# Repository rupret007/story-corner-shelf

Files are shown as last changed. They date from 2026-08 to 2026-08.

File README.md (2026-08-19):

# Story Corner

**Triadic Palatine Order — a parametric PETG-finished hybrid closet shelf**

Story Corner is a same-height L shelf for nominal 3 ft and 5 ft closet walls. The r5 **Triadic Palatine Order** gives the visible black PETG skin a palace-like 3–6–9 composition: three arcade bays on the short arm, six on the long arm, nine keystones, fluted shared piers, stepped entablatures, dentils, a fitted corner pilaster, and a groin-vault corner soffit. Continuous plywood and steel—not the printed architecture—carry stored weight.

> **Prototype status:** the meshes and model-only 3MF packages are generated design-development artifacts. The wall lengths, separate installed offset on each wall, corner angle, wall bow, framing map, hardware envelope, 8 in depth, attachment stack, printer, nozzle, build plate, PETG product, and completed assembly remain unverified. No tested load rating is claimed. No embedded G-code is included.

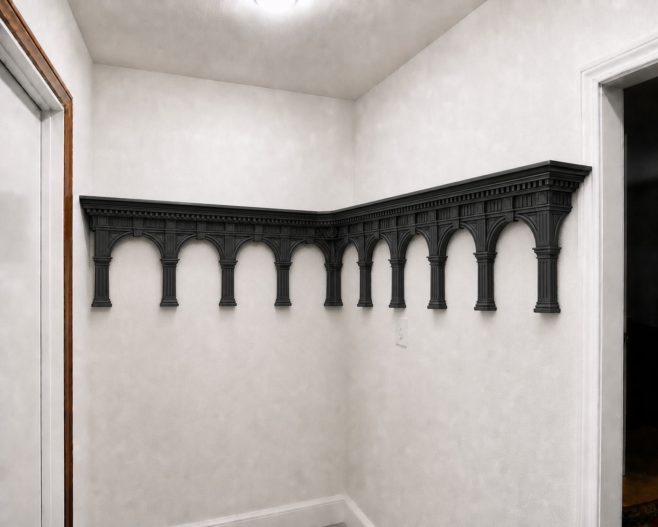
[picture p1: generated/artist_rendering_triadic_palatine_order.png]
Artist rendering of the Story Corner Triadic Palatine Order


The rendering shows visual intent only. It is not a measurement drawing, hardware layout, proof of fit, or load test. Construction is governed by the field measurements, [corner plan](generated/corner_layout.svg), [support plan](generated/support_layout.svg), and [safety boundary](SAFETY.md).

## Design snapshot

Viewed from the closet opening, the nominal plan places the 5 ft through arm on the right wall and the 3 ft return on the back wall; this handedness still requires field confirmation. The through deck owns the 8 x 8 in corner square. The return starts beyond the through deck's front plane, so the boards do not overlap and both arms retain independent bracket support.

| Arm | Nominal plywood stations from inside corner | Nominal deck | Desired support centers from inside corner | Palatine arcade |
|---|---:|---:|---|---:|
| 5 ft through | 0.688–59.875 in | 59.188 x 8 in | 6.281, 22.281, 38.281, 54.281 in | 6 bays / 12 halves |
| 3 ft return | 8.750–35.875 in | 27.125 x 8 in | 10.750, 22.313, 33.875 in | 3 bays / 6 halves |

The shortened return still completes the full short-wall surface because the through deck supplies the corner. Nominal geometry uses 0.6875 in as the provisional installed shelf-back offset on **each** wall, an 8 in deck, a 1.6 mm concealed plywood fit gap, and 1/8 in clearance at each exposed outer end. These are not field cut dimensions.

Dimensioned fitted corner plan

The desired support layout limits longitudinal spacing to 16 in and end overhang to the configured 6 in maximum; the nominal plan works out to 5.594 in on the through arm and 2 in on the return. It is not a drilling map. Every standard must land on verified wood framing or purpose-installed structural blocking. Dry-fit the two nearest perpendicular brackets, locks, fasteners, and both steel angles together before drilling.

## Permanent load path

Every generated printable component is PETG-only and intentionally nonstructural:

`contents -> each continuous plywood deck / its continuous steel front angle -> independent steel brackets -> steel standards -> structural fasteners -> verified framing or blocking`

The printed arches, piers, keystones, entablatures, top tiles, curbs, corner pieces, and fascia can conceal the chassis, but they do not become that chassis. Roman arch geometry does not solve the tension and long-term creep demands of a wall-mounted cantilever. An all-PETG structural shelf or printed wall bracket is outside this project and cannot inherit its selection targets, support plan, or safety language.

Shelf section and permanent load path

## Two-wall corner model

The coordinate datum is the intersection of the two finished wall planes. Measure the installed wall-to-plywood-back offset independently on both walls:

- `b5`: offset on the long/through wall;
- `b3`: offset on the short/return wall;
- `D`: shelf depth;
- `j`: plywood fit gap.

The through deck starts at `b3` along the long-wall axis. The return deck starts at `b5 + D + j` along the short-wall axis. The through-owned corner zone spans `b3` to `b3 + D` on the long-wall axis and `b5` to `b5 + D` on the short-wall axis. Equal catalog standard projections do not prove that the installed offsets are equal after wall bow, drywall mud, shims, and fastener seating.

The current nominal values happen to give the same stations shown in the table because both unverified offsets fall back to 0.6875 in.

## Near-square angle and residual-gap rule

The square deck footprints use a deliberately narrow field-angle gate:

- nominal plywood gap: 1.6 mm;
- required residual nominal clearance: at least 0.6 mm;
- configured maximum verified deviation from 90°: ±0.25°;
- gap-only physical overlap limit across 203.2 mm depth: approximately ±0.451°;
- residual-clearance-derived limit: approximately ±0.282°.

Angular edge shift is `203.2 mm × tan(|angle − 90°|)`. At ±0.25°, the nominal shift is about 0.887 mm and the remaining nominal joint clearance is about 0.713 mm. Generation must stop if the configured gate exceeds the residual-derived limit, a verified angle exceeds ±0.25°, or the remaining clearance is below 0.6 mm. A full-size template is still mandatory because this trigonometric check does not include wall bow, caulk, or drywall buildup.

## Triadic Palatine Order

The ornament follows a controlled 3–6–9 grammar rather than adding unrelated decoration:

- 3 segmental-arch bays on the short arm and 6 on the long arm;
- 18 handed arcade/fascia halves separated by 0.6 mm seams and finished by 9 floating keystones;
- 113.994 mm short-arm halves and 107.630 mm long-arm halves;
- 92 mm arch drop, 48 mm rise, 6 mm overlap into the functional fascia, and 168.056 mm total saved height;
- a 5 mm outer archivolt order, 2.4 mm true shadow reveal, and 4 mm inner order;
- a 22 mm shared pier with three 1 mm flutes per half — six across the assembled pier — plus 9 mm-high / 4 mm-projecting bases and 8 mm-high / 5 mm-projecting capitals;
- one 3:4:5 spandrel void per half;
- removable 24 mm-high entablature overlays, each with 9 dentils, 3 triglyph groups, 3 cornice orders, and an 11 mm central patera;
- an 18 x 24 x 2.4 mm keystone at every bay center, retained to one half while floating over the other;
- an 18 mm-leg full-height re-entrant corner pilaster fixed on one upper leg and floating on the perpendicular leg;
- a 42 mm groin-vault soffit with diagonal ribs and a 9-petal boss, mounted only beneath the through-owned corner square.

The groin-vault footprint currently has 18.519 mm nominal clearance to the nearest through support plane, above the 10 mm development minimum. Field support locations must regenerate and re-pass that check. None of these forms receives structural credit, even when it visually resembles an arch, pier, bracket, or vault.

Dimensioned Triadic Palatine elevation

The elevation drawing records exact nominal stations, counts, and module dimensions; its displayed arch curves are schematic. It is not a structural elevation or a substitute for checking the 180 mm printer envelope.

## Finish fit and attachment

- All top tiles use a 0.25 mm plan radius and 0.6 mm seams. Four 101.3 mm quadrants finish the through-owned corner square. The return's inner tile floats 1.0 mm over the concealed 1.6 mm plywood gap without receiving load-path credit.
- The fascia channel opening is nominally 46.256 mm: 18.256 mm plywood + 25.4 mm steel-angle vertical leg + 2.0 mm top tile + 0.6 mm fitting clearance. The upper flange overlays the tile.
- Every finish piece attaches only with qualified removable products — silicone dots, captured channels, or short nonstructural screws through generated slots. The complete attachment sequence, dot counts, and installed z-stack live in [ASSEMBLY.md](ASSEMBLY.md); the attachment policy is in [ENGINEERING_DESIGN.md](ENGINEERING_DESIGN.md) section 8. Never drill or notch the continuous steel angle for cosmetic retention.

Attachment prevents loose trim, rattle, and falling only. It does not carry stored weight or turn the printed anti-fall features into rated cargo restraints.

## Split rear-curb system

The rear curb sits on the PETG tile/plywood stack — never on bare plywood and never across the structural joint. The long-wall straight curb starts at station 1.892 in after the 30 mm fitted replacement; a separate 172.6 mm corner-side curb stays on the through-owned corner square; the return curb starts on its own plywood at 8.750 in, beyond the 1.6 mm wood gap. Rear-curb ends are arm-specific: 126.481 mm through, 115.581 mm return. The installed z-stack and the slot/drill/screw procedure are in [ENGINEERING_DESIGN.md](ENGINEERING_DESIGN.md) section 6 and [ASSEMBLY.md](ASSEMBLY.md) Stage 4.

## Safe customization

- Universal top and rear-curb centers use a 152.4 mm pitch and are 151.8 mm wide with 0.6 mm seams.
- Measured arm lengths regenerate symmetric top/curb ends and the complete 3/6-bay Palatine fascia layout.
- The nominal top ends are shared at 116.081 mm. Rear-curb ends and all Palatine half widths are arm-specific.
- A same-height L level must be unloaded and moved as one coupled assembly. Moving one arm alone breaks the fitted corner.
- Moving a standard horizontally requires a new framing, wiring, bracket-interference, spacing, overhang, and groin-vault-clearance review.

The structural plywood and steel angle do not use printed snap joints. Modularity is limited to replaceable finish pieces and controlled vertical movement on the steel standards.

## Start here

1. Read [PRINT_ME_FIRST.md](PRINT_ME_FIRST.md) before opening a production file.
2. Read [SAFETY.md](SAFETY.md) before cutting, drilling, attaching trim, or loading.
3. Review [ENGINEERING_DESIGN.md](ENGINEERING_DESIGN.md) for formulas, failure modes, and verification limits.
4. Fill in [MEASUREMENT_WORKSHEET.md](MEASUREMENT_WORKSHEET.md), transcribe its section H into [config.json](config.json), then rebuild every generated artifact and verify the `*_source` fields per worksheet section I.
5. Follow [ASSEMBLY.md](ASSEMBLY.md) for the build sequence, from structural install through load acceptance and service.
6. Open [the full model-only print set](generated/model_only_3mf/MODEL_ONLY_STORY_CORNER_TRIADIC_PALATINE_FULL_PRINT_SET.3mf) only after confirming the printer, nozzle, plate, PETG product, and attachment coupons.

The full 3MF contains **101 exact-quantity catalog objects**: 98 installed finish pieces plus three print-first test objects. It is not arranged into real printer plates and contains no machine instructions. The nominal geometry estimate is **2.45 kg packaged PETG** and **2.42 kg installed PETG**, excluding purge, supports, failures, spares, fasteners, plywood, and steel.

## Field information still required

Before this can become an installation-ready revision, record:

1. The limiting clear length of both walls at the rear, middle, and front shelf planes for every candidate common elevation.
2. The included inside-corner angle, wall bow, drywall/caulk buildup, and a full-size cardboard or hardboard corner template.
3. The installed wall-to-plywood-back offset **separately for each wall**, plus bracket wall-to-tip envelope, bracket width, locks, and final wall-to-fascia projection using the exact hardware.
4. Both edges and center of every stud on both walls—especially the first 14 in from the corner—plus framing material, drywall thickness, wiring, pipes, and protective plates.
5. Confirmation that the 8 in depth and 168.056 mm Palatine fascia envelope clear the doorway, trim, people, bins, outlets, and every intended elevation.
6. Storage-bin outside width, depth, height, lid overhang, quantity, loaded weight, and the heaviest individual object.
7. Exact printer, nozzle diameter and material, build plate, Bambu Studio version, black PETG brand/product, and filament condition.
8. Intended evenly distributed contents, point loads, measured shelf-arm dead load, common shelf-top elevation, and number of levels sharing the standards.
9. The exact removable silicone products, captured-channel fit, rear-curb screw stack, groin-vault screws, and removal method, qualified on printed PETG, sealed plywood, and the actual coated steel where each product is used.

[MEASUREMENT_WORKSHEET.md](MEASUREMENT_WORKSHEET.md) maps each of these measurements to its exact `config.json` key, with units and a worked example. Fill each run's `field_verified_min_clear_wall_width_in`, `field_verified_installed_shelf_back_offset_in`, `field_verified_support_centers_in`, and `field_verified_shelf_arm_dead_load_lb` (a measured dead load raises the serviceability check's governing line load); also fill the corner's `field_verified_angle_deg` and structural `field_verified_bracket_reach_in`. Empty values keep the output explicitly nominal. Support centers are absolute distances from the intersection of the finished wall planes, not from a board end.

## Generated deliverables

- `generated/model_only_3mf/`: individual, parts-catalog, and full-print-set model-only 3MF packages;
- `generated/*.stl`: matching individual meshes;
- `generated/artifact_manifest.json`: SHA-256 hashes and sizes for every printable artifact;
- `generated/validation.json`: geometry, counts, mesh checks, fit envelope, Palatine data, and packaged/installed mass estimates;
- `generated/model_3mf_report.json`: deterministic 3MF archive and mesh validation;
- `generated/cut_plan.csv`: nominal structural cut list and printable counts;
- `generated/support_plan.csv`: nominal or field-supplied support coordinates;
- `generated/corner_layout.svg` and `generated/support_layout.svg`: dimensioned design-development drawings;
- `generated/palatine_elevation.svg`: exact nominal stations/counts with a schematic curved profile for the r5 decorative order;
- `generated/structural_sanity_check.json`: deliberately limited plywood serviceability calculation;
- `generated/artist_rendering_triadic_palatine_order.png`: final r5 visual design intent.

## Rebuild and verify

Python 3.12 and the pinned packages in `requirements.txt` reproduce the model artifacts:

```sh
python3.12 -m venv .venv
.venv/bin/python -m pip install -r requirements.txt
PYTHON_BIN=.venv/bin/python SKIP_BAMBU=1 scripts/build_all.sh
```

On macOS with Bambu Studio in the normal Applications location, run the stricter integration check:

```sh
PYTHON_BIN=.venv/bin/python REQUIRE_BAMBU=1 scripts/build_all.sh
```

The build regenerates generator-owned STL/3MF outputs, exercises parametric relationships, and checks mesh closure, body count, the 180 mm saved-orientation envelope, exact 101-object packaging, 3MF integrity, hashes, documentation links, and absence of embedded G-code. Strict local mode also imports each 3MF into Bambu Studio and exports it back to STL.

## Hardware and rating boundary

The reference support family is the black Knape & Vogt 82 Series standard with 182 Series 7 in bracket, bracket lock, and manufacturer-prescribed shelf attachment. The [official KV 82/182 specification](https://www.knapeandvogt.com/sites/default/files/OL2243-82Standards-182Brackets-Specs-WEB.pdf) documents nominal dimensions and warns that actual conditions reduce laboratory results and require representative testing.

The current 55 lb return-arm and 120 lb through-arm evenly distributed values are **system-selection targets, not ratings**. The corner-square load belongs to the through deck. No bracket result may be multiplied by bracket count or added across shelf levels to claim an installed capacity.

## Repository status

The canonical repository is [rupret007/story-corner-shelf](https://github.com/rupret007/story-corner-shelf). The active revision is `triadic_palatine_fitted_l_corner_r5`. See [CHANGELOG.md](CHANGELOG.md) and [CONTRIBUTING.md](CONTRIBUTING.md).

The earlier R6–R11 development trees under `development/` are retained as frozen historical records with their own print-authorization rules; the r5 Triadic Palatine Order supersedes them as the current design focus. In particular, the R11 tree keeps an explicit print hold, a single-use permit protocol, and a **0 kg / 0 lb** rating — nothing checked in there authorizes printing, drilling, installation, or load. See [development/r11/README.md](development/r11/README.md), the [R11 print hold](development/r11/PRINT_FIRST.md), and the [append-only physical record](development/r11_physical/PHYSICAL_RECORD.md).

No open-source license has been selected. Add the intended license before inviting public reuse or contributions.

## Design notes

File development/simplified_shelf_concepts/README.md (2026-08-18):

# Simplified all-PETG shelf concepts

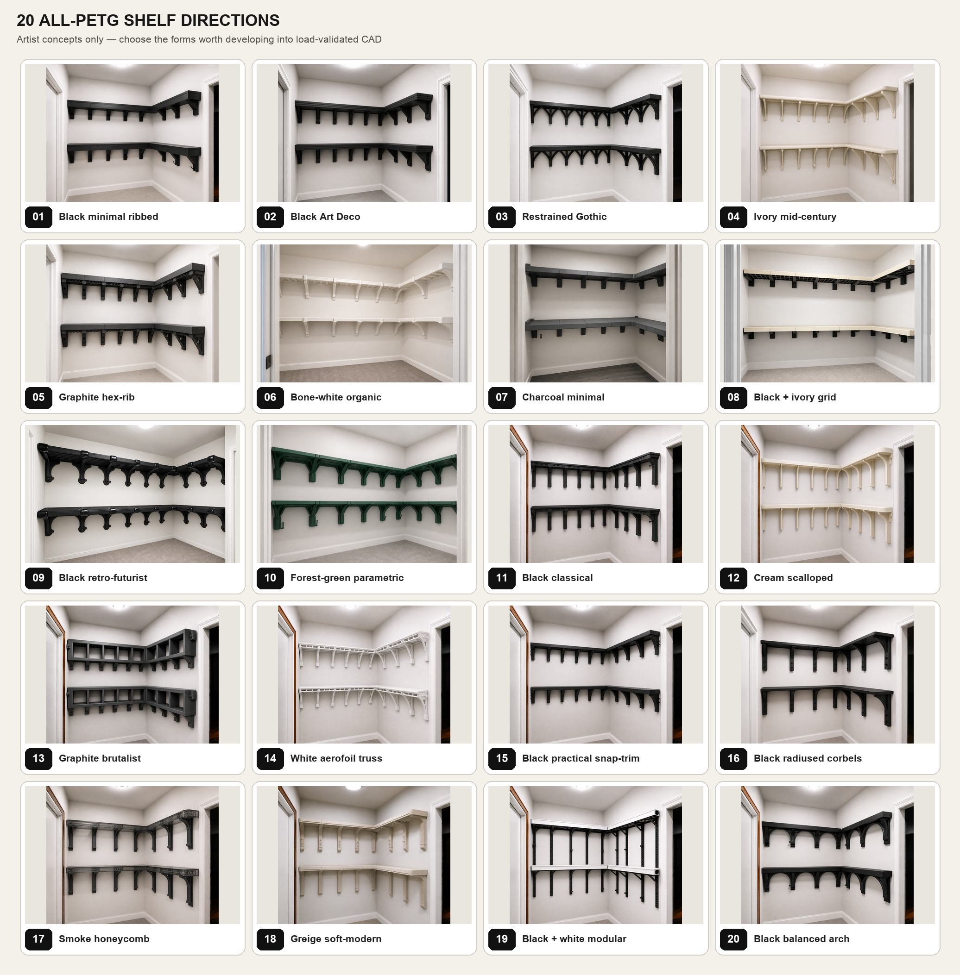
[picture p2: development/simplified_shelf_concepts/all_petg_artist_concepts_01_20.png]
Comparison of all 20 PETG concepts


These are artist renderings for choosing a design direction. Every shelf deck, cassette, rib, corbel, fascia, support, trim piece, and cable peg is depicted as 3D-printed PETG. No concept uses a wood or metal shelf structure. PLA could be evaluated later as an alternate printed material, but it is not mixed into these renderings.

They are not CAD, a bill of materials, or load evidence. Exact bay counts, part segmentation, wall attachment, creep, and safe working load must be resolved after a direction is selected. The wall itself will still require an independently qualified attachment method; the images intentionally do not invent visible metal hardware or unsupported floating shelves.

## Concepts

1. [Black minimal ribbed](artist_renderings/01_black_minimal_ribbed_petg.png) — thick modular cassettes, plain haunched supports, discreet pegs.
2. [Black Art Deco](artist_renderings/02_black_art_deco_petg.png) — stepped fascia and restrained geometric support details.
3. [Restrained Gothic](artist_renderings/03_black_restrained_gothic_petg.png) — clean pointed-arch trusses without the earlier ornament overload.
4. [Ivory mid-century](artist_renderings/04_ivory_midcentury_petg.png) — soft radii, warm light PETG, simple integrated pegs.
5. [Graphite hex-rib](artist_renderings/05_graphite_hex_rib_petg.png) — exposed honeycomb fascia and perforated structural corbels.
6. [Bone-white organic](artist_renderings/06_bone_white_organic_petg.png) — quiet rounded ribs in a near-wall color.
7. [Charcoal minimal](artist_renderings/07_charcoal_japanese_minimal_petg.png) — broad solid cassettes and the least visual clutter.
8. [Black + ivory grid](artist_renderings/08_black_ivory_modular_grid_petg.png) — light shelves over a black printed grid frame.
9. [Black retro-futurist](artist_renderings/09_black_retro_futurist_petg.png) — glossy rounded modules and compact curved supports.
10. [Forest-green parametric](artist_renderings/10_forest_green_parametric_petg.png) — branching printed ribs with a strong color statement.
11. [Black classical](artist_renderings/11_black_classical_arcade_petg.png) — restrained classical rhythm and squared piers.
12. [Cream scalloped](artist_renderings/12_cream_contemporary_scalloped_petg.png) — pale PETG and soft repeated curves.
13. [Graphite brutalist](artist_renderings/13_graphite_brutalist_petg.png) — deep box-rib modules with a heavier architectural presence.
14. [White aerofoil truss](artist_renderings/14_white_aerofoil_truss_petg.png) — visibly lightweight curved ribs and open fascia cells.
15. [Black practical snap-trim](artist_renderings/15_black_practical_snap_trim_petg.png) — plain structural cassettes with limited decorative covers.
16. [Black radiused corbels](artist_renderings/16_black_radiused_corbels_petg.png) — broad, calm corbels and clearly visible cable pegs.
17. [Smoke honeycomb](artist_renderings/17_smoke_honeycomb_petg.png) — translucent PETG fascia revealing the internal cellular structure.
18. [Greige soft-modern](artist_renderings/18_greige_soft_modern_petg.png) — rounded domestic styling and fluted pier supports.
19. [Black + white modular](artist_renderings/19_black_white_modular_petg.png) — white cassette shells on black printed X-bracing.
20. [Black balanced arch](artist_renderings/20_black_balanced_arch_petg.png) — a simpler version of the architectural-arch idea.

Exact generation prompts are preserved in:

- [prompts 01–05](artist_renderings/prompts_01_05.md)
- [prompts 06–10](artist_renderings/prompts_06_10.md)
- [prompts 11–15](artist_renderings/prompts_11_15.md)
- [prompts 16–20](artist_renderings/prompts_16_20.md)

The comparison sheet is reproducible with [build_contact_sheet.py](build_contact_sheet.py).

## Selected refinement

The selected source is concept 16. Its active refinement is [16B: compact structural corbels with modular cable rails](SELECTED_DIRECTION_16B.md). It retains the simple individual-bracket appearance while adding replaceable single-cable, cable-comb, coil-hook, and blank-cap modules to safe interior downward supports. The earlier 20B study is superseded.

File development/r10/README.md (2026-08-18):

# R10 Palatine Lincoln-log arcade shelf

> **Engineering prototype only. Rated load: 0 kg / 0 lb.** Do not use these
> files as permission to drill the wall, install a shelf, or store any load.
> R10 defines a predominantly printed candidate architecture and the physical
> evidence it must earn. Until every release gate closes, it is not an
> installable product.

## Scope frozen for this revision

R10 addresses only the first, lower shelf on the measured 61.25 in
(1555.75 mm) through/outlet wall. Its intended top elevation is 68 in and its
projection is 6 in (152.4 mm). The return wall, the 84 in upper level, and the
inside corner remain later work.

The outlet faceplate reaches approximately 53.5 in above the floor. The
finished layout must preserve access to both receptacles, plugs, cords, and the
faceplate screws. Wall bow, trim, blocking, substrate, and the exact field
termination still require physical records before any wall release.

## Correct the old 16 kg statement

The frozen R6 values `16.000337 kg per level / 32.000674 kg for two levels`
are repeat-weighted **CAD solid mass**, not carrying capacity. They never
established a shelf rating. R9 and R10 remain rated at exactly **0 kg / 0 lb**.

R10 consequently seeks a shorter, redundant printed load path rather than
adding undifferentiated plastic mass.

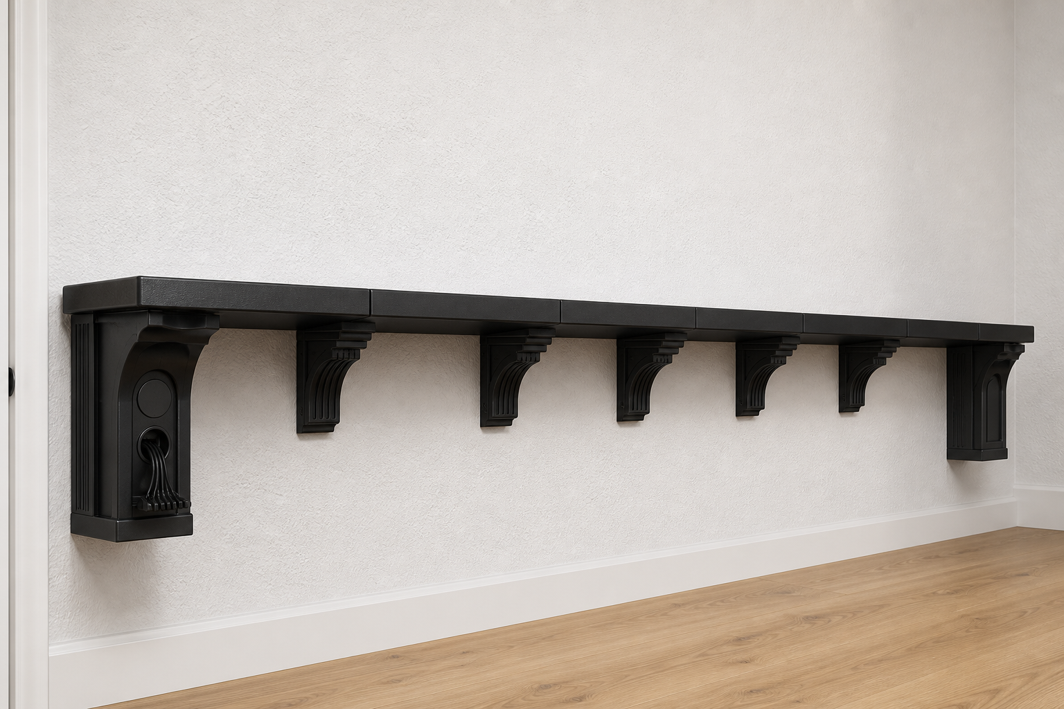
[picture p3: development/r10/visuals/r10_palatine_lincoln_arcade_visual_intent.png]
R10 Palatine Lincoln-log visual intent


This render is visual intent only: it communicates the compact Roman/Art-Deco
rhythm, shorter intermediate corbels, segmented fascia, and emphasized outer
bookend. It is not CAD, a part-count record, an assembly drawing, a drilling
template, or proof of strength. Source geometry and validated saved meshes
control whenever the image differs.

R10 one-bay assembly and first-wall topology

The vector diagram is the frozen **qualification topology**, not a drilling
template or load proof. It shows the actual one-bay article families, the
retainer order, and how six independent bays tile across the first wall. The
exact assembly motions and stop conditions are controlled by
[`ASSEMBLY.md`](ASSEMBLY.md); the safest print order is controlled by
[`PRINT_FIRST.md`](PRINT_FIRST.md).

## Selected all-PETG shelf architecture

The active shelf chassis contains no aluminum tube, metal beam, or metal
bearing strap. Its structural shelf parts are SUNLU PETG; metal is limited to
the candidate wall screws and one washer beneath each screw head.

Across the 61.25 in run, seven 31.75 mm-wide Palatine supports sit on exact
10 in (254 mm) centers. They create six independent bays:

```text
wall end                                                     wall end
   S0 ---- bay 1 ---- S1 ---- bay 2 ---- ... ---- bay 6 ---- S6
       half | half          half | half
            ^                    ^
       3 splice logs        3 splice logs
       + 3 log keys         + 3 log keys
      bay-local support keys retain each cassette end without carrying gravity
```

Each bay contains:

- two full-depth PETG cassette halves;
- rear, center, and front PETG splice logs crossing the midpoint seam;
- captured dovetail channels and positive body shoulders, with 0.4 mm
  clearance per face;
- three independent removable retainers, one preventing walkout of each log;
  and
- direct cassette-end bearing on the broad half-lands of the adjacent support
  capitals.

Each one-log retainer has an integrated cap: its 6.0 mm run closes the
left-half top access flush when the key seats. There are no separate loose
debris covers. The final saved key envelope is 12.4 x 28.0 x 10.8 mm.

Each bay also receives two front-inserted support retainers after its cassette
ends are seated. The 12 bay-local keys have separate left/right functions at
interior supports, so one loose key cannot affect an adjacent bay. They resist
accidental lift only; the uninterrupted land above each key carries gravity.
Each has a 3.8 mm run-width shaft, 8 mm-deep rear dog, and 12 mm-deep front
handle. After straight insertion, a 2.4 mm shift toward its bay puts the dog
behind a positive shoulder while the paddle remains 4.0 mm proud of the shelf
front for a reversible hand grip; no friction or snap is credited.

The two outer cassette halves are longer terminal parts; the ten interior
halves are regular parts. A failed or damaged bay can be removed without
unzipping the complete 61 in run. Adhesive, snap preload, friction, the
retainers, shallow locators, and anti-lift retention receive no sustained
vertical-load credit.

The dovetail and top-open key notch reduce the splice log's real midpoint
section. Final-mesh geometry—not a gross 20 x 24 mm rectangle—controls the
proxy: net area is 334.800 mm² (72.16% of gross), centroidal second moment is
8263.957 mm⁴ (36.85% of gross), and governing elastic section modulus is
949.016 mm³ (51.35% of gross). Those are geometric comparisons only; they
contain no PETG allowable and create no load rating.

Printed halves preserve 0.35 mm at every midpoint seam, 0.35 mm centered over
each interior support line, and 0.35 mm at each wall endpoint. The stepped
fascia looks continuous but remains physically segmented for thermal movement
and one-bay removal.

The intended primary load path is:

```text
stored object
  -> PETG top skin and rear/center/front cassette webs
  -> three captured PETG splice logs at each bay seam
  -> direct bearing on seven PETG support capitals
  -> seven PETG wall straps / straight compression webs
  -> 21 GRK 90306 screw-and-washer candidates
  -> verified continuous blocking or an independently engineered equivalent
```

Generic drywall or hollow-wall anchors are not part of that path. A wall screw
catalog value is not a shelf rating.

## Palatine Moderne is structural honesty, not camouflage

The visible language is a black Roman aqueduct interpreted through Art-Deco
stepping: short repeated arches, stepped keystones, a continuous fascia, and
stronger outer bookends. The efficient mechanics remain straight wall straps,
compression webs, top chords, broad bearing lands, skins, and splice logs.

Ordinary intermediate corbels expose only a compact 76.2 mm visual drop while
the full 158.75 mm structural wall strap remains hidden. The far-left outer
bookend may extend its visible emphasis to 120.65 mm. The through-side terminal
is a replaceable corner placeholder, not a final measured corner or an outer
bookend.

Every arch recess and decorative step is additive-only or placed outside the
minimum structural envelope. Ornament may not thin a wall strap, screw or
washer land, compression web, support capital, cassette skin/web, dovetail,
log shoulder, or keyway. The Roman curve and keystone receive zero independent
structural credit.

## Cable pegs are a frozen interface

Cable organization may appear **only on the two outer bookends of the eventual
L-shaped shelf level**:

- the far-left endpoint of this first wall; and
- the far-right endpoint of the later return wall.

Each outer bookend has exactly one fused receiver containing exactly two
inward-facing sockets. Each socket uses the proven keyed gravity interface,
0.4 mm clearance per face, and 8 mm service lift/drop. The printable module set
must include a flush blank and a multi-cable comb/hook. Blank every unused
socket so the shelf can read as ordinary furniture.

There is no cable rail, peg, receiver, or module on an intermediate support,
the through-side terminal/corner placeholder, or the inside corner. Cable parts
receive zero structural credit. The first-wall prototype activates only its far-left
bookend; the second outer bookend is deferred until the return-wall geometry
exists.

## Qualification objective—not a rating

The ambitious physical objective is 45 kg (approximately 100 lb) of uniformly
distributed contents per level plus a separate 9 kg (approximately 20 lb)
front-edge point-load case. The total proof demand is `1.5 x (dead mass + 45 kg
contents)`. Because the physical shelf already supplies its own dead mass, the
external ballast is:

```text
1.5 x (measured finished-shelf dead mass + 45 kg contents)
- measured finished-shelf dead mass
```

These numbers define test inputs only. They do not become an allowable load by
appearing in CAD, software, or documentation. The complete staged protocol is
in [`LOAD_QUALIFICATION.md`](LOAD_QUALIFICATION.md).

The separate point-proof case also factors the existing shelf dead mass. Under
the current 1.5x study rule, the shelf supplies `D`; the fixture adds a
representatively distributed `0.5D` plus the 13.5 kg factored point mass. A
reviewer may replace those load factors only through a recorded test revision.

Before the sustained test, measure the maximum temperature the shelf will see
in representative service. The creep article then dwells for 1000 hours at
that measured maximum plus 5 degrees C; the extra temperature is a controlled
qualification margin, not permission to use the shelf in a hotter environment.

## Fastest responsible path to a printable shelf

The print strategy deliberately fails fast and spends filament in this order:

1. **Actual midpoint interface:** print one authored left cassette half, one
   authored right half, one splice log, and its flush-capped retainer. Cycle the
   real interface ten times; reject cracking, shaving, uncontrolled looseness,
   a proud cap, or forced assembly.
2. **Complete one actual structural bay:** reuse those four passing articles,
   then print the remaining two logs, two log retainers, two bay-local support
   keys, and two supports, one part per plate in the authored orientation. Off
   the supports, seat all three logs in the left half; while the right half is
   absent, lower one key through each left-half top access into its exposed log
   notch. Then slide the right half over the logs and captured key ends. Lower
   that joined cassette onto the two broad support contacts; insert each long
   support key from the front and shift it 2.4 mm toward its bay to engage the
   positive rear stop. Inspect direct bearing, flush key closures, seam
   closure, independent removal, and layer quality.
3. **One cable bookend set:** print the far-left fused two-socket receiver, its
   two flush blanks, and one comb/hook. Verify inward orientation, 8 mm service
   motion, cord clearance, and ordinary-shelf appearance.
4. **Complete tabletop set:** only after the midpoint-interface and one-bay
   gates pass, print the
   remaining parts. Assemble all six bays without screws or a wall and verify
   the measured length, support centers, flatness, replaceability, outlet
   clearance model, and that no single key can release adjacent bays.
5. **Framed-wall mockup:** only after blocking and substrate are known, build a
   sacrificial fixture and follow the qualification gates. The real closet wall
   is not the first fixture.

Before every printer start, the operator must confirm the plate is empty and
clean, the physical 0.4 mm nozzle and exact PETG are loaded, the correct profile
is selected, and the intended single-part plate is in Preview. Do not send a
print merely because slicing succeeded.

## Baseline print contract

- Bambu Lab A1 mini, physical 0.4 mm nozzle, Textured PEI plate.
- SUNLU standard black PETG, 1.75 mm, ASIN `B0D1KC72YP`; record the received
  label, spool lot, and drying cycle.
- `SUNLU PETG @BBL A1M 0.4 nozzle` filament profile and
  `0.20mm Strength @BBL A1M` process profile.
- Six walls, 25% grid infill, five top layers, three bottom layers, Support
  Off, 5 mm outer brim, and 0.1 mm brim-object gap.
- Authored orientation, 100% scale, one structural part per plate, manifold
  geometry, and Bambu Preview inspection. Never auto-orient, auto-scale,
  casually mirror, or accept slicer repair for a structural part.

Every part must fit the A1 mini's 180 x 180 x 180 mm volume after including
the brim, the 0.1 mm gap, and 2 mm additional reserve at every bed edge.

## Current release blockers

R10 does not yet provide a released production STL/3MF set, G-code, drilling
template, verified wall map, passed one-bay fixture, passed full-wall mockup,
proof result, sustained-creep result, recovery result, destructive result, or
independent structural review. Therefore it supplies no installation
authorization and no load rating.

Use [`GUIDELINES.md`](GUIDELINES.md) as the compact pre-change checklist and
[`DESIGN_REQUIREMENTS.md`](DESIGN_REQUIREMENTS.md) as the detailed controlling
contract. Use [`MATERIALS_AND_HARDWARE.md`](MATERIALS_AND_HARDWARE.md) for the
complete candidate bill of materials and [`LOAD_QUALIFICATION.md`](LOAD_QUALIFICATION.md)
for the physical evidence required before any rating or wall release.

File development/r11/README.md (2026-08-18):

# R11 integrated Lincoln-log shelf study

> **Engineering study only. Rated load: 0 kg / 0 lb.** R11 hard-forces print,
> drilling-coordinate release, wall installation, test loading, and stored
> load to false. No R11 v1 geometry is a printable release. A later reviewed
> version would still require the generator, saved-mesh, bundle, slicing,
> physical-fit, wall-fixture, creep, destructive, and independent-review gates
> in this directory.

R11 is the reduced-part successor study to the
[immutable R10 qualification baseline](../r10/README.md). R10 remains intact as
historical design evidence and provenance; R11 does not rewrite R10, convert an
R10 pass into an R11 pass, or make an R10 article part of an R11 shelf.

The [qualification-only exploded bay and first-wall topology diagram](visuals/r11_first_outer_bay_exploded_and_wall_topology.svg)
is a visual index to the candidate parts, motions, zero-credit boundaries, and
exact first-wall count arithmetic. It is not a fabrication or drilling drawing.

The objective is a shelf that behaves more like Lincoln logs: large printed
members overlap on broad, inspectable bearing faces and are held against
half-to-half X separation by a small positive keystone. This replaces R10's
separate splice logs, log retainers, and support retainers with geometry
integrated into the two shelf half-decks and the supports.

## Current status

R11 is a **design and generator-integration contract**, not a production model
set. The dimensions and counts below are candidate targets. They become
controlling only when generated files, manifests, saved-mesh measurements,
tests, Bambu Preview records, and physical articles all agree.

- First scope: lower shelf on the measured 61.25 in / 1555.75 mm first wall.
- Shelf top: 68 in above the floor.
- Shelf projection: 6 in / 152.4 mm.
- Outlet faceplate top: approximately 53.5 in; access must remain unobstructed.
- Architecture target: six independent bays on seven supports.
- Supplied-kit target: **28 printed articles**. Because the three supplied
  cable modules share two sockets, no more than **27 articles are installed at
  once**.
- Safe unbatched plan: **28 starts**, one article per plate.
- Batched production target after qualification: **21 starts**, unverified
  until both optional batch plates pass nesting and Preview.
- Wall-hardware candidate count: seven supports x three bores = **21 screws and
  21 FW14 washers**, unchanged from R10.
- Current rating: **0 kg / 0 lb**.

The return wall, 84 in upper shelf, final inside corner, drilling map, load
rating, and public production release remain outside this first R11 milestone.

## Candidate architecture

Each 254 mm planning bay is intended to contain:

1. one authored left half-deck with three integrated load ribs;
2. one authored right half-deck with matching reciprocal cross-laps;
3. a 55 mm initial overlap candidate at the rear, center, and front ribs;
4. direct, broad bearing on the adjacent support capitals;
5. an integral reversible positive support capture using a generated
   lower/slide/gravity-settle motion; and
6. one removable, positive Palatine/Art-Deco wedge or keystone that prevents
   half-to-half X separation but receives no support-capture or sustained
   vertical-load credit.

The expected dry assembly path is:

```text
interlock two three-rib half-decks off the supports
  -> lower with 2 mm clearance over the fixed lug heads
  -> slide 32 mm wallward
  -> gravity-settle 2 mm into terminal pockets behind solid 8.4 mm roof/shoulder
  -> seat one removable bay keystone against half-to-half X separation
```

The generated reverse sequence is lift 2 mm, slide 32 mm outward, then lift
clear. The exact generated assembly map and saved geometry control if any
documentation shorthand differs.

Gravity must travel through the half-deck skins and ribs, broad reciprocal
cross-lap faces, broad support lands, support compression webs and full-height
wall straps, then through the reviewed screw/washer/blocking connection. The
wedge, friction, snap preload, adhesive, ornament, and cable modules receive
zero sustained vertical-load credit. The keystone receives zero
support-capture credit; it does not prevent support-lug reversal.

Every bay remains an independently removable cell. A single loose wedge or a
damaged bay may not unzip the complete wall run. The final generator must prove
the integral support capture and reversible disassembly; if it cannot, the
architecture and the 28-kit/27-installed/21-batched targets must be revised
rather than hidden with extra hardware or forced fits.

## First-wall kit, installed-state, and start arithmetic

The candidate supplied kit is:

| Printed family | Kit articles | Safe unbatched starts | Target batched starts |
|---|---:|---:|---:|
| Supports, including the fused far-left cable receiver | 7 | 7 | 7 |
| Authored half-decks, one per plate in flat high-load orientation | 12 | 12 | 12 |
| Bay wedges / keystones, one per bay | 6 | 6 | 1 optional batched plate |
| Two flush blanks plus one multi-cable comb/hook | 3 | 3 | 1 optional batched plate |
| **Total target** | **28** | **28** | **21** |

Only two cable modules can occupy S0's two sockets at once: either two blanks,
or one blank plus the comb/hook. The third supplied module remains off the
shelf, so the maximum simultaneously installed count is 27. Batch nesting
changes starts only; it never changes kit quantity, installed-state limits,
article identities, BOM, or qualification scope.

The 21-start count is a production-planning target, not a slicing fact. Until
all six wedges fit together on one inspected A1 mini plate and all three cable
modules fit together on another without changing their authored orientations
or process, the safe plan is 28 one-article starts. Qualification prints,
failed prints, spares, and destructive-test duplicates are additional starts.

For the measured first wall:

```text
wall length L       = 1555.75 mm
support width w     = 31.75 mm
maximum pitch p_max = 254.00 mm

bay count n = ceil((L - w) / p_max)
            = ceil(1524 / 254)
            = 6

supports = n + 1 = 7
actual pitch p = (L - w) / n = 254.00 mm
screws = 3 x supports = 21
```

Support centers are therefore 15.875, 269.875, 523.875, 777.875, 1031.875,
1285.875, and 1539.875 mm from the left endpoint. The arithmetic is exact for
the recorded 1555.75 mm wall; it does not establish that any center has
blocking or is free of wiring, plumbing, trim, or outlet conflicts.

The initial CAD sizing worksheet uses a 55.0 mm overlap, 0.35 mm
endpoint/support-line/midpoint clearance, and 15.70 mm minimum physical bearing
target. It closes the first wall exactly:

```text
regular physical span  = 254.0 - 0.35 = 253.65 mm
terminal physical span = 253.65 + 31.75/2 - 0.35/2 = 269.35 mm

wall closure = 2*269.35 + 4*253.65 + 5*0.35 + 2*0.35
             = 1555.75 mm

regular half length = (253.65 + 55.0) / 2 = 154.325 mm
terminal candidate  = (269.35 + 55.0) / 2 = 162.175 mm
```

Bay 0 uses terminal left and terminal right halves, and bay 5 uses terminal
left and terminal right halves: **four terminal halves at 162.175 mm**. Bays
1-4 use **eight regular halves at 154.325 mm**. R11 v1 refuses a one-bay wall;
its two-terminal-end ownership has not been authored or qualified.

With a 5 mm brim, 0.1 mm brim gap, and 2 mm reserve at every bed edge, the
largest candidate half-deck footprint budget is approximately
176.375 x 166.600 mm. That is a planning calculation only. The generator must
measure the true transformed saved mesh and the slicer must confirm the actual
brim footprint inside the A1 mini's 180 x 180 mm bed without scaling.

See [CUSTOMIZATION.md](CUSTOMIZATION.md) for the general wall solver and its
fail-closed rules.

## Appearance and cable interface

R11 retains the black PETG Palatine Moderne language: a Roman aqueduct reduced
to compact structural arches, stepped Art-Deco fascia, and a legible keystone.
Ornament is additive-only and receives no structural credit. It may never thin
a half-deck skin or rib, cross-lap, support capital, compression web, wall
strap, bore land, or washer land.

Cable organization remains an invariant, not an optional memory:

- only the two eventual outer bookends per L-shaped level receive cable
  hardware;
- the first-wall study activates only its far-left S0 bookend;
- S0 has one fused, inward-facing receiver with exactly two keyed sockets;
- the set contains two flush blanks and one multi-cable comb/hook;
- the interface retains 0.4 mm clearance per face and 8 mm service lift/drop;
- intermediate supports and the future inside corner receive no receiver; and
- every cable article receives zero shelf-load credit.

## Exact material and process baseline

- Bambu Lab A1 mini, physical 0.4 mm standard-flow nozzle, Textured PEI plate.
- SUNLU standard black PETG, 1.75 mm, ASIN `B0D1KC72YP`; record label, lot,
  spool changes, and drying cycle.
- Filament profile: `SUNLU PETG @BBL A1M 0.4 nozzle`.
- Process profile: `0.20mm Strength @BBL A1M`.
- 0.20 mm layer height, six walls, 25% grid infill, five top layers, three
  bottom layers, Support Off, 5 mm outer brim, 0.1 mm brim-object gap.
- Authored orientation, 100% XYZ scale, millimetres, no casual mirroring,
  auto-orienting, repairing, reaming, sanding, or heating of structural fits.

No aluminum or steel chassis, hidden beam, printed wall anchor, generic
drywall anchor, glue, snap-fit capacity, or friction-only load path belongs in
the base architecture. Metal is limited to the exact candidate wall screws and
one exact washer per screw.

## Documents and decision order

1. [DESIGN_REQUIREMENTS.md](DESIGN_REQUIREMENTS.md) — controlling product and
   safety requirements.
2. [PLAN.md](PLAN.md) — work packages, exact first-wall closure, and rejected
   shortcuts for the current reduced-piece development plan.
3. [GUIDELINES.md](GUIDELINES.md) — short memory checklist before every change.
4. [CUSTOMIZATION.md](CUSTOMIZATION.md) — inputs, equations, outputs, and
   refusal conditions for other wall lengths.
5. [MATERIALS_AND_HARDWARE.md](MATERIALS_AND_HARDWARE.md) — exact candidate BOM
   and controlled-lot hardware plan.
6. [PRINT_FIRST.md](PRINT_FIRST.md) — generator/bundle gates, fail-fast order,
   slicer contract, and fresh print permission.
7. [ASSEMBLY.md](ASSEMBLY.md) — provisional dry tabletop sequence and stop
   conditions.
8. [LOAD_QUALIFICATION.md](LOAD_QUALIFICATION.md) — physical evidence required
   before any installation or nonzero rating.

The current R11 v1 release record remains hard-forced to
`print_authorized: false`, `drilling_coordinates_released: false`,
`wall_installation_authorized: false`, `test_load_authorized: false`, and
`rated_load_kg: 0.0`, regardless of input completeness. The immediate next
step is generator integration and neutral-bundle validation—not sending a
print. A clean slice, attractive render, good hand fit, or successful R10
article cannot bypass this version boundary.

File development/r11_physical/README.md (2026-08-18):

# R11 one-bay physical handoff

> **Tabletop fit study only. Current rating: 0 kg / 0 lb.** Nothing in this
> folder authorizes another print, wall work, hardware installation, or load.

This is the short, plain-language guide for the two large pieces that make the
first bay of the shelf. The left piece has been printed and photographed. The
right piece was last reported as still printing; its result has not been
recorded yet. The exact evidence boundary is in
[PHYSICAL_RECORD.md](PHYSICAL_RECORD.md).

The frozen neutral bundle contains two known copied-document links that are
source-relative and therefore do not resolve from inside the bundle. Read the
[frozen-artifact errata](FROZEN_ARTIFACT_ERRATA.md) before following a link
from a copied handoff document. The artifact bytes remain unchanged.

The controlled v2 overlay also has an intentional public device-binding
privacy tradeoff. Read [PRIVACY_NOTE.md](PRIVACY_NOTE.md); it publishes no raw
serial or credential, and this documentation does not alter that frozen gate.

## What exists right now

- **Left half:** printed, cooled, removed, and visually observed flat with no
  rocking and no visible finger flex. It was not sanded. This is an observation,
  not a complete fit or strength pass.
- **Right half:** print in progress at the last update. Do not treat it as a
  finished part until it has completed, cooled, been removed, and passed the
  same simple visual checks.
- **One-bay dry fit:** not started.
- **Supports and keystone:** not part of this next step.

Use these picture guides with the cards below:

- [six-card one-bay dry-fit guide](visuals/one_bay_dry_fit_steps.svg)
- [close views of the three laps and later support capture](visuals/joint_closeups.svg)

Cleaned reference view of the printed left half:

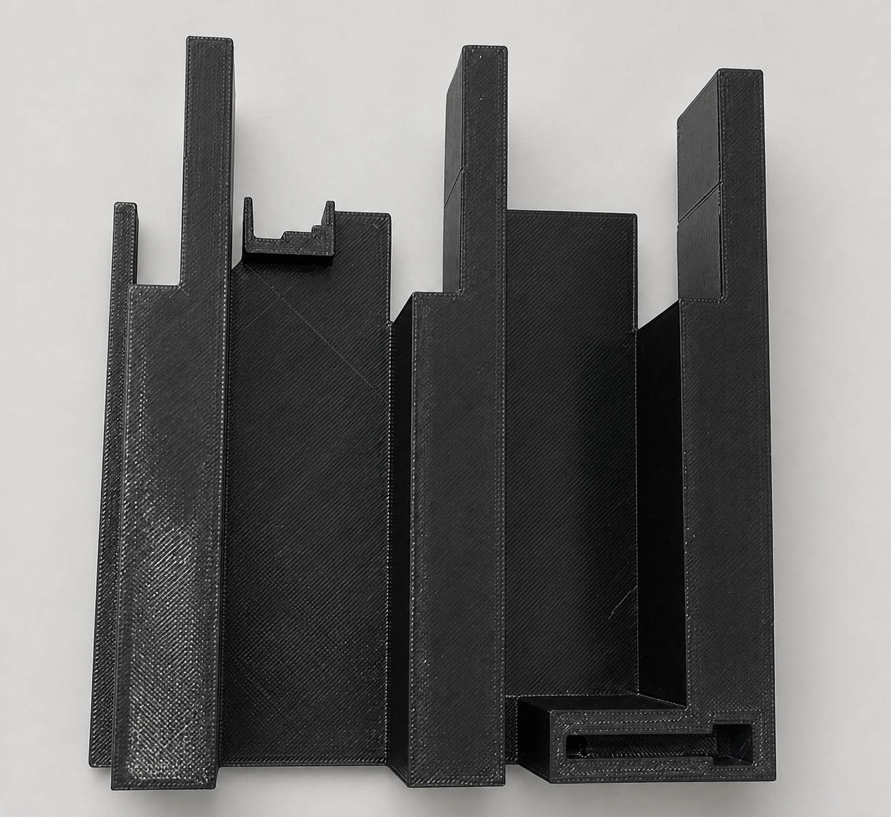
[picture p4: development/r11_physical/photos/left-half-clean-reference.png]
Cleaned presentation reference of the printed R11 left terminal half-deck


This edited image is only an orientation aid. The source-photo identities,
exact edit prompt, retained C2PA provenance, output hash, and evidence limits
are recorded in [the photo provenance](photos/README.md). Do not use the
cleaned image for dimensions, contact, flatness, or capacity.

For a future Codex task, use the
[copy-paste continuation and full-validation prompt](NEXT_ENGINEER_PROMPT.md).
It preserves this physical boundary and requires the full regression and
publication checks before another engineering release.

## Before the first dry fit

Proceed only when the right half has finished, fully cooled, and been removed
from the plate. Set both halves on a clean, flat table.

Use clean hands only. **No sanding, file, lubricant, heat, glue, tools, force,
wall, screws, or weights.** Do not trim or reshape either structural part. Do
not install the keystone and do not place either half on supports yet.

## The next dry fit — one card at a time

### Card 1 — Check the right half

Look at every finger, slot, broad flat face, and outside edge.

**PASS:** it is fully cooled, lies flat without rocking, and has no crack,
white stress mark, lifted layer, loose strand, or visibly bent finger.

**STOP:** any item above is not true. Photograph it and leave the parts apart.

### Card 2 — Confirm the pair

The labels for this pair are:

- left: `r11_bay0_left_terminal_integrated_half_deck`
- right: `r11_bay0_right_terminal_integrated_half_deck`

Put the two top faces upward. Point both wall-side edges the same way. Keep the
front edges on the same side. Follow the labels and arrows in the
[six-card guide](visuals/one_bay_dry_fit_steps.svg); do not mirror or guess a
different motion.

**PASS:** the two parts match the labeled left/right picture.

**STOP:** the orientation is uncertain or either identity is uncertain.

### Card 3 — Line up all three laps

Keep both pieces off the supports. Bring the two halves together just far
enough to line up the rear, center, and front reciprocal laps. All three rows
must start together. Keep the broad faces parallel.

**PASS:** all three rows line up at the same time while the parts remain
relaxed in your hands.

**STOP:** one row collides, one row starts much earlier, or the pieces must be
twisted to line up.

### Card 4 — Make the first gentle fit

Move the halves together by hand in the single straight direction shown in the
guide. Stop as soon as the broad faces and body shoulders seat. Keep the
designed center seam; do not try to squeeze the seam to zero.

**PASS:** all three laps seat with gentle hand motion and the joined top stays
flat, without rocking or twisting.

**STOP:** the motion binds, scrapes, shaves material, makes PETG dust, needs a
push, leaves a lap partly seated, makes a crack or white mark, or bends a
finger. Separate the pieces by reversing the same straight motion.

### Card 5 — Inspect the joined pair

Look from the top, front, rear, and both ends. Photograph the full pair and a
close view of each of the three lap rows.

**PASS:** three full lap contacts are visible, the shoulders are seated, the
top is even, the part does not rock, the seam is consistent, and there is no
new damage.

**STOP:** there is a proud row, trapped strand, growing gap, rock, twist,
damage, or unclear contact. Do not use a keystone to pull a gap closed.

### Card 6 — Reverse once, then use the 1 / 5 / 10 checkpoints

Reverse the same straight hand motion and inspect both halves again. This is
**cycle 1**.

- If cycle 1 passes, repeat gently until **cycle 5**, then inspect and
  photograph again.
- If cycle 5 passes, repeat gently until **cycle 10**, then inspect and
  photograph again.
- If any cycle stops being easy and reversible, stop immediately. Do not
  continue to reach a number.

**PASS at a checkpoint:** the motion remains gentle and reversible, all three
laps still seat, and there is no shaving, dust, whitening, crack, looseness,
rock, twist, or permanent bend.

**STOP:** any condition changes or any doubt appears. Leave the parts apart and
record the cycle number.

## What happens after a 10-cycle dry-fit pass

Stop and record the result. A pass here means only that these two halves can be
joined and separated unloaded on a table. It does **not** authorize more
printing, the keystone, supports, installation, or load.

The later engineering sequence is documented in:

- [R11 provisional dry tabletop assembly](../r11/ASSEMBLY.md)
- [R11 exact model manifest](../r11/generated/first_outer_actual_bay_qualification_v1/manifest.json)
- [R11 physical qualification protocol](../r11/LOAD_QUALIFICATION.md)
- [frozen Gate A-left control overlay](../r11_print_v2/README.md)

Those documents remain the detailed engineering record. This page is only the
beginner-friendly handoff for the immediate two-half tabletop check.

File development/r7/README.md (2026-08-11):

# Story Corner R7 removable column cable hooks

R7 adds a detachable black-PETG cable hook to the removable decorative column
faces without changing the published R6 shelf, structural corbels, pier
overlays, joinery, package counts, or Bambu qualification bundle.

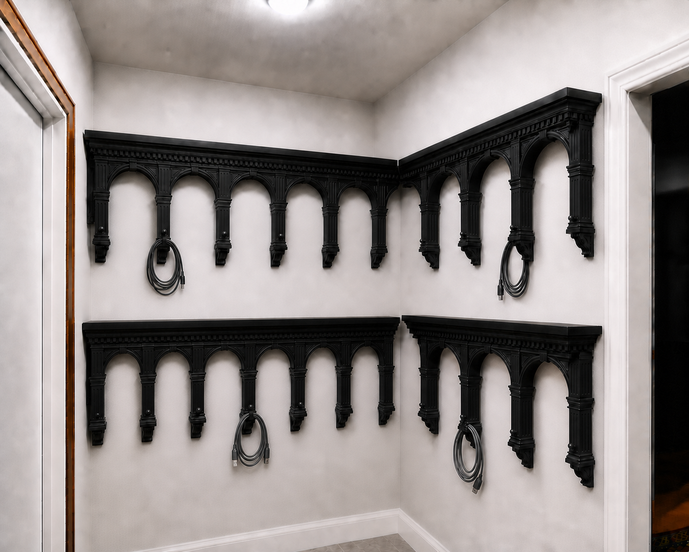
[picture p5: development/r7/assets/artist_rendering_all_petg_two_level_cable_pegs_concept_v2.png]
R7 cable-hook proof of concept


> **AI visual-intent image only:** the v2 rendering above is not a build
> diagram, counted inventory, or printable model. It may simplify, omit,
> repeat, or misplace hooks. The exact hook count and permitted locations are
> governed by the generated CAD, configuration, and schematic—not by the AI
> rendering.

## Exact placement and count authority

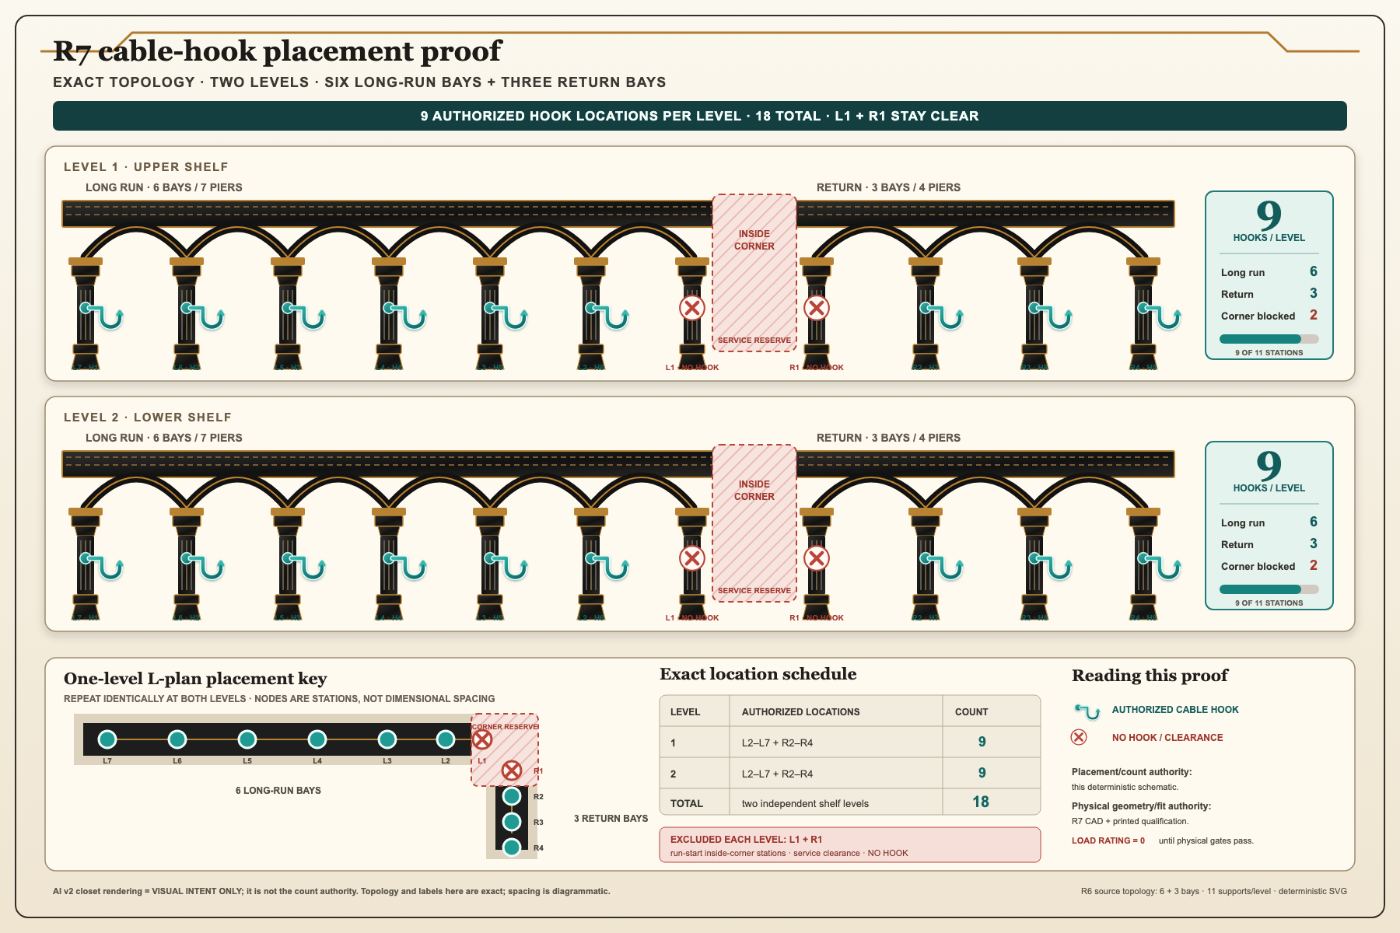
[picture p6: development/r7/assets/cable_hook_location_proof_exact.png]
Exact R7 cable-hook placement and count schematic


The deterministic schematic above is the placement-and-count authority:
`L2–L7` and `R2–R4` are the nine authorized hook stations on each shelf level;
`L1` and `R1` are the two excluded inside-corner run-start stations. The
two-level project therefore has exactly 18 authorized hook locations and four
excluded stations. Station spacing in this schematic is diagrammatic, not an
installation dimension. The R7 CAD and printed qualification remain the
authority for physical geometry and fit, and the rated load remains zero.

The [vector schematic](assets/cable_hook_location_proof_exact.svg),
[artifact manifest](assets/cable_hook_location_proof_exact.manifest.json), and
[proof notes](assets/cable_hook_location_proof_exact.NOTES.md) record the
source topology, exact station list, counts, digests, and limitations.

## Exact v4 collar geometry proof

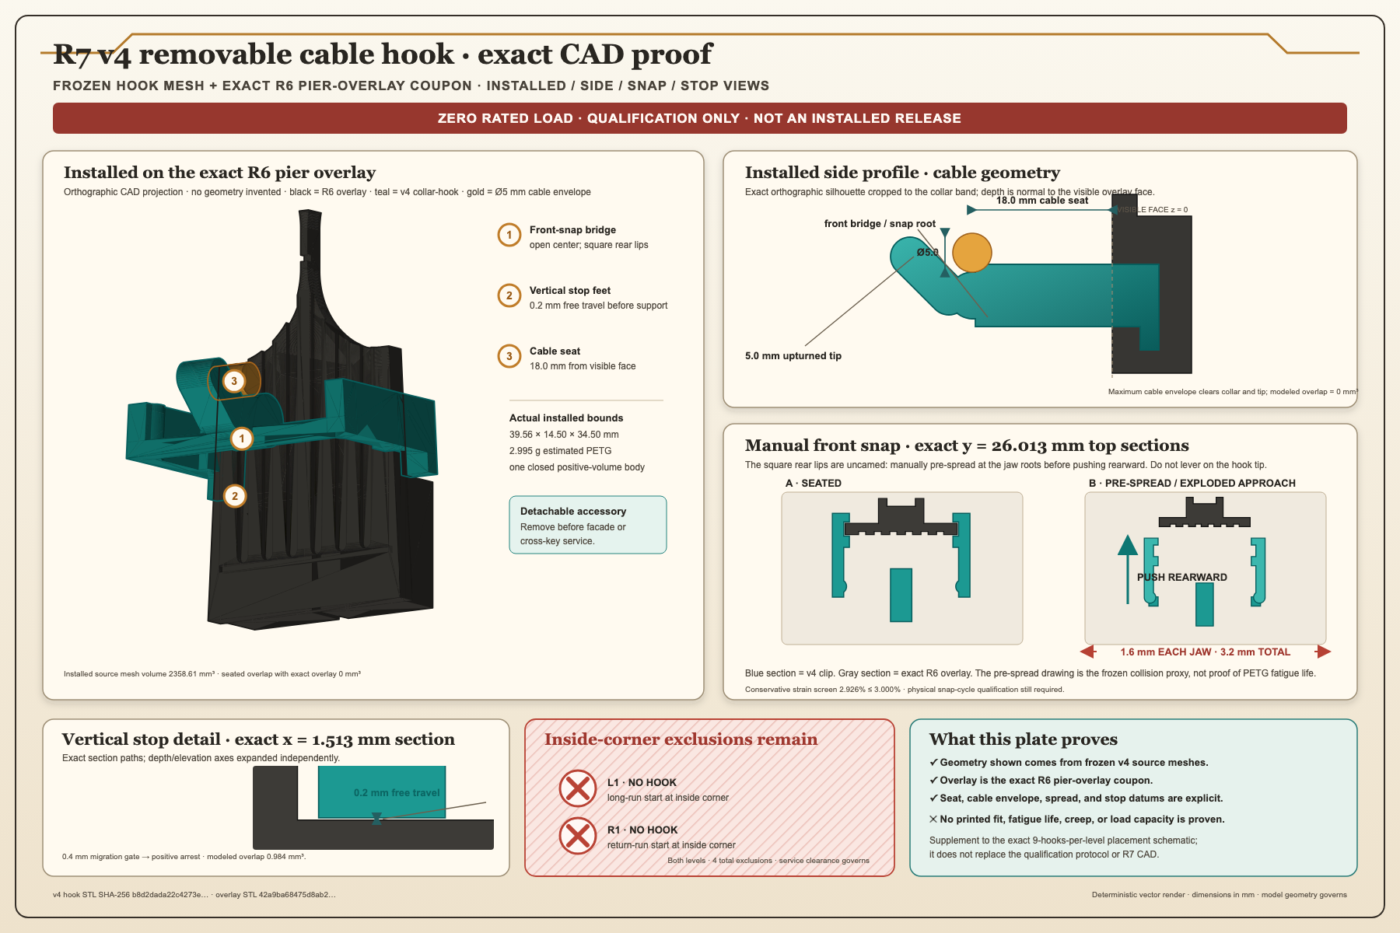
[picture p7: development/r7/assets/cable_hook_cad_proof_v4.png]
Exact R7 v4 removable cable-hook CAD proof


This deterministic plate is rendered from the frozen v4 hook STL and exact R6
pier-overlay coupon. It explains the installed collar, open-center bridge,
`18 mm` cable seat, maximum `5 mm` cable envelope, manual `1.6 mm` per-jaw
pre-spread, positive vertical stop, and the two inside-corner exclusions. It
is a geometry explanation—not evidence of printed fit, fatigue, creep, load
capacity, or production readiness. The [vector source](assets/cable_hook_cad_proof_v4.svg),
[asset manifest](assets/cable_hook_cad_proof_v4.manifest.json), and
[deterministic renderer](assets/render_cable_hook_cad_proof_v4.py) preserve its
provenance.

The generated qualification models and physical test record govern the
printable accessory. This remains a **qualification-only, zero-rated-load**
development article; generating, opening, slicing, or printing it does not
approve installation or use.

## What changed

- One front-snap C-collar/hook fits the unchanged R6 pier overlay.
- The collar seats at overlay-local elevation `22–30 mm` and clears the exact
  rear locator housing.
- The rounded hook provides `18 mm` of usable projection with a `5 mm`
  upward-retaining tip.
- Nine normal-facing hooks are possible per shelf level: the seven interior
  and two run-end columns.
- The two run-start columns flanking the inside corner stay clear. Their
  service-swept plan reserve is only `4.2325 mm`, so an `18 mm` normal hook is
  prohibited there.
- The accessory is removed before any ornament, cross-key, bridge, cassette,
  arcade, or corbel service.

R6 remains the released baseline at `258` objects per level and `516` for two
levels. If every physical R7 gate passes and nine hooks are promoted per
level, the counts become `267` and `534`. The hook receives no shelf-load or
structural credit.

## Generate and open the v4 qualification models

The instructions below are for **Bambu Studio 2.7.1.62** on a **Bambu Lab A1
mini with a 0.4 mm nozzle and Textured PEI Plate**. Generate a fresh v4
model-only qualification set from the repository root:

If the checked v4 directory already exists, do not run this command; open the
file below. The generator intentionally refuses to overwrite an existing
output directory.

```sh
.venv/bin/python development/r7/generate_cable_peg_qualification.py \
  --output development/r7/generated/cable_peg_qualification_v4
```

The combined qualification file is:

`development/r7/generated/cable_peg_qualification_v4/model_only_3mf/MODEL_ONLY_R7_CABLE_PEG_COLUMN_QUALIFICATION.3mf`

`cable_peg_qualification_v1`, `cable_peg_qualification_v2`, and
`cable_peg_qualification_v3` are superseded development history and must not
be used for printing, even if an old copy has not been renamed with a
`_SUPERSEDED` suffix.
The preserved `cable_peg_qualification_v4_pre_serialization_fix_SUPERSEDED`
tree is also forbidden: its hook STL and 3MF used different numeric vertex
precision. Only the active `cable_peg_qualification_v4` tree has the enforced
STL/individual-3MF/canonical-package geometry bijection.

The v4 combined file contains exactly three unsliced objects:

1. the exact R6 pier-overlay parent coupon;
2. the removable collar-hook, saved on a run-side face; and
3. the `0.20 / 0.30 / 0.40 / 0.50 mm` per-face clearance ladder.

### Neutral 3MF warning

The v4 file is a **neutral model-only 3MF**. It contains no G-code or
toolpath, and it does **not** embed or select the printer, nozzle, plate,
filament, temperatures, process, brim, or supports. Opening the file in Bambu
Studio does not apply the settings below. Studio may retain whatever was used
last, including PLA.

**Never reuse, copy, or edit a PLA profile for this PETG print. Never press
Slice plate or Print plate until every field below has been selected and
verified.**

## First-time PETG preparation

1. Confirm the spool is SUNLU standard black PETG 1.75 mm, retail ASIN
   [`B0D1KC72YP`](https://www.amazon.com/dp/B0D1KC72YP). Record its color,
   lot/batch, spool identity, and date.
2. Dry the exact spool at **60–65 °C for 6–8 hours** in a filament dryer rated
   for that temperature. Record the dryer, indicated temperature, start and
   end times, and exact cycle. A sealed new bag is not proof that PETG is dry.
3. With the Textured PEI Plate removed and cool, wash the print surface with
   dishwashing detergent and water, rinse it, and dry it completely. Do not
   use acetone and do not touch the cleaned print area.
4. Reinstall the clean plate in the correct orientation. Load the dried PETG
   and confirm that both the printer and Bambu Studio identify the intended
   PETG—not PLA.

## Exact Bambu Studio setup

In Bambu Studio's **Prepare** view, select these exact installed system
presets and values. If the SUNLU system preset is not available, stop and
enable/update the Bambu system presets; do not substitute a PLA preset.

| Bambu Studio field | Required qualification value |
| --- | --- |
| Printer | `Bambu Lab A1 mini 0.4 nozzle` |
| Plate type | `Textured PEI Plate` |
| Filament system preset | `SUNLU PETG @BBL A1M 0.4 nozzle` |
| Process system preset | `0.20mm Strength @BBL A1M` |
| Layer height | `0.20 mm` |
| Nozzle temperature | `250 °C` first layer; `245 °C` other layers |
| Textured-plate temperature | `60 °C` first and other layers |
| Flow ratio | `0.94` |
| Maximum volumetric speed | `9 mm³/s` |
| Wall loops | `6` |
| Top / bottom shell layers | `5 / 3` |
| Sparse infill | `25%`, `grid` |
| Part cooling | Leave the SUNLU system values unchanged: `10%` minimum, `30%` maximum, `90%` for overhangs |

Then make these explicit overrides; the selected system process does not set
them all correctly for this qualification plate:

- Under bed adhesion, set `Brim type` to `Outer brim only`, `Brim width` to
  `5 mm`, and retain the inherited `Brim-object gap` of `0.1 mm`.
- For the clearance-ladder print, leave `Enable support` off so support does
  not contaminate its four measurement openings.
- For the parent-coupon and collar-hook print, turn `Enable support` on, set
  `Type` to `normal(auto)`, and check `On build plate only`.

Select each object and verify scale is exactly `100%` on X, Y, and Z. Keep the
v4 saved positions and orientations. Do not use Auto arrange, Auto orient,
Lay on face, scale-to-fit, unit conversion, Cut, or any repair operation that
changes geometry. If Studio asks to repair or resize a model, cancel and
recheck that the exact v4 file was opened.

The collar is intentionally saved with its left tapered run-side jaw face flat
on the plate. Do not stand the hook projection upright and do not put the
column-visible face on the plate.

## Print job 1 — clearance ladder first

Open the v4 individual ladder file so there is no chance of accidentally
printing the other two objects. Unlike the superseded individual files, v4
includes the plate-edge translation required by the `5 mm` outer brim and
`0.1 mm` brim-object gap:

`development/r7/generated/cable_peg_qualification_v4/individual_model_only_3mf/MODEL_ONLY_R7_DEV_CABLE_PEG_COLLAR_CLEARANCE_LADDER_0P2_0P3_0P4_0P5.3mf`

Apply the exact printer, PETG, process, temperature, flow, infill, shell, and
brim settings above, with `Enable support` off. Its four openings run
left-to-right from `0.20` to `0.50 mm` clearance per face.

Click `Slice plate`, not `Print plate`, and complete the preview checks below.
Only after the preview passes should this one ladder be printed and inspected.

## Print job 2 — parent coupon plus collar-hook

Reopen the combined v4 qualification file. In the Objects list, select
`R7_DEV_CABLE_PEG_COLLAR_CLEARANCE_LADDER_0P2_0P3_0P4_0P5`, right-click it,
and choose `Set Selection Unprintable`. Confirm that only these two objects
remain printable:

- `R7_DEV_CABLE_PEG_EXACT_R6_PIER_OVERLAY_COUPON`;
- `R7_DEV_CABLE_PEG_FRONT_SNAP_C_COLLAR_HOOK`.

Reapply and verify every exact setting above. For this job, set `Enable
support` on, `Type` to `normal(auto)`, and `On build plate only` on. Do not
rotate or rearrange either object.

## Preview and first-layer stop checks

After each `Slice plate`, move the layer slider through **every layer** before
printing. Do not dismiss a warning. Confirm all of the following:

- the expected object or objects—and no others—have complete first-layer
  paths;
- every outer brim is continuous, remains inside the A1 mini printable
  boundary, and does not touch another brim;
- no object, brim, or support crosses a plate boundary or keep-out area;
- the ladder has no generated support in its measurement openings;
- on job 2, normal-auto support starts only from the build plate and does not
  fill the collar cavity or a coupon fit surface;
- the collar jaws, rear lips, hook root, projection, and upturned tip remain
  continuous in every layer;
- there are no floating regions, missing paths, collisions, empty initial
  layers, scale/repair notices, or out-of-bounds warnings.

If any check fails, stop. Do not improvise a new orientation or support layout
and do not print; record the Studio version, warning, settings, and screenshot
for engineering review.

Stay with the printer through the first layers. Stop the print immediately for
any lifting or curling, a detached brim or support, nozzle contact or scraping,
missing or intermittent extrusion, clicking or popping from wet PETG, severe
stringing, layer separation, or a toolpath that differs from Preview.

When a print finishes, wait until the Textured PEI Plate is **35 °C or below**
before removing it. Remove the cooled flexible plate and flex it gently; do not
pry hot PETG from the installed plate. Label and retain each specimen with the
date, Studio version, printer, nozzle, plate, spool/lot, drying cycle, and saved
profile.

## Fit sequence

1. Inspect and record the clearance ladder before selecting a fit.
2. Start with the frozen `0.40 mm` collar; do not scale or edit the mesh based
   only on the ladder.
3. The square rear lips have no automatic insertion cam. At the jaw roots,
   manually pre-spread **each jaw by at least `1.6 mm`** before pushing the
   collar rearward onto the parent coupon at the `22–30 mm` band. It is a
   front-snap part, not a top- or bottom-slide part. Never force insertion by
   pushing, pulling, or levering on the hook tip.
4. Reject the fit if it rattles, whitens, cracks, scratches the overlay, cannot
   be removed by hand, migrates more than `0.4 mm`, or obstructs an existing
   access opening.
5. Remove every cable and collar before servicing the shelf facade or joinery.

## Load status and qualification

The present rated load is **zero**. A printed part is still a test specimen,
not an approved cable hanger. The three-object coupon plate qualifies only
clearance, fit, and snap behavior; it cannot qualify the hook load path.

Every proof, cycle, creep, and migration load gate must use the exact printed
overlay installed on its real relevant R6 X-corbel/full assembly. A loose
overlay coupon or substitute fixture does not count. Apply each test load at
the cable seat exactly `18.0 mm` from the overlay visible face. Tip-applied
load is prohibited.

The `0.25 kg` working value below becomes available only after all tests pass
on the exact SUNLU-PETG print/profile and assembly:

- 100 complete snap-on/removal cycles;
- 1,000 cycles from zero to `0.25 kg` working load;
- 20 thermal cycles from `10–45 °C`, dwelling at least four hours at each end
  while carrying the working load;
- `1.00 kg` downward proof load for one hour;
- `0.50 kg` sustained creep load for 90 days;
- 72 hours unloaded recovery; and
- a separate destructive sample.

Fail on crack, whitening, jaw escape, overlay damage, loss of tool-free
release, migration over `0.4 mm`, accelerating deflection, or permanent hook
tip set over `0.5 mm` after recovery.

After qualification, use the hooks only for loose lightweight cable loops.
The maximum qualified cable or bundle outside diameter is `5 mm`; a larger
cable or bundle requires a new fit and load qualification. Do not hang
garments, bags, tools, leashes, tensioned extension cords, or any item a
person might pull. Hook loads never contribute to the shelf rating.

The drying and plate-care baseline is grounded in the
[SUNLU filament drying guide](https://www.sunlu.com/wiki/filament-usage-guide)
and [Bambu Textured PEI Plate guidance](https://us.store.bambulab.com/products/bambu-textured-pei-plate).

## Files

- [Exact R7 geometry contract](config.json)
- [Cable-hook geometry source](cable_peg_geometry.py)
- [Qualification generator](generate_cable_peg_qualification.py)
- [Geometry and artifact tests](tests/test_cable_peg_geometry.py)
- [Focused Bambu/PETG documentation tests](tests/test_cable_peg_readme.py)
- [Exact hook placement/count PNG](assets/cable_hook_location_proof_exact.png)
- [Exact hook placement/count SVG](assets/cable_hook_location_proof_exact.svg)
- [Exact visual manifest](assets/cable_hook_location_proof_exact.manifest.json)
- [Exact visual notes](assets/cable_hook_location_proof_exact.NOTES.md)
- [Exact v4 collar CAD proof PNG](assets/cable_hook_cad_proof_v4.png)
- [Exact v4 collar CAD proof SVG](assets/cable_hook_cad_proof_v4.svg)
- [Exact v4 collar CAD proof manifest](assets/cable_hook_cad_proof_v4.manifest.json)
- [Exact v4 collar CAD proof renderer](assets/render_cable_hook_cad_proof_v4.py)
- [Current concept rendering](assets/artist_rendering_all_petg_two_level_cable_pegs_concept_v2.png)
- [Rendering prompt and digest](assets/artist_rendering_all_petg_two_level_cable_pegs_concept_v2.prompt.md)

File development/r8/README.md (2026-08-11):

# Story Corner R8 — 16B structural D-frame scaffold

R8 translates the selected black 16B visual direction into a deliberately simple,
**100% PETG printed-parts** shelf system: two cassette shelf levels, compact
curved D-frame corbels, and removable cable accessories on safe interior
supports. The required wall fasteners are metal structural screws, not printed
parts. Black is the color direction, not a guaranteed matte finish; ordinary
SUNLU PETG can show gloss that varies with temperature, speed, surface angle,
and layer direction. This directory is a qualification scaffold, not a
production release.

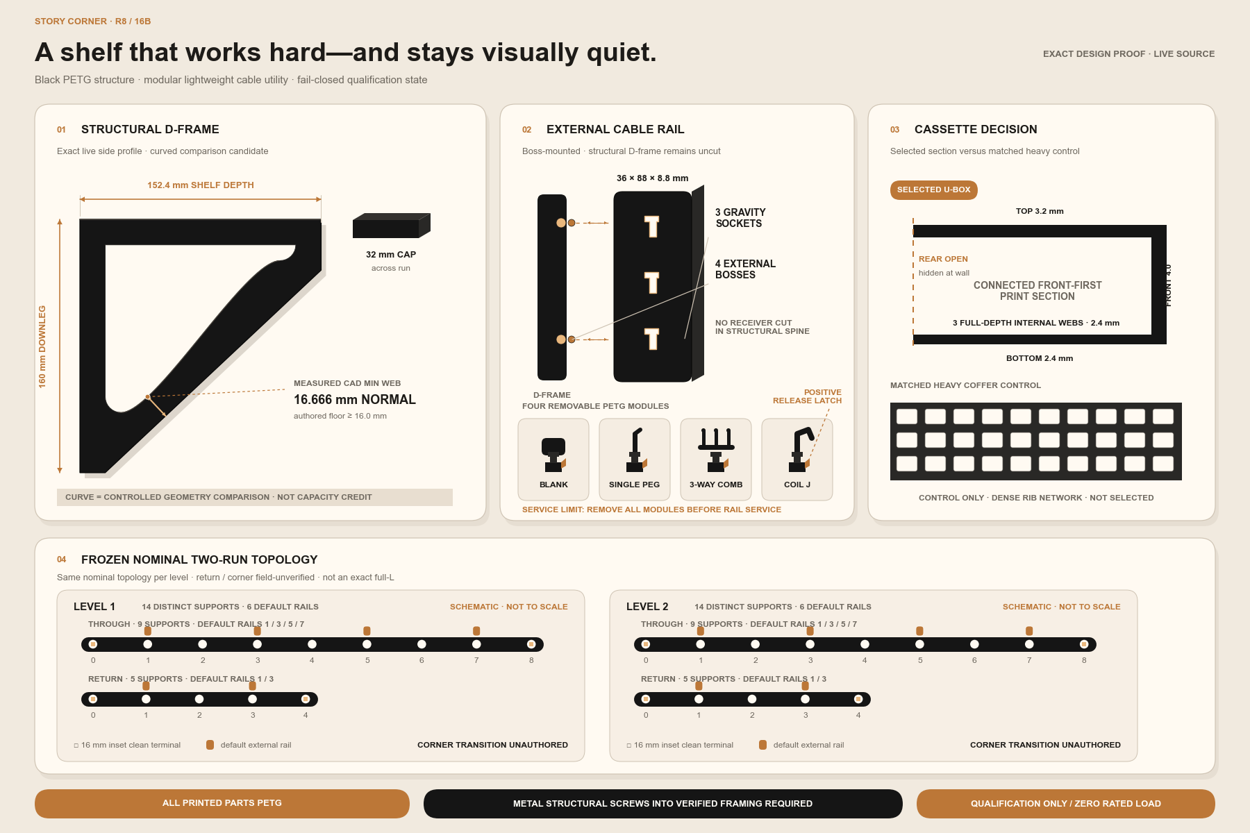
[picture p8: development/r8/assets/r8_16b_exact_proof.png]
Exact R8 16B design proof


The image above is a deterministic drawing generated from the live R8 source,
not a generative artist rendering. The matching SVG, source-linked manifest,
and renderer are in `assets/` and `render_proof.py`.

## Current source and artifact status

- The structural D-frame, an equal-volume straight control, the selected
  lightweight cassette, its heavier coffer control, the additive cable rail,
  four retained cable modules, and a four-clearance fit ladder are exact CAD.
- `generated/qualification_v1/` is **superseded and quarantined: do not print
  its D-frame, controls, cassette, rail, retained modules, or combined catalog**.
  It predates the final inward boss lanes and retained-module print-orientation
  contract. Keep it only as historical evidence; its own README is obsolete.
- `generated/qualification_v2/` is the current 15-part unsliced component and
  fit-coupon set. `generated/one_bay_qualification_v2/` is the current exact
  five-part cassette/support/rail/blank fit assembly. Their manifests bind the
  current source, PETG profile, geometry digests, runtime, and neutral 3MFs.
- Both v2 folders remain **qualification-only and zero-rated**. They authorize
  controlled fit printing, not wall installation, a complete shelf print, or
  any stored load.
- No existing artifact authorizes wall installation or load.

## Frozen nominal architecture

- Shelf depth: **152.4 mm (6 in)**; cassette height: **30.0 mm**.
- D-frame prototype: **152.4 × 160.0 × 32.0 mm** with 16.0 mm top and wall
  chords, a required 16.0 mm curved working web and an actual CAD minimum of
  **16.6663 mm**, a 32.0 mm front nose, and R10 inner roots. The longer downleg
  creates a clean rail zone.
- Through run: **1514.475 mm**, 8 cassette modules, 9 corbels.
- Return prototype run: **751.275 mm**, 4 cassette modules, 5 corbels. It
  starts 1.2 mm beyond the through deck's nominal front plane and ends at the
  existing 911.225 mm outer datum; both values remain field-unverified.
- Terminal corbel centers are inset 16.0 mm. Each corbel has a 32.0 mm bearing
  cap, so the terminal caps finish flush with the nominal run ends.
- Each 0.35 mm cassette seam is centered on an interior 32.0 mm cap. The seam
  leaves 15.825 mm of cap bearing beneath each adjacent cassette edge.
- The first and last corbel of each run are kept clean for corner and doorway
  clearance. Accessory eligibility is derived from support topology: 7 through
  plus 3 return corbels per level, not a hard-coded total.

The return length remains a prototype reference until the closet is measured.
R6's ornament-driven return start and asymmetric inset are intentionally not
carried into this simpler design.

Ten interior supports per level are geometrically rail-eligible, but the clean
default equips only alternating stations: through 1/3/5/7 and return 1/3
(zero-based within each run). That is **6 rails / 18 sockets per level**, or
12 rails / 36 sockets for both levels. The other supports remain visually
smooth; every run endpoint and inside-corner support is hard-excluded.

The seam-on-support layout uses **14 corbels and at least 42 metal structural
screws per level** (28 / 84 for both levels). It therefore assumes continuous
blocking or an independently verified equivalent framing plan. That framing is
not yet confirmed, and printed or hollow-wall anchors cannot substitute.

## Bambu Studio PETG starting profile

Use these only for qualification parts and coupons:

- Printer: Bambu Lab A1 mini; 180 × 180 × 180 mm build volume.
- Selected filament: SUNLU PETG, ASIN
  [B0D1KC72YP](https://www.amazon.com/dp/B0D1KC72YP?ref=ppx_yo2ov_dt_b_fed_asin_title&th=1),
  listing variant **4 kg / 2 Black + 2 Black** (four black 1 kg spools),
  1.75 mm ±0.02 mm. Confirm the received labels still say PETG and Black;
  Amazon listing variants can change. Record the exact spool lot before every
  qualification print. This project identifies the spool as standard PETG,
  not SUNLU High-Speed Matte PETG; do not infer a matte finish from the black
  concept image. PLA is not permitted for any R8 printed part.
- Material preset: **SUNLU PETG @BBL A1M 0.4 nozzle**.
- Candidate profile: 250 C first layer, 245 C remaining layers, 60 C Textured
  PEI plate, 0.94 flow ratio, and 9 mm3/s maximum volumetric speed.
- 0.4 mm nozzle, 0.20 mm layer height, 6 wall loops, **5 top shell layers**,
  **3 bottom shell layers**, and 25% grid infill.
- 5.0 mm brim with 0.1 mm object gap. Keep at least 2.0 mm between brims.
- SUNLU's [standard-PETG product page](https://store.sunlu.com/products/over-6kg-bundle-sale-petg-3d-printer-filament-1-75mm-1kg-roll)
  lists **50 C** for a blast drying oven and storage below 20% RH. Use 50 C as
  the project baseline for the 6-8 hour qualification cycle only when both the
  received spool label and dryer instructions permit it. Those received
  instructions control: never exceed the lower temperature limit stated by
  either one. Before qualification, record the spool lot, dryer, temperature
  setpoint, actual duration, date, and post-dry storage condition. Stop and
  resolve any label/dryer conflict instead of guessing. Clean the plate and use
  the plate maker's PETG interface/release guidance.
- Print each support on its broad run-side face. The bare structural core and
  boss-only wrapper remain inside **152.4 × 160.0 × 32.0 mm raw geometry**;
  with the 5.0 mm brim, 0.1 mm object gap, and 2.0 mm plate-edge reserve, that
  reference geometry requires 166.6 × 174.2 × 32.0 mm. It is not a complete
  printable support SKU because the installed supports also carry locator keys
  and keeper geometry.
- A terminal one-key support is **152.4 × 161.0 × 32.0 mm raw** and requires
  **166.6 × 175.2 × 32.0 mm** with the same process margins. Ordinary and
  dual-keeper smooth/bossed support variants are
  **157.600006 × 163.399994 × 32.0 mm raw** and require
  **171.800006 × 177.599994 × 32.0 mm**. The worst case is therefore about
  177.6 mm on the bed and still fits the nominal A1 mini volume. The inward
  boss lanes do not increase the 32.0 mm build height. Bambu Studio exclusion
  zones still require review.

The cassettes do not fit flat. The selected lighter U-box candidate prints each
one on its smooth visible front edge at 45 degrees on the bed, making the
152.4 mm shelf depth build Z. Its top, underside, and front remain smooth; the
open rear is hidden at the wall, and three full-depth webs repeat on every
layer instead of appearing as internal bridges.
The widest physical through cassette then occupies **177.6367 mm square** on
the bed, including the 5.0 mm brim, 0.1 mm brim-object gap, and 2.0 mm plate
edge reserve per side. That nominal envelope fits, but the
full-height orientation, first layer, ribs, supports, warping, and actual plate
exclusion zones remain physically unqualified. Do not print the shelf set yet.

For retained cable modules in the current v2 qualification bundle:

- The blank uses local XY on the bed with **local −Z as build direction**. Its
  broad common body is the first layer and the saved orientation is
  support-free.
- The single peg, three-position comb, and shortened coil J-hook require
  supports because their cable features create later islands. Use painted
  supports only after slicer review, and keep support material off the retained
  key, latch, rail sockets, and other fit-critical faces.
- Do not infer blanket “Support Off” from the quarantined v1 instructions.

For the longest module, the selected U-box uses **57.9%** of the matched heavy
coffer control's CAD volume (about **42.1% less**). Across both nominal shelf
levels, its cassette-only solid-CAD estimate is about **7.67 kg of PETG**
instead of 12.96 kg for the control. These are geometry-volume comparisons,
not Bambu Studio sliced mass or a strength result. Record actual sliced grams
and print time before choosing the production topology.

## Cable-use system

Eligible interior corbels carry an added, nonstructural face rail with three
standardized sockets. Planned modules are a blank, single cable peg,
three-position cable comb, and cable-coil hook. Receiver cavities may not cut
into the D-frame spine. Accessories have zero rated load and receive no shelf or
structural capacity credit until their own physical qualification is complete.

Install retained comb modules **bottom-up** and remove them **top-down**. The
exact service sweep shows that a moving comb collides with an occupied station
immediately above it, so an arbitrary comb cannot be inserted or removed while
that upper station remains occupied. This is a required module-service order,
not merely a cable-routing suggestion.

The rail attaches only through four additive bosses; it does not hollow or cut
the structural D-frame. Its lower edge is 48.0 mm above the corbel bottom
(112.0 mm below the shelf underside). Each module gravity-seats through 8.0 mm and uses a
positive release latch. Wrong-handed keys, unintended lift, rail removal, and
the declared service sequence are fail-closed in the exact Boolean tests. R8
does not claim unrestricted service with adjacent stations occupied. The clean
default uses six rails per level rather than covering every support.

## Safety and release status

The tested shelf capacity is **0 kg / 0 lb**. Production, installed release,
load-rating, and wall-bore generation are disabled. Structural wall screws and
compatible heads/washers into verified studs or blocking will still be required;
printed anchors and hollow-wall anchors in the primary load path are prohibited.
Every structural screw-length study must include the complete stack:

```text
minimum screw length = verified framing embedment
                     + 16.0 mm printed PETG wall chord
                     + washer thickness
                     + measured wall-substrate thickness
```

The selected screw diameter/length/head diameter/head height, washer OD/ID/
thickness, pilot diameter, substrate thickness, embedment, approved schedule,
and driver-access envelope are all required inputs. For the preliminary driver
study, each cross-section dimension must be at least the larger of screw-head
diameter and washer OD; axial access must be at least the screw-head height plus
that same larger span. Numeric completeness still does not authorize bores:
edge distance, PETG ligament, wall alignment, and installed driver clearance
require a separate geometry-specific CAD validation before any wall bore can be
authored.

The actual wall construction, framing, hardware schedule, canonical
`through_clear_length_mm` and `return_clear_length_mm` field measurements,
corner geometry, target contents load, driver access, and test protocols are
all intentionally null. Do not install or load an R8 part from this scaffold.

`FROZEN_BASELINES.json` records deterministic R6 and R7 tree hashes. The R8
tests verify those predecessor trees remain byte-for-byte unchanged while the
new design develops independently.

Start only with Gate 0: open the v2 clearance receiver and individual keys in
Bambu Studio from:

```text
development/r8/generated/qualification_v2/individual_model_only_3mf/
```

Print the keys loosest-to-tightest (0.5, 0.4, 0.3, 0.2 mm per face). Continue
only if the authored 0.4 mm key qualifies. Then follow the README inside
`generated/one_bay_qualification_v2/` for the five-part fit assembly. Do not
open either combined catalog as a ready-to-slice plate, and do not print v1.

Run the complete R8 source and artifact tests from the project root:

```bash
PYTHONDONTWRITEBYTECODE=1 .venv/bin/python -m unittest discover \
  -s development/r8/tests -p 'test_*.py' -v
```

The generators refuse the quarantined v1 tree and all existing destinations;
new revisions must use a new versioned folder rather than overwrite evidence.

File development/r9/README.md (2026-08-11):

# Story Corner R9 — Palatine Moderne compact shelf

R9 captures the simpler shelf direction selected after R8: a restrained
Roman/Art-Deco, two-level black PETG L shelf with only two shortened feature
columns per level. The design language is named **Palatine Moderne**.
The far-left and far-right columns carry candidate cable sockets; intermediate
supports are compact and smooth; the inside corner has no visible column pair.

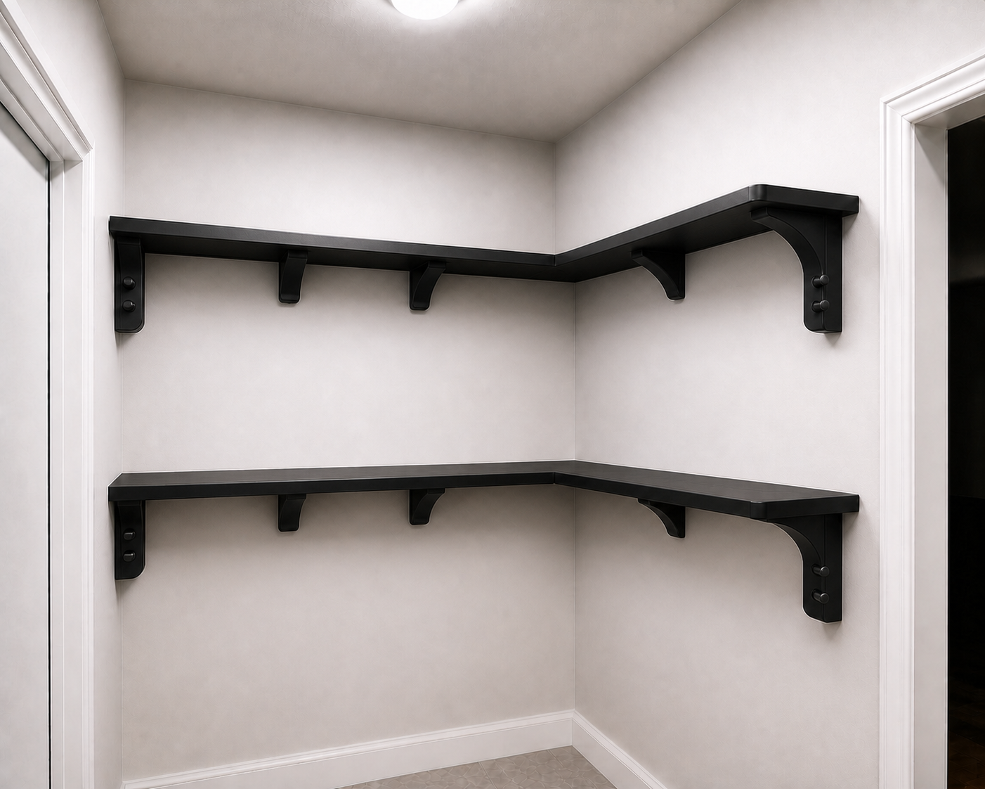
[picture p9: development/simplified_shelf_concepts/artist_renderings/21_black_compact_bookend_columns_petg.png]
R9 compact bookend visual intent


The image is an artist rendering, not proof of geometry, fit, framing, or load.
Its source prompt and hash are stored beside the image. `config.json` and
`design_math.py` are the exact authority for the current topology.

## Selected visual and practical layout

Per shelf level:

- **Far-left outer endpoint:** one shortened feature column with a candidate
  two-position cable rail.
- **Through-run interior:** three compact, ordinary-looking supports.
- **Inside corner:** two independently anchored but concealed support halves,
  one on each wall, joined beneath the shelf and hidden by one trim piece.
- **Return-run interior:** one compact support.
- **Far-right outer endpoint:** one shortened, handed feature column with a
  candidate two-position cable rail facing inward.

That retains every second R8 station: 8 structural stations per level with 6
visible supports—2 shortened bookends plus 4 compact supports. The two corner
halves remain structural candidates even though they are visually hidden. R9
does not delete the corner load path merely because the rendering looks clean.

Across both levels, the scaffold therefore calls for 4 outer bookend columns,
8 compact supports, and 4 concealed corner halves. Cable hardware is limited
to the 4 bookends: 2 sockets each, 8 sockets total. No peg or rail is allowed
on a compact support or at the inside corner.

The compact stations are approximately 14.59 inches apart on the long run and
14.16 inches apart on the return. The newly accepted wall measurements do not
silently respan this qualification scaffold or change its visible support
concept. Because a printed cassette seam now falls
between each pair of supports, this reduced count is inseparable from a
continuous segmented rear ledger and a staggered front-beam/fascia splice. The
ledger and splice are required qualification candidates, not optional trim and
not yet credited structure. At three metal screws per support candidate, the
visible/hidden supports alone imply 24 screws per level and 48 total; the
separate ledger fastener schedule remains unresolved.

All station centers in this scaffold are **run-local qualification
coordinates**, never drilling coordinates. The 5-foot/through run measures
from the far-left outer end toward the inside corner. The 3-foot/return run
measures from the inside corner toward the far-right outer end. R8's prior
global origins are deliberately not inherited; the field worksheet must
establish the real corner, trim, and framing datums before installed CAD is
authored.

## Shorter support proportions

- Shelf cassette thickness: **30.0 mm / 1.18 in**.
- Wall-hugging screw strap: **160.0 mm / 6.30 in** total drop beneath the
  shelf underside. This thin strip preserves a candidate three-screw lever arm
  but stays close to the wall.
- Outer bookend visible body: **120.65 mm / 4.75 in** below the underside.
- Compact visible corbel: **76.2 mm / 3.0 in** below the underside.

At proposed shelf-top elevations of 68 and 84 inches, the open shelf-to-shelf
height is about 14.82 inches. Directly beneath an outer bookend, about 10.07
inches remains above the lower shelf; beneath a compact corbel, about 11.82
inches remains. The thin wall strap extends lower but does not project through
the usable depth like the old full arch.

These dimensions are visual/qualification candidates, not credited structural
capacity. A 3-inch compact corbel has not been proven equivalent to the R8
160-mm D-frame.

## Corner and endpoint engineering boundary

The clean corner is not an unsupported printed L. The intended study uses two
A1-mini-printable hidden halves, each fastened independently into verified
framing on its own wall, plus an under-shelf shear key and cosmetic cover.
Corner angle, wall bow, framing, driver access, and the cassette intersection
are still unmeasured and unauthored.

R8 prohibited cable rails at terminal supports. R9 deliberately studies
handed endpoint rails, so both remain candidate-only until the doorway, trim,
snag, cable-loop, and removal-service envelopes are measured and tested.

The qualification geometry now includes distinct through-run and return-run
outer bookends. Each preserves the smooth support core and adds a fused,
two-socket receiver as positive PETG material; neither receiver is a removable
rail. A separate two-socket rail coupon, flush blank, and three-cable
comb/hook qualify the shared 0.4-mm-per-face, 8-mm gravity-seat interface
before either integrated bookend is printed. Both endpoint candidates remain
zero-rated and may not be wall-mounted until field clearance and physical
tests pass.

## Current field measurements and fit boundary

- Ceiling: approximately **96 in**.
- Top of outlet faceplate: approximately **53.5 in**.
- Proposed shelf tops: **68 in** and **84 in**.
- Through/long clear wall length: **61.25 in at both 68 in and 84 in**.
- Return/short clear wall length: **36.75 in at both 68 in and 84 in**. This is
  the conservative working value read from the supplied photos.

The existing R8-derived qualification scaffold remains 1514.475 mm
(59.625 in) on the through run and 751.275 mm (29.578 in) on the return run.
Against the accepted clear wall lengths, that leaves **41.275 mm / 1.625 in**
and **182.175 mm / 7.172 in**, respectively, as total unallocated clear-length
reserve. Those values only prove that the unchanged qualification scaffold is
shorter than the measured wall envelope. They are not endpoint offsets, trim
allowances, shelf cut lengths, corner compensation, or drilling coordinates.
Allocation still depends on the exact corner, wall bow, trim, and service
envelopes.

### Measured end-product spacing candidate

The immutable 5+3 qualification scaffold above is not the final measured
station map. `field_layout.py` applies the accepted wall lengths to the same
maximum-pitch ceilings and derives the minimum evenly spaced end-product
candidate:

- **61.25 in through/outlet wall:** 6 supports at **304.75 mm / 11.998 in**
  pitch, centered 0.630, 12.628, 24.626, 36.624, 48.622, and 60.620 inches
  from the far-left wall end.
- **36.75 in return wall:** 4 supports at **300.483 mm / 11.830 in** pitch,
  centered 0.630, 12.460, 24.290, and 36.120 inches from the inside corner.

That gives both walls one approximately 12-inch structural rhythm. Only the
far-left and far-right pieces are feature bookends; every visible middle piece
is the short compact form, and the two corner halves stay concealed. Per level
this is 10 structural support pieces, 8 visible and 2 hidden. Each support
candidate carries three authored fastener bores.

The first execution phase is deliberately narrower: **only the lower shelf at
68 inches on the 61.25-inch outlet wall**. Its six centers are exact design
candidates, not released drilling coordinates. The 84-inch shelf and the
36.75-inch return remain deferred until the lower through-wall shelf passes.

Still required before installed CAD stationing:

1. Horizontal distance from the through-run far-left datum to the outlet
   centerline.
2. Exact inside-corner angle and wall bow.
3. Stud or blocking locations and wall-substrate thickness.
4. Door-trim/service clearance and intended stored contents/load.

## What is ready to print first

The current versioned, neutral qualification bundle is
[`generated/qualification_v5`](generated/qualification_v5). It contains the
two self-contained corrected Stage-0 controls plus 17
individual model-only 3MF files, matching deterministic STLs, one off-plate
catalog 3MF, a generated README, validation evidence, and a hash manifest. The
catalog is **not** an A1-mini plate. Open individual files at 100% scale.

`generated/qualification_v1`, `generated/qualification_v2`, and
`generated/qualification_v3` are superseded history. V4 binds the accepted
wall measurements, exact user-supplied PETG identity, conservative first-print
process controls, and operator kickoff. Use only the v5 directory linked above.

Use the handoff guides in this order:

1. [`docs/MEASUREMENT_WORKSHEET.md`](docs/MEASUREMENT_WORKSHEET.md) — record
   exact field, electrical, framing, hardware, material, and load inputs.
2. [`docs/PRINTER_KICKOFF.md`](docs/PRINTER_KICKOFF.md) — exact material,
   Bambu Studio setup, Preview gates, and the human/operator handoff.
3. [`docs/PRINT_FIRST.md`](docs/PRINT_FIRST.md) — R8 clearance Gate 0, R9
   joint coupons, compact support, nominal-corner fixture, cable interface,
   then the two handed integrated bookends.
4. [`docs/TEST_PROTOCOL.md`](docs/TEST_PROTOCOL.md) — inspect and record every
   fit, flatness, service, and failure gate.
5. [`docs/ASSEMBLY.md`](docs/ASSEMBLY.md) — tabletop coupon and service
   procedures only; it does not authorize wall assembly.
6. [`docs/MATERIALS_AND_HARDWARE.md`](docs/MATERIALS_AND_HARDWARE.md) — exact
   first-shelf quantities, selected GRK/washer candidate, compatibility math,
   and the continuous-blocking stop.
7. [`docs/DESIGN_LANGUAGE.md`](docs/DESIGN_LANGUAGE.md) — the exact Palatine
   Moderne hierarchy and the no-weakened-structure ornament rules.

All 17 saved R9 articles are classified Support Off in software and fit the
A1 mini with the configured 5-mm brim, 0.1-mm brim-object gap, and 2-mm extra
edge reserve. Bambu Studio Preview review is still mandatory before every
print.

The qualification-v5 package still emits no G-code, wall bore, approved
fastener schedule, installed release, or load rating. Separate development of
the actual shelf architecture now publishes the versioned
[`generated/one_bay_prototype_v3`](generated/one_bay_prototype_v3) package. It
contains the two handed supports, rear ledger, front beam, and full-depth
three-web cassette that assemble into one exact 160 mm tabletop bay. Each
support includes three printed 7.0 mm round-envelope diamond bores at 16, 80,
and 144 mm below the shelf underside, plus flat-face room for a washer up to
20 mm OD. Adjacent holes are 64 mm apart. The support arch carries an additive
stepped Roman keystone and the front beam carries an additive stepped Art-Deco
center relief; neither decoration removes structural-core material. The holes
print with the part; do not drill or ream PETG afterward.

Those bores are hardware candidates, not wall-install authorization. The
selected fixture candidate is GRK RSS Climatek 1/4 in x 3-1/2 in, T25, part
90306, with one 1/4 in USS Type A steel washer per screw. The first lower wall
uses 18 installed screws/washers and the buy quantity is 24 of each. The exact
wall thickness, framing/blocking map,
electrical-clearance check, and proof-load protocol remain unresolved. The
preferred primary load path is metal structural screws into verified framing
or continuous blocking. A hollow-wall anchor may be considered only after one
exact product and the actual substrate are bound and tested; generic drywall
anchors are not silently credited.

`FROZEN_BASELINES.json` pins the complete R6, R7, and R8 development trees so
this new direction cannot silently rewrite previously audited evidence.

The current qualification sequence stops after standalone joint, support,
nominal-corner, cable-interface, and integrated-bookend tabletop articles. The
one-bay source now authors and software-validates the missing
member/support/cassette interfaces and mounting-bore pattern. The next physical
gate is that exact unloaded one-bay, followed by a framed-wall hardware
fixture. Only then may the lower 61.25-inch shelf set be emitted for proof,
creep, recovery, and destructive tests against a declared target load.

Run the current scaffold checks from the repository root:

```bash
PYTHONDONTWRITEBYTECODE=1 .venv/bin/python -m unittest discover \
  -s development/r9/tests -p 'test_*.py' -v
```

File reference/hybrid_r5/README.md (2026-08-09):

# Story Corner hybrid r5 fallback

This directory preserves the source configuration and generator for the verified `triadic_palatine_fitted_l_corner_r5` fallback. That revision used a black PETG Triadic Palatine finish over a plywood-and-steel shelf chassis. It is **not** the active 100%-printed shelf requested for r6.

The r5 fallback completed its deterministic 22-test regression suite, model-only 3MF archive validation, watertight/single-body mesh checks, 180 mm saved-orientation envelope checks, and repository consistency audit. It made no tested load-rating claim and contained no embedded G-code.

- `config.hybrid.json` is the frozen r5 configuration.
- `scripts/generate_hybrid_r5.py` is the frozen r5 generator source.
- The tracked source can regenerate its own isolated
  `reference/hybrid_r5/generated/` tree. That tree is ignored so hybrid output
  cannot be mistaken for the active r6 artifacts.

Do not mix r5 hybrid cut dimensions, fascia channels, or load-path instructions into the all-PETG r6 build.

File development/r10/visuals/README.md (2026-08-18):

# R10 visual assets

## Deterministic one-bay and first-wall topology

`r10_one_bay_exploded_and_first_wall_topology.svg` is a source-controlled
engineering communication diagram.

- Canvas: 1600 x 1250 SVG units.
- SHA-256: `3bd772110896c264f1cd927933841180dd154d2077b6038d298510256cbf05fb`.
- It records the 254 mm one-bay topology, exact article roles, preassembly
  order, flush-capped log keys, 2.4 mm bayonet motion, 4.0 mm service grip,
  broad bearing lands, and the seven-support / six-bay first-wall topology.
- It deliberately omits wall-hole locations and marks S6 as a replaceable,
  unreleased terminal placeholder.

The SVG is authoritative only for the labeled planning topology. Mesh source,
validated geometry evidence, `ASSEMBLY.md`, and the manifest control exact
part surfaces, saved orientations, and serialization. It is never a drilling
template, print plate, capacity calculation, or installation authorization.

## Industrial-design intent

`r10_palatine_lincoln_arcade_visual_intent.png` is a generated industrial-design
concept, not engineering evidence.

- Pixel dimensions: 1536 x 1024.
- SHA-256: `915838a6b8b293a3f7b5944a8012c8a741456e495241851568712966571f8a42`.
- Intended reading: one lower black-PETG shelf; seven supports / six bays;
  longer far-left cable bookend; five shorter intermediate corbels; discreet
  far-right terminal/corner placeholder; narrow physical bay seams; restrained
  Roman aqueduct plus Art-Deco furniture language.
- Non-authoritative details: receiver/socket shape, screw visibility, exact
  curves, relief, wall conditions, and all dimensions.

Never trace this raster image into CAD or infer a load path, part count, bore
position, clearance, print orientation, or rating from it. The R10 config,
geometry source, validation reports, and physical qualification records control.

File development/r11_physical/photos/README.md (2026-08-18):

# R11 physical-photo provenance

> Photos document appearance and reported handling only. They do not prove
> dimensions, hidden contact, material properties, load capacity, or a passed
> qualification gate.

## Source observations

The left article observation in [../PHYSICAL_RECORD.md](../PHYSICAL_RECORD.md)
references these user-supplied attachment sets without publishing local or
temporary filesystem paths:

| Evidence ID | Images | What is visible | Limits |
|---|---:|---|---|
| `925CA0D3-6200-496B-A109-CA4D2610463B` | 1–8 | Multiple views of the completed left half-deck, including top, bottom, edges, fingers, and end views | No scale, no right mate, no measured fit, no load |
| `83787EA1-DE26-4497-BB8C-7FC25D665434` | 1 | Left half-deck standing on the table after the user reported no rocking | A still image cannot independently prove flatness or absence of motion |

Cryptographic source references, in image order:

- `925CA...` image 1: `646c31b35bb67188e77abfd92c3c09e2c420d675fdaab9f34cffaf3cc2e8583c`
- `925CA...` image 2: `631b42988708b731505988ef9e332e2ae5fa77266d86bb25008347c0b089ddac`
- `925CA...` image 3: `e8334c57ccf887436a1bdffefe264ca654a92a457f584e462b8a34316656d03d`
- `925CA...` image 4: `917b03245b5172897cb30f4c11e0f384d5a3abc514988e67968b74a1104fb8ae`
- `925CA...` image 5: `96b0d66046600eb1dbbf3e7494eed748a388058abdfeb445df750eaa8fd37016`
- `925CA...` image 6: `cb4d2d05cf6f2a443a67ef170cbc41339ac437c3c163f4d98e6c07a6b36faef9`
- `925CA...` image 7: `c5673ec24bef7b7bd1cad602716335ee2f3bdfb6fc85e955b5dc6f59d4367483`
- `925CA...` image 8: `87546c71d436c587fe3f742a41212e9cd5d60cb642de905d059456c0ed6b68a9`
- `83787...` image 1: `6636e852ba4d0e40dd4f7dcdac8304c59b4267f397bee0f5a03f3d9f9ca37fe2`

These hashes identify the private source attachments without publishing their
temporary local paths. The attachments themselves, not the transformed image
below, remain the controlling visual observations.

The original attachments remain the observation sources. If copies are added
to a future release, record the repository filename, byte count, SHA-256, and
any metadata removal without changing the evidence ID.

## Cleaned presentation reference

Expected repository asset:

- `left-half-clean-reference.png`

This is a background-cleaned documentation aid derived from a user photo. It
is for orientation and presentation only. It is **not** a measurement image,
not a substitute for an original, and not evidence of a feature that the
source photo did not clearly show.

Image-edit provenance:

- Source evidence ID: `925CA0D3-6200-496B-A109-CA4D2610463B`, image 8.
- Mode: image edit; preserve the printed article, remove only background
  distraction, and use a neutral documentation background.
- Exact generation prompt:

  > Use case: precise-object-edit
  > Asset type: engineering assembly guide reference photograph
  > Primary request: Create a clean, documentation-ready version of this
  > exact photograph of the black PETG R11 left terminal integrated half-deck.
  > Rotate the image so the part is upright and easy to understand, crop
  > tightly but keep the complete printed part visible, replace only the
  > distracting desk/keyboard/background with a plain neutral matte
  > background, and improve exposure so black surfaces and openings remain
  > legible.
  > Input image: edit target and sole source of part geometry.
  > Constraints: Preserve the printed part's geometry, proportions, openings,
  > fingers, capture slot, surface texture, layer lines, seams, and any visible
  > imperfections exactly. Do not add, remove, straighten, repair, smooth,
  > reshape, mirror, or invent any feature. Do not add arrows, labels,
  > dimensions, text, watermark, hands, tools, supports, or other parts. This
  > is a presentation reference only, not fabricated evidence.

- Final asset SHA-256:
  `a8d6ae08c5cc06fe8967a1790233a1adceac7dd102651eadc38584cd67bccbd4`
- Authenticity metadata: the PNG intentionally retains its C2PA/JUMBF
  generative-edit provenance. This is kept for transparency; it is not relied
  on as dimensional or qualification evidence and must not be stripped without
  producing a new asset hash and provenance record.
- Review: visually compared with source image 8. The overall article outline,
  three reciprocal rows, center body, edge walls, visible capture feature, and
  visible surface seams remain recognizable. Because generative editing is
  not pixel-preserving, the original attachment remains controlling evidence.

Do not use the cleaned image to infer gaps, dimensions, flatness, contact, or
capacity.

## Photos still needed for the one-bay dry fit

Take these only after the right half has finished, cooled, been removed, and
passed its visual check:

1. Both complete halves side by side, top faces up, with left/right labels in
   frame.
2. Both wall-side edges aligned and both front edges visible before contact.
3. Close view of the rear lap row aligned but not engaged.
4. Close view of the center lap row aligned but not engaged.
5. Close view of the front lap row aligned but not engaged.
6. Full top view after the first gentle join.
7. Low front-edge view showing top alignment and the center seam.
8. Low wall-side view showing all three lap rows.
9. One close view per lap row after cycle 1.
10. Full top and low edge views after cycle 5.
11. Full top and low edge views after cycle 10.
12. Both separated halves after cycle 10, showing every lap face and finger.

Use the same lighting and camera direction for the cycle 1, 5, and 10 views so
changes are easy to compare. Include a handwritten card with article IDs and
cycle number; do not rely on filename order alone.

## Short video still needed

Record one continuous, stationary-camera clip after the first still-photo fit
passes:

1. Show both labels and both separated halves.
2. Point to rear, center, and front lap rows.
3. Align all three rows.
4. Join once with the gentle straight hand motion.
5. Pause on the seated top and seam.
6. Reverse the same motion and show both separated lap faces.
7. End on a card reading `cycle 1` and the date.

Keep the complete motion and both hands in frame. Do not speed up, cut around a
bind, or add a reenacted take to the evidence clip. A later edited copy may be
made for teaching, but preserve and hash the original continuous file first.

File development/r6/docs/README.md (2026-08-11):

# Story Corner

Story Corner is a fitted, two-level, inside-corner shelf whose entire shelf
body is printed in black PETG. The deck cassettes, tied-arcade halves,
X-corbels with integral bearing caps, joinery, keeper strips, pins, cross-keys,
facade, and ornament
are printed.
The only nonprinted installation boundary is suitable metal structural screws
with integral heads or compatible metal washers, driven into verified wood
studs or purpose-installed blocking.

> **EXPERIMENTAL / UNRATED / NOT READY FOR OVERHEAD USE.** No tested load
> rating exists. Production wall holes are deliberately blocked, the real wall
> and storage measurements are incomplete. The intended local printer, nozzle,
> build plate, and black-PETG product are now identified, but their exact
> spool/lot, saved slicer profile, print behavior, and target load are not
> qualified. Do not install or load this design until the measurement, coupon,
> wall-mockup, full-bay,
> whole-article thermal-cycle, sustained-creep, recovery, teardown, and
> separate destructive-specimen gates are completed.

There is no embedded G-code. Release artifacts remain model-only so that an
unqualified machine or material profile cannot be mistaken for a safe print
recipe.

## The nominal fitted L

The current reference geometry fits nominal 60 in and 36 in finished walls at
one elevation. It is 6 in (152.4 mm) deep. The long-wall run passes through the
corner; its 6 x 6 in corner cassette visually completes the short wall, whose
independent return begins beyond that front plane.

| Item | Nominal value |
| --- | ---: |
| Long-wall through run | 1514.475 mm (59.625 in) |
| Short-wall structural return start from the corner datum | 177.55 mm (6.990 in) |
| Short-wall printed return length | 733.675 mm (28.885 in) |
| Shelf depth | 152.4 mm (6 in) |
| Chassis-to-return structural clearance | 18.8 mm |
| Locked all-solid / relieved visible-base corner gap | 1.2 / 2.0 mm |
| Long / return visible bays | 6 / 3 |
| Total visible bays | 9 |
| Long / return wall-fastened supports per level | 7 / 4 |
| Half-bay cassettes per level | 18 |

This is the design's 3 / 6 / 9 rhythm: three return bays plus six through bays
make nine. The support equation is `(3 + 1) + (6 + 1) = 11` independently
wall-fastened X-corbel/pier stations per level. Dimensions are nominal
regression fixtures, not permission to print or drill; field measurements must
regenerate them.

Field qualification requires four distinct elevation/run support records:
lower-through, lower-return, upper-through, and upper-return. Each record must
contain the exact clear width, every verified support center, wood
stud/blocking material, and framing verification method. Matching nominal
centers do not permit one elevation's record to stand in for the other. The
fastener record must also include maximum driver outside diameter and required
straight approach, and the material record must name the filament drying
method.

The corner datums are deliberately distinct: chassis front 158.75 mm,
integral-boss front 165.95 mm, full locked removable-facade front 171.95 mm,
floating return-finish solid/visible leading planes 173.15/173.95 mm, maximum
through-facade service face 176.35 mm, and return structural start 177.55 mm.
The floating return finish cantilevers 4.4 mm back from its cassette and must
be removed first before servicing the fixed through rosette.

Each complete level contains 258 installed printed objects: 225 chassis,
joinery, and retention objects plus 33 removable ornament objects. The two
selected, structurally independent levels contain 516 installed printed
objects. Calibration coupons and destructive test pieces are additional and
are not included in those totals.

At a contextual PETG density of 1.27 g/cm³, the current repeat-weighted CAD
solids total about **16.000 kg per level** and **32.001 kg for two levels**
(current exact software report: 16.000337 / 32.000674 kg).
Those are model-solid context values—not slicer estimates, finished tare, or a
load rating—but they expose the project's substantial possible material and
dead-load demand. The generated package report must derive these totals from
the actual meshes and repeat counts. Confirmed Bambu Studio sliced mass and a
weighed finished-level tare are mandatory before any wall-fastener, full-bay,
or wall-mockup qualification; contents load is additional.

No authoritative print-time estimate is available. The printer, nozzle,
and plate intended for local qualification are now known, but the exact PETG
spool/lot, drying record, saved profile, calibration, supports, brim, and plate
layout remain unqualified. `slice_report.json` correctly records that release
slicing was not performed. Print time must come from a retained local slice
report for the exact qualified machine/material/profile; CAD volume is not a
time estimate.

## Confirmed local qualification setup

The intended qualification setup is a **Bambu Lab A1 mini**, **0.4 mm nozzle**,
**Bambu Textured PEI Plate**, and **SUNLU standard black PETG 1.75 mm**, retail
ASIN [`B0D1KC72YP`](https://www.amazon.com/dp/B0D1KC72YP). This confirms what
to test; it does not qualify a production profile or any structural part. The
listing identifies the product as GRS-certified with at least 50% recycled
content. That is not a disqualification, but results must remain specific to
this product, color, lot, spool, drying record, and saved profile. Do not carry
results to a different PETG product or lot.

> **Do not reuse the current Bambu Studio PLA profile.** Select the installed
> Bambu Studio **system** filament profile named exactly
> `SUNLU PETG @BBL A1M 0.4 nozzle`, and verify that the project says PETG—not
> PLA—before every slice and print.

The following is a **candidate qualification starting point**, not a SUNLU- or
Bambu-certified A1 mini preset and not a production recipe:

| Bambu Studio field | Candidate value |
| --- | --- |
| Printer | Bambu Lab A1 mini, 0.4 mm nozzle |
| Plate | Textured PEI Plate |
| Filament | Installed Bambu Studio system profile `SUNLU PETG @BBL A1M 0.4 nozzle`; SUNLU standard black PETG 1.75 mm, ASIN `B0D1KC72YP` |
| Nozzle temperature | 250 °C first layer; 245 °C other layers |
| Textured-bed temperature | 60 °C first and other layers |
| Flow ratio | 0.94 |
| Maximum volumetric speed | 9 mm³/s |
| Process | `0.20 mm Strength`; 0.20 mm layer height |
| Wall loops | 6 |
| Top / bottom shell layers | 5 / 3 |
| Sparse infill | 25%, grid |
| Brim | 5 mm baseline; a qualification-project plate may require an explicit override |
| Supports | Off by system default; review each plate and retain any project-specific override |
| Part cooling | 10% minimum, 30% maximum, 90% for overhangs |

For the first baseline, leave those embedded system/process values in place;
do not improvise cooling, shell, infill, support, or brim changes. The local
qualification builder may deliberately override support or brim per plate, in
which case its plate value governs and must be recorded.

Before a qualification print, dry this spool at **60–65 °C for 6 hours** and
record the dryer, indicated/verified temperature, time, spool/lot, and date.
Wash the Textured PEI Plate with detergent and water, rinse and dry it fully,
and avoid touching the print area. SUNLU's current pages differ in some
details, so the saved values above remain a conservative, lot-specific test
baseline that must be calibrated and inspected.

Beginner sequence:

1. Clean and fully dry the plate; dry and record the exact PETG spool, then
   load PETG into the A1 mini.
2. Open the local qualification project—not a canonical model-only package as
   a direct print job—and select A1 mini / 0.4 mm / Textured PEI Plate.
3. Select the installed system profile `SUNLU PETG @BBL A1M 0.4 nozzle`.
   Confirm **PETG, not PLA**, and confirm every object's scale remains exactly
   100% on all axes.
4. Slice locally. Inspect the first layer, supports, brim, every layer/toolpath,
   plate boundaries, and warnings in Preview before sending anything.
5. Run supported A1-series Flow Dynamics calibration when the firmware allows
   it. On A1 mini, run Bambu Studio's **manual coarse and fine Flow Rate**
   calibration and save the result as a new filament preset.
6. Print only one qualification plate at a time, watch the first layer, and
   stop on lifting, scraping, skipped paths, severe stringing, or extrusion
   trouble. Let the plate cool to **35 °C or below** before removal.

The local qualification helper is development tooling, not a release builder.
Use the command that matches the tree you actually have, with the same exact
fresh sibling output path.

From the source-workspace repository root:

```text
.venv/bin/python development/r6/build_bambu_qualification_projects.py --output ../story-corner-r6-bambu-a1mini-sunlu-petg-qualification-v1
```

From the flattened published-project root:

```text
.venv/bin/python build_bambu_qualification_projects.py --output ../story-corner-r6-bambu-a1mini-sunlu-petg-qualification-v1
```

The helper atomically creates that fresh workspace sibling and must refuse to
replace an existing destination or write anywhere else. Keep
`../story-corner-r6-bambu-a1mini-sunlu-petg-qualification-v1/` local and separate
from `development/r6/generated/`; it is unsliced, contains no G-code, and is
not covered by the release manifest.

For now, print only non-wall qualification coupons. Do **not** print the solid
wall-screw placeholder/coupon, an X-corbel, the one-level package, or the
two-level installation set until actual fastener, wall, driver-clearance, and
physical gates are resolved. The A1 mini advertises a 180 x 180 x 180 mm build
volume, while a saved X-corbel plus the required 6 mm brim consumes exactly
180 mm on one bed axis. That is zero nominal margin before plate keep-outs,
placement tolerance, or slicer constraints; scaling, cropping, omitting the
brim, or changing orientation is not an acceptable workaround. The X-corbel
is not part of the initial campaign; its 6 mm brim is a deliberate
project-specific override to the general 5 mm candidate baseline.

Official setup references: [Bambu Lab A1 mini specifications](https://us.store.bambulab.com/products/a1-mini),
[Bambu Textured PEI Plate care and PETG guidance](https://us.store.bambulab.com/products/bambu-textured-pei-plate),
[Bambu Flow Dynamics calibration](https://wiki.bambulab.com/en/software/bambu-studio/calibration_pa),
[Bambu Flow Rate calibration](https://wiki.bambulab.com/en/software/bambu-studio/calibration_flow_rate),
[SUNLU standard PETG product guidance](https://www.sunlu.com/products/petg-3d-printing-filament),
[SUNLU filament drying guide](https://www.sunlu.com/wiki/filament-usage-guide),
and [SUNLU printer-preset selector](https://www.sunlu.com/materials-lab/printer-presets).

## Two independent levels

The provisional layout places shelf tops at +12 in and +33 in above the top of
the outlet, giving 21 in top-to-top spacing. Those positions use the reported
43.5 in outlet-top-to-ceiling zone and must be remeasured from a common level
datum. Install and service-check the upper level first, then the lower level.
No column, arch, key, or corner trim transfers load between levels.

## How the system works

The coffered deck, integral front/rear cassette chords, front tied-spandrel
arcade, and wall-fastened 3:4:5 X-corbels form a candidate load-sharing
chassis. The
curved Roman rib is not treated as a pure-compression arch: it may see mixed
compression, bending, tension, and shear. Only matched full-bay testing with
and without the curved frame may establish whether it earns structural credit.

Assembly uses a final-position vertical lift. Each arcade half rises at its
final run coordinate so two top tenons and one spring tenon enter three
open-bottom receivers together. Two top positive quarter-turn cross-keys plus
one spring cross-key are then inserted and visibly indexed from the front. A separate crown bridge rises from below
to a hard stop and receives one accessible anti-drop pin on the fixed right
half. No whole-half longitudinal slide is allowed; the rejected sliding motion
would deadlock at the crown.

Nine crown seams are locally fixed within their bays. After three diaphragm
keys are installed at each fixed crown, one left-owned keeper lifts from below
and slides rearward so its single rear-bayonet tongue is captured. A separate underside keeper-reach
indexed quarter-turn pin blocks the full forward unlock slide.
The front crown tie inserts from the visible edge and has its own
separate visible-front indexed quarter-turn pin.
Seven supported pier seams float axially to accommodate movement and their
three keys remain trapped by the X-corbel's integral bearing cap. Cross-keys, alignment keys,
keeper strips, and retention pins receive no independent vertical load rating.

The earlier stitch-rail study is deliberately excluded from the installed
baseline. At the geometry-current return length it would add 119 unqualified
pieces per level and an unproven second
thermal/load path. Any future rail must earn its way back through a named,
rail-on/rail-off full-bay experiment; the active design assigns it no capacity
credit.

Roman arcade and entablature are the primary visual language, disciplined by
Greek proportion and fluting. Egyptian influence is limited to a shallow
cavetto, and Art Deco appears only as restrained sunbursts, chevrons, and a
stepped keystone. Fine ornament is isolated, removable, and assigned zero
structural credit.

## Visual-intent assets

The [exact 6 + 3 two-level rendering](assets/artist_rendering_all_petg_two_level_exact_6_plus_3.png)
is the current visual-intent hero. The [earlier two-level rendering](assets/artist_rendering_all_petg_two_level.png)
is preserved as visual-development history, and the
[rendering prompt](assets/artist_rendering_all_petg_two_level.prompt.md) records
the intended scene. Both images are illustrative only: generated drawings,
schedules, and the manifest govern dimensions, bay counts, object counts, and
geometry.

## Start here

1. Read [PRINT_ME_FIRST.md](PRINT_ME_FIRST.md) and [SAFETY.md](SAFETY.md).
2. Complete [MEASUREMENT_WORKSHEET.md](MEASUREMENT_WORKSHEET.md), including
   photos, framing verification, storage, printer, material, and fastener data.
3. Review the governing [plan drawing](generated/drawings/plan_layout.svg),
   [two-level layout](generated/drawings/two_level_vertical_layout.svg), and
   [joinery sequence](generated/drawings/exploded_joinery.svg). Drawings govern;
   renderings are visual intent only.
4. Follow [TEST_PROTOCOL.md](TEST_PROTOCOL.md) before any overhead installation.
5. Use [ASSEMBLY.md](ASSEMBLY.md) only after every hard gate has passed.

The design rationale and exact load-path boundaries are in
[ENGINEERING_DESIGN.md](ENGINEERING_DESIGN.md). Research and the supplied-file
audit are recorded in [REFERENCE_RESEARCH.md](REFERENCE_RESEARCH.md) and
[REFERENCE_3MF_AUDIT.md](REFERENCE_3MF_AUDIT.md).
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

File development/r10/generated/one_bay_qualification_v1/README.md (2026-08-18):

# R10 one-bay qualification bundle — not a production set

This is the first **actual printed Lincoln-log shelf bay** and the separate
far-left S0 cable-bookend candidate set.  It is neutral, unsliced geometry for
tabletop qualification.  The current rating is **0 kg / 0 lb**.

## Hard boundary

- Do not drill or install this candidate on a wall.
- Do not place stored load on it.
- Do not print the combined catalog; it is deliberately off-plate.
- No slicer profile, G-code, toolpath, or printer command is present.
- `requirements.txt` is copied and its exact runtime match is recorded.
- A human must inspect every individual model in slicer Preview and give fresh
  permission before every physical print.
- Never auto-scale.  All model units are millimetres.

Read `PRINT_FIRST.md`, then select only its explicitly named files from
`individual_model_only_3mf/`.  Follow `ASSEMBLY.md` exactly and use the SVG
only as an off-plate visual reference.  The cable receiver and modules have
zero structural credit.

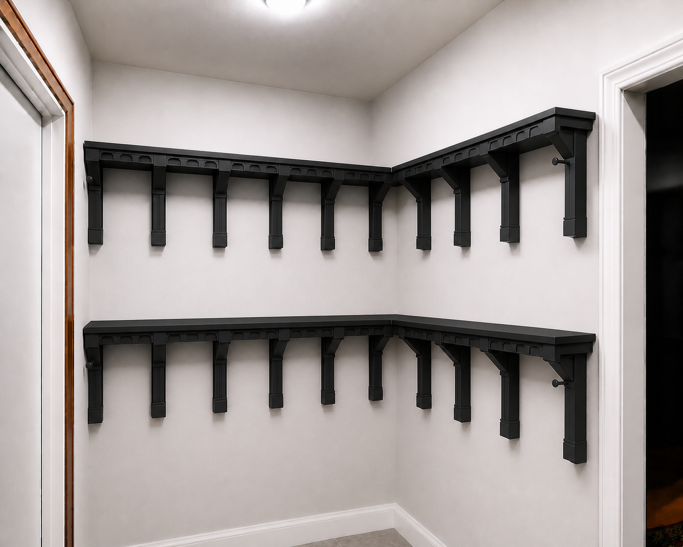
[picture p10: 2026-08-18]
development/simplified_shelf_concepts/artist_renderings/11_black_classical_arcade_petg.png

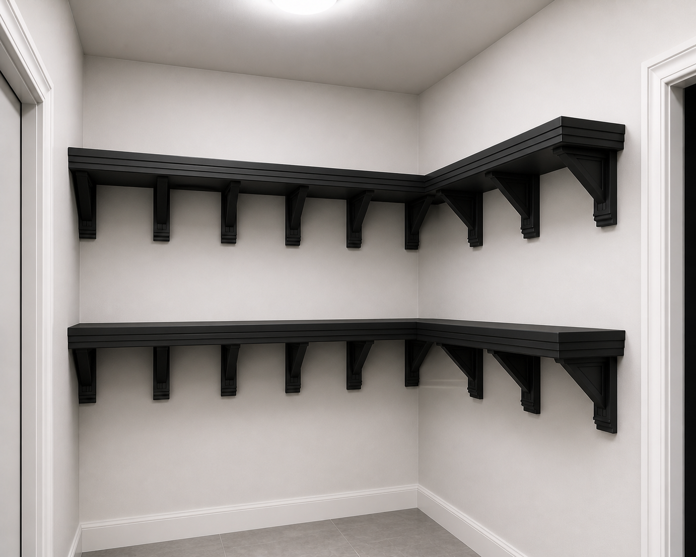
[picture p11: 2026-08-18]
development/simplified_shelf_concepts/artist_renderings/02_black_art_deco_petg.png

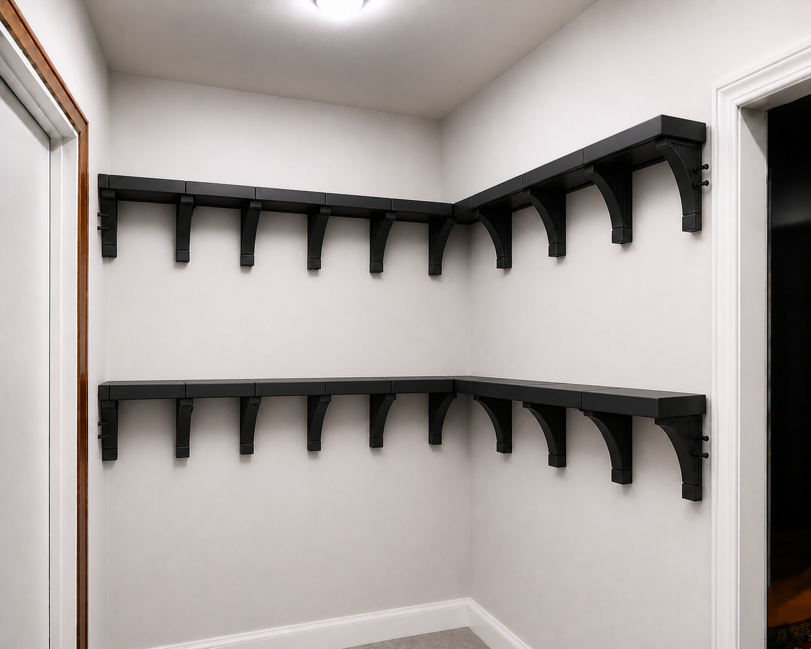
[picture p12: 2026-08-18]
development/simplified_shelf_concepts/artist_renderings/15_black_practical_snap_trim_petg.png

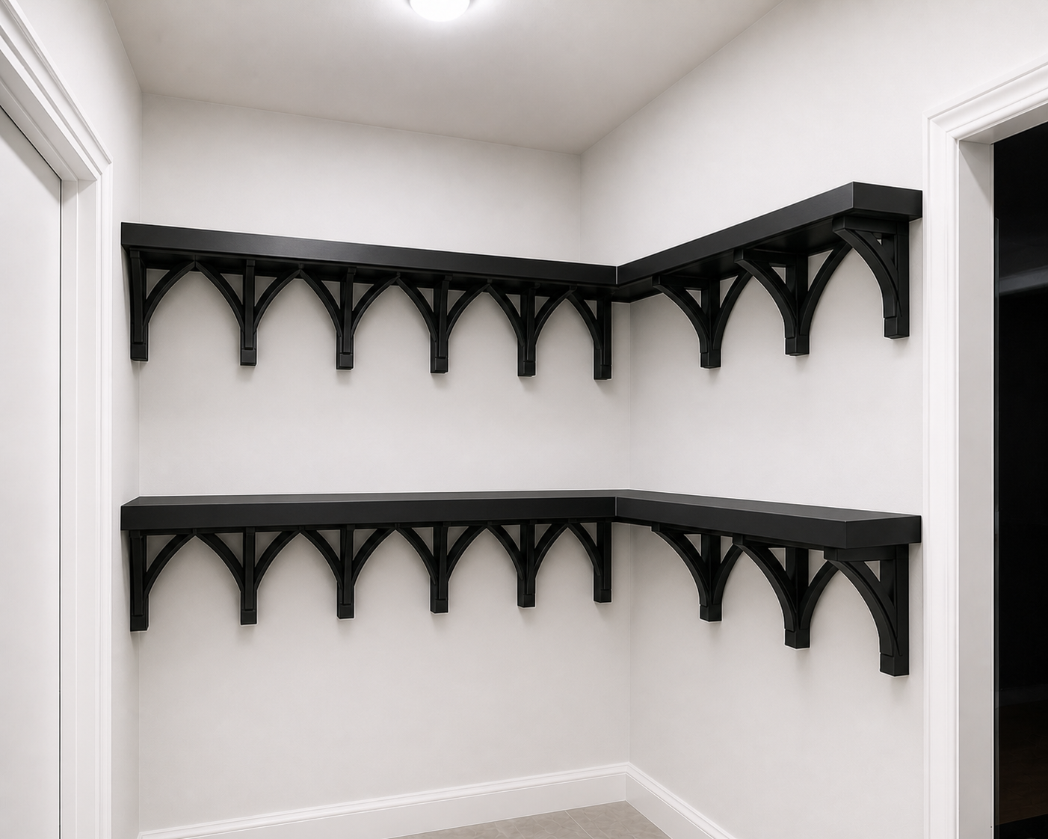
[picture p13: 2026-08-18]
development/simplified_shelf_concepts/artist_renderings/03_black_restrained_gothic_petg.png

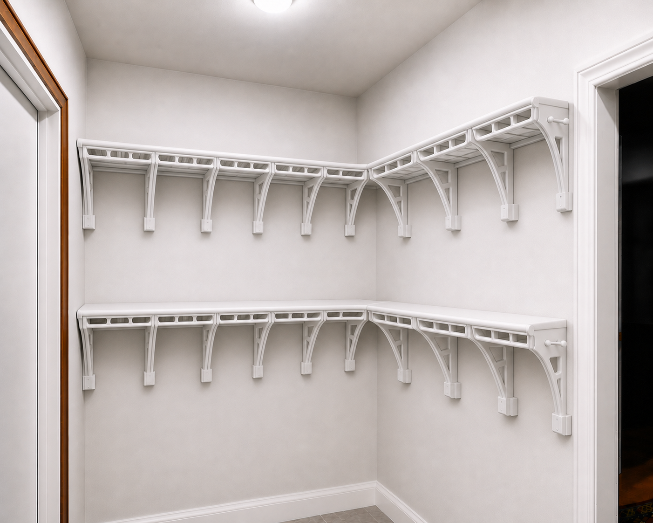
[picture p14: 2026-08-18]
development/simplified_shelf_concepts/artist_renderings/14_white_aerofoil_truss_petg.png

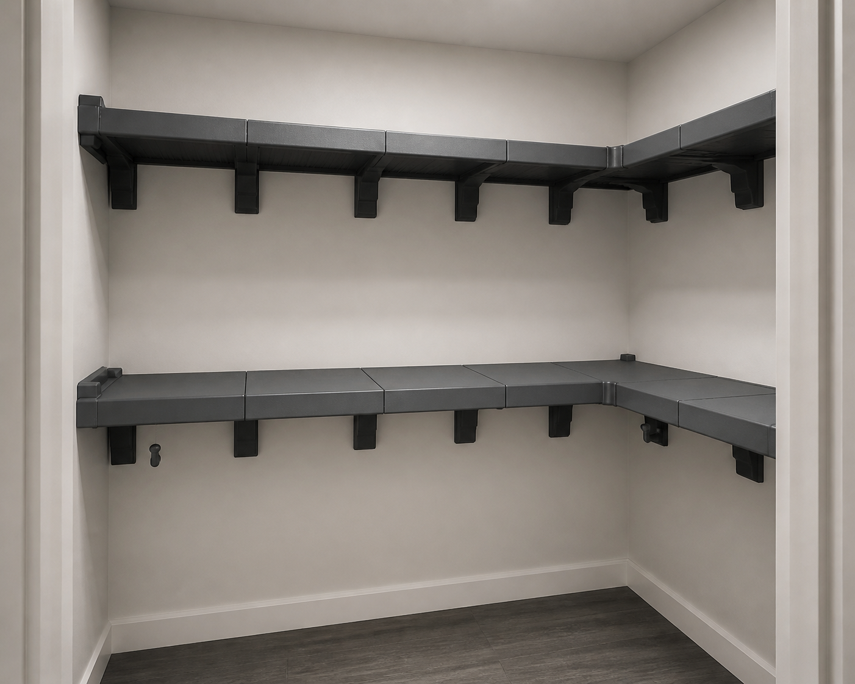
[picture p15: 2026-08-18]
development/simplified_shelf_concepts/artist_renderings/07_charcoal_japanese_minimal_petg.png

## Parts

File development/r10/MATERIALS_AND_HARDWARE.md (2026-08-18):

# R10 materials, printed parts, and wall-hardware candidates

> **Procurement and installation hold. Rated load: 0 kg / 0 lb.** The exact
> printed architecture is documented so prototypes can be planned, but no wall
> hardware candidate purchase is released until the blocking/substrate stack
> and fixture plan are reviewed. No closet installation is released until all
> fixture tests and independent review are complete.

## Material contract

| Item | Exact candidate | Rule |
|---|---|---|
| Structural filament | SUNLU standard black PETG, 1.75 mm, ASIN `B0D1KC72YP` | Record label, lot, drying cycle, and spool changes |
| Printer | Bambu Lab A1 mini, physical 0.4 mm nozzle | Textured PEI plate; authored orientation only |
| Filament profile | `SUNLU PETG @BBL A1M 0.4 nozzle` | No silent generic-PETG substitution |
| Process profile | `0.20mm Strength @BBL A1M` | 6 walls, 25% grid, 5 top / 3 bottom layers, Support Off |
| Adhesive | None in the base architecture | Joints remain dry, inspectable, and replaceable |

PLA, PETG from an unrecorded spool, printed wall anchors, drywall screws, deck
screws, hidden metal beams, aluminum tubes, and metal bearing straps are not
approved substitutions. Metal in the active shelf design is limited to the
candidate wall screws and one washer per screw.

## Exact printed architecture count

| Printed article | First 61.25 in wall | Function and credit |
|---|---:|---|
| Palatine PETG support, 31.75 mm across the run | 7 | Primary support; three printed candidate wall bores each |
| Regular cassette half, 126.65 mm printed / 127 mm nominal | 10 | Five paired interior positions across six bays |
| Terminal cassette half, 142.35 mm printed / 142.875 mm nominal | 2 | Includes endpoint and half-seam clearance |
| PETG splice log, 159.1 x 20 x 24 mm | 18 | Three per bay; 79.375 mm engagement per half |
| Independent log retainer, 12 x 28 x 6 mm body; 12.4 x 28 x 10.8 mm saved envelope with integrated cap | 18 | Three per bay, one per log; flush closure and retention only, zero sustained-load credit |
| Bay-local support retainer, 8 x 136 x 6 mm | 12 | 3.8 mm shaft, 8 mm rear dog, 12 mm front handle, 2.4 mm bayonet shift, 4.0 mm proud hand grip; gravity land above stays continuous |
| Additive Roman/Art-Deco ornament | Integrated | Appearance only; zero independent structural credit |

The first wall therefore contains 37 primary bearing pieces plus 30
retention-only keys: 67 printed structural-assembly articles. The active outer bookend
also requires two flush blanks and one comb/hook, for 70 first-wall printed
articles before sacrificial coupons, spares, or destructive-test duplicates.
All 30 keys are retention-only; none receives gravity or bending credit.

Each cassette half has a 152.4 mm depth, 32.0 mm total height, 4.0 mm top
skin, 3.2 mm bottom skin, and at least 4.0 mm rear/center/front load webs. Each
splice log engages 79.375 mm into each half through a captured dovetail channel
with 0.4 mm clearance per face and a positive body shoulder.

Every midpoint and interior support line retains a centered 0.35 mm physical
seam. Each wall endpoint retains 0.35 mm clearance. The fascia is visually
continuous but physically bay-segmented; zero-gap assembly is forbidden.

The top-open midpoint notch is included in the final-mesh geometry proxy. Per
log, net area is 334.800 mm², net centroidal second moment is 8263.957 mm⁴,
and net governing elastic section modulus is 949.016 mm³—72.16%, 36.85%, and
51.35% of their respective gross values. These values describe shape only;
they do not supply a PETG allowable or capacity.

Shallow support locators, the 12 support retainers, decorative covers, and the
18 one-log retainers prevent nuisance movement only. Do not include them when
claiming a vertical load path.

Intermediate supports use a compact 76.2 mm visible corbel drop over the full
hidden 158.75 mm structural wall strap. The first-wall far-left outer bookend
may use a 120.65 mm visible emphasis. The through-side terminal is a replaceable
corner placeholder, not a final measured corner or an outer cable bookend.

## Cable bookend parts—required, not structural

The eventual L-shaped shelf level has exactly two outer cable bookends: the
far-left endpoint of this wall and the far-right endpoint of the later return
wall. The first-wall release activates only the far-left bookend.

| Printed cable article | First-wall prototype | Eventual full L per level |
|---|---:|---:|
| Outer bookend with one fused two-socket receiver | 1 | 2 |
| Inward-facing keyed socket | 2 integrated | 4 integrated |
| Flush blank | 2 | 4 |
| Multi-cable comb/hook module | 1 | 2 |

The keyed gravity fit is 0.4 mm clearance per face with 8 mm service lift/drop.
Unused sockets receive flush blanks. No cable rail, peg, receiver, or module is
allowed on an intermediate support, the through-side terminal/corner
placeholder, or at the inside corner. All cable hardware receives zero
shelf-load credit.

## Candidate wall fasteners and washers

| Item | Exact dimensional candidate | First-wall quantity |
|---|---|---:|
| Wall fastener | GRK RSS Rugged Structural Screw, Climatek, 1/4 in x 3-1/2 in, T25, part `90306` | 21 in any one full-wall assembly; controlled-lot plan below |
| Washer | L.H. Dottie `FW14`, 1/4 in USS flat washer, unhardened carbon steel, zinc plated, ASME B18.21.1; 7.7978-8.3058 mm ID, 18.4658-19.0246 mm OD, 1.2954-2.032 mm thick | Exactly one per screw; standard pack 100; controlled-lot plan below |
| Wall structure | Verified continuous solid-wood blocking or independently engineered equivalent across every screw axis | Field verified; not inferred |

One complete first-wall fixture uses 21 installed candidates of each hardware
type: three screws and three washers at each of seven supports.

There are three authored 7.0 mm candidate bores per support at 19.05 / 79.375 /
139.7 mm below the shelf underside. Each bore is surrounded by a full-solid
27.025 mm outer-diameter surface-bearing washer land. Counterbores are
forbidden. The bores are printed into the model; do not freehand drill or ream
PETG. These are prototype-fixture coordinates, not a drilling schedule or
authorization to drill the closet wall.

Use exactly one listed washer beneath each screw head. Do not stack washers,
countersink PETG, substitute a smaller washer, or crush the printed wall strap
to make a screw appear seated. Final screw suitability depends on actual wood
species/specific gravity, sound blocking thickness, embedment after every
intervening layer, edge/end distances, screw-group spacing, substrate
thickness, installation torque, and the complete shelf load case.

Generic hollow-wall or drywall anchors receive no primary structural credit.
If continuous blocking or an independently engineered equivalent does not
exist at every required screw axis, wall installation stays blocked.

The cited GRK/ICC evaluation does not cover this connection: the screw head
would bear on a loose washer over PETG rather than directly on the evaluated
wood or steel side member. The loose washer, PETG bearing land, effective
penetration, and complete screw group require their own reviewed fixture
program. This complete loose-washer/PETG stack is outside ESR-2442. GRK's
current customer drawing and current ESR also disagree about
the thread length for this nominal screw. Measure and record every controlling
dimension from the received `90306` lot and resolve the discrepancy with GRK
or the independent reviewer before a fixture calculation.

## Controlled-lot hardware allocation

The previous quantity of 30 screws and washers was insufficient. After the
field wall stack is known and a reviewer accepts the fixture plan, procure
**100 exact GRK 90306 screws and one standard 100-pack of Dottie FW14 washers**
as controlled candidate lots. Quarantine them and release only this allocation:

| Reserved use | Fresh screws | Fresh FW14 washers |
|---|---:|---:|
| Gate 5: four sacrificial three-fastener support groups | 12 | 12 |
| Gates 6 and 7: one complete mock wall and its recovered proof cases | 21 | 21 |
| Gate 8: separate fresh creep wall | 21 | 21 |
| Gate 9: separate fresh destructive wall | 21 | 21 |
| Eventual closet installation, only after full release | 21 | 21 |
| Initial unallocated spares | 4 | 4 |
| **Total controlled-lot purchase** | **100** | **100** |

Any damaged item, retry, or reviewer requirement for a fresh Gate 7 consumes
the four spares and requires replenishing the exact candidate before the
21-piece final-install reserve is touched. Passing tests never authorizes
reusing fixture screws or washers in the closet.

## Prototype quantities by gate

To fail fast, do not print the complete wall set first.

1. **Midpoint-interface gate:** one actual left cassette half, one actual right
   cassette half, one actual splice log, and its actual flush-capped retainer.
2. **One-bay gate:** reuse the passing midpoint articles, then add the remaining
   two splice logs, two log retainers, two bay-local support retainers, and two
   supports. These are actual-geometry structural articles; retain them only if
   every dimensional and cycling gate passes.
3. **Cable gate:** one far-left two-socket bookend, two blanks, and one
   comb/hook module.
4. **Tabletop wall gate:** reuse the two conforming compact supports from Gate
   2 and the conforming far-left bookend from Gate 3; then print the remaining
   **four supports** (three compact plus the terminal/corner placeholder), two
   terminal halves, eight regular halves, fifteen splice logs, fifteen one-log
   retainers, and the remaining ten bay-local support retainers. Replace any
   earlier article that was intentionally damaged in testing; a replacement
   does not increase the installed seven-support count.
5. **Wall-fixture and destructive gates:** print fresh conforming sets from the
   same recorded process; never treat a fatigued fit article as a qualification
   article.

The minimum full-size printed demand through a possible released installation
is therefore 284 articles before reviewer-defined material coupons, failed
prints, retests, destructive duplicates, or spares: the initial 70-article
tabletop set, four Gate-5 support fixtures, and three fresh 70-article walls for
Gates 6, 8, and 9. Do not print this inventory in advance; each gate exists to
avoid spending the next tranche after a failure.

Final filament mass, print time, and spool count must come from the released
100%-scale sliced set. Estimates are planning inputs only.

## Tools and records

- digital calipers, steel rule, verified square, straightedge, and feeler
  gauges;
- PETG drying equipment and a temperature/humidity logger;
- T25 driver plus a controlled seating method that cannot crush PETG;
- stud/blocking mapper followed by borescope or open-wall confirmation;
- substrate material and thickness measurement;
- freestanding framed-wall test fixture with the exact blocking and substrate;
- calibrated masses or sealed weighed containers, restraint/barricade, and
  remote observation;
- indicators or fixed rulers at **19 measurement stations**: rear and front at
  all six bay midpoints plus all seven supports; and
- serialized photos, part IDs, slice records, dimensions, load history, and
  failure observations.

## Procurement hard stops

Do not buy qualification hardware until the field wall stack and reviewed
fixture plan exist. Do not release the separate 21-piece closet-install
reserve until all of the following are documented:

1. continuous blocking or an independently engineered equivalent exists at
   every candidate screw axis;
2. the actual substrate material and thickness are known;
3. candidate screw embedment, blocking properties, edge/end distances, group
   spacing, and installation method are accepted for the complete connection;
4. exact PETG lot/process coupons, one bay, and a full tabletop set pass;
5. a fresh framed-wall mockup passes proof, sustained-creep, recovery, and
   destructive gates; and
6. an independent structural reviewer accepts the installed system and defines
   any allowable load.

## Primary product references and their limits

- [GRK RSS product page](https://www.grkfasteners.com/grk-products/structural-framing-screws/rss-rugged-structural-screw)
  identifies the 1/4 in x 3-1/2 in T25 single screw as part `90306` and describes
  its integrated washer head.
- [ICC-ES ESR-2442](https://icc-es.org/wp-content/uploads/report-directory/ESR-2442.pdf)
  evaluates the fastener in identified wood-member connections. It does **not**
  qualify a PETG side member, PETG washer-bearing land, an added loose washer,
  this screw group, or this shelf.
- [L.H. Dottie FW14 product page](https://lhdottie.com/flat-washers/fw14) and
  [manufacturer specification](https://lhdottie.com/pdf/product-specification-sheet/FW14)
  define the selected dimensional washer candidate and its standard 100-pack.
  They do not rate the loose washer over PETG as part of a GRK connection.
- [SUNLU standard PETG product data](https://store.sunlu.com/products/over-6kg-bundle-sale-petg-3d-printer-filament-1-75mm-1kg-roll)
  supplies manufacturer-typical material and process information. Typical
  molded or printed values are not long-term design allowables for this lot,
  orientation, geometry, temperature, or wall connection.

The received screw, washer, filament label, and wood/blocking record control
the fixture. If any physical item differs from this contract, stop and issue a
versioned revision rather than silently substituting it.

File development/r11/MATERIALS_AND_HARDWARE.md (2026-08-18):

# R11 materials, printed articles, and hardware candidates

> **Procurement and installation hold. Rated load: 0 kg / 0 lb.** This is a
> candidate bill of materials for design and qualification planning. Do not buy
> wall hardware, drill the closet wall, install a support, or place load based
> on this list. The field wall stack and independent fixture plan must be
> reviewed first. R11 v1 still hard-forces print, drilling-coordinate release,
> installation, and test-load authorization to false after that review.

## Exact printer and material baseline

| Item | Exact candidate | Required record / rule |
|---|---|---|
| Structural filament | SUNLU standard black PETG, 1.75 mm, ASIN `B0D1KC72YP` | Photograph received label; record lot, drying cycle, ambient conditions, spool changes, and remaining mass |
| Printer | Bambu Lab A1 mini | Record machine, firmware, plate, and physical nozzle |
| Nozzle | Physical 0.4 mm standard-flow nozzle | Do not substitute 0.2, 0.6, 0.8, or hardened/high-flow behavior without a new process qualification |
| Plate | Textured PEI | Clean, empty, cool, correctly seated, and selected in the slicer before every job |
| Filament profile | `SUNLU PETG @BBL A1M 0.4 nozzle` | Map project filament to the physically loaded external PETG; do not silently use Generic PETG |
| Process profile | `0.20mm Strength @BBL A1M` | 0.20 mm layers, 6 walls, 25% grid, 5 top / 3 bottom, Support Off |
| Bed adhesion | 5 mm outer brim, 0.1 mm brim-object gap | Inspect complete brim in Preview; remove only after cooling |
| Adhesive / lubricant | None | Base joinery remains dry, inspectable, reversible, and replaceable |

PLA, an unrecorded PETG spool, resin, wood-filled filament, printed wall
anchors, drywall screws, deck screws, hidden metal beams, aluminum tubes, steel
bearing straps, glue, solvent welding, and friction-only retainers are not
approved substitutions.

Final filament mass, print time, and spool quantity are **unknown until the R11
generator is integrated and every 100%-scale saved model is sliced with the
contract above**. Do not use an R10 slicer estimate or the earlier 5.6 kg
planning estimate as an R11 purchase quantity.

## First-wall kit and installed-state targets

The 28-article count is the reduced-part **supplied-kit design target**, not a
generated inventory claim. The future manifest must enumerate every handed
identity and prove the count. S0 has only two sockets, so only two of the three
supplied cable modules can be installed at once.

| Printed family | Candidate first-wall quantity | Function / credit |
|---|---:|---|
| S0 far-left support/bookend with fused inward two-socket receiver | 1 | Structural support; receiver is additive and nonstructural |
| Ordinary or terminal supports S1-S6 | 6 | Structural supports; S6 remains a first-wall terminal/corner placeholder, not a final inside corner |
| Authored three-rib half-decks | 12 | Bay 0 and bay 5 each use terminal left/right halves: four terminal halves at 162.175 mm; bays 1-4 use eight regular halves at 154.325 mm; never create identities by casual mirroring |
| Positive Palatine/Art-Deco bay keystones | 6 | One per bay; blocks half-to-half X separation only; zero support-capture and sustained vertical-load credit |
| Flush cable blanks | 2 | One normal installed state blanks both S0 sockets; zero shelf-load credit |
| Multi-cable comb/hook | 1 | Alternate module for one S0 socket; representative cables only |
| **Supplied-kit target** | **28** | Qualification duplicates, failures, spares, and test articles excluded |
| **Maximum simultaneously installed** | **27** | 25 structural/retention articles plus exactly 2 of the 3 cable modules |

The two permitted normal module states are two blanks, or one blank plus one
comb/hook. The unused third module is stored off the shelf. It is never placed
in a nonexistent third socket or counted as simultaneously installed.

R11 integrates the three shelf ribs and cross-laps into the 12 half-decks. It
therefore has no separate R10 splice logs, no one-log retainers, and no
support-retainer bars. If physical testing shows an additional printed
structural or retention article is necessary, revise the architecture, count,
start plan, documentation, and qualification program together.

## Safe and target production-start plans

| Plate family | Safe unbatched starts | Target batched starts | Plate population rule |
|---|---:|---:|---|
| Supports | 7 | 7 | One support per plate in authored orientation |
| Half-decks | 12 | 12 | One half-deck per plate in authored flat high-load orientation |
| Keystones | 6 | 1 | Batch all six only after collision-free packing and first-layer separation are proven |
| Cable modules | 3 | 1 | Batch two blanks plus one comb/hook only after packing is proven |
| **Total** | **28** | **21** | Qualification and retries add starts |

Do not batch structural supports or half-decks merely to reduce starts. The
six-keystone and three-module plates remain targets until the generated saved
orientations, brims, and Bambu Preview prove them. Until then, use 28 as the
safe one-article-per-start plan. Batch nesting changes starts only; it does not
alter kit quantity, the 27-installed limit, manifest identities, BOM, or any
qualification article or gate.

## Exact first-wall fastener candidates

| Item | Exact candidate | Installed first-wall quantity if eventually released |
|---|---|---:|
| Wall screw | GRK RSS Rugged Structural Screw, Climatek, 1/4 in x 3-1/2 in, T25, part `90306` | 21 |
| Washer | L.H. Dottie `FW14`, 1/4 in USS flat washer, unhardened zinc-plated carbon steel, ASME B18.21.1; 7.7978-8.3058 mm ID, 18.4658-19.0246 mm OD, 1.2954-2.032 mm thick | Exactly 21; one per screw |
| Wall structure | Verified continuous solid-wood blocking or independently engineered equivalent at every screw axis | Field verified, never inferred |

Each of seven supports has three authored 7.0 mm candidate bores at 19.05,
79.375, and 139.7 mm below the shelf underside. Every bore is surrounded by a
full-solid 27.025 mm outer-diameter surface-bearing land. These are fixture
candidates, not a drilling schedule.

Use one listed washer immediately beneath each screw head. Do not stack
washers, countersink or counterbore PETG, substitute a smaller washer, ream a
printed bore, or crush a strap to make the head appear seated.

Generic drywall/hollow-wall anchors receive no primary structural credit. If
continuous blocking or an independently engineered equivalent is not verified
at all 21 first-wall axes, installation remains blocked. The loose FW14 washer
over PETG connection is outside ESR-2442; catalog screw capacity is not shelf
capacity. Current GRK documents also conflict on thread length, so the received
90306 lot must be measured before any connection calculation.

## Controlled-lot qualification plan

Only after the field wall stack and fixture protocol are independently
reviewed, procure 100 exact GRK 90306 screws and one 100-pack of exact FW14
washers as controlled candidate lots:

| Reserved use | Fresh screws | Fresh FW14 washers |
|---|---:|---:|
| Four sacrificial three-fastener support fixtures | 12 | 12 |
| Complete mock-wall service/proof program | 21 | 21 |
| Separate fresh 1000-hour creep wall | 21 | 21 |
| Separate fresh destructive wall | 21 | 21 |
| Quarantined possible final installation, only after release | 21 | 21 |
| Unallocated spares | 4 | 4 |
| **Total** | **100** | **100** |

Fixture hardware is never reused in the closet. A failed or damaged item uses
the four spares and, if necessary, requires replenishing the exact lot before
the 21-piece final-install reserve is touched.

## Novice tools and records checklist

For neutral generation, printing, and unloaded tabletop fit work only:

- computer with the pinned R11 source revision and Bambu Studio;
- Bambu Lab A1 mini with the physical 0.4 mm nozzle and Textured PEI plate;
- exact, dried, recorded SUNLU PETG above;
- filament scale or recorded spool weights;
- digital calipers, steel rule, verified square, straightedge, and feeler
  gauges;
- soft brush and deburring tool used **only on the sacrificial brim**, never on
  a structural fit;
- clean padded flat table, labels, permanent record sheet, and camera; and
- part IDs, source hash, generated manifest, saved-mesh hash, slice time/mass,
  Preview screenshots, spool/process record, dimensions, and defect photos.

For later reviewed fixtures—not the real wall:

- purpose-built freestanding framed-wall mockup reproducing verified blocking,
  substrate, trim stand-off, and accepted screw installation;
- T25 driver plus a controlled seating method that prevents PETG crushing;
- borescope/open-wall evidence and blocking/substrate measurement tools;
- calibrated masses or sealed weighed containers, restraints, barricades, and
  remote observation;
- temperature/humidity logger and controlled elevated-temperature enclosure;
- displacement indicators or fixed rulers at the 19 specified stations; and
- reviewer-approved measurement, stop, recovery, and destructive-test plans.

## Procurement hard stops

Do not procure qualification hardware until wall structure and the complete
fixture plan are reviewed. Do not release the possible final-install reserve
until every gate in [LOAD_QUALIFICATION.md](LOAD_QUALIFICATION.md) passes and an
independent structural reviewer issues written installation conditions and an
allowable load. Until then: **0 kg / 0 lb, no drilling, no installation**.
R11 v1 additionally holds `print_authorized`,
`drilling_coordinates_released`, `wall_installation_authorized`, and
`test_load_authorized` false in every output; procurement or review does not
change that version boundary.

## Candidate source references and limits

- [GRK RSS product page](https://www.grkfasteners.com/grk-products/structural-framing-screws/rss-rugged-structural-screw)
  identifies the nominal candidate. It does not rate this shelf or PETG stack.
- [ICC-ES ESR-2442](https://icc-es.org/wp-content/uploads/report-directory/ESR-2442.pdf)
  covers identified fastener/wood connections, not the loose-washer/PETG side
  member used here.
- [L.H. Dottie FW14 product page](https://lhdottie.com/flat-washers/fw14) and
  [manufacturer specification](https://lhdottie.com/pdf/product-specification-sheet/FW14)
  define the washer candidate, not its capacity over PETG.
- [SUNLU PETG product data](https://store.sunlu.com/products/over-6kg-bundle-sale-petg-3d-printer-filament-1-75mm-1kg-roll)
  provides typical material information, not a long-term allowable for this
  lot, process, orientation, temperature, or geometry.

Physical received items and reviewer-approved records control. Any difference
requires a versioned revision, not a silent substitution.

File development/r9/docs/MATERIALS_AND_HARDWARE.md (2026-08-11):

# R9 first-shelf materials and hardware schedule

## Read this status first

This schedule is for the **first lower shelf only**: the 61.25 in long wall at
the 68 in shelf-top elevation. The design candidate uses six evenly spaced
supports at approximately 12 in pitch and three wall fasteners per support.

The exact screw and washer below are the selected **engineering candidates**.
Their dimensions fit the corrected R9 prototype-v3 holes. They are not yet an
installation release because the framing/blocking map, drywall thickness,
PETG-to-washer clamp test, and proof/load tests are not complete.

Do not substitute a deck screw, drywall screw, printed anchor, or unnamed wall
anchor. Do not drill the wall from a support-center drawing. The present load
rating remains **0 kg / 0 lb**.

## Simple shopping status

### Already selected and safe to have now

| Item | Exact specification | Quantity |
|---|---|---:|
| Filament | SUNLU standard black PETG, ASIN `B0D1KC72YP`, 1.75 mm, four 1 kg spools | 1 purchased 4 kg bundle |
| Printer | Bambu Lab A1 mini with installed 0.4 mm nozzle | 1 |
| Build plate | Bambu Textured PEI Plate for A1 mini | 1 |
| Cleaning supplies | Unscented dish soap, clean water, lint-free towel | 1 set |
| Measuring tools | 6 in / 150 mm digital caliper, 24 in level, tape measure, pencil, painter's tape | 1 each |
| Framing scan tool | Stud finder with live-wire/AC warning capability | 1 |

The 4 kg filament bundle is enough to continue qualification and prototype
work. A production-filament quantity will be published only after the complete
first-shelf meshes exist and their serialized mass has been calculated. Do not
assume every remaining spool is available for retries.

### Selected fastener fixture set—buy only for verification and fixture tests

| Item | Exact specification | Installed | Buy |
|---|---|---:|---:|
| Structural screw | GRK RSS Rugged Structural Screw, Climatek, **1/4 in x 3-1/2 in**, T25, part **90306** | 18 | 24 |
| Flat washer | 1/4 in USS Type A low-carbon steel flat washer, ASME B18.21.1; 0.312 in basic ID, 0.734 in basic OD, 0.051–0.080 in thick | 18 | 24 |
| Driver bit | Impact-rated T25 star-drive bit | 1 | 2 |
| Wood pilot bit | **7/64 in / 2.778 mm** sharp brad-point or twist bit | 1 | 2 |

The six spare screws and washers provide one complete spare support set plus
three additional replacements. A stripped, dropped, bent, corroded, or
overdriven fastener is discarded; it is never counted as installed hardware.

Do not stack extra washers. Do not countersink PETG. Do not use an impact
driver to establish final clamp force. The last seating step must be slow and
controlled, and the washer must remain flat without visibly crushing,
crazing, whitening, or bowing the PETG strap.

## Why the count is 18 screws

The measured first wall has this candidate structure:

- 1 far-left Palatine Moderne bookend support;
- 4 compact Palatine Moderne intermediate supports;
- 1 concealed corner-end support;
- 6 total supports x 3 screws each = **18 installed screws**; and
- 6 total supports x 3 washers each = **18 installed washers**.

The support centers are equally pitched so the geometry is regular and the
shelf spans are similar. Equal spacing does **not** prove equal load sharing;
the final proof plan must still test distributed load, point load, creep, and
recovery.

## Geometry compatibility already checked

The corrected v3 support uses three printed 7.0 mm round-envelope diamond
holes at 16, 80, and 144 mm below the shelf underside. Adjacent centers are
64.0 mm apart.

For the selected GRK 1/4 in RSS screw:

- published outside thread diameter `D` = 0.236 in / 5.994 mm;
- conservative predrilled parallel-grain spacing = `10D` = 59.944 mm;
- modeled spacing = 64.0 mm, leaving 4.056 mm geometric margin;
- published shoulder diameter = 0.244 in / 6.198 mm;
- modeled round clearance envelope = 7.0 mm;
- published head diameter = 0.533 in / 13.538 mm; and
- maximum washer OD including the cited +0.015 in tolerance is 0.749 in /
  19.025 mm, inside the modeled 20.0 mm flat washer land.

The 7/64 in pilot is a candidate for verified SPF/Douglas-fir-like sawn wood.
It falls inside the overlapping predrill ranges derived from the GRK report.
The pilot applies to wood only; the PETG hole is printed and must not be
drilled, reamed, filed, or enlarged.

With a 16.0 mm PETG strap, the maximum 2.032 mm washer thickness, and 5/8 in
drywall, the 3-1/2 in screw leaves approximately **54.99 mm / 2.17 in** of
length beyond the visible stack. That is only stack arithmetic. Actual thread
embedment must be measured from the real assembly and reviewed before use.

## Framing/blocking requirement—the current installation blocker

Six supports at approximately 12 in centers will not ordinarily align with a
typical 16 in stud layout. Therefore the primary design requires **continuous
solid wood blocking or a separately engineered equivalent behind every one of
the 18 screw axes**.

Before wall installation can be released, record all of the following:

- wall substrate material and exact thickness;
- every stud/blocking edge and center at the 68 in shelf level;
- continuous blocking species, grade, thickness, height, moisture condition,
  installation method, and reviewer;
- electrical cable, plumbing, and other concealed-service checks;
- actual screw embedment and edge/end distances;
- driver access and washer seating on a printed support; and
- framed-wall fixture, proof, creep, recovery, and destructive-test results.

If continuous blocking is absent, stop. The alternatives are to open the wall
and add blocking or to commission a separately engineered mounting-rail or
anchor schedule. A generic hollow-wall anchor is not an automatic substitute,
and buying a high advertised load rating does not qualify a grouped,
cantilevered shelf connection.

## Printed-part purchasing/printing boundary

The current `one_bay_prototype_v3` package contains five full-scale tabletop
articles: two handed supports, rear ledger, front beam, and one 160 mm shelf
cassette. Print them only in the documented staged order and only after the
software reports time/material and the operator explicitly approves that job.

The complete 61.25 in shelf set is not emitted yet. Its final part count,
segmentation, PETG mass, print hours, and spare-part count remain pending the
one-bay fit result and the framing decision. Do not multiply the one-bay files
and call the result an installed shelf.

## Authoritative fastener references

- [GRK RSS product page and part 90306](https://www.grkfasteners.com/grk-products/structural-framing-screws/rss-rugged-structural-screw)
- [GRK RSS technical drawing](https://www.grkfasteners.com/getattachment/e22b7f36-824a-482b-9181-06a3b5e0bbbc/GRK-RSS-Customer-Drawing.pdf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)
- [ICC-ES ESR-2442](https://www.grkfasteners.com/getmedia/5f4f72a8-8d1f-479b-8ae0-5fc043e2943d/ESR-2442.pdf?ext=.pdf)
- [Fastenal 1/4 in USS Type A washer dimensions](https://www.fastenal.com/content/product_specifications/FW.LC.USS.A.HDG.00.pdf)

Manufacturer literature does not evaluate this complete PETG-through-drywall
connection. The project must retain the physical hardware fixture and final
review gates even when every individual component matches its published data.

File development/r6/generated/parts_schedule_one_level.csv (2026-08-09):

logical_id | family | variant | level | run | quantity | classification | print_orientation_note | zero_structural_credit | zero_credit_scope | provisional_status | position_local_mm | interface_ref | level_independent
lower::long_wall_5ft::arcade_half::01 | arcade_half | through_left_half | lower | long_wall_5ft | 1 | structural | broad arcade elevation face on the build plate | False |  | PROVISIONAL_EXPERIMENTAL_UNRATED | 31.4325 | lower::long_wall_5ft::deck_cassette::01 | True
lower::long_wall_5ft::arcade_half::02 | arcade_half | through_right_half | lower | long_wall_5ft | 1 | structural | broad arcade elevation face on the build plate | False |  | PROVISIONAL_EXPERIMENTAL_UNRATED | 273.3675 | lower::long_wall_5ft::deck_cassette::02 | True
lower::long_wall_5ft::arcade_half::03 | arcade_half | through_left_half | lower | long_wall_5ft | 1 | structural | broad arcade elevation face on the build plate | False |  | PROVISIONAL_EXPERIMENTAL_UNRATED | 273.3675 | lower::long_wall_5ft::deck_cassette::03 | True
lower::long_wall_5ft::arcade_half::04 | arcade_half | through_right_half | lower | long_wall_5ft | 1 | structural | broad arcade elevation face on the build plate | False |  | PROVISIONAL_EXPERIMENTAL_UNRATED | 515.3025 | lower::long_wall_5ft::deck_cassette::04 | True
lower::long_wall_5ft::arcade_half::05 | arcade_half | through_left_half | lower | long_wall_5ft | 1 | structural | broad arcade elevation face on the build plate | False |  | PROVISIONAL_EXPERIMENTAL_UNRATED | 515.3025 | lower::long_wall_5ft::deck_cassette::05 | True
lower::long_wall_5ft::arcade_half::06 | arcade_half | through_right_half | lower | long_wall_5ft | 1 | structural | broad arcade elevation face on the build plate | False |  | PROVISIONAL_EXPERIMENTAL_UNRATED | 757.2375 | lower::long_wall_5ft::deck_cassette::06 | True
lower::long_wall_5ft::arcade_half::07 | arcade_half | through_left_half | lower | long_wall_5ft | 1 | structural | broad arcade elevation face on the build plate | False |  | PROVISIONAL_EXPERIMENTAL_UNRATED | 757.2375 | lower::long_wall_5ft::deck_cassette::07 | True
lower::long_wall_5ft::arcade_half::08 | arcade_half | through_right_half | lower | long_wall_5ft | 1 | structural | broad arcade elevation face on the build plate | False |  | PROVISIONAL_EXPERIMENTAL_UNRATED | 999.1725 | lower::long_wall_5ft::deck_cassette::08 | True
lower::long_wall_5ft::arcade_half::09 | arcade_half | through_left_half | lower | long_wall_5ft | 1 | structural | broad arcade elevation face on the build plate | False |  | PROVISIONAL_EXPERIMENTAL_UNRATED | 999.1725 | lower::long_wall_5ft::deck_cassette::09 | True
lower::long_wall_5ft::arcade_half::10 | arcade_half | through_right_half | lower | long_wall_5ft | 1 | structural | broad arcade elevation face on the build plate | False |  | PROVISIONAL_EXPERIMENTAL_UNRATED | 1241.1075 | lower::long_wall_5ft::deck_cassette::10 | True
lower::long_wall_5ft::arcade_half::11 | arcade_half | through_left_half | lower | long_wall_5ft | 1 | structural | broad arcade elevation face on the build plate | False |  | PROVISIONAL_EXPERIMENTAL_UNRATED | 1241.1075 | lower::long_wall_5ft::deck_cassette::11 | True
lower::long_wall_5ft::arcade_half::12 | arcade_half | through_right_half | lower | long_wall_5ft | 1 | structural | broad arcade elevation face on the build plate | False |  | PROVISIONAL_EXPERIMENTAL_UNRATED | 1483.0425 | lower::long_wall_5ft::deck_cassette::12 | True
lower::long_wall_5ft::cassette_lock::support_01_left_slot | cassette_lock | through_start_left_slot | lower | long_wall_5ft | 1 | retention | largest flat lock face on the build plate | True | cassette-to-integral-cap retention only; no independent load rating | PROVISIONAL_EXPERIMENTAL_UNRATED | 31.4325 | lower::long_wall_5ft::structural_pier_x_corbel::01 | True
lower::long_wall_5ft::cassette_lock::support_01_right_slot | cassette_lock | through_start_right_slot | lower | long_wall_5ft | 1 | retention | largest flat lock face on the build plate | True | cassette-to-integral-cap retention only; no independent load rating | PROVISIONAL_EXPERIMENTAL_UNRATED | 31.4325 | lower::long_wall_5ft::structural_pier_x_corbel::01 | True
lower::long_wall_5ft::cassette_lock::support_02_left_slot | cassette_lock | through_interior_left_slot | lower | long_wall_5ft | 1 | retention | largest flat lock face on the build plate | True | cassette-to-integral-cap retention only; no independent load rating | PROVISIONAL_EXPERIMENTAL_UNRATED | 273.3675 | lower::long_wall_5ft::structural_pier_x_corbel::02 | True
lower::long_wall_5ft::cassette_lock::support_02_right_slot | cassette_lock | through_interior_right_slot | lower | long_wall_5ft | 1 | retention | largest flat lock face on the build plate | True | cassette-to-integral-cap retention only; no independent load rating | PROVISIONAL_EXPERIMENTAL_UNRATED | 273.3675 | lower::long_wall_5ft::structural_pier_x_corbel::02 | True
lower::long_wall_5ft::cassette_lock::support_03_left_slot | cassette_lock | through_interior_left_slot | lower | long_wall_5ft | 1 | retention | largest flat lock face on the build plate | True | cassette-to-integral-cap retention only; no independent load rating | PROVISIONAL_EXPERIMENTAL_UNRATED | 515.3025 | lower::long_wall_5ft::structural_pier_x_corbel::03 | True
lower::long_wall_5ft::cassette_lock::support_03_right_slot | cassette_lock | through_interior_right_slot | lower | long_wall_5ft | 1 | retention | largest flat lock face on the build plate | True | cassette-to-integral-cap retention only; no independent load rating | PROVISIONAL_EXPERIMENTAL_UNRATED | 515.3025 | lower::long_wall_5ft::structural_pier_x_corbel::03 | True
lower::long_wall_5ft::cassette_lock::support_04_left_slot | cassette_lock | through_interior_left_slot | lower | long_wall_5ft | 1 | retention | largest flat lock face on the build plate | True | cassette-to-integral-cap retention only; no independent load rating | PROVISIONAL_EXPERIMENTAL_UNRATED | 757.2375 | lower::long_wall_5ft::structural_pier_x_corbel::04 | True
lower::long_wall_5ft::cassette_lock::support_04_right_slot | cassette_lock | through_interior_right_slot | lower | long_wall_5ft | 1 | retention | largest flat lock face on the build plate | True | cassette-to-integral-cap retention only; no independent load rating | PROVISIONAL_EXPERIMENTAL_UNRATED | 757.2375 | lower::long_wall_5ft::structural_pier_x_corbel::04 | True
lower::long_wall_5ft::cassette_lock::support_05_left_slot | cassette_lock | through_interior_left_slot | lower | long_wall_5ft | 1 | retention | largest flat lock face on the build plate | True | cassette-to-integral-cap retention only; no independent load rating | PROVISIONAL_EXPERIMENTAL_UNRATED | 999.1725 | lower::long_wall_5ft::structural_pier_x_corbel::05 | True
lower::long_wall_5ft::cassette_lock::support_05_right_slot | cassette_lock | through_interior_right_slot | lower | long_wall_5ft | 1 | retention | largest flat lock face on the build plate | True | cassette-to-integral-cap retention only; no independent load rating | PROVISIONAL_EXPERIMENTAL_UNRATED | 999.1725 | lower::long_wall_5ft::structural_pier_x_corbel::05 | True
lower::long_wall_5ft::cassette_lock::support_06_left_slot | cassette_lock | through_interior_left_slot | lower | long_wall_5ft | 1 | retention | largest flat lock face on the build plate | True | cassette-to-integral-cap retention only; no independent load rating | PROVISIONAL_EXPERIMENTAL_UNRATED | 1241.1075 | lower::long_wall_5ft::structural_pier_x_corbel::06 | True
lower::long_wall_5ft::cassette_lock::support_06_right_slot | cassette_lock | through_interior_right_slot | lower | long_wall_5ft | 1 | retention | largest flat lock face on the build plate | True | cassette-to-integral-cap retention only; no independent load rating | PROVISIONAL_EXPERIMENTAL_UNRATED | 1241.1075 | lower::long_wall_5ft::structural_pier_x_corbel::06 | True
lower::long_wall_5ft::cassette_lock::support_07_left_slot | cassette_lock | through_end_left_slot | lower | long_wall_5ft | 1 | retention | largest flat lock face on the build plate | True | cassette-to-integral-cap retention only; no independent load rating | PROVISIONAL_EXPERIMENTAL_UNRATED | 1483.0425 | lower::long_wall_5ft::structural_pier_x_corbel::07 | True
lower::long_wall_5ft::cassette_lock::support_07_right_slot | cassette_lock | through_end_right_slot | lower | long_wall_5ft | 1 | retention | largest flat lock face on the build plate | True | cassette-to-integral-cap retention only; no independent load rating | PROVISIONAL_EXPERIMENTAL_UNRATED | 1483.0425 | lower::long_wall_5ft::structural_pier_x_corbel::07 | True
lower::long_wall_5ft::cassette_top_retention_wedge::half_01_wedge_1 | cassette_top_retention_wedge | through_left_half | lower | long_wall_5ft | 1 | retention | locked crossbar and handle broad faces on the build plate; historical orientation key retained for schema compatibility | True | withdrawal retention/preload only; zero vertical shelf-load credit | PROVISIONAL_EXPERIMENTAL_UNRATED | 31.4325 | lower::long_wall_5ft::arcade_half::01 | True
lower::long_wall_5ft::cassette_top_retention_wedge::half_01_wedge_2 | cassette_top_retention_wedge | through_left_half | lower | long_wall_5ft | 1 | retention | locked crossbar and handle broad faces on the build plate; historical orientation key retained for schema compatibility | True | withdrawal retention/preload only; zero vertical shelf-load credit | PROVISIONAL_EXPERIMENTAL_UNRATED | 31.4325 | lower::long_wall_5ft::arcade_half::01 | True
lower::long_wall_5ft::cassette_top_retention_wedge::half_02_wedge_1 | cassette_top_retention_wedge | through_right_half | lower | long_wall_5ft | 1 | retention | locked crossbar and handle broad faces on the build plate; historical orientation key retained for schema compatibility | True | withdrawal retention/preload only; zero vertical shelf-load credit | PROVISIONAL_EXPERIMENTAL_UNRATED | 273.3675 | lower::long_wall_5ft::arcade_half::02 | True
lower::long_wall_5ft::cassette_top_retention_wedge::half_02_wedge_2 | cassette_top_retention_wedge | through_right_half | lower | long_wall_5ft | 1 | retention | locked crossbar and handle broad faces on the build plate; historical orientation key retained for schema compatibility | True | withdrawal retention/preload only; zero vertical shelf-load credit | PROVISIONAL_EXPERIMENTAL_UNRATED | 273.3675 | lower::long_wall_5ft::arcade_half::02 | True
lower::long_wall_5ft::cassette_top_retention_wedge::half_03_wedge_1 | cassette_top_retention_wedge | through_left_half | lower | long_wall_5ft | 1 | retention | locked crossbar and handle broad faces on the build plate; historical orientation key retained for schema compatibility | True | withdrawal retention/preload only; zero vertical shelf-load credit | PROVISIONAL_EXPERIMENTAL_UNRATED | 273.3675 | lower::long_wall_5ft::arcade_half::03 | True
lower::long_wall_5ft::cassette_top_retention_wedge::half_03_wedge_2 | cassette_top_retention_wedge | through_left_half | lower | long_wall_5ft | 1 | retention | locked crossbar and handle broad faces on the build plate; historical orientation key retained for schema compatibility | True | withdrawal retention/preload only; zero vertical shelf-load credit | PROVISIONAL_EXPERIMENTAL_UNRATED | 273.3675 | lower::long_wall_5ft::arcade_half::03 | True
lower::long_wall_5ft::cassette_top_retention_wedge::half_04_wedge_1 | cassette_top_retention_wedge | through_right_half | lower | long_wall_5ft | 1 | retention | locked crossbar and handle broad faces on the build plate; historical orientation key retained for schema compatibility | True | withdrawal retention/preload only; zero vertical shelf-load credit | PROVISIONAL_EXPERIMENTAL_UNRATED | 515.3025 | lower::long_wall_5ft::arcade_half::04 | True
lower::long_wall_5ft::cassette_top_retention_wedge::half_04_wedge_2 | cassette_top_retention_wedge | through_right_half | lower | long_wall_5ft | 1 | retention | locked crossbar and handle broad faces on the build plate; historical orientation key retained for schema compatibility | True | withdrawal retention/preload only; zero vertical shelf-load credit | PROVISIONAL_EXPERIMENTAL_UNRATED | 515.3025 | lower::long_wall_5ft::arcade_half::04 | True
lower::long_wall_5ft::cassette_top_retention_wedge::half_05_wedge_1 | cassette_top_retention_wedge | through_left_half | lower | long_wall_5ft | 1 | retention | locked crossbar and handle broad faces on the build plate; historical orientation key retained for schema compatibility | True | withdrawal retention/preload only; zero vertical shelf-load credit | PROVISIONAL_EXPERIMENTAL_UNRATED | 515.3025 | lower::long_wall_5ft::arcade_half::05 | True
lower::long_wall_5ft::cassette_top_retention_wedge::half_05_wedge_2 | cassette_top_retention_wedge | through_left_half | lower | long_wall_5ft | 1 | retention | locked crossbar and handle broad faces on the build plate; historical orientation key retained for schema compatibility | True | withdrawal retention/preload only; zero vertical shelf-load credit | PROVISIONAL_EXPERIMENTAL_UNRATED | 515.3025 | lower::long_wall_5ft::arcade_half::05 | True
lower::long_wall_5ft::cassette_top_retention_wedge::half_06_wedge_1 | cassette_top_retention_wedge | through_right_half | lower | long_wall_5ft | 1 | retention | locked crossbar and handle broad faces on the build plate; historical orientation key retained for schema compatibility | True | withdrawal retention/preload only; zero vertical shelf-load credit | PROVISIONAL_EXPERIMENTAL_UNRATED | 757.2375 | lower::long_wall_5ft::arcade_half::06 | True
lower::long_wall_5ft::cassette_top_retention_wedge::half_06_wedge_2 | cassette_top_retention_wedge | through_right_half | lower | long_wall_5ft | 1 | retention | locked crossbar and handle broad faces on the build plate; historical orientation key retained for schema compatibility | True | withdrawal retention/preload only; zero vertical shelf-load credit | PROVISIONAL_EXPERIMENTAL_UNRATED | 757.2375 | lower::long_wall_5ft::arcade_half::06 | True
lower::long_wall_5ft::cassette_top_retention_wedge::half_07_wedge_1 | cassette_top_retention_wedge | through_left_half | lower | long_wall_5ft | 1 | retention | locked crossbar and handle broad faces on the build plate; historical orientation key retained for schema compatibility | True | withdrawal retention/preload only; zero vertical shelf-load credit | PROVISIONAL_EXPERIMENTAL_UNRATED | 757.2375 | lower::long_wall_5ft::arcade_half::07 | True
lower::long_wall_5ft::cassette_top_retention_wedge::half_07_wedge_2 | cassette_top_retention_wedge | through_left_half | lower | long_wall_5ft | 1 | retention | locked crossbar and handle broad faces on the build plate; historical orientation key retained for schema compatibility | True | withdrawal retention/preload only; zero vertical shelf-load credit | PROVISIONAL_EXPERIMENTAL_UNRATED | 757.2375 | lower::long_wall_5ft::arcade_half::07 | True
lower::long_wall_5ft::cassette_top_retention_wedge::half_08_wedge_1 | cassette_top_retention_wedge | through_right_half | lower | long_wall_5ft | 1 | retention | locked crossbar and handle broad faces on the build plate; historical orientation key retained for schema compatibility | True | withdrawal retention/preload only; zero vertical shelf-load credit | PROVISIONAL_EXPERIMENTAL_UNRATED | 999.1725 | lower::long_wall_5ft::arcade_half::08 | True
lower::long_wall_5ft::cassette_top_retention_wedge::half_08_wedge_2 | cassette_top_retention_wedge | through_right_half | lower | long_wall_5ft | 1 | retention | locked crossbar and handle broad faces on the build plate; historical orientation key retained for schema compatibility | True | withdrawal retention/preload only; zero vertical shelf-load credit | PROVISIONAL_EXPERIMENTAL_UNRATED | 999.1725 | lower::long_wall_5ft::arcade_half::08 | True
lower::long_wall_5ft::cassette_top_retention_wedge::half_09_wedge_1 | cassette_top_retention_wedge | through_left_half | lower | long_wall_5ft | 1 | retention | locked crossbar and handle broad faces on the build plate; historical orientation key retained for schema compatibility | True | withdrawal retention/preload only; zero vertical shelf-load credit | PROVISIONAL_EXPERIMENTAL_UNRATED | 999.1725 | lower::long_wall_5ft::arcade_half::09 | True
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

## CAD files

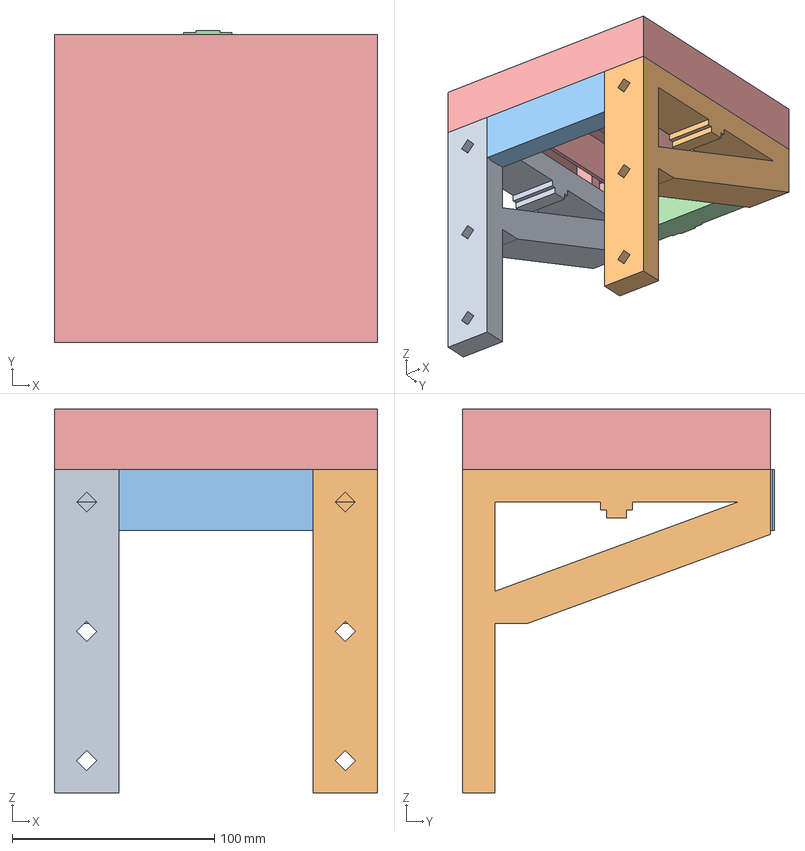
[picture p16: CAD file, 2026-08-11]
development/r9/generated/one_bay_prototype_v3/assembly_reference/R9_ONE_BAY_ASSEMBLED_REFERENCE_NOT_A_PRINT_PLATE.3mf
160.0 x 154.4 x 190.0 mm
r9_one_bay_left_compact_support
r9_one_bay_right_compact_support
r9_one_bay_rear_ledger
r9_one_bay_front_beam
r9_one_bay_shelf_cassette

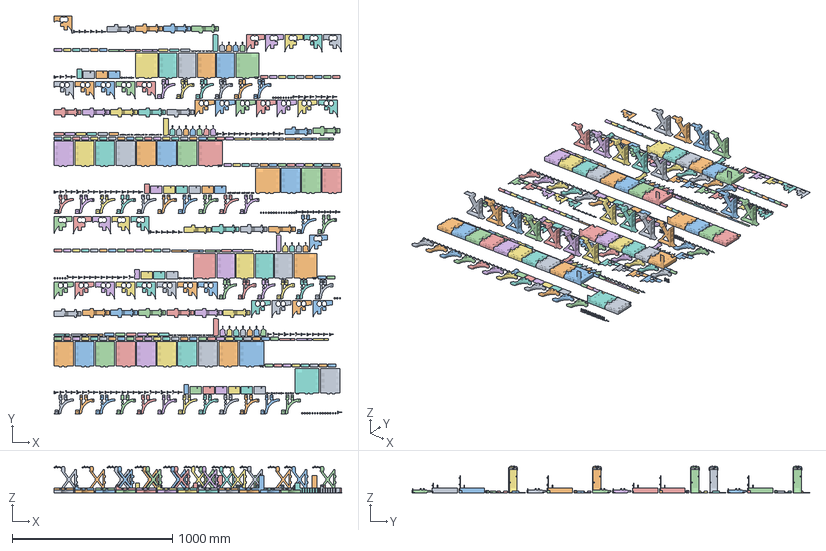
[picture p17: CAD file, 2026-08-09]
development/r6/generated/model_only_3mf/MODEL_ONLY_R6_TWO_LEVEL_FULL_PROJECT.3mf
1796.7 x 2487.2 x 165.9 mm
lower::long_wall_5ft::arcade_half::01
lower::long_wall_5ft::arcade_half::02
lower::long_wall_5ft::arcade_half::03
lower::long_wall_5ft::arcade_half::04
lower::long_wall_5ft::arcade_half::05
lower::long_wall_5ft::arcade_half::06
lower::long_wall_5ft::arcade_half::07
lower::long_wall_5ft::arcade_half::08
lower::long_wall_5ft::arcade_half::09
lower::long_wall_5ft::arcade_half::10
lower::long_wall_5ft::arcade_half::11
lower::long_wall_5ft::arcade_half::12
lower::long_wall_5ft::cassette_lock::support_01_left_slot
lower::long_wall_5ft::cassette_lock::support_01_right_slot
lower::long_wall_5ft::cassette_lock::support_02_left_slot
lower::long_wall_5ft::cassette_lock::support_02_right_slot
lower::long_wall_5ft::cassette_lock::support_03_left_slot
lower::long_wall_5ft::cassette_lock::support_03_right_slot
lower::long_wall_5ft::cassette_lock::support_04_left_slot
lower::long_wall_5ft::cassette_lock::support_04_right_slot
lower::long_wall_5ft::cassette_lock::support_05_left_slot
lower::long_wall_5ft::cassette_lock::support_05_right_slot
lower::long_wall_5ft::cassette_lock::support_06_left_slot
lower::long_wall_5ft::cassette_lock::support_06_right_slot
lower::long_wall_5ft::cassette_lock::support_07_left_slot
lower::long_wall_5ft::cassette_lock::support_07_right_slot
lower::long_wall_5ft::cassette_top_retention_wedge::half_01_wedge_1
lower::long_wall_5ft::cassette_top_retention_wedge::half_01_wedge_2
lower::long_wall_5ft::cassette_top_retention_wedge::half_02_wedge_1
lower::long_wall_5ft::cassette_top_retention_wedge::half_02_wedge_2
lower::long_wall_5ft::cassette_top_retention_wedge::half_03_wedge_1
lower::long_wall_5ft::cassette_top_retention_wedge::half_03_wedge_2
lower::long_wall_5ft::cassette_top_retention_wedge::half_04_wedge_1
lower::long_wall_5ft::cassette_top_retention_wedge::half_04_wedge_2
lower::long_wall_5ft::cassette_top_retention_wedge::half_05_wedge_1
lower::long_wall_5ft::cassette_top_retention_wedge::half_05_wedge_2
lower::long_wall_5ft::cassette_top_retention_wedge::half_06_wedge_1
lower::long_wall_5ft::cassette_top_retention_wedge::half_06_wedge_2
lower::long_wall_5ft::cassette_top_retention_wedge::half_07_wedge_1
lower::long_wall_5ft::cassette_top_retention_wedge::half_07_wedge_2
lower::long_wall_5ft::cassette_top_retention_wedge::half_08_wedge_1
lower::long_wall_5ft::cassette_top_retention_wedge::half_08_wedge_2
lower::long_wall_5ft::cassette_top_retention_wedge::half_09_wedge_1
lower::long_wall_5ft::cassette_top_retention_wedge::half_09_wedge_2
lower::long_wall_5ft::cassette_top_retention_wedge::half_10_wedge_1
lower::long_wall_5ft::cassette_top_retention_wedge::half_10_wedge_2
lower::long_wall_5ft::cassette_top_retention_wedge::half_11_wedge_1
lower::long_wall_5ft::cassette_top_retention_wedge::half_11_wedge_2
lower::long_wall_5ft::cassette_top_retention_wedge::half_12_wedge_1
lower::long_wall_5ft::cassette_top_retention_wedge::half_12_wedge_2
lower::long_wall_5ft::corner_fixed_rosette::fixed_rosette
lower::long_wall_5ft::crown_bridge::01
lower::long_wall_5ft::crown_bridge::02
lower::long_wall_5ft::crown_bridge::03
lower::long_wall_5ft::crown_bridge::04
lower::long_wall_5ft::crown_bridge::05
lower::long_wall_5ft::crown_bridge::06
lower::long_wall_5ft::crown_bridge_retention_pin::01
lower::long_wall_5ft::crown_bridge_retention_pin::02
lower::long_wall_5ft::crown_bridge_retention_pin::03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

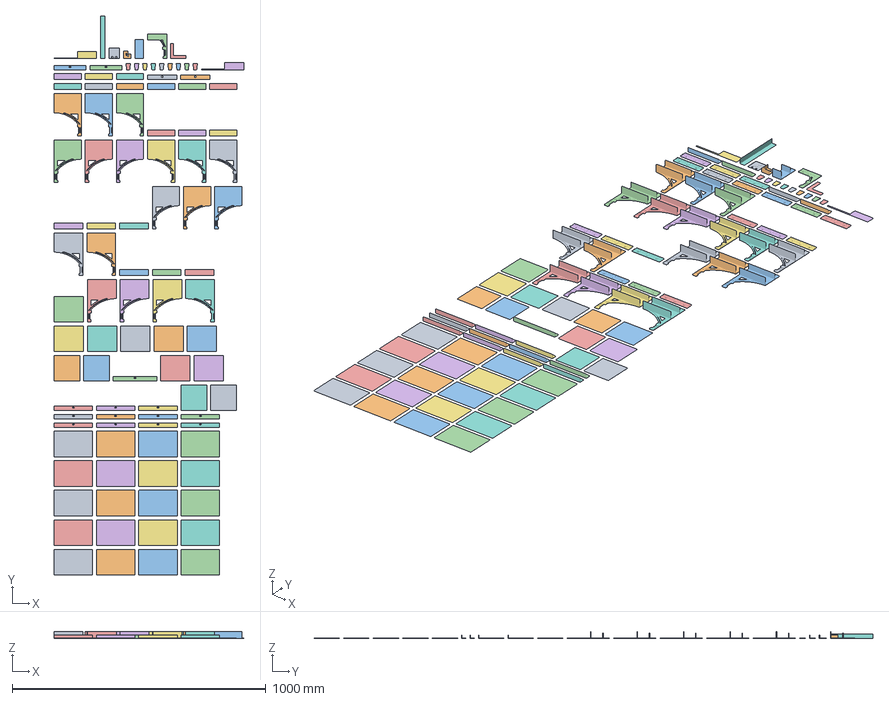
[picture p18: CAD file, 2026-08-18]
generated/model_only_3mf/MODEL_ONLY_STORY_CORNER_TRIADIC_PALATINE_FULL_PRINT_SET.3mf
748.0 x 2201.7 x 29.0 mm
PETG_TopTile_Center_6inPitch_01
PETG_TopTile_Center_6inPitch_02
PETG_TopTile_Center_6inPitch_03
PETG_TopTile_Center_6inPitch_04
PETG_TopTile_Center_6inPitch_05
PETG_TopTile_Center_6inPitch_06
PETG_TopTile_Center_6inPitch_07
PETG_TopTile_Center_6inPitch_08
PETG_TopTile_Center_6inPitch_09
PETG_TopTile_Center_6inPitch_10
PETG_TopTile_Center_6inPitch_11
PETG_TopTile_Center_6inPitch_12
PETG_TopTile_Center_6inPitch_13
PETG_TopTile_Center_6inPitch_14
PETG_TopTile_Center_6inPitch_15
PETG_TopTile_Center_6inPitch_16
PETG_TopTile_Center_6inPitch_17
PETG_TopTile_Center_6inPitch_18
PETG_TopTile_Center_6inPitch_19
PETG_TopTile_Center_6inPitch_20
PETG_RearCurb_Center_6inPitch_01
PETG_RearCurb_Center_6inPitch_02
PETG_RearCurb_Center_6inPitch_03
PETG_RearCurb_Center_6inPitch_04
PETG_RearCurb_Center_6inPitch_05
PETG_RearCurb_Center_6inPitch_06
PETG_RearCurb_Center_6inPitch_07
PETG_RearCurb_Center_6inPitch_08
PETG_RearCurb_Center_6inPitch_09
PETG_RearCurb_Center_6inPitch_10
PETG_RearCurb_Center_6inPitch_11
PETG_TopTile_CornerQuadrant_SquareMating_01
PETG_TopTile_CornerQuadrant_SquareMating_02
PETG_TopTile_CornerQuadrant_SquareMating_03
PETG_TopTile_CornerQuadrant_SquareMating_04
PETG_RearCurb_CornerSide_ThroughZone_01
PETG_TopTile_ParametricEnd_01
PETG_TopTile_ParametricEnd_02
PETG_TopTile_ParametricEnd_03
PETG_TopTile_ParametricEnd_04
PETG_TopTile_ParametricEnd_05
PETG_TopTile_ParametricEnd_06
PETG_TopTile_ParametricEnd_07
PETG_TopTile_ParametricEnd_08
PETG_Palatine_ArcadeFascia_Half_left_short_wall_3ft_01
PETG_Palatine_ArcadeFascia_Half_left_short_wall_3ft_02
PETG_Palatine_ArcadeFascia_Half_left_short_wall_3ft_03
PETG_Palatine_ArcadeFascia_Half_right_short_wall_3ft_01
PETG_Palatine_ArcadeFascia_Half_right_short_wall_3ft_02
PETG_Palatine_ArcadeFascia_Half_right_short_wall_3ft_03
PETG_Palatine_EntablatureOverlay_short_wall_3ft_01
PETG_Palatine_EntablatureOverlay_short_wall_3ft_02
PETG_Palatine_EntablatureOverlay_short_wall_3ft_03
PETG_Palatine_EntablatureOverlay_short_wall_3ft_04
PETG_Palatine_EntablatureOverlay_short_wall_3ft_05
PETG_Palatine_EntablatureOverlay_short_wall_3ft_06
PETG_Palatine_ArcadeFascia_Half_left_long_wall_5ft_01
PETG_Palatine_ArcadeFascia_Half_left_long_wall_5ft_02
PETG_Palatine_ArcadeFascia_Half_left_long_wall_5ft_03
PETG_Palatine_ArcadeFascia_Half_left_long_wall_5ft_04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

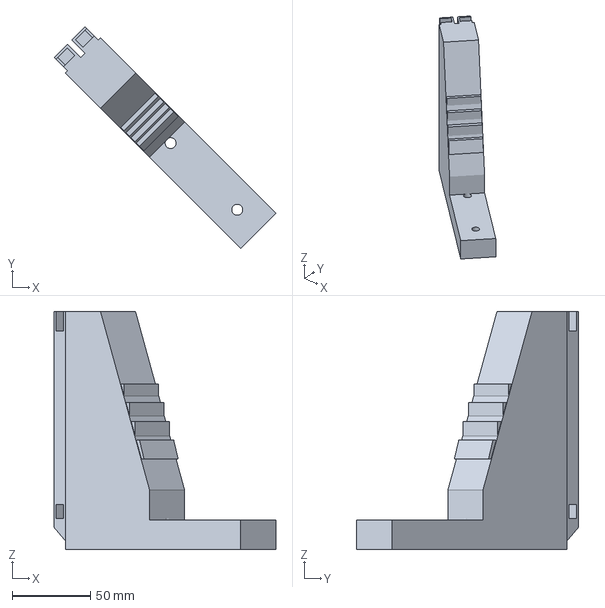
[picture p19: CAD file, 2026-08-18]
development/r10/generated/one_bay_qualification_v1/individual_model_only_3mf/MODEL_ONLY_r10_one_bay_right_support.3mf
141.9 x 141.9 x 152.4 mm

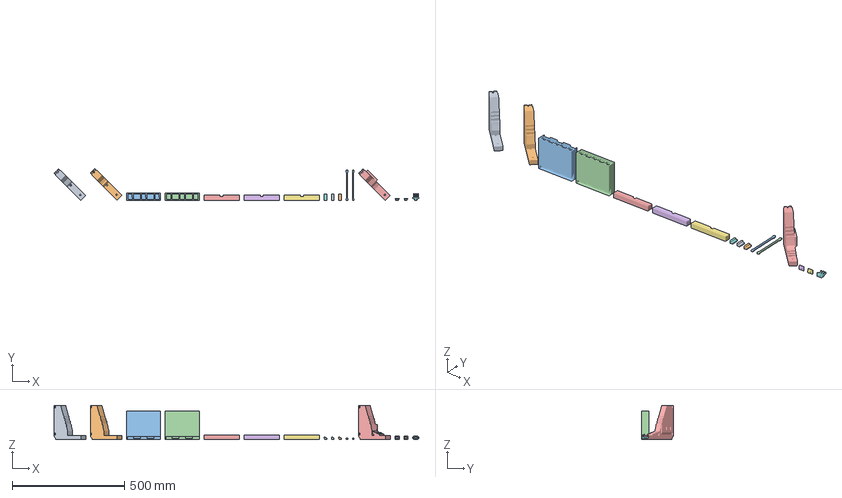
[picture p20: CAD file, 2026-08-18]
development/r10/generated/one_bay_qualification_v1/model_only_3mf/MODEL_ONLY_R10_ONE_BAY_QUALIFICATION_CATALOG_NOT_A_PRINT_PLATE.3mf
1628.9 x 141.9 x 152.4 mm
r10_one_bay_left_support
r10_one_bay_right_support
r10_one_bay_left_cassette_half
r10_one_bay_right_cassette_half
r10_one_bay_rear_splice_log
r10_one_bay_center_splice_log
r10_one_bay_front_splice_log
r10_one_bay_rear_log_retainer
r10_one_bay_center_log_retainer
r10_one_bay_front_log_retainer
r10_one_bay_left_support_retainer
r10_one_bay_right_support_retainer
r10_first_wall_s0_inward_two_socket_additive_bookend_candidate
r10_first_wall_socket_0_flush_blank
r10_first_wall_socket_1_flush_blank
r10_first_wall_multi_cable_comb_hook

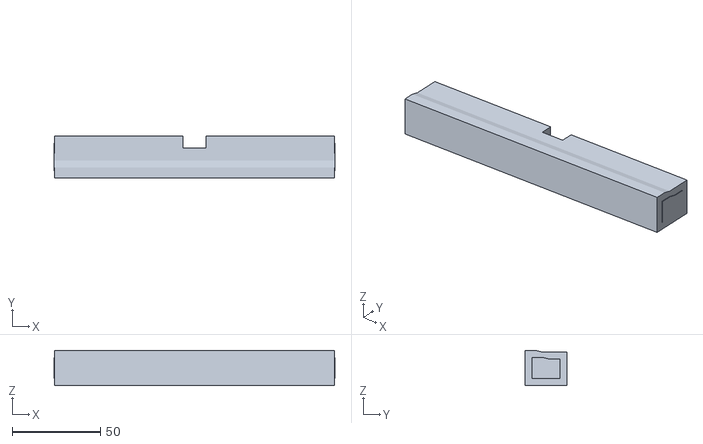
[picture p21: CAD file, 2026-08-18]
development/r10/generated/one_bay_qualification_v1/stl/r10_one_bay_rear_splice_log.stl
159.1 x 24.0 x 20.0

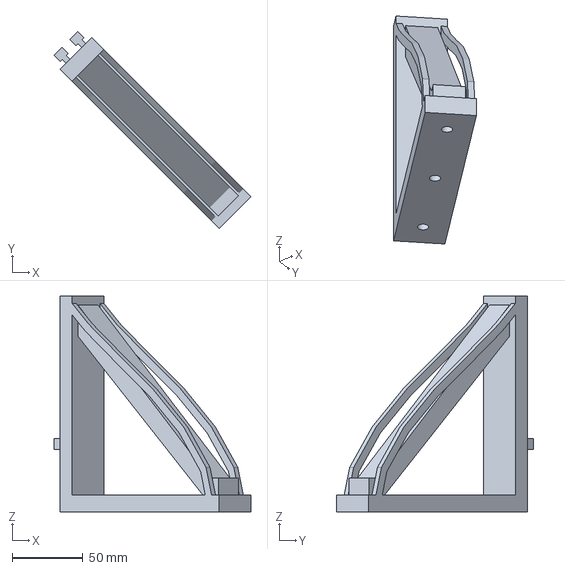
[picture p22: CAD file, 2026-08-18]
development/r11/generated/first_outer_actual_bay_qualification_v1/individual_model_only_3mf/MODEL_ONLY_r11_first_wall_s1_ordinary_support.3mf
138.9 x 138.9 x 152.4 mm

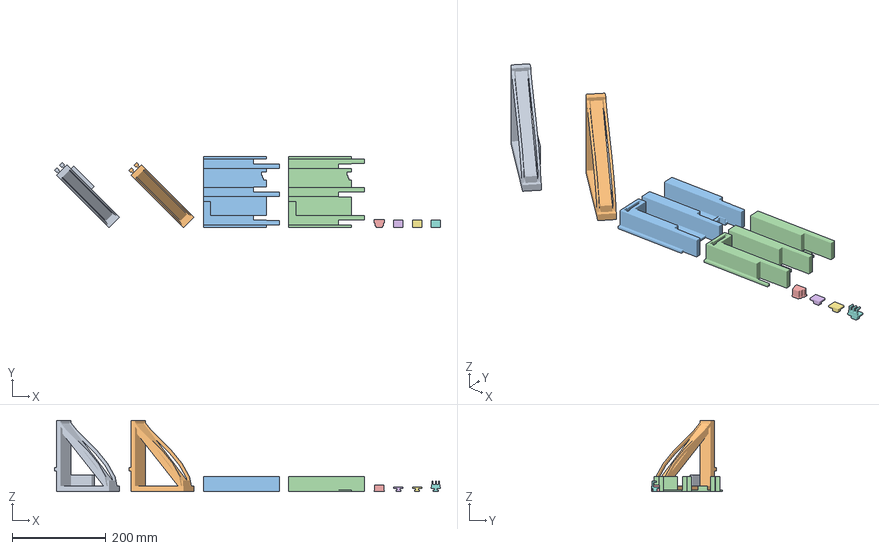
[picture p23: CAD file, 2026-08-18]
development/r11/generated/first_outer_actual_bay_qualification_v1/model_only_3mf/MODEL_ONLY_R11_FIRST_OUTER_ACTUAL_BAY_CATALOG_NOT_A_PRINT_PLATE.3mf
824.2 x 152.4 x 152.4 mm
r11_first_wall_s0_fused_two_socket_support
r11_first_wall_s1_ordinary_support
r11_bay0_left_terminal_integrated_half_deck
r11_bay0_right_terminal_integrated_half_deck
r11_bay0_positive_keystone
r11_first_wall_socket_0_flush_blank
r11_first_wall_socket_1_flush_blank
r11_first_wall_multi_cable_comb_hook

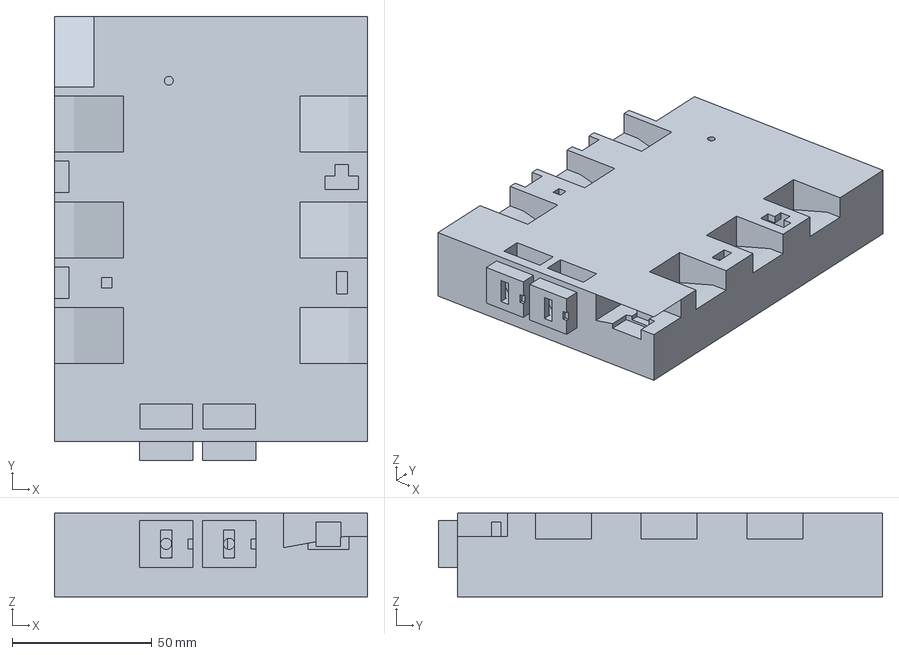
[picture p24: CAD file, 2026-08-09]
development/r6/generated/individual_model_only_3mf/MODEL_ONLY_R6_DEV_CASSETTE_RETURN_03_OF_06.3mf
112.2 x 159.2 x 30.0 mm

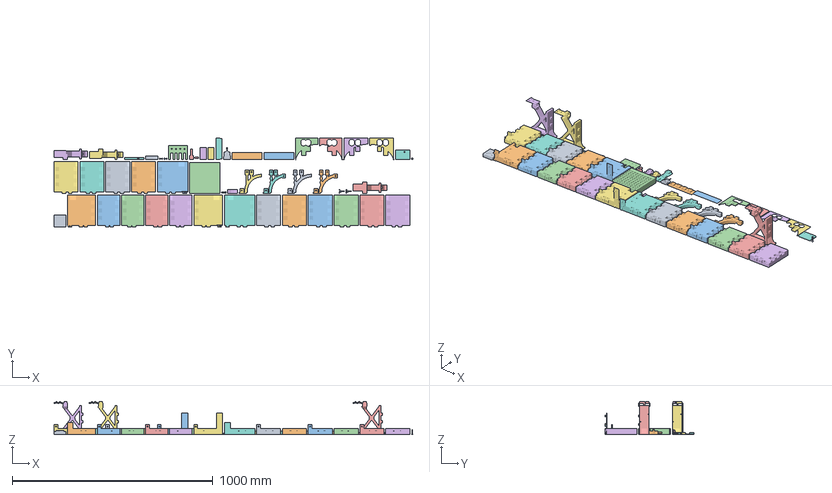
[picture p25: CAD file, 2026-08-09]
development/r6/generated/model_only_3mf/MODEL_ONLY_R6_UNIQUE_PARTS_CATALOG.3mf
1787.2 x 443.2 x 165.9 mm
catalog::001::source::R6_DEV_BLOCKED_WALL_SCREW_BEARING_COUPON_SOLID_NO_HOLE
catalog::002::source::R6_DEV_CASSETTE_RETURN_01_OF_06
catalog::003::source::R6_DEV_CASSETTE_RETURN_02_OF_06
catalog::004::source::R6_DEV_CASSETTE_RETURN_03_OF_06
catalog::005::source::R6_DEV_CASSETTE_RETURN_04_OF_06
catalog::006::source::R6_DEV_CASSETTE_RETURN_05_OF_06
catalog::007::source::R6_DEV_CASSETTE_RETURN_06_OF_06
catalog::008::source::R6_DEV_CASSETTE_THROUGH_01_OF_12
catalog::009::source::R6_DEV_CASSETTE_THROUGH_02_OF_12
catalog::010::source::R6_DEV_CASSETTE_THROUGH_03_OF_12
catalog::011::source::R6_DEV_CASSETTE_THROUGH_04_OF_12
catalog::012::source::R6_DEV_CASSETTE_THROUGH_05_OF_12
catalog::013::source::R6_DEV_CASSETTE_THROUGH_06_OF_12
catalog::014::source::R6_DEV_CASSETTE_THROUGH_07_OF_12
catalog::015::source::R6_DEV_CASSETTE_THROUGH_08_OF_12
catalog::016::source::R6_DEV_CASSETTE_THROUGH_09_OF_12
catalog::017::source::R6_DEV_CASSETTE_THROUGH_10_OF_12
catalog::018::source::R6_DEV_CASSETTE_THROUGH_11_OF_12
catalog::019::source::R6_DEV_CASSETTE_THROUGH_12_OF_12
catalog::020::source::R6_DEV_COFFERED_CASSETTE_HALF_MAX_WIDTH_COUPON
catalog::021::source::R6_DEV_CROWN_BRIDGE_ANTI_DROP_PIN_RETENTION_ONLY
catalog::022::source::R6_DEV_DIAPHRAGM_BOWTIE_KEY
catalog::023::source::R6_DEV_FINAL_X_GRAND_ARCH_HALF_RETURN_SHORT_LEFT
catalog::024::source::R6_DEV_FINAL_X_GRAND_ARCH_HALF_RETURN_SHORT_RIGHT
catalog::025::source::R6_DEV_FINAL_X_GRAND_ARCH_HALF_THROUGH_LONG_LEFT
catalog::026::source::R6_DEV_FINAL_X_GRAND_ARCH_HALF_THROUGH_LONG_RIGHT
catalog::027::source::R6_DEV_FINAL_X_SPRING_RETENTION_WEDGE_UNIVERSAL
catalog::028::source::R6_DEV_FINAL_X_TOP_CAPTURE_WEDGE_UNIVERSAL
catalog::029::source::R6_DEV_FINAL_X_X_CORBEL_PIER_INTERIOR_DUAL_SOCKET_INTEGRATED_CAP
catalog::030::source::R6_DEV_FINAL_X_X_CORBEL_PIER_RUN_END_TERMINAL_INTEGRATED_CAP
catalog::031::source::R6_DEV_FINAL_X_X_CORBEL_PIER_RUN_START_TERMINAL_INTEGRATED_CAP
catalog::032::source::R6_DEV_FIXED_CROWN_DIAPHRAGM_KEEPER_STRIP_REAR_BAYONET
catalog::033::source::R6_DEV_FIXED_CROWN_FRONT_INSERTED_ENTABLATURE_TIE_WITH_Q_AXIS_PIN_EYE
catalog::034::source::R6_DEV_INDEXED_VERTICAL_QUARTER_TURN_PIN_FRONT_TIE_REACH
catalog::035::source::R6_DEV_INDEXED_VERTICAL_QUARTER_TURN_PIN_KEEPER_REACH
catalog::036::source::R6_DEV_JOINERY_CLEARANCE_LADDER_RECEIVER
catalog::037::source::R6_DEV_JOINERY_CLEARANCE_LADDER_TONGUE
catalog::038::source::R6_DEV_ORNAMENT_CORNER_FIXED_ROSETTE
catalog::039::source::R6_DEV_ORNAMENT_CORNER_FLOATING_RETURN
catalog::040::source::R6_DEV_ORNAMENT_ORDINARY_ENDCAP
catalog::041::source::R6_DEV_ORNAMENT_PIER_OVERLAY
catalog::042::source::R6_DEV_ORNAMENT_PRINT_FIRST_KEYHOLE_FEMALE_LADDER
catalog::043::source::R6_DEV_ORNAMENT_PRINT_FIRST_KEYHOLE_MALE_LADDER
catalog::044::source::R6_DEV_ORNAMENT_RETURN_CARRIER_LEFT
catalog::045::source::R6_DEV_ORNAMENT_RETURN_CARRIER_RIGHT
catalog::046::source::R6_DEV_ORNAMENT_THROUGH_CARRIER_LEFT
catalog::047::source::R6_DEV_ORNAMENT_THROUGH_CARRIER_RIGHT
catalog::048::source::R6_DEV_REAR_CROWN_BRIDGE_UPWARD_INSERTION_LADDER
catalog::049::source::R6_FINAL_X_INTEGRATED_CAP_CASSETTE_LOCK_SPLIT_TAIL

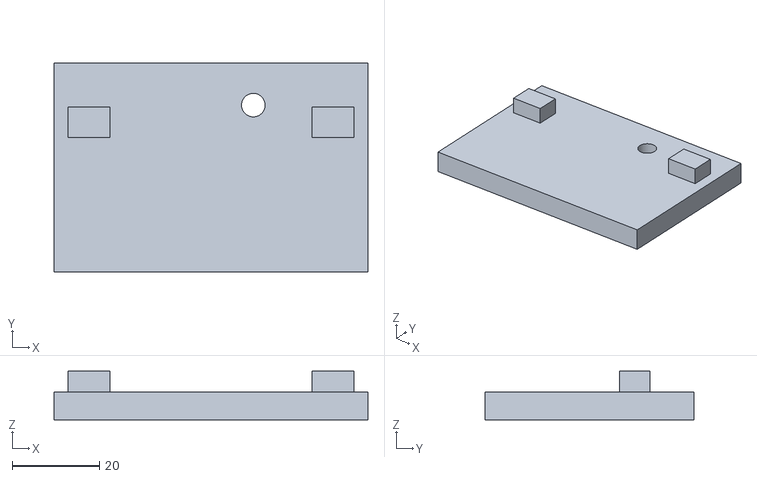
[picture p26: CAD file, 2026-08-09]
development/r6/generated/stl/R6_DEV_REAR_CROWN_BRIDGE_UPWARD_INSERTION_LADDER.stl
72.0 x 48.0 x 11.2

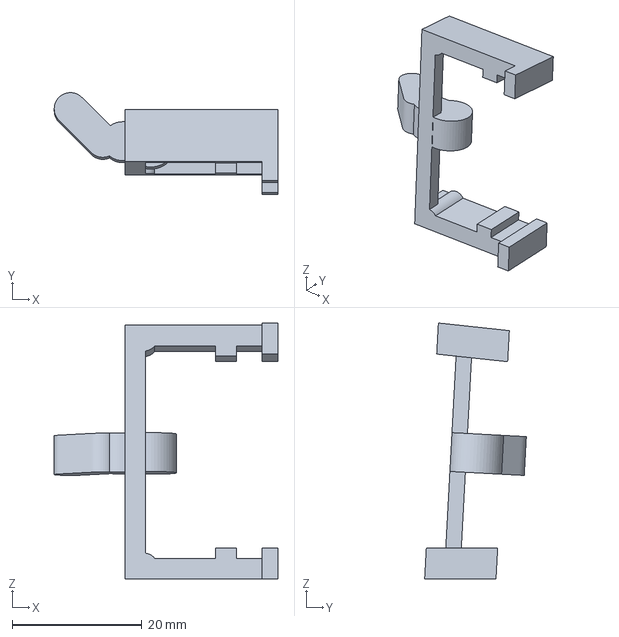
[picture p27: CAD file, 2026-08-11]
development/r7/generated/cable_peg_qualification_v4/individual_model_only_3mf/MODEL_ONLY_R7_DEV_CABLE_PEG_FRONT_SNAP_C_COLLAR_HOOK.3mf
34.5 x 15.7 x 39.5 mm

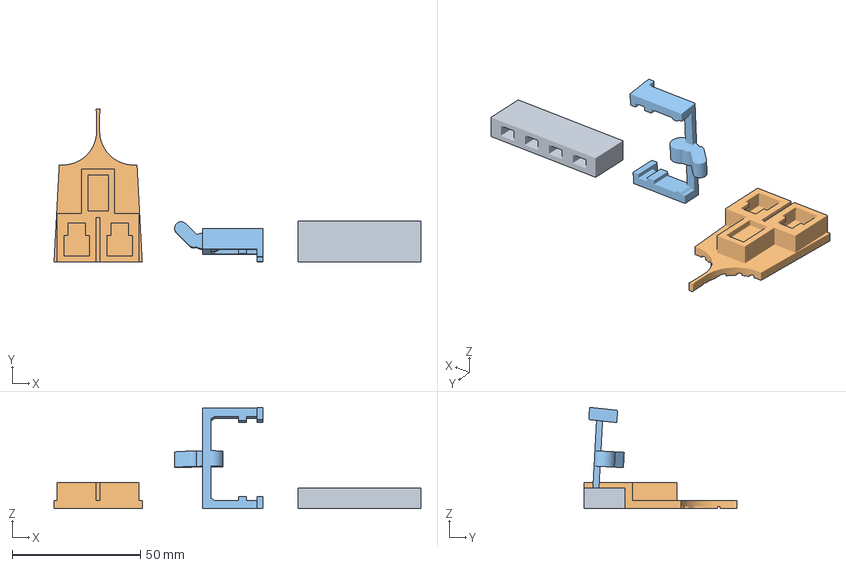
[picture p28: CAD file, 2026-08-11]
development/r7/generated/cable_peg_qualification_v4/model_only_3mf/MODEL_ONLY_R7_CABLE_PEG_COLUMN_QUALIFICATION.3mf
143.0 x 59.6 x 39.5 mm
R7_DEV_CABLE_PEG_COLLAR_CLEARANCE_LADDER_0P2_0P3_0P4_0P5
R7_DEV_CABLE_PEG_EXACT_R6_PIER_OVERLAY_COUPON
R7_DEV_CABLE_PEG_FRONT_SNAP_C_COLLAR_HOOK

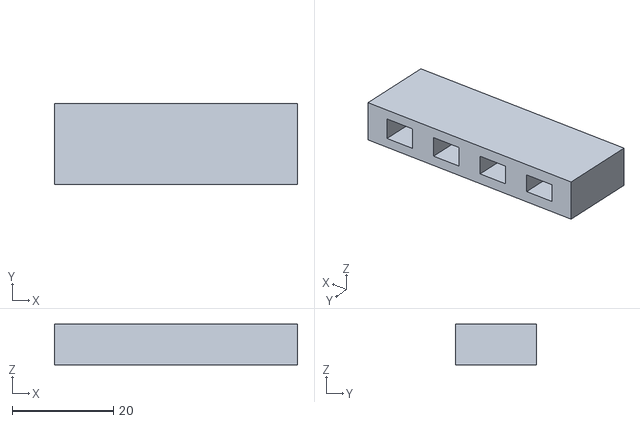
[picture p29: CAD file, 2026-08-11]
development/r7/generated/cable_peg_qualification_v4/stl/R7_DEV_CABLE_PEG_COLLAR_CLEARANCE_LADDER_0P2_0P3_0P4_0P5.stl
48.0 x 16.0 x 8.00

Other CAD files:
development/r11/generated/first_outer_actual_bay_qualification_v1/stl/r11_first_wall_s1_ordinary_support.stl
development/r8/generated/one_bay_qualification_v2/individual_model_only_3mf/MODEL_ONLY_r8_one_bay_mounted_rail.3mf
development/r8/generated/one_bay_qualification_v2/model_only_3mf/MODEL_ONLY_R8_ONE_BAY_QUALIFICATION_CATALOG.3mf
development/r8/generated/one_bay_qualification_v2/stl/r8_one_bay_registered_cassette.stl
development/r10/generated/one_bay_qualification_v1/individual_model_only_3mf/MODEL_ONLY_r10_first_wall_multi_cable_comb_hook.3mf
development/r10/generated/one_bay_qualification_v1/individual_model_only_3mf/MODEL_ONLY_r10_first_wall_s0_inward_two_socket_additive_bookend_candidate.3mf
development/r10/generated/one_bay_qualification_v1/individual_model_only_3mf/MODEL_ONLY_r10_first_wall_socket_0_flush_blank.3mf
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

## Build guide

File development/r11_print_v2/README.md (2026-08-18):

# R11 Gate A-left controlled print overlay

This sibling overlay preserves the immutable R11 v1 neutral bundle while
providing a fail-closed path to **one** tabletop qualification print of the
exact bay-0 left terminal half-deck. It does not contain geometry, a slicer
project, a profile, G-code, toolpaths, credentials, or reusable permission.

The checked-in generated package is deliberately non-authorizing. A print can
become eligible only after an exact Bambu slice is reviewed, its complete
evidence is stored outside this repository, and the user answers the exact
fresh-permission question. The resulting external permit is single-use. The
only authoritative consumption API atomically consumes under the ledger lock
and returns the same still-open, content-addressed G-code file descriptor to
an in-process sender. Failed, cancelled, rejected, and ambiguous attempts
still consume it.

## Commands

Validate or deterministically rebuild the static package into a fresh external
directory:

```sh
python -I -B development/r11_print_v2/generate_controlled_release.py --validate
python -I -B development/r11_print_v2/generate_controlled_release.py --output /tmp/r11-v2-check
```

After completing external evidence that conforms to the supplied schema:

```sh
python -I -B development/r11_print_v2/evaluate_attempt.py prepare-evidence --sliced-plate /private/tmp/r11-gate-a-evidence-20260811/r11_gate_a_left_20260811.gcode.3mf --output-directory /private/tmp/r11-gate-a-evidence-20260811/prepared-v2
python -I -B development/r11_print_v2/evaluate_attempt.py review --attempt /outside/repo/attempt.json
python -I -B development/r11_print_v2/evaluate_attempt.py init-ledger
python -I -B development/r11_print_v2/evaluate_attempt.py issue --attempt /outside/repo/attempt.json --permission /outside/repo/permission.json
```

The attempt also requires five independent live provenance files: read-only
printer telemetry, fresh human plate and nozzle observations, a physical
spool-label capture including the lot, and the completed dryer log/display. Hashes and
timestamps for those files are part of the reviewed-job digest. Telemetry alone
cannot attest plate cleanliness/type, physical nozzle flow/material, filament
lot, or drying.

`prepare-evidence` requires a fresh, nonexistent destination. It verifies the
three pinned native Bambu application profile sources, emits all three exact
approved effective profile exports plus their three deterministic snapshots,
and derives the sole G-code payload and exact config block directly from the
supplied sliced archive. It prints every output filename, byte count, and
SHA-256. It does not create an attempt or permission and never authorizes a
print. Use those reported files as relative evidence paths; do not hand-author
or rewrite any of the six profile JSON files. The complete emitted config
block must also match its frozen approved byte count and SHA-256; checking only
a small list of visible settings is insufficient.

The CLI deliberately has no path-only `consume` command: exiting and later
reopening a mutable GUI path would recreate a TOCTOU window. A sender must call
`consume_and_open_send_payload(...)` and send from its returned open descriptor
in that same process. No such printer sender is included here, so this overlay
does not itself contact or start the printer. Never reuse an attempt,
permission, sliced archive, extracted G-code, reviewed-job identity, or permit
for a retry. The ledger derives from the OS account database (never `HOME`), is
bound to uid/host/project by a strict identity record, requires explicit
one-time initialization, and cannot be redirected by any production API or CLI.

## Permanent boundary

No drilling, wall installation, test load, stored load, production/full-wall
printing, or nonzero load rating is authorized. The rating remains exactly
**0 kg / 0 lb**. The right half stays blocked until this left article cools,
is removed without force, and passes documented inspection under a separate
future gate.

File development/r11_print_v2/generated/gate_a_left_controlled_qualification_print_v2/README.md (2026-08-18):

# R11 Gate A-left controlled qualification print v2

This deterministic package binds the immutable R11 v1 neutral bundle and the
only initially selectable article: the exact bay-0 **left** terminal integrated
half-deck, quantity one. It contains no geometry, slicer project, profile,
G-code, toolpath, credential, runtime attempt evidence, permission, or permit.

## Static state

`print_authorized` and `effective_print_authorized` are permanently false in
this package. Exact reviewed slice evidence and fresh lowercase `yes`
permission must remain outside the repository. A separately issued external
permit is effective only while fresh and unconsumed; it is atomically consumed
under the identity-bound ledger lock only when an in-process sender retains the
same verified open content-addressed G-code descriptor. A later GUI path reopen
is not authorized. Failed, cancelled, rejected, or ambiguous attempts still
consume it. Every retry needs a new attempt ID, genuinely new sliced G-code,
Preview review, live-state check, and fresh permission.

The right half, supports, keystone, cable articles, and off-plate catalog are
all blocked. No drilling, wall installation, test load, stored load,
production/full-wall printing, or nonzero rating is authorized. Rating remains
exactly 0 kg / 0 lb.

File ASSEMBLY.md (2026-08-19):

# Assembly — Triadic Palatine Order r5

This document owns the build sequence and the attachment rules. Where another
document mentions assembly, this file is the authority; if a statement here
ever disagrees with a summary elsewhere, fix the summary. The structural rules
in [SAFETY.md](SAFETY.md) and the geometry in
[ENGINEERING_DESIGN.md](ENGINEERING_DESIGN.md) still govern what may be built
at all.

Nothing in this sequence gives any PETG part structural credit. The load path
is plywood + continuous steel angle + brackets + locks + standards + structural
fasteners + verified framing, in that order, always.

## Entry gate — all boxes before Stage 1

- [ ] [MEASUREMENT_WORKSHEET.md](MEASUREMENT_WORKSHEET.md) completed through
      section H, values entered in [config.json](config.json), artifacts
      rebuilt, and every `*_source` field in
      [generated/validation.json](generated/validation.json) confirmed to read
      `field_verified_*` rather than a nominal fallback.
- [ ] Corner gauge, fascia fit coupon (with 2.0 mm tile sample in place), and
      Palatine detail coupon all passed per
      [PRINT_ME_FIRST.md](PRINT_ME_FIRST.md) steps 1–8.
- [ ] Neutral-cure removable silicone qualified on printed PETG, sealed
      plywood, and the actual coated steel; curb/vault screws qualified in
      representative plywood with underside clearance.
- [ ] Full-size corner template made and checked against the real corner.
- [ ] Wall cleared, wiring/pipes mapped, framing verified at every support
      line per [SAFETY.md](SAFETY.md) "Before drilling".

## Stage 1 — Structural install (no PETG yet)

The ordering below is load-bearing information: two of the config inputs can
only be measured after the standards are on the wall, so cutting plywood
before step 6 risks cutting to a stale offset.

1. Establish one laser (or equivalent) common datum across both walls at the
   chosen shelf-top elevation. Verify the 39 in standard zone: the reported
   outlet-top-to-ceiling distance is 43.5 in, leaving only 4.5 in total
   placement margin for a 39 in standard.
2. Transfer the verified support centers from the worksheet framing map to
   both walls. Re-scan every fastener path for wiring and plates.
3. Mount the standards on verified framing or purpose-installed blocking with
   the manufacturer-prescribed fasteners. Check each standard plumb before
   final torque.
4. Hang the brackets at the common elevation and engage a bracket lock at
   every station.
5. Dry-fit the two nearest perpendicular corner brackets together with locks
   and both steel angles; confirm no interference (SAFETY.md corner stop
   conditions).
6. **Measure the installed wall-to-plywood-back offset separately on each
   wall**, and the actual bracket wall-to-tip reach, with the real hardware
   seated. Enter them in config.json (worksheet section H shows the exact
   keys), rebuild, and re-check the regenerated
   [cut plan](generated/cut_plan.csv) and
   [corner plan](generated/corner_layout.svg). Only now are the cut lengths
   real.
7. Cut the 5 ft through deck, then the 3 ft return deck, from the same
   plywood panel where practical, long arm parallel to the face grain.
8. Trim and deburr the return steel angle for controlled clearance; never
   force the angle ends together. Fasten each continuous angle under its deck
   front edge with reviewed predrilling and edge distances.
9. Seal the plywood — top face and cut edges — with a suitable clear sealer
   and let it cure. Every later silicone dot lands on sealed wood, and the
   silicone qualification coupon must have used the same sealer.
10. Set the through deck (it owns the 8 × 8 in corner square), then the
    return deck beyond the through front plane, and mechanically attach each
    deck at every bracket per the hardware instructions.
11. Verify: standards plumb, tops coplanar with no ridge at the corner, every
    lock engaged, every deck attached, 1.6 mm wood gap present, nothing
    touching that shouldn't. Then run the bare-structure load check
    (SAFETY.md "Before loading", steps 1–5) **before any PETG goes on**.

## Stage 2 — Stage and label the printed parts

Several part families are handed or arm-specific and easy to confuse. Sort
everything before opening any silicone.

| Confusable set | How to tell apart |
|---|---|
| 9 left vs 9 right arcade/fascia halves | Mirror-image handing: hold the half channel-up, arch outward — the half-pier lands on opposite ends. Label L/R on painter's tape inside the channel at print time. |
| Short-arm vs long-arm halves | Width: return (3 ft) halves are 113.99 mm; through (5 ft) halves are 107.63 mm. Measure — the 6.4 mm difference is invisible at a glance. |
| Entablature overlays | Same widths as their host halves (113.99 vs 107.63 mm); pair each overlay with a half of the same width. |
| Rear-curb ends | Through ends are 126.48 mm; return ends are 115.58 mm. |
| Top-tile ends vs centers | Ends are 116.08 mm; centers are 151.8 mm. |
| Corner quadrants | Four identical 101.3 mm squares — no handing. |

Reconcile physical counts against the production table in
[PRINT_ME_FIRST.md](PRINT_ME_FIRST.md) (98 installed pieces) before starting.
Quarantine any part with cracks, whitening, warp, or failed dimensions.

## Stage 3 — Top tiles

1. Place the four corner quadrants on the through-owned corner square first —
   they set the corner datum for both straight runs, which start 0.6 mm
   beyond the through corner front line.
2. Lay each straight run dry from the corner outward: centers on the 152.4 mm
   pitch, parametric ends last. Confirm every 0.6 mm seam and the return
   inner tile's 1.0 mm overhang of the hidden plywood gap.
3. Fix each tile with **one small centered dot** of qualified removable
   neutral-cure silicone on the sealed plywood. Keep every edge and seam
   free. Removal later is by floss, never prying.

## Stage 4 — Rear curbs

1. Seat the 30 mm fitted L corner replacement first, then the long-wall
   straight curb from station 1.892 in, then the separate 172.6 mm
   corner-side piece (through deck only, stopping at the through front
   plane), then the return curb starting on its own board at 8.750 in. No
   curb or fastener crosses the 1.6 mm wood joint.
2. At final layout, mark each curb clearance slot (8 × 4.4 mm; one per
   straight piece, one per replacement arm) onto the tile below. Remove the
   curb, drill the tile with a clearance hole sized to the qualified screw's
   shank, and set a drill depth stop so the bit cannot mark the plywood more
   than needed.
3. Drive each **short pan-head screw** through slot and tile into plywood
   only, after verifying it cannot emerge below the deck or reach steel.
   Snug, never clamped: the slot must still allow movement, and no seam may
   be bridged.

## Stage 5 — Fascia train

Direction matters: **start at the inside corner and train outward** on each
arm. The corner sets the bay layout's datum, and any accumulated seam error is
pushed to the outer ends, where the endcap's reserved 2.0 mm and the 1/8 in
exposed-end clearance absorb it.

1. Bench-fit each entablature overlay to its own half first (Stage 6 rule 1)
   so each half arrives at the wall complete.
2. Slip the first half over the shelf stack at the inside corner end of the
   through arm: both full-depth flanges must capture the plywood + angle +
   tile stack without splitting, binding, or lifting the tile. The nominal
   channel opening is 46.256 mm and was proven by the coupon.
3. Before seating each half fully home, place **one tiny centered dot** of
   qualified silicone inside its channel, then seat it and slide it laterally
   against its neighbor to the 0.6 mm seam.
4. Repeat outward: alternate left/right halves per the elevation drawing
   ([generated/palatine_elevation.svg](generated/palatine_elevation.svg)),
   three bays on the return, six on the through arm.
5. Never drill, notch, or otherwise modify the continuous steel angle for
   fascia retention — capture and silicone dots are the only retention.
6. Close each arm with its compound endcap: **two tiny dots** inside the
   final channel, then a hand pull-check. Fit the re-entrant corner pilaster
   slip-cover last at the inside corner: **two tiny dots inside one upper leg
   only**; the perpendicular leg floats with no adhesive across the seam.

## Stage 6 — Ornament

1. **Entablature overlays** (done on the bench in Stage 5): one tiny centered
   dot on the overlay's own fascia half; no overlay bridges a 0.6 mm seam.
2. **Keystones** go on after both adjacent halves are seated, since each
   bridges a bay-center seam visually: **two pinhead-size dots on one half
   only**; the other side floats.
3. **Groin-vault soffit** goes on last: through-owned corner square underside
   only, mounted through its two generated clearance slots with short
   nonstructural pan-head screws after a depth-stop check, preserving at
   least 10 mm to the nearest verified bracket plane, never bridging the
   plywood joint.

## Stage 7 — Close-out

Count the installed set — it must total **98**:

| Family | Count |
|---|---:|
| Center top tiles | 20 |
| Corner quadrants | 4 |
| Parametric top ends | 8 |
| Arcade/fascia halves | 18 |
| Entablature overlays | 18 |
| Rear curbs (11 centers + 4 ends + corner-side + L replacement) | 17 |
| Keystones | 9 |
| Endcaps | 2 |
| Corner pilaster | 1 |
| Groin-vault soffit | 1 |

Hand pull-check every overlay, keystone, endcap, pilaster leg, and the
soffit. Confirm every 0.6 mm seam is free, nothing bears on ornament, and no
tile has lifted. The gauge and two coupons are not installed.

## Stage 8 — Load acceptance and record

Follow SAFETY.md "Before loading". Before placing the first test weight,
write down your own stop limits in the record below — a deflection limit and
a permanent-set limit chosen before the test, not after. This record
documents a controlled check; it does not create a load rating.

| Record field | Value |
|---|---|
| Date / by | |
| Front-edge reference points (locations) | |
| Unloaded readings | |
| Test weights and placement | |
| Chosen deflection stop limit | |
| Chosen permanent-set stop limit | |
| Readings under load | |
| Readings after unload (permanent set) | |
| Temperature / humidity | |

Re-inspect on the schedule in [SAFETY.md](SAFETY.md) "Before loading"
(1 hour through annually). Unload immediately for movement, noise, cracking,
whitening, wall damage, ridge formation, bracket contact, permanent
deflection, connection slip, or any loose ornament.

## Stage 9 — Disassembly and service

The finish system is designed to come off without damage. Removal order is
the reverse of installation, and no step may require removing a part under
load — unload the shelf first, always.

1. Groin-vault soffit (unscrew).
2. Endcaps and the corner pilaster slip-cover (release their silicone dots).
3. Keystones (release the two dots on their fixed half).
4. Fascia halves, trained back toward the corner one at a time, each with its
   overlay still attached.
5. Rear curbs (unscrew; the tiles keep their drilled holes for reinstall).
6. Top tiles (floss under the single dot; never pry).

Quarantine and replace any part that cracked, whitened, or warped in
service. Moving the shelf itself: unload completely and move both arms as one
coupled assembly to a single new common elevation, then repeat Stage 8.

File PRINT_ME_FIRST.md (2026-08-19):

# Print me first — Triadic Palatine Order r5

> **Frozen earlier revisions:** the R6–R11 trees under `development/` are historical records governed by their own gate documents, including the R11 print hold, single-use permit protocol, and **0 kg / 0 lb** rating. Nothing in those trees authorizes printing, drilling, installation, or load, and nothing in this r5 document authorizes an R11 job. See [development/r11/README.md](development/r11/README.md), the [R11 print hold](development/r11/PRINT_FIRST.md), the [Gate A-left v2 control overlay](development/r11_print_v2/PRINT_GATE_A_LEFT.md), and the [append-only physical record](development/r11_physical/PHYSICAL_RECORD.md).

The files in `generated/model_only_3mf/` contain geometry only. They deliberately contain **no embedded G-code** because the printer, nozzle, build plate, Bambu Studio version, and exact PETG product remain unconfirmed.

All generated printable components are black PETG finish, ornament, modest item-retention, or fit-check parts. The plywood, steel angles, brackets, standards, locks, alignment hardware, and wall fasteners are nonprinted structural components and are not contained in any 3MF.

## Do not print the full set yet

[`MODEL_ONLY_STORY_CORNER_TRIADIC_PALATINE_FULL_PRINT_SET.3mf`](generated/model_only_3mf/MODEL_ONLY_STORY_CORNER_TRIADIC_PALATINE_FULL_PRINT_SET.3mf) contains **101 exact-quantity objects** on a virtual catalog canvas: 98 installed pieces and three print-first test objects. It is not a real plate layout. Its nominal geometry estimate is 2.45 kg packaged PETG and 2.42 kg installed PETG, excluding slicer-dependent purge, supports, failures, spares, fasteners, plywood, and steel.

Before production, confirm:

- both limiting wall lengths, wall bow, and clearances across the full adjustment zone;
- the included corner angle and a full-size corner template;
- the installed shelf-back offset separately on the long and short walls;
- the actual perpendicular-bracket envelope and the groin-vault clearance after support locations are verified;
- the 8 in depth and 168.056 mm Palatine fascia envelope against doors, trim, outlets, people, and bins;
- verified framing or purpose-installed blocking at every support line;
- exact printer model, nozzle diameter and material, build plate, and Bambu Studio version;
- black PETG manufacturer/product line, an appropriate preset, and dry filament;
- the exact removable silicone products, captured fascia-channel fit, rear-curb and groin-vault screws, removal method, and underside clearance below every proposed finish fastener.

Never send or reuse G-code prepared for another printer, nozzle, plate, filament, or design revision.

## First-print and fit sequence

1. Print [`MODEL_ONLY_PRINT_FIRST_CornerFitGauge.3mf`](generated/model_only_3mf/MODEL_ONLY_PRINT_FIRST_CornerFitGauge.3mf) with the confirmed setup.
2. Compare it with the real corner and a full-size cardboard or hardboard template. The configured square-deck gate is **±0.25°**, and the remaining nominal plywood-joint clearance must be at least **0.6 mm**. The full-size template is mandatory even when the small gauge fits.
3. Measure the shelf-back offset separately on both walls. Do not substitute the catalog standard projection for either installed measurement.
4. Obtain the actual 23/32 in plywood and 1 x 1 x 1/8 in steel angle. Measure the completed front stack.
5. Print [`MODEL_ONLY_PRINT_FIRST_FasciaFitCoupon.3mf`](generated/model_only_3mf/MODEL_ONLY_PRINT_FIRST_FasciaFitCoupon.3mf) and fit it to a real plywood/angle scrap **with a printed 2.0 mm top-tile sample in place**. The nominal 46.256 mm opening includes plywood, the 25.4 mm angle leg, the tile, and 0.6 mm clearance. It must slide without splitting, binding, lifting the tile, or excessive rattle.
6. Print [`MODEL_ONLY_PRINT_FIRST_PalatineDetailCoupon.3mf`](generated/model_only_3mf/MODEL_ONLY_PRINT_FIRST_PalatineDetailCoupon.3mf) face-up. Approve the 2.4 mm archivolt shadow reveal, 3:4:5 void, flutes, pier base/capital relief, nine dentils, three triglyph groups, three cornice orders, central patera, bridge quality, edge finish, and removability before printing ornate production parts.
   Compare it with the [nominal Palatine elevation](generated/palatine_elevation.svg), whose stations, counts, and dimensions are exact while its displayed arch curves are schematic. It is not a structural drawing or proof of printer fit.
7. Coupon-test the selected neutral-cure silicone on printed PETG, sealed plywood, and the actual coated steel wherever it will touch. Verify captured-channel fit on the complete fascia stack, and test the selected curb and groin-vault screws in representative plywood with safe underside clearance. Do not drill or notch the continuous steel angle for fascia retention. Attachment prevents loose trim only; it receives no shelf-load credit.
8. If any gauge, coupon, or attachment test fails, update the measured configuration or clearance, rebuild everything, and repeat. Do not selectively scale a fitted part in the slicer.
9. Print and dry-fit one left and one right arcade/fascia half for each arm, one matching entablature overlay, one keystone, one top center, one top end, one corner quadrant, both arm-specific rear-curb ends, the 172.6 mm corner-side curb, the 30 mm corner replacement, the full-height corner pilaster, one endcap, and the groin-vault soffit.
10. Dry-assemble the PETG only on scrap or on the **unloaded, independently supported** plywood-and-steel L. Verify every 0.6 mm seam, the 1.0 mm return-tile overhang, full upper/lower fascia capture without binding, the required lateral assembly order, no rear-curb overlap, a floating keystone/pilaster leg, flush outer caps, and at least 10 mm groin-vault clearance from the nearest verified bracket plane.
11. Only after all checks pass should the remaining production quantities be arranged and sliced.

## Current nominal production counts

| PETG part family | 3 ft return | 5 ft through / corner | Shared / test | Total |
|---|---:|---:|---:|---:|
| Universal center top tile | 6 | 14 | — | 20 |
| Square-mating corner quadrant | — | 4 | — | 4 |
| Shared parametric top end | 4 | 4 | — | 8 |
| Palatine arcade/fascia left half | 3 | 6 | — | 9 |
| Palatine arcade/fascia right half | 3 | 6 | — | 9 |
| Removable Palatine entablature overlay | 6 | 12 | — | 18 |
| Universal center rear curb | 3 | 8 | — | 11 |
| Arm-specific rear-curb end | 2 | 2 | — | 4 |
| Through-owned corner-side rear curb | — | 1 | — | 1 |
| Palatine keystone seam cover | 3 | 6 | — | 9 |
| Palatine full-height outer endcap | 1 | 1 | — | 2 |
| Palatine re-entrant corner pilaster | — | — | 1 | 1 |
| Palatine groin-vault corner soffit | — | 1 | — | 1 |
| Rear-curb fitted corner replacement | — | — | 1 | 1 |
| Corner gauge + fascia coupon + Palatine coupon | — | — | 3 | 3 |
| **Total** |  |  |  | **101** |

The installed set is 98 objects; the gauge and two coupons are not installed.

## Nominal module facts

- Top centers: 151.8 x 101.3 x 2.0 mm; shared top ends: 116.081 x 101.3 x 2.0 mm.
- Corner quadrants: four identical 101.3 x 101.3 x 2.0 mm parts.
- Short-arm arcade halves: 113.994 x 168.056 x 29.0 mm, three left and three right, resolving three bays.
- Long-arm arcade halves: 107.630 x 168.056 x 29.0 mm, six left and six right, resolving six bays.
- Entablature overlays: one per arcade half, 24 mm high and 3.2 mm overall relief thickness.
- Keystones: nine at 18 x 24 x 2.4 mm; retain each to one half and float it across the other.
- Through rear-curb ends: 126.481 mm; return rear-curb ends: 115.581 mm.
- Through-owned corner-side rear curb: 172.6 mm. It stops before the 1.6 mm plywood joint.
- Full-height endcaps and corner pilaster: 168.056 mm tall.
- Groin-vault soffit: 42 mm square and nominally 18.519 mm from the nearest support plane; the configured minimum is 10 mm.

## Attachment and installed stack

Every finish piece attaches with qualified removable products only. The full
build sequence, silicone dot counts, curb drilling procedure, and installed
z-stack are owned by [ASSEMBLY.md](ASSEMBLY.md) (with the geometry defined in
[ENGINEERING_DESIGN.md](ENGINEERING_DESIGN.md) section 6 and the policy in
section 8). Never drill or notch the continuous steel angle, bridge a 0.6 mm
seam or the plywood joint, or clamp PETG rigidly.

## Saved-orientation rule

All r5 meshes fit the declared 180 x 180 x 180 mm minimum model envelope in their generated orientation. The largest arcade halves are 168.056 mm tall, leaving little room for arbitrary rotation or an oversized brim on a 180 mm plate. Use the saved orientation as the starting point, print the Palatine overlay/detail faces up, and re-run arrangement checks on the confirmed printer. The arcade halves are saved front-face-down so their channel flanges grow upward and need no support material. No supports, layer heights, temperatures, speeds, or machine profiles are embedded in the model-only 3MFs.

## Plate-fit and batching cautions for a 180 mm printer

- The 168.056 mm plate footprint of each arcade half, endcap, and corner pilaster — and the 172.6 mm corner-side curb — leaves roughly 6 mm of plate margin per side. Keep any brim to about 5 mm or less on these parts, or place the long curbs diagonally; confirm the slicer's exclusion zones before slicing.
- The 2.0 mm top tiles are large thin PETG flats (up to 151.8 x 101.3 mm) and are the most warp-prone parts in the set. Use a clean, adhesion-checked plate, avoid drafts, and plan a small number of spare tiles — 20 centers are needed and a single lifted corner scraps the tile.
- The full set is roughly a hundred objects across many plates on a 180 mm printer. Batch like parts together (tiles with tiles, halves one or two per plate), print one part from each family for the step-9 dry fit before committing to production quantities, and track finished counts against the production table above.

## Production boundary

The arches, piers, vault, fascia, curbs, and tiles are ornate PETG finish pieces—not structural Roman masonry and not hidden printed brackets. Do not print substitutes for plywood, steel angle, standards, brackets, locks, blocking, or structural fasteners. The selection targets remain untested and are not load ratings.

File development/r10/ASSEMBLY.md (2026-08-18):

# R10 one-bay tabletop assembly

> **Qualification article only — rated load 0 kg / 0 lb.** This is one actual
> Lincoln-log shelf cell, not a scale model, but it is not a full-wall release.
> Assemble it only on a flat tabletop. Do not drill the closet wall, attach any
> part to a wall, place stored load on it, or infer a load rating from a good
> fit. Nothing in this document grants permission to start a printer.

## What this assembly proves

The core assembly checks the real R10 interfaces for one 254 mm planning bay:

- two printed supports;
- two regular cassette halves;
- three independent splice logs at the rear, center, and front;
- three independent log retainers with integrated flush access caps; and
- two bay-local support retainers with positive reversible walk-out stops.

These are the same structural article types intended for the first shelf. A
passing tabletop assembly qualifies only their fit, handling, and repeatable
dry assembly. It does not qualify the six-bay wall, wall connection, PETG
creep, proof load, cable clearance in the room, or any allowable load.

The S0 cable-bookend set is a separate four-article furniture-interface gate.
Its fused receiver, blanks, and comb/hook have zero structural or shelf-load
credit. Do not add the S0 bookend as a third support in the one-bay assembly.

The 16-article qualification bundle and the eventual 70-article first-wall
count answer different questions. The bundle contains 12 core one-bay articles
plus four S0 cable-gate articles. The complete 61.25 in first-wall topology is
seven supports (with the fused S0 bookend occupying one of those seven support
positions), 12 cassette halves, 18 splice logs, 18 flush-capped log retainers,
12 bay-local support retainers, two flush blanks, and one comb/hook: exactly
**70 printed articles**. The ordinary left support and fused S0 bookend are
both present in the qualification bundle so each interface can be isolated;
they are not both installed at S0 in the eventual wall.

## Exact individual-model inventory

Use only the individual, model-only 3MF files from the generated qualification
bundle's `individual_model_only_3mf/` directory. Every row below is quantity
one. Never print the combined catalog.

| Role | Exact file |
|---|---|
| Left support | `MODEL_ONLY_r10_one_bay_left_support.3mf` |
| Right support | `MODEL_ONLY_r10_one_bay_right_support.3mf` |
| Left cassette half | `MODEL_ONLY_r10_one_bay_left_cassette_half.3mf` |
| Right cassette half | `MODEL_ONLY_r10_one_bay_right_cassette_half.3mf` |
| Rear splice log | `MODEL_ONLY_r10_one_bay_rear_splice_log.3mf` |
| Center splice log | `MODEL_ONLY_r10_one_bay_center_splice_log.3mf` |
| Front splice log | `MODEL_ONLY_r10_one_bay_front_splice_log.3mf` |
| Rear log retainer with flush cap | `MODEL_ONLY_r10_one_bay_rear_log_retainer.3mf` |
| Center log retainer with flush cap | `MODEL_ONLY_r10_one_bay_center_log_retainer.3mf` |
| Front log retainer with flush cap | `MODEL_ONLY_r10_one_bay_front_log_retainer.3mf` |
| Left support retainer | `MODEL_ONLY_r10_one_bay_left_support_retainer.3mf` |
| Right support retainer | `MODEL_ONLY_r10_one_bay_right_support_retainer.3mf` |
| Fused far-left S0 cable bookend candidate | `MODEL_ONLY_r10_first_wall_s0_inward_two_socket_additive_bookend_candidate.3mf` |
| Socket 0 flush blank | `MODEL_ONLY_r10_first_wall_socket_0_flush_blank.3mf` |
| Socket 1 flush blank | `MODEL_ONLY_r10_first_wall_socket_1_flush_blank.3mf` |
| Multi-cable comb/hook | `MODEL_ONLY_r10_first_wall_multi_cable_comb_hook.3mf` |

Do not mirror, scale, rename, repair, combine, or substitute any article. The
left/right and rear/center/front identities are functional.

## Before touching the parts

Prepare a clean, padded, flat table, digital calipers, a verified square, a
straightedge, feeler gauges, a soft brush, the print/inspection record from
`PRINT_FIRST.md`, and a camera. No adhesive, lubricant, heat gun, hammer,
mallet, pry bar, clamp, or power tool is permitted.

Confirm all of the following before assembly:

1. Every part ID, slicer job, PETG spool lot, drying record, scale, orientation,
   and photo ID is traceable.
2. Every part cooled before removal and passed the inspection table in
   `PRINT_FIRST.md`.
3. Only the outer brim was removed. No dovetail, channel, shoulder, keyway,
   retainer, support land, or printed bore was sanded, filed, reamed, drilled,
   heated, or forced to fit.
4. There is no crack, layer split, warp, under-extrusion, contamination,
   whitening, missing feature, slicer repair, or loose fragment.
5. The three logs and matching retainers remain labeled rear, center, and
   front. The two cassette hands and two support-retainer hands remain labeled.

If a part fails any check, quarantine it and record the failure. Do not rescue
the test by modifying the interface.

## Learn the directions

- **Rear** is the wall side of the eventual shelf; **front** is the room side.
- **Left** and **right** are the authored file hands, viewed from the room.
- **Toward the bay** means inward between the two supports: rightward at the
  left support and leftward at the right support.
- **Away from the bay** is the reverse: leftward at the left support and
  rightward at the right support.

The support retainers are bayonet bars. Each has a narrow shaft, a rear dog,
and a front handle. They insert from the shelf front, rear-dog first, then move
sideways 2.4 mm. They are retention-only parts; the cassette must bear directly
on the broad support capitals above them.

## Core one-bay assembly — exact authored order

Work dry and off the supports for Steps 1–3. Stop at the first resistance; a
correct motion is controlled and hand-operated, never hammered or twisted.

1. off the supports, slide the three independent dovetail logs into the left cassette half
2. with the right half absent, lower each independent retainer through the left-half top access into its exposed log notch
3. slide the right half over the logs and retainer ends so its closed top captures all three keys
4. place two printed supports at the 254 mm planning centers
5. lower the joined cassette onto its two 15.70 mm physical support contacts
6. at each cassette/support contact, insert its bay-local support retainer straight from the front and shift it 2.4 mm toward that bay to place its rear dog behind the positive shoulder; the integrated handle remains 4.0 mm proud for a hand grip
7. for disassembly shift each support retainer 2.4 mm away from its bay, grasp the 4.0 mm handle and pull it straight forward, lift the cassette clear of both lugs, then reverse the off-support slide

For a novice, Steps 1–7 mean:

1. Place the left cassette half on the padded table. Slide the rear, center, and
   front logs linearly into their matching channels until each positive body
   shoulder seats. Do not use a retainer to pull a log home.
2. Leave the right half off. Lower the matching independent retainer through
   each top access and into the exposed notch of its one log. The retainer's
   integrated cap must close that same access flush; there are no separate
   debris-cover pieces.
3. Keep all three keys seated. Align the right cassette half with the three
   exposed log/key ends, then slide it straight onto them. Its closed top traps
   the keys. Do not rock, twist, or clamp the halves together.
4. Set the supports upright on the table with their centers 254 mm apart and
   their broad capital lands level. This is a tabletop arrangement only; do
   not put screws through the three printed candidate bores.
5. Lower the joined cassette vertically until both ends have complete, direct
   contact on the 15.70 mm support half-lands. A retainer cannot compensate for
   a gap, rock, or partial bearing.
6. At the left support, insert the left support retainer straight from the
   front, rear-dog first, then shift it exactly 2.4 mm rightward into the bay.
   At the right support, insert the right retainer from the front and shift it
   exactly 2.4 mm leftward into the bay. Each rear dog must finish behind its
   positive shoulder while the front handle remains serviceable.
7. Verify that all three midpoint caps are flush, all positive log shoulders
   are seated, the 0.35 mm physical midpoint seam is not forced closed, both
   support retainers are in their shifted positions, both support lands bear
   fully, and the assembly is square and flat.

Do not place books, tools, test weights, or body weight on the bay. The only
permitted action here is gentle, unloaded fit cycling.

## Unloaded ten-cycle check

One cycle is a complete assembly and complete disassembly by the exact reverse
path. Do ten cycles and record every one in `PRINT_FIRST.md`.

To disassemble:

1. Shift the left support retainer 2.4 mm leftward, away from the bay, and pull
   it straight forward. Shift the right retainer 2.4 mm rightward and pull it
   straight forward.
2. Lift the joined cassette straight up until it clears both support lugs.
3. Move the supports aside. Slide the right cassette half straight off the
   three captured log/key ends.
4. Lift each log retainer vertically out through its left-half top access.
5. Slide the three logs straight out of the left half.
6. Inspect all shoulders, notches, caps, channels, dogs, handles, keyways,
   support lugs, and bearing lands before starting the next cycle.

Stop and fail the gate for force, cracking, whitening, shaving, growing dust,
progressive looseness, rocking, a proud cap, incomplete shoulder seating,
uncommanded key movement, a support retainer that bypasses its positive stop,
or damage that increases with cycling.

## Separate S0 cable-bookend service check

The fused two-socket receiver belongs only on first-wall support S0, the
far-left outer bookend. Both sockets face inward. Intermediate supports and the
inside-corner placeholder receive no cable receiver or peg.

Test on the padded table, separate from the structural one-bay assembly:

1. Inspect the additive receiver and its print ramp. Any receiver/root crack or
   separation fails the article.
2. Hold one flush blank at socket 0's upper entry. Move it straight inward
   through the 6 mm approach, then lower it exactly 8 mm into its gravity seat.
   Lift 8 mm and move straight outward to remove it. Never bend or snap it in.
3. Repeat ten cycles in socket 0 and ten in socket 1, one occupied socket at a
   time. Then repeat with the comb/hook, again one socket at a time.
4. After single-socket cycling passes, install a flush blank in every unused
   socket. The normal furniture state is two blanks, or one cable comb/hook and
   one blank.
5. Use representative loose cables only for later snag/handling observation.
   Never hang shelf-test mass, tools, or body weight from the comb/hook.

Passing this tabletop service path does not resolve the still-unmeasured door,
trim, outlet, plug, cord-loop, snag, or human-access envelopes.

## Wall material and hardware are reference-only at this gate

The one-bay tabletop test uses **no wall hardware**. No wall drilling or wall
installation is authorized. The candidate first-wall
schedule is documented in `MATERIALS_AND_HARDWARE.md` so it cannot be forgotten
or silently substituted:

- SUNLU standard black PETG, 1.75 mm, ASIN `B0D1KC72YP`;
- Bambu Lab A1 mini with a physical 0.4 mm nozzle and Textured PEI plate;
- GRK RSS Rugged Structural Screw, Climatek, 1/4 in x 3-1/2 in, T25, part
  `90306`: 21 candidates in one complete wall;
- one L.H. Dottie `FW14` 1/4 in USS zinc-plated flat washer per screw: 21
  candidates in one complete wall; and
- verified continuous solid-wood blocking, or an independently engineered
  equivalent, across every eventual screw axis.

After the field stack and fixture plan are reviewed, the controlled-lot plan
is 100 exact screws plus one 100-pack of FW14 washers: 12 for four support
fixtures, 21 for the mock wall/proof, 21 for fresh creep, 21 for a fresh
destructive wall, 21 quarantined for an eventual released installation, and
four spares. Never use fixture hardware in the closet.

Generic drywall or hollow-wall anchors receive no primary structural credit.
The three 7.0 mm printed bores per support are prototype candidates, not a
closet-wall drilling schedule. Do not procure qualification hardware until the
field stack and fixture plan are reviewed; never drill, install, tighten, or
load from this document. Continue only through the independent gates in
`LOAD_QUALIFICATION.md`.

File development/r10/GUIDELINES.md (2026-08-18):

# R10 design memory: never omit these rules

Use this as the short checklist before changing CAD, generators, tests,
documentation, slicing, or print order. The detailed controlling contract is
[`DESIGN_REQUIREMENTS.md`](DESIGN_REQUIREMENTS.md). If a proposed change
conflicts with either file, stop and resolve the conflict explicitly; a chat
summary is not permission to drop a rule.

## Scope and safety

- First release candidate: lower shelf only, 61.25 in first wall, top at 68 in,
  152.4 mm projection.
- Outlet top is approximately 53.5 in; keep the faceplate, plugs, cords, and
  service screws usable.
- Current rating is **0 kg / 0 lb**. No wall drilling, installation, stored
  load, or production claim until every physical gate and independent review
  passes.
- The 45 kg distributed and 9 kg front-point values are qualification targets,
  never ratings. Measure finished dead mass and include its physical effect
  exactly once in service demand. At 1.5x proof, the installed shelf supplies
  `D`; add `0.5D` in a representative distributed pattern plus the factored
  external contents/point load. Never omit or double-count dead mass.

## Printed Lincoln-log structure

- Predominantly SUNLU PETG; no aluminum or steel shelf chassis. Metal is
  limited to the candidate wall screws and one washer per screw.
- Seven 31.75 mm-wide supports on exact 10 in centers create six independent
  bays. Do not remove an intermediate support for appearance.
- Each bay: two cassette halves, three captured PETG splice logs at rear /
  center / front, positive shoulders, and three independent one-log retainers.
- Each log retainer closes its own left-half top access with an integrated
  flush cap; a separate loose debris cover is forbidden. Use the true notched
  final-mesh midpoint section, never the gross 20 x 24 mm rectangle, in every
  geometry comparison.
- Each cassette/support contact gets its own bay-local front-inserted retainer.
  Insert straight, then shift exactly 2.4 mm toward that bay so the rear dog
  sits behind its positive shoulder; keep the authored front paddle 4.0 mm
  proud so it remains hand-removable. All 30 keys are retention-only;
  uninterrupted lands and shoulders carry gravity. Interior left/right
  functions may never be shared; friction and snap receive no credit.
- Each cassette end bears directly on one broad support half-land. Locators,
  anti-lift retention, keys, friction, snaps, and adhesive receive no sustained
  vertical-load credit.
- A damaged bay must remain independently removable; no joint may unzip the
  full run.
- Preserve 0.35 mm midpoint, support-line, and endpoint seams. The fascia is
  visually continuous but physically segmented; zero-gap assembly is forbidden.
- Seven supports x three 7.0 mm authored candidate bores = 21 GRK RSS 90306
  candidates and 21 single L.H. Dottie FW14 washers in one wall. Bore drops
  below the shelf underside are 19.05 / 79.375 / 139.7 mm. Every washer bears
  on a full-solid 27.025 mm outer-diameter surface land; no counterbores. This
  is not a drilling schedule. After the field stack and fixture plan are
  reviewed, the controlled-lot plan is 100 exact screws and 100 FW14 washers:
  96 reserved across qualification plus possible final installation and four
  unallocated spares.
- All primary screws require verified continuous blocking or an independently
  engineered equivalent. Generic hollow-wall anchors receive no primary
  structural credit.
- The loose washer over PETG is outside ESR-2442, and current GRK documents
  conflict on nominal thread length. Received dimensions and independent
  connection review control; catalog assumptions do not.

## Form follows the load path

- Visual language: black PETG Roman aqueduct / Art-Deco arcade with stepped
  keystones and fascia.
- Intermediate visible corbel drop: **76.2 mm**. The complete **158.75 mm**
  structural wall strap remains hidden and may not be shortened.
- Outer-bookend visible emphasis: **120.65 mm**. Use it only at the far-left
  endpoint of this wall and the eventual far-right endpoint of the return wall.
- Roman recesses, curves, steps, and keystones are additive ornament and receive
  zero independent structural credit. Never thin a strap, compression web,
  chord, bearing land, cassette skin/web, dovetail, screw land, or washer land.

## Cable pegs: exact frozen interface

- The eventual L-shaped level has exactly **two outer cable bookends**: far-left
  through-wall endpoint and far-right return-wall endpoint.
- Each outer bookend has exactly one fused **two-socket** receiver. Both sockets
  face inward and use 0.4 mm clearance per face plus 8 mm service lift/drop.
- Rebuild and requalify that fusion on the R10 bookend dimensions; never paste
  the R9 attachment mesh onto the new structural core and call it inherited.
- Print two flush blanks and one multi-cable comb/hook for each active
  bookend. Blank unused
  sockets so the installation reads as normal furniture.
- The first-wall prototype activates only the far-left receiver.
- No cable rail, peg, receiver, or module belongs on an intermediate support,
  the through-side terminal/corner placeholder, or the inside corner.
- Cable parts receive **zero structural credit**.

## Print and release discipline

- Bambu Lab A1 mini, physical 0.4 mm nozzle, Textured PEI plate; SUNLU standard
  black PETG ASIN `B0D1KC72YP` with lot and drying record.
- `SUNLU PETG @BBL A1M 0.4 nozzle`; `0.20mm Strength @BBL A1M`; 6 walls,
  25% grid, 5 top / 3 bottom, Support Off, 5 mm outer brim, 0.1 mm gap.
- Authored orientation, 100% scale, one structural part per plate, Preview and
  first-layer checks. No auto-orient, auto-scale, casual mirroring, structural
  sanding/reaming, or silent slicer repair.
- Fail-fast order: actual midpoint interface articles -> one actual bay -> far-left cable set ->
  complete tabletop set -> sacrificial framed-wall mockup. Confirm the plate is
  empty and ask the operator before every printer start.
- First measure the maximum service temperature. Proof, 1000-hour creep at that
  measured maximum plus 5 degrees C, recovery, destructive testing, and
  independent review are all mandatory. A pass at one gate never creates a
  rating.

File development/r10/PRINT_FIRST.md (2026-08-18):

# R10 print-first handoff — fail fast

> **Stop before every physical print.** Slicing and Preview inspection do not
> authorize printer motion. A fresh, explicit human “yes, print this job” is
> required after the exact plate, material mapping, settings, Preview, and
> printer state are confirmed. Permission from an earlier job does not carry
> forward. This rule applies even when a retry appears unchanged.

This sequence produces one actual 254 mm Lincoln-log shelf cell and the
separate first-wall S0 cable candidate as quickly as responsible qualification
allows. It is not a miniature or a cosmetic mockup. It is also not a complete
six-bay production set, a wall-installable release, a drilling schedule, or a
load-rated shelf. Current rating: **0 kg / 0 lb**.

Inventory context: this qualification bundle contains 16 articles—12 for one
actual bay and four for the separate S0 cable gate. A future complete first
wall contains exactly 70 printed articles: seven supports (including S0 as one
of the seven), 12 cassette halves, 18 splice logs, 18 integrated-flush-cap log
retainers, 12 bay-local support retainers, two flush blanks, and one comb/hook.
Do not mistake the qualification bundle for authorization to print that set.

## 1. Build and verify the neutral bundle

From the repository root, generate the deterministic qualification bundle:

```sh
.venv/bin/python development/r10/generate_one_bay_qualification.py
```

The expected output directory is
`development/r10/generated/one_bay_qualification_v1/`. Generation creates
neutral STL and model-only 3MF geometry; it does not slice, send, or print.
The command refuses to replace an existing bundle.

Before opening a model, verify:

- `manifest.json`, `validation.json`, and `release_status.json` exist;
- `release_status.json` still says `print_authorized: false`,
  `wall_installation_authorized: false`, and `rated_load_kg: 0.0`;
- `individual_model_only_3mf/` contains the 16 files listed below; and
- no G-code, BG-code, toolpath, or embedded slicer profile is present.

Never print
`MODEL_ONLY_R10_ONE_BAY_QUALIFICATION_CATALOG_NOT_A_PRINT_PLATE.3mf`. It is an
off-plate inspection catalog, not an A1 mini plate.

## 2. Lock the printer, material, and process before each slice

For every individual job, confirm all of these fields rather than relying on a
previous plate:

| Field | Required value |
|---|---|
| Printer | Bambu Lab A1 mini |
| Physical nozzle | 0.4 mm |
| Plate | Textured PEI plate, clean and clear |
| Material | SUNLU standard black PETG, 1.75 mm, ASIN `B0D1KC72YP` |
| Project filament mapping | `SUNLU PETG @BBL A1M 0.4 nozzle` mapped to the physically loaded PETG |
| Process | `0.20mm Strength @BBL A1M` |
| Layer height | 0.20 mm |
| Walls | 6 |
| Infill | 25% grid |
| Top / bottom | 5 top layers / 3 bottom layers |
| Supports | Off |
| Brim | 5 mm outer brim, 0.1 mm brim-object gap |
| Scale | 100% in X, Y, and Z; millimetres; never auto-scale |
| Plate population | One named article per plate for this qualification |

Do not silently substitute Generic PETG, another spool, another nozzle,
another plate, another process, or a repaired/scaled mesh. Record the PETG lot,
drying cycle, ambient conditions, printer, plate, nozzle, profile revisions,
and every override.

For each file: import only that individual model-only 3MF, preserve its saved
orientation, slice, and inspect Preview layer by layer. Confirm the first layer
is continuous, every intended opening remains open, there is no floating
island, the slicer did not repair or resize the mesh, Support remains Off, and
the estimated material/time are recorded. Then stop at the final Send/Print
control and obtain fresh permission.

Let PETG and the plate cool before removal. Inspect the removed article and
clear the plate before preparing the next job. A print cancellation or failure
requires a new inspection, a newly sliced/reviewed job when anything changed,
and fresh permission before retrying.

## 3. Exact individual files and saved orientations

All paths below are inside `individual_model_only_3mf/`. Support is Off for
every article.

| Exact file | Authored orientation |
|---|---|
| `MODEL_ONLY_r10_one_bay_left_support.3mf` | `wall_face_down_rotated_45_degrees` |
| `MODEL_ONLY_r10_one_bay_right_support.3mf` | `wall_face_down_rotated_45_degrees` |
| `MODEL_ONLY_r10_one_bay_left_cassette_half.3mf` | `solid_support_end_diaphragm_on_plate` |
| `MODEL_ONLY_r10_one_bay_right_cassette_half.3mf` | `solid_support_end_diaphragm_on_plate` |
| `MODEL_ONLY_r10_one_bay_rear_splice_log.3mf` | `flat_dovetail_side_on_plate` |
| `MODEL_ONLY_r10_one_bay_center_splice_log.3mf` | `flat_dovetail_side_on_plate` |
| `MODEL_ONLY_r10_one_bay_front_splice_log.3mf` | `flat_dovetail_side_on_plate` |
| `MODEL_ONLY_r10_one_bay_rear_log_retainer.3mf` | `largest_flat_face_on_plate` |
| `MODEL_ONLY_r10_one_bay_center_log_retainer.3mf` | `largest_flat_face_on_plate` |
| `MODEL_ONLY_r10_one_bay_front_log_retainer.3mf` | `largest_flat_face_on_plate` |
| `MODEL_ONLY_r10_one_bay_left_support_retainer.3mf` | `largest_flat_face_on_plate` |
| `MODEL_ONLY_r10_one_bay_right_support_retainer.3mf` | `largest_flat_face_on_plate` |
| `MODEL_ONLY_r10_first_wall_s0_inward_two_socket_additive_bookend_candidate.3mf` | wall face down, rotated 45 degrees, additive receiver ramp upward |
| `MODEL_ONLY_r10_first_wall_socket_0_flush_blank.3mf` | local minimum-Z broad side on plate |
| `MODEL_ONLY_r10_first_wall_socket_1_flush_blank.3mf` | local minimum-Z broad side on plate |
| `MODEL_ONLY_r10_first_wall_multi_cable_comb_hook.3mf` | local minimum-Z broad side on plate |

Do not rotate a part merely to make the slicer warning disappear. Stop and
resolve the warning against the authored mesh and orientation.

## 4. Fastest responsible print order

The rule is simple: print only enough to expose the next expensive failure.
Each line is a separate plate and needs fresh permission.

### Gate A — midpoint Lincoln-log interface

1. `MODEL_ONLY_r10_one_bay_left_cassette_half.3mf`
2. `MODEL_ONLY_r10_one_bay_right_cassette_half.3mf`
3. `MODEL_ONLY_r10_one_bay_rear_splice_log.3mf`
4. `MODEL_ONLY_r10_one_bay_rear_log_retainer.3mf`

Assemble those four parts off the supports using Steps 1–3 of `ASSEMBLY.md`.
The log must reach its positive shoulder; the retainer must lower through the
left-half top access; its integrated cap must finish flush; and the right half
must slide on without force and capture the key. Perform ten gentle dry cycles.
Stop before printing duplicates if this gate fails.

### Gate B — one support-capture interface

5. `MODEL_ONLY_r10_one_bay_left_support_retainer.3mf`
6. `MODEL_ONLY_r10_one_bay_left_support.3mf`

Reuse the assembled cassette. Confirm broad, direct bearing on the support
capital. Insert the retainer straight from the front, rear-dog first, and shift
it exactly 2.4 mm toward the bay. Confirm the positive walk-out stop. To remove,
shift it 2.4 mm away from the bay and pull straight forward. Perform ten gentle
unloaded cycles. The retainer receives no gravity or bending credit.

### Gate C — complete one actual shelf cell

7. `MODEL_ONLY_r10_one_bay_right_support.3mf`
8. `MODEL_ONLY_r10_one_bay_center_splice_log.3mf`
9. `MODEL_ONLY_r10_one_bay_front_splice_log.3mf`
10. `MODEL_ONLY_r10_one_bay_center_log_retainer.3mf`
11. `MODEL_ONLY_r10_one_bay_front_log_retainer.3mf`
12. `MODEL_ONLY_r10_one_bay_right_support_retainer.3mf`

Now assemble all 12 core articles exactly as `ASSEMBLY.md` specifies. Verify
all three flush caps, both 2.4 mm bayonet captures, the 0.35 mm physical
midpoint seam, full bearing at both 15.70 mm contacts, flatness, squareness,
and ten complete unloaded assembly/disassembly cycles.

This is the first actual shelf cell. Passing it does not authorize a second
bay, the full first wall, wall hardware, drilling, installation, proof load,
creep load, stored load, or a load rating.

### Gate D — separate far-left S0 cable candidate

13. `MODEL_ONLY_r10_first_wall_socket_0_flush_blank.3mf`
14. `MODEL_ONLY_r10_first_wall_s0_inward_two_socket_additive_bookend_candidate.3mf`

Use the first blank to expose socket-fit failure before printing the remaining
modules. Test it in socket 0 and socket 1, one at a time: move straight inward
at the upper entry, lower exactly 8 mm, lift 8 mm, and move straight outward.
Complete ten cycles in each socket.

Only if both sockets pass:

15. `MODEL_ONLY_r10_first_wall_multi_cable_comb_hook.3mf`
16. `MODEL_ONLY_r10_first_wall_socket_1_flush_blank.3mf`

Cycle the comb/hook ten times in each socket, one socket at a time. Then verify
the two furniture states: both sockets flush-blanked, and one comb/hook plus one
blank. Cable parts receive zero shelf-load credit. Do not attach the bookend to
a wall and do not treat this test as room-clearance qualification.

## 5. First-article inspection record

Copy one row per physical article. “Pass” requires every cell to be complete.

| Job / file | Photo ID | Spool lot + dry record | 100% scale | Saved orientation | Support Off | Slice time / mass | Cooled before removal | Dimensional check | Defects / slicer warnings | Pass / fail |
|---|---|---|---|---|---|---|---|---|---|---|
|  |  |  |  |  |  |  |  |  |  |  |
|  |  |  |  |  |  |  |  |  |  |  |
|  |  |  |  |  |  |  |  |  |  |  |
|  |  |  |  |  |  |  |  |  |  |  |

At minimum, inspect for warp, cracks, layer separation, under-extrusion,
contamination, whitening, missing features, first-layer damage, dimensional
drift, proud flush caps, blocked channels/keyways, bore damage, and loose
fragments. Record measurements before any fit cycle.

## 6. One-bay unloaded cycling record

Use one row for each complete assemble/disassemble cycle. Do not add load.

| Cycle | Three shoulders fully seated | Three integrated caps flush | Right-half slide by hand | Left support key inserted + 2.4 mm toward bay | Right support key inserted + 2.4 mm toward bay | Both reverse paths clean | Dust / whitening / cracks / looseness | Pass / fail | Photo ID |
|---:|---|---|---|---|---|---|---|---|---|
| 1 |  |  |  |  |  |  |  |  |  |
| 2 |  |  |  |  |  |  |  |  |  |
| 3 |  |  |  |  |  |  |  |  |  |
| 4 |  |  |  |  |  |  |  |  |  |
| 5 |  |  |  |  |  |  |  |  |  |
| 6 |  |  |  |  |  |  |  |  |  |
| 7 |  |  |  |  |  |  |  |  |  |
| 8 |  |  |  |  |  |  |  |  |  |
| 9 |  |  |  |  |  |  |  |  |  |
| 10 |  |  |  |  |  |  |  |  |  |

## 7. Cable-module cycling record

Each module must complete ten cycles in each socket. Keep the other socket
empty during its first qualification. One cycle is straight inward at the
upper entry, 8 mm down, 8 mm up, and straight outward.

| Article | Socket | Cycles completed | Gravity seat complete | Reverse path clean | Bind / wear / damage | Pass / fail | Photo ID |
|---|---:|---:|---|---|---|---|---|
| Socket 0 flush blank | 0 |  |  |  |  |  |  |
| Socket 0 flush blank | 1 |  |  |  |  |  |  |
| Multi-cable comb/hook | 0 |  |  |  |  |  |  |
| Multi-cable comb/hook | 1 |  |  |  |  |  |  |
| Socket 1 flush blank | 0 |  |  |  |  |  |  |
| Socket 1 flush blank | 1 |  |  |  |  |  |  |

## 8. Stop conditions and next boundary

Stop immediately for auto-scaling, the wrong filament mapping, a changed
orientation, Support enabled, a slicer repair, a floating island, print
cancellation, force, crack, whitening, shaving, progressive dust, looseness,
rocking, a proud cap, incomplete shoulder seating, blocked reverse motion, a
support retainer that bypasses its positive stop, or cable socket/root damage.

After all records pass, preserve the parts, project files, Preview screenshots,
slice reports, photos, and spool/process record. The next decision is a reviewed
qualification step under `LOAD_QUALIFICATION.md`, not automatic production.
No wall drilling, wall installation, hardware purchase, or load application is
authorized here. Exact future material and wall-hardware candidates remain in
`MATERIALS_AND_HARDWARE.md`.

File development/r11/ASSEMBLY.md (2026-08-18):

# R11 provisional dry tabletop assembly

> **Engineering-study sequence only — rated load 0 kg / 0 lb.** Do not use this
> document to drill a wall, install hardware, place load, or start a printer.
> R11 v1 hard-forces all four authorizations to false regardless of input or
> fit evidence.
> R11 generator integration must first publish the exact handed identities,
> motion arrows, positive stops, and saved meshes. If generated geometry differs
> from this invariant sequence, stop and revise the documents and/or geometry.

Use the [qualification-only exploded bay and first-wall topology diagram](visuals/r11_first_outer_bay_exploded_and_wall_topology.svg)
as an orientation aid for this provisional tabletop sequence. The generated
assembly map and saved geometry remain controlling; the diagram releases no
print, drilling coordinate, installation, test load, or stored load.

## What this sequence is meant to prove

The first actual bay is intended to contain five printed articles:

- one authored left three-rib half-deck;
- one authored right three-rib half-deck;
- one positive removable bay keystone; and
- two adjacent supports.

The fit test asks whether the two large shelf members can cross-lap like
Lincoln logs, whether the joined bay can complete the generated
lower/slide/gravity-settle motion into broad direct support bearing, whether
the keystone blocks half-to-half X separation without carrying gravity or
support-capture duty, and whether every motion reverses by hand. It proves no wall connection,
long-term PETG behavior, complete-wall fit, or allowable load.

The complete first-wall **kit target** is 28 articles: seven supports, 12
half-decks, six keystones, two flush cable blanks, and one comb/hook. Only two
of the three supplied cable modules fit S0's two sockets, so the maximum
simultaneously installed count is 27. R10's separate splice logs and
support/log retainers are not part of this assembly.

## Do not assemble until the bundle supplies these facts

The generated manifest and assembly map must identify:

1. left/right hand and front/rear orientation for every half-deck;
2. terminal versus regular identity and owning bay—both halves of bay 0 and
   both halves of bay 5 are terminal, for four terminal halves at 162.175 mm;
   both halves of bays 1-4 are regular, for eight regular halves at
   154.325 mm;
3. which three rib faces overlap and the measured overlap/bearing lengths;
4. the exact off-support cross-lap motion;
5. the exact lower/slide/gravity-settle direction and travel at each support
   capture;
6. the keystone entry, seat, positive stop, grip, and reverse motion;
7. the support center and broad-bearing contact for each bay; and
8. disassembly clearance without moving an adjacent bay.

Do not guess a motion from a render or mirror one side in the slicer. Until
these generated facts and corresponding physical gates exist, this document is
a design plan rather than an executable installation guide.

## Prepare the unloaded work area

Use a clean, padded, verified-flat table, calipers, square, straightedge,
feeler gauges, soft brush, labels, camera, generated manifest, assembly map,
and completed print records from [PRINT_FIRST.md](PRINT_FIRST.md).

No adhesive, lubricant, heat gun, hammer, mallet, pry bar, clamp, power tool,
wall screw, washer, or test mass is permitted.

Confirm before touching two parts:

- every article ID, hand, source/mesh hash, PETG lot, drying record, scale,
  orientation, slice record, and photo is traceable;
- each article cooled before removal and passed dimensional/visual inspection;
- only the sacrificial outer brim was removed;
- no structural face, lap, rib, shoulder, capture, stop, bore, or washer land
  was sanded, filed, reamed, drilled, heated, bent, or forced; and
- there is no warp, crack, layer separation, under-extrusion, contamination,
  whitening, loose fragment, missing feature, or unreviewed slicer repair.

Quarantine and record any failed part. Do not rescue the fit by modifying it.

## Candidate one-bay Lincoln-log sequence

The invariant order is precise even though the generated left/right movement
directions remain a Gate-0 deliverable:

1. **Orient off the supports.** Place the authored left and right half-decks on
   the padded table with rear/front and top/bottom matching the generated map.
2. **Engage all three reciprocal laps.** Use the one linear/vertical motion
   shown by the map to interleave rear, center, and front integrated ribs. Move
   by hand until all broad lap faces and positive body shoulders seat. Preserve
   the authored midpoint seam; do not clamp it to zero.
3. **Check the joined deck.** Verify continuous top alignment, full three-rib
   engagement, no rock/twist, and no daylight at required bearing faces. Do not
   install the keystone to pull a structural gap closed.
4. **Place two supports.** Set the two manifest-matched supports upright on the
   table at the generated centers, capitals level and wall faces aligned. This
   is a tabletop arrangement; leave all three printed bores empty.
5. **Lower over the fixed lugs.** Hold the joined bay 2.0 mm above its final
   seat so its pockets clear the fixed lug heads, then lower onto the generated
   approach lands. Do not force past a lug.
6. **Slide and gravity-settle into positive capture.** Slide the joined bay
   32.0 mm wallward, then let it settle 2.0 mm into the higher terminal pockets
   behind the solid 8.4 mm roof/shoulder. Each end must retain at least the
   generated broad direct bearing target (initial candidate 15.70 mm). The
   motion must be hand-operated, reversible, and free of snap or friction
   dependence.
7. **Seat the bay keystone.** Insert the correct authored keystone through its
   labeled entry and move it to its positive seat. It blocks half-to-half X
   separation only; it may not prevent reversal from the support lugs, preload
   the laps, carry a support gap, or be credited with support-capture,
   gravity, or bending capacity.
8. **Inspect.** Confirm three full cross-laps, both broad support contacts,
   both capture stops, the physical seam, square/flat geometry, a serviceable
   keystone grip, and no contact with an adjacent-bay envelope.

If the physical geometry cannot follow those eight actions without force or an
extra loose piece, the integral capture concept has failed. Revise the R11
architecture and counts; do not add hidden hardware ad hoc.

## Exact reverse principle

Disassembly must reverse one bay without disturbing another:

1. remove the bay keystone by its authored hand motion;
2. lift the joined bay 2.0 mm clear of both terminal-pocket shoulders;
3. slide 32.0 mm outward until both fixed lug heads clear their paths;
4. lift vertically clear of both support capitals;
5. move the supports aside only in the isolated one-bay tabletop test;
6. reverse the authored three-rib cross-lap motion to separate the halves; and
7. inspect every lap, shoulder, skin, rib, capture, stop, land, and keystone
   before the next cycle.

Never twist, rock, pry, or use the keystone as a disassembly lever.

## Ten-cycle unloaded acceptance

Perform ten complete assembly/disassembly cycles and record them in
[PRINT_FIRST.md](PRINT_FIRST.md). Stop for force, shaving, accumulating PETG
dust, whitening, crack, progressive looseness, blocked movement, proud or
uncommanded keystone, incomplete lap shoulder, capture-stop bypass, partial
support bearing, rocking, twist, permanent set, or damage that grows with
cycling.

No books, tools, test weights, body weight, or cable-hook mass are permitted.

## Complete first-wall tabletop target

Only after the one-bay and cable fit gates pass, arrange the seven supports on
a flat reference surface at these ideal first-wall centers:

```text
S0    15.875 mm
S1   269.875 mm
S2   523.875 mm
S3   777.875 mm
S4  1031.875 mm
S5  1285.875 mm
S6  1539.875 mm
```

Assemble one bay at a time by the same invariant sequence. Keep all six cells
independent. The finished tabletop study must show:

- six 254 mm planning pitches and support faces at the 0 / 1555.75 mm ideal
  wall endpoints before field-clearance adjustment;
- 12 manifest-correct half-decks and six independently removable keystones;
- direct broad bearing at every support contact;
- authored 0.35 mm candidate seams, without forced zero-gap closure;
- flat rear/front edges and top surface within reviewer-defined tolerances;
- removal/reinstallation of each bay without releasing its neighbor; and
- S0 as the only first-wall cable receiver.

The tabletop uses exactly two installed cable modules at once. Store the third
supplied module off the shelf; the normal states are two blanks, or one blank
plus one comb/hook.

This remains an unloaded tabletop check. Do not put the 21 candidate screws
through the supports.

## S0 cable-module service sequence

Test the cable interface separately from structural fit:

1. Inspect the fused S0 receiver/root; any separation or crack fails S0.
2. At a socket's upper entry, move one blank straight inward through the
   authored approach, then lower exactly 8 mm to its gravity seat.
3. Lift 8 mm and move straight outward. Repeat ten times in each socket, one
   occupied socket at a time.
4. Repeat with the comb/hook, then verify both normal furniture states: two
   blanks, or one blank plus one comb/hook.
5. Use representative loose cables only for later snag/clearance observation.

Do not bend or snap a module into place. Intermediate supports and the future
inside corner receive no module. Cable parts receive zero structural credit.

## Boundary after a fit pass

Preserve all parts, measurements, source/mesh/slice records, photos, and cycle
logs. A fit pass advances only to a reviewed fixture decision under
[LOAD_QUALIFICATION.md](LOAD_QUALIFICATION.md). It does not authorize printing
the remainder automatically, hardware procurement, wall drilling,
installation, test load, stored load, or a rating.

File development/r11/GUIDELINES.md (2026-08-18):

# R11 design memory — check before every change

Use this checklist before editing CAD, generators, tests, documentation,
packing, slicing, or print order. The detailed controlling contract is
[DESIGN_REQUIREMENTS.md](DESIGN_REQUIREMENTS.md).

## Status and scope

- **0 kg / 0 lb; engineering study only.** R11 v1 hard-forces print,
  drilling-coordinate release, installation, test load, stored load, and
  public capacity claim to false regardless of supplied evidence.
- R11 is the reduced-part successor study. Keep
  [R10 immutable](../r10/README.md); do not treat R10 evidence as an R11 pass.
- First milestone only: 1555.75 mm first wall, lower shelf top at 68 in,
  152.4 mm projection, outlet top approximately 53.5 in.
- Geometry remains provisional until generator integration, saved-mesh
  measurement, manifests, validation, slicing, and physical gates agree.

## Math and architecture

- `n = ceil((L - w) / p_max)`; supports `= n + 1`; pitch
  `p = (L - w) / n`; candidate screws `= 3(n + 1)`.
- First wall: `L=1555.75`, `w=31.75`, `p_max=254` -> six bays, seven supports,
  254 mm pitch, and 21 screw/FW14 pairs.
- Supplied kit: seven supports + 12 authored half-decks + six bay keystones +
  two blanks + one comb/hook = **28 articles**.
- At most **27 articles are simultaneously installed**: the 25
  structural/retention articles plus two modules in S0's two sockets. The third
  cable module remains off the shelf.
- Safe unbatched plan: **28 starts**, one article per plate. Unverified batched
  target: 7 support starts + 12 one-half-deck starts + 1 batched-keystone start
  + 1 batched-cable start = **21 starts**, subject to real packing and Preview.
  Batching changes starts only, never kit count, installed state, identities,
  BOM, or qualification scope.
- Bay 0 and bay 5 each use terminal left and right halves: **four terminal
  halves at 162.175 mm**. Bays 1-4 use **eight regular halves at 154.325 mm**.
  R11 v1 refuses a one-bay wall.
- Keep all seven supports. Lowering part or start count may not increase pitch,
  remove redundancy, reduce bearing, or bypass blocking/obstacle rules.
- Each bay has two integrated three-rib half-decks, a 55 mm initial reciprocal
  cross-lap candidate, broad direct support bearing, and an integral reversible
  capture: lower with 2 mm lug-head clearance, slide 32 mm wallward, then
  gravity-settle 2 mm behind the solid 8.4 mm roof/shoulder. Reverse is lift 2,
  slide 32 outward, lift clear.
- The positive removable keystone blocks only half-to-half X separation. It
  receives zero support-capture, gravity, or bending credit.
- Broad faces and shoulders carry gravity. Keystone, friction, snap, glue,
  shallow locators, ornament, and cable parts receive zero sustained credit.
- No separate splice logs, log retainers, support-retainer bars, hidden metal
  beam, aluminum tube, or permanent adhesive.
- A bay must remain independently removable; no local action may unzip the run.
- Candidate floors: 15.70 mm support bearing, 0.35 mm seams, and true-net
  `I >= 8263.957 mm^4`, `Z >= 949.016 mm^3`. These are geometry comparisons,
  not capacity.

## Supports and hardware

- Full 158.75 mm wall strap; ordinary visible drop 76.2 mm; outer-bookend
  emphasis 120.65 mm only at the real outer endpoints.
- Three 7.0 mm candidate bores per support at 19.05 / 79.375 / 139.7 mm below
  the shelf underside, each with a full-solid 27.025 mm OD washer land.
- First-wall candidate: 21 GRK RSS Climatek 1/4 x 3-1/2 in T25 `90306` screws
  and exactly 21 L.H. Dottie `FW14` washers.
- No counterbores, countersinks, stacked washers, printed wall anchors, generic
  drywall anchors, freehand drilling, reaming, or crushed PETG.
- Every screw axis needs verified continuous blocking or an independently
  engineered equivalent. The loose-washer/PETG stack is outside ESR-2442 and
  requires its own reviewed fixture evidence.

## Appearance and cable features

- Black PETG Roman aqueduct / Art-Deco language; ornament is additive-only and
  receives no structural credit.
- Never thin skins, three load ribs, cross-laps, bearing/capture faces, support
  capitals, compression webs, straps, bores, or washer lands for appearance.
- Cable hardware exists only at the eventual two outer bookends. First wall
  activates only S0: one fused inward-facing two-socket receiver, 0.4 mm per
  face clearance, 8 mm service travel, two flush blanks, and one comb/hook.
- No cable receiver at intermediate supports or the inside corner. Blank every
  unused socket. Cable modules receive zero shelf-load credit.

## Print and release discipline

- A1 mini, physical 0.4 mm standard-flow nozzle, Textured PEI; SUNLU standard
  black PETG 1.75 mm ASIN `B0D1KC72YP`, recorded lot and drying cycle.
- `SUNLU PETG @BBL A1M 0.4 nozzle`; `0.20mm Strength @BBL A1M`; 0.20 mm,
  6 walls, 25% grid, 5 top / 3 bottom, Support Off, 5 mm outer brim, 0.1 mm gap.
- Authored orientation and 100% XYZ only. No auto-scale, auto-orient, casual
  mirror, silent repair, structural sanding/reaming, heat, lubricant, or force.
- R11 v1 always emits `print_authorized: false`,
  `drilling_coordinates_released: false`,
  `wall_installation_authorized: false`, `test_load_authorized: false`, and
  `rated_load_kg: 0.0`. No input or study-gate pass may change those values.
- A later print-capable revision would still require generator/bundle gates,
  an empty clean plate, exact Preview, and a **fresh explicit human yes** for
  that exact job. A prior yes never carries to a retry.
- A later print-capable revision must fail fast: generator/bundle -> actual
  cross-lap pair -> integral support capture -> one actual bay -> cable set ->
  full tabletop -> framed fixtures.
- No drilling/install/load until proof, 1000-hour elevated-temperature creep,
  recovery, destructive testing, and independent review all pass.

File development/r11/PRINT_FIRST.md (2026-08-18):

# R11 print-first plan — integration and fail-fast gates

> **Nothing in this document grants permission to start a printer.** R11 v1
> hard-forces `print_authorized: false`; a clear printer and human readiness do
> not override that boundary. If a later reviewed revision becomes
> print-capable, every physical job—including an unchanged retry—must stop
> after slicing and Preview for fresh explicit human permission.
> **Earlier permission never carries forward.**

R11 is currently a reduced-part development plan. It has no print-authorized
production bundle. The target is a 28-article supplied kit, at most 27 articles
simultaneously installed, 28 safe unbatched starts, and 21 target batched
starts. The 21 target remains unverified until generator integration, saved
artifacts, manifests, packing, slicing, and physical gates prove it. Current
rating is **0 kg / 0 lb**.

## Gate 0 — do not print before generator integration

An R11 neutral bundle must exist and pass all of these checks before opening a
model in Bambu Studio:

1. deterministic regeneration from the pinned R11 source revision;
2. normalized input/layout report showing 1555.75 mm wall, six bays, seven
   supports, 254 mm pitch, 28 kit articles, 27 maximum installed articles,
   28 safe unbatched starts, 21 target batched starts, and 21 hardware pairs;
3. manifest enumerating exactly the eight first-outer-bay qualification
   articles: S0 fused two-socket support, S1 ordinary support, bay-0 terminal
   left and right half-decks, bay-0 keystone, two separately identified
   blanks, and one comb/hook;
4. individual neutral STL and model-only 3MF files at 100% scale with authored
   orientations and hashes;
5. saved-mesh validation for manifold/topology, bounds, volume, minimum walls,
   cross-lap overlap, true-net section, direct support bearing, integral
   lower-2/slide-32/settle-2 support capture, terminal pockets and solid
   roof/shoulder, positive stops, and independent reverse motion;
6. printer-envelope validation including 5 mm brim, 0.1 mm gap, and 2 mm bed
   reserve;
7. one-article saved-envelope evidence for both supports and both terminal
   half-decks, plus individual qualification treatment for the keystone and
   all three modules; the six-wedge and three-module full-wall batch targets
   remain future plate-validation work and are not implied by this bundle;
8. documentation tests and cross-links; and
9. release status that still explicitly records
   `print_authorized: false`, `drilling_coordinates_released: false`,
   `wall_installation_authorized: false`, `test_load_authorized: false`, and
   `rated_load_kg: 0.0`.

Those flags are immutable in R11 v1: complete inputs, a valid bundle, a clean
Preview, or passed study gates may not flip them. Neutral generation may not
create or embed G-code, BG-code, a sliced toolpath, printer credentials, or a
print command. Do not substitute an R10 file, rename an R10 mesh, invent an
R11 filename, or print a combined inspection catalog.

## Exact slicer contract for every future R11 article

Confirm each row independently before each slice:

| Field | Required value |
|---|---|
| Printer | Bambu Lab A1 mini |
| Physical nozzle | 0.4 mm standard-flow |
| Plate | Textured PEI; empty, clean, cool, correctly seated |
| Material | SUNLU standard black PETG, 1.75 mm, ASIN `B0D1KC72YP`, recorded and dried |
| Project mapping | `SUNLU PETG @BBL A1M 0.4 nozzle` mapped to the physically loaded external PETG |
| Process | `0.20mm Strength @BBL A1M` |
| Layers | 0.20 mm; 6 walls; 25% grid; 5 top / 3 bottom |
| Support | Off |
| Brim | Outer only, 5 mm; 0.1 mm brim-object gap |
| Scale / units | 100% X/Y/Z; millimetres |
| Orientation | Authored saved orientation; never auto-orient or rotate to hide a warning |
| Structural plate population | One support or one half-deck only |

For the future six-keystone and three-cable-module batch plates, confirm every
part remains in its saved orientation, brims do not merge unexpectedly,
first-layer toolpaths remain separated, and a single failed article cannot
damage another. If not, use one article per plate and 28 starts. Batching
changes starts only; it never changes the 28-kit inventory, 27-installed
limit, identities, BOM, or qualification obligations.

Inspect Preview layer by layer. Confirm no detached island, unintended bridge,
blocked channel/capture, omitted wall, self-intersection repair, scale change,
or support toolpath. A slicer warning requires a written, layer-level
disposition against the saved mesh; clicking through it is not a disposition.

Record model hash, plate population, source revision, orientation, scale,
profiles, all overrides, time, mass, layer count, warnings, screenshots,
printer state, and human authorization. Then stop at the final Send/Print
control for fresh permission.

## Conditional fail-fast physical sequence for a later print-capable revision

Use the exact eight manifest identities listed in Gate 0. Do not invent
role-to-file mappings or substitute a regular half-deck for bay 0. Gate 0
passing in R11 v1 does not authorize these prints.

### Gate A — first actual reciprocal cross-lap

1. Print the actual bay-0 terminal left half-deck, one per plate.
2. Inspect and measure it before spending the next plate.
3. Print the actual bay-0 terminal right mate, one per plate.
4. On a padded tabletop, use only the generated authored motion to engage all
   three 55 mm candidate reciprocal cross-laps and positive shoulders.
5. Cycle the dry halves ten times. No support, wedge, or load is used here.

Fail for force, shaving, PETG dust, whitening, crack, warp, proud/misaligned
skin, incomplete broad-face contact, growing looseness, or inability to reverse
the authored motion. A failure blocks later prints.

### Gate B — positive bay keystone

3. Print one actual matching bay keystone. For fail-fast work this may be a
   one-article plate; the future one-plate/six-keystone production target does
   not override qualification order.
4. With the half-decks unloaded on the table, seat and remove the keystone by
   its generated motion ten times.

The keystone must prevent only half-to-half X separation while remaining
hand-removable. It may not retain either half against the fixed support lugs,
wedge structural faces into preload, carry a gap, depend on snap/friction, or
receive support-capture or vertical-load credit.

### Gate C — first integral support capture

5. Print one actual ordinary support, one per plate.
6. Engage one conforming half-deck end by the generated sequence: lower with
   2 mm clearance over the fixed lug heads, slide 32 mm wallward, then
   gravity-settle 2 mm into the higher terminal pocket behind the solid
   8.4 mm roof/shoulder. Reverse by lift 2 mm, slide 32 mm outward, then lift
   clear. Confirm direct bearing, every positive stop, and reversible hand
   removal for ten unloaded cycles.

Fail for incomplete bearing, rocking, stop bypass, interference, damage, forced
motion, or dependence on the future wall screw/washer connection.

### Gate D — one complete actual bay

7. Print the actual S0 fused two-socket support, one per plate; this is the
   second support for the outer terminal bay.
8. Assemble the two passing half-decks and passing keystone off the supports,
   then perform the complete generated lower-2/slide-32/settle-2 capture
   sequence at both broad contacts. The keystone locks half-to-half X
   separation only; it does not lock support capture.
9. Perform ten complete unloaded assembly/disassembly cycles and all
   dimensional checks in [ASSEMBLY.md](ASSEMBLY.md).

This is the first actual R11 bay, not a scale mockup. Passing it authorizes no
additional print automatically, no wall hardware, no drilling, no test load,
and no stored load.

### Gate E — S0 cable furniture interface

10. Inspect the already-passing S0 fused support after Gate D; do not print a
    duplicate.
11. Print socket-0's actual flush blank and cycle it ten times in each socket
    using 8 mm lift/drop.
12. Only if both sockets pass, print socket-1's actual blank and the actual
    comb/hook as separate qualification articles. Confirm both normal states:
    two blanks, or one blank plus one comb/hook.

Cable modules carry representative cables only and receive zero shelf-load
credit. Socket/root damage blocks the furniture interface.

### Gate F — complete tabletop first-wall set

Only after Gates A-E and a future full-wall generator reconciliation pass may
a reviewed decision release articles beyond the eight-article outer-bay
bundle. Reuse only conforming, undamaged articles. Do not print the whole wall
in advance. That later manifest must add the remaining five supports, eight
regular half-decks, two terminal half-decks for bay 5, and five bay keystones.

Verify the future kit and installed-state targets rather than assuming them:

- seven supports total;
- 12 half-decks total;
- six keystones total;
- two blanks and one comb/hook supplied; and
- exactly 28 kit articles, with exactly two cable modules occupying the two
  sockets and therefore no more than 27 articles installed at once.

Assemble dry on a flat reference surface. Verify all seven centers, six
independent bays, endpoint fit, flatness, direct bearing, independent removal,
outlet/trim/cable envelopes, and that one absent keystone cannot release an
adjacent bay. No wall screws or load at this gate.

## First-article record

| Job / manifest ID | Photo ID | Source + mesh hash | Spool lot / drying | 100% scale | Authored orientation | Support Off | Slice time / mass / layers | Warning disposition | Cooled before removal | Dimensions / defects | Pass / fail |
|---|---|---|---|---|---|---|---|---|---|---|---|
|  |  |  |  |  |  |  |  |  |  |  |  |

## Ten-cycle dry-fit record

| Cycle | Three cross-laps fully bearing | Positive shoulder seated | Lower-2 / slide-32 / settle-2 capture complete | Keystone locks X-separation only | Lift-2 / slide-32 / lift-clear reverse clean | Dust / whitening / crack / looseness | Pass / fail | Photo ID |
|---:|---|---|---|---|---|---|---|---|
| 1 |  |  |  |  |  |  |  |  |
| 2 |  |  |  |  |  |  |  |  |
| 3 |  |  |  |  |  |  |  |  |
| 4 |  |  |  |  |  |  |  |  |
| 5 |  |  |  |  |  |  |  |  |
| 6 |  |  |  |  |  |  |  |  |
| 7 |  |  |  |  |  |  |  |  |
| 8 |  |  |  |  |  |  |  |  |
| 9 |  |  |  |  |  |  |  |  |
| 10 |  |  |  |  |  |  |  |  |

## Immediate stop conditions

Stop for missing/changed generator artifacts, wrong material mapping, changed
orientation, non-100% scale, Support enabled, unexpected repair, floating
island, blocked interface, incomplete brim, printer/HMS error, occupied or
dirty plate, cancellation, force, crack, whitening, shaving, growing dust,
progressive looseness, incomplete bearing, capture-stop bypass, damaged
keystone, or cable socket/root damage.

Cool the plate before removal. After a cancellation, failure, setting change,
power cycle, reseat, or retry, inspect the machine and plate, re-slice/review as
needed, and obtain a new explicit permission. The next decision after fit gates
is a reviewed qualification step under
[LOAD_QUALIFICATION.md](LOAD_QUALIFICATION.md), never automatic production.

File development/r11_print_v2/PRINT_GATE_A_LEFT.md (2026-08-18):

# Gate A-left operator contract

1. Verify the frozen v1 bundle and the checked-in v2 static package.
2. Slice only `r11_bay0_left_terminal_integrated_half_deck`, quantity one.
   Use only Bambu Studio `02.07.01.62` with executable SHA-256
   `b022be6750898454803e9e07178b7c7446c0e5b4d148c593b4b56efde09ba281`.
   Trusted preparation and permit issuance rehash the installed 253,787,536-byte
   executable; the attempt field cannot self-attest this process identity.
3. Record every field required by `schemas/attempt_evidence.schema.json` in a
   JSON file outside the repository. Do not save project/profile/G-code data
   in Git. Export the final sliced plate externally and record its SHA-256 and
   byte count. Trusted code extracts the sole G-code member from that exact ZIP
   archive, derives its sole embedded config block, and requires the separately
   supplied G-code/config evidence to be byte-identical. Claimed unrelated
   payloads never establish a job. A re-slice is a different job even when only
   the estimate changes.
   The complete emitted config block is pinned by approved byte count and
   SHA-256, so any uncontrolled, custom-G-code, or inherited-setting drift also
   blocks the attempt even when the listed controlled values still look right.
   Run the trusted `prepare-evidence` command documented in `README.md` against
   the exact exported sliced plate. It creates a fresh external directory with
   the archive-derived G-code/config and all six approved profile proof files;
   never hand-author or edit those files.
   The external evidence manifest must list a canonical relative path, byte
   count, and SHA-256 for the project, sliced plate, G-code, G-code config,
   three native full-effective Bambu profile exports, their three deterministic
   canonical snapshots, and all eight screenshot evidence classes. Every
   component of every external path is opened with `openat`/`O_NOFOLLOW`; each
   regular file is read once and its exact bytes are used for both parsing and
   hashing. The strict profile parser rejects missing, unknown, duplicate, or
   changed controlled fields and cross-checks the emitted G-code config.
4. Pin the complete process: 250°C first/245°C other nozzle, 60°C bed,
   flow ratio 0.94, maximum volumetric speed 9 mm³/s, part fan 10–30%, and
   overhang fan 90%. Record the physical A1 mini's serial as SHA-256 only and
   bind its exact reviewed firmware/module map and 0.4 mm stainless nozzle.
   Any device, firmware, module, or nozzle-material change creates a new
   process candidate.
5. Review the exact plate, transform, effective settings, warning list, first
   layer, capture and cross-lap layers, final layers, and current printer and
   filament state. A screenshot field may bind a deterministic contact sheet
   or manifest when that evidence class needs multiple native captures. All
   eight evidence-class hashes must be pairwise distinct. Any unresolved
   warning blocks the attempt.
   Flat live-state fields cannot self-attest: bind the exact read-only printer
   telemetry snapshot, fresh human plate and nozzle observations, photographed
   physical spool-label evidence (including lot), and the dryer log/display to separate
   external files with SHA-256 and timestamps. Printer telemetry does not prove
   plate cleanliness/type, nozzle flow, spool lot, or drying; those remain
   blocked until their named physical/human evidence exists.
6. Require a structured drying record with `dried: true`, method, exactly
   50.0°C, 6.0–8.0 hours, and completion time. Confirm the spool/dryer accepts
   that lower-limit cycle. No exploratory/undried bypass may claim this gate.
7. Show the user the part identity/hash, settings, time, mass, layers, and
   warning dispositions. Ask exactly: **Start this exact one-piece Gate A-left
   qualification print now?**
8. Record only the exact lowercase response `yes` in an external
   fresh-permission JSON. Explicitly initialize the identity-bound ledger once,
   then issue the external permit. Only an in-process sender may atomically
   consume and use the same verified open content-addressed G-code descriptor.
   A later GUI path reopen is not authorized by this overlay.
9. A failed, cancelled, rejected, or ambiguous Send consumes the permit. For
   every retry: create a new attempt ID, re-slice to genuinely new G-code,
   re-review Preview, re-check live state, and ask again. A wrapper change around
   identical G-code remains permanently spent and is rejected.
10. Cool fully; remove without force; photograph, measure, and inspect. Hold the
   right half for a separate release.

This pathway never permits drilling, wall installation, load testing, stored
load, production, or the full wall. Rated load is 0 kg / 0 lb.

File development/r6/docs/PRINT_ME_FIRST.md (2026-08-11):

# Print me first — r6 gate card

> **STOP: Story Corner r6 is experimental, unrated, and not released for
> overhead use. There is no tested load rating. Production wall holes are
> blocked. Do not print the complete set, drill the wall, install the shelf, or
> place stored objects on it until every gate below is closed.**

Every shelf-body component is intended to be printed in the same qualified
black PETG system. The only nonprinted installed items are suitable metal
structural screws with integral heads or compatible metal washers into verified
wood studs or purpose-installed blocking. No printed wall anchor, primary
hollow-wall anchor, structural adhesive, or metal member hidden inside the
shelf body is part of r6.

## 1. Record the right gate before slicing

Isolated, non-wall fit/material coupons may be sliced before the wall survey is
complete. That narrow permission does not transfer to a wall-interface coupon,
X-corbel, full bay, one-level package, two-level package, drilling, installation,
or loading.

### Before any isolated non-wall coupon slice

Record these in [MEASUREMENT_WORKSHEET.md](MEASUREMENT_WORKSHEET.md) or the
retained local qualification record:

- r6 artifact/manifest identity and the exact non-wall print-first object and
  plate selected;
- exact printer model, firmware, nozzle diameter, and nozzle condition;
- build-plate type, usable build area, cleaning state, and condition;
- black-PETG manufacturer, product line, ASIN, color, lot/batch if available,
  exact spool, age, storage, and recorded drying procedure;
- Bambu Studio version, installed system-filament profile name, process name,
  and every candidate or per-plate override used;
- the local project/output path and the retained slice/settings-report path;
- who will supervise the print and the tested emergency-stop procedure: where
  to press Stop/Cancel and where the accessible power switch or disconnect is,
  without reaching into a moving or hot printer.

Mark wall geometry, framing, hardware, driver access, storage, target load, and
all structural/installation tests **OPEN / NOT MEASURED**. Do not leave them
blank in a way that could be mistaken for complete.

### Before a wall-interface, X-corbel, full-bay, or installation-set slice

Complete every preliminary record above, then also record:

- measured 3 ft and 5 ft wall geometry at both proposed shelf heights;
- corner angle, wall bow, ceiling bow, outlet/plug service envelope, and all
  trim or obstructions;
- verified stud or purpose-installed blocking centers, widths, material,
  thickness, and utility-clearance method;
- actual structural screw shank diameter, head/washer outside diameter, length,
  thread embedment, driver bit, and driver-access envelope;
- largest stored-item width, depth, loaded height, loaded weight, quantity, and
  total target contents load per level.

The intended local qualification setup is now confirmed as a **Bambu Lab A1
mini**, **0.4 mm nozzle**, **Bambu Textured PEI Plate**, and **SUNLU standard
black PETG 1.75 mm**, ASIN
[`B0D1KC72YP`](https://www.amazon.com/dp/B0D1KC72YP). Record the actual spool
lot/batch even if the retail listing does not show one. The listing says the
product is GRS-certified with at least 50% recycled content; do not disqualify
it for that reason, but do make every result specific to this ASIN, black
color, lot, spool, drying record, and saved profile.

An earlier reference 3MF and the current Bambu Studio workspace contain PLA
settings. **The current Studio PLA profile must not be reused, copied, or
edited into the PETG profile.** Select the installed Bambu Studio **system**
filament profile named exactly `SUNLU PETG @BBL A1M 0.4 nozzle` and verify
PETG—not PLA—before every slice. This starting profile is a system profile,
not a local user preset. This setup identifies the qualification hardware and
material; it does not prove that the profile, a part, or an installation is
physically qualified. r6 release files contain no G-code and remain
model-only.

## 2. Verify the artifact is what it claims to be

The canonical package IDs and model-only filenames are frozen in source, and
the current deterministic build emits and validates all five. A filename by
itself does not mean that a copied or rebuilt package matches the checked
manifest, and software validation does not establish physical qualification.
These files are software-model packages only. A passing package must
state `software_model_package_eligible: true`,
`physical_installation_qualified: false`, and
`production_release_eligible: false`. The qualification package is a specimen
model, not a successful qualification result. Accept only a generated manifest
whose ID and filename match this table exactly:

| Canonical package ID | Frozen model-only filename |
| --- | --- |
| `print_first_prototypes` | `MODEL_ONLY_R6_PRINT_FIRST_PROTOTYPES.3mf` |
| `unique_parts_catalog` | `MODEL_ONLY_R6_UNIQUE_PARTS_CATALOG.3mf` |
| `worst_case_one_bay_qualification` | `MODEL_ONLY_R6_WORST_CASE_ONE_BAY_QUALIFICATION.3mf` |
| `one_level_l` | `MODEL_ONLY_R6_ONE_LEVEL_L.3mf` |
| `two_level_full_project` | `MODEL_ONLY_R6_TWO_LEVEL_FULL_PROJECT.3mf` |

Never treat a development specimen, artist rendering, renamed file, or a
canonical filename without its matching validation evidence as a production
part or physically installable shelf.

The five files above are aggregate packages. The same checked artifact set
also contains exactly 49 individual one-part model-only 3MFs in
`generated/individual_model_only_3mf/`, paired one-for-one with the 49 STL
sources in `generated/stl/`. Each pair must retain the same basename, geometry
digest, bounds, triangle count, closed-solid audit, and manifest record.

Before printing any release candidate, verify that:

- the manifest identifies r6 and says `production_release_eligible: false`;
- every 3MF is model-only and contains no G-code or slicer command payload;
- all 49 STL / individual-3MF pairs are present in their documented generated
  directories and pass the exact pair audit;
- the validation report is for the same manifest and configuration digest;
- the parts schedule says 258 installed objects per level: 225 chassis,
  joinery, and retention objects plus 33 zero-credit ornament objects;
- the selected two-level schedule says 516 installed objects; coupons and
  spares are additional;
- no production X-corbel contains a wall-fastener bore until the real hardware
  and wall build-up have been measured and regenerated;
- every required part fits the confirmed build volume in its saved
  orientation;
- drawings and schedule agree with `3 + 6 = 9` bays, 7 + 4 supports, 18
  cassettes, and two independent levels.

## 3. Print qualification pieces first

Do not infer fit from nominal clearances.

The canonical print-first package contains eight development objects, but it
is still qualification-only and unsliced. For the first local campaign, print
only its **non-wall** coupon plates, one plate at a time. Keep
`R6_DEV_BLOCKED_WALL_SCREW_BEARING_COUPON_SOLID_NO_HOLE` disabled: it is a
solid no-hole boundary placeholder, not a coupon for the eventual screw. Do
not print a wall-screw bearing coupon, any X-corbel, or either full
installation package until the actual screw/head/washer, driver envelope,
finished-wall build-up, and verified framing have been recorded and the wall
interface has been regenerated.

The full eventual qualification sequence is to print, label, measure, and
retain:

1. the 0.2 / 0.3 / 0.4 / 0.5 mm clearance matrix and pin coupons;
2. the crown-bridge insertion and accessible-pin coupon;
3. the wall-screw bearing coupon regenerated around the actual screw and metal
   head/washer;
4. one two-skin cassette with its fixed/floating seam, integral-cap locator,
   key keeper, and visible-front crown-tie interfaces;
5. one complete X-corbel with its integral full-width bearing cap, cassette
   locks, and driver-access mockup;
6. the ornament connector coupons, which remain outside the 33 installed
   ornament pieces;
7. one complete worst-case 241.935 mm through-arm bay on a sacrificial wall
   mockup reproducing the real finish, verified framing, and fastener.

Reject any coupon with split layers, poor fusion, severe stringing inside a
receiver, distorted pins, whitening, cracks, nonrepeatable engagement, hidden
tool access, or a fit that requires hammering. Tune one centralized clearance
parameter and regenerate; do not scale a structural part in the slicer.

## 4. Slicing rules until a tested profile exists

No universal production profile is supplied. PETG brand, drying, nozzle,
machine, plate, temperature, cooling, line width, layer height, perimeter
count, seam placement, and speed materially affect the result. Start from the
confirmed PETG manufacturer's guidance and the printer manufacturer's profile,
then qualify the coupons and full bay with the exact settings you intend to
use. Record the slicer version and export a settings report.

### Candidate A1 mini / SUNLU PETG qualification profile

Use the installed Bambu Studio system profile `SUNLU PETG @BBL A1M 0.4
nozzle`. SUNLU does not currently publish an official standard-PETG A1 mini
download in its own preset selector, so the installed Bambu system profile and
these values are a project-specific starting point to calibrate, not a
SUNLU-certified A1 mini download:

| Bambu Studio field | Candidate value |
| --- | --- |
| Printer | `Bambu Lab A1 mini 0.4 nozzle` |
| Build plate | `Textured PEI Plate` |
| Filament | Bambu system profile `SUNLU PETG @BBL A1M 0.4 nozzle`; SUNLU standard black PETG 1.75 mm, ASIN `B0D1KC72YP` |
| Nozzle | 250 °C first layer; 245 °C other layers |
| Textured bed | 60 °C first and other layers |
| Flow ratio | 0.94 |
| Maximum volumetric speed | 9 mm³/s |
| Process preset | `0.20 mm Strength`; 0.20 mm layer height |
| Wall loops | 6 |
| Top / bottom shell layers | 5 / 3 |
| Sparse infill | 25%, grid |
| Brim | 5 mm baseline; a qualification-project plate may require an explicit override |
| Supports | Off by system default; inspect each plate and retain any project-specific override |
| Part cooling | 10% minimum, 30% maximum, 90% for overhangs |

Leave those embedded system/process values unchanged for the first baseline;
do not improvise cooling, shell, infill, support, or brim values. The local
qualification builder may deliberately override support or brim per plate.
When it does, the project-specific value governs that plate and must appear in
the retained settings report.

SUNLU's current standard-PETG sources differ in some details. For this first
controlled baseline, dry the exact spool at **60–65 °C for 6 hours**. Record
the dryer, indicated/verified temperature, start/end time, ASIN, color,
lot/batch, spool, and date. Do not carry a passing result to another PETG
product, color, lot, spool, drying history, profile, or changed temperature or
flow setting.

### Beginner-safe Bambu Studio sequence

1. With the plate removed and cool, wash the Textured PEI surface with
   detergent and water, rinse it, and dry it completely. Do not touch the
   cleaned print area and do not use acetone. Dry the PETG as specified above.
2. Reinstall the clean plate correctly, load the dried PETG, and confirm the
   printer shows the intended PETG spool. Do not leave PLA selected anywhere.
3. Open the **local qualification project**. Select `Bambu Lab A1 mini 0.4
   nozzle`, `Textured PEI Plate`, and the installed system profile `SUNLU PETG
   @BBL A1M 0.4 nozzle`. Never open a canonical aggregate 3MF and press Print
   without this local setup review.
4. Check that every object is at **100% scale on X, Y, and Z**. Do not use
   auto-scale, fit-to-bed scaling, unit conversion, cutting, or repair that
   changes geometry.
5. Select one non-wall qualification plate and slice it locally. In Preview,
   inspect the first layer, brim, supports, every layer/toolpath, unsupported
   regions, collisions, plate boundaries, and all warnings. Confirm no path is
   missing and no object crosses a keep-out or printable boundary.
6. Before relying on the candidate values, use supported A1-series **Flow
   Dynamics** calibration if the installed firmware offers it. For **Flow
   Rate**, the A1 mini requires Bambu Studio's manual coarse and fine workflow;
   inspect the calibration pieces and save the result as a new filament user
   preset. Do not call either result a structural qualification.
7. Print **one plate at a time** and watch the first layer. Stop immediately
   for lifting, nozzle contact, scraping, missing extrusion, severe stringing,
   layer separation, or a toolpath different from Preview.
8. When the print finishes, wait for the Textured PEI Plate to cool to **35 °C
   or below** before removal. Label the specimen with spool/lot, profile,
   settings, plate, date, and plate number; record and retain the local slice
   report.

The development-only helper is named
`build_bambu_qualification_projects.py`. Use the command that matches the tree
you actually have, with the same exact fresh sibling output path.

From the source-workspace repository root:

```text
.venv/bin/python development/r6/build_bambu_qualification_projects.py --output ../story-corner-r6-bambu-a1mini-sunlu-petg-qualification-v1
```

From the flattened published-project root:

```text
.venv/bin/python build_bambu_qualification_projects.py --output ../story-corner-r6-bambu-a1mini-sunlu-petg-qualification-v1
```

The helper atomically creates that fresh workspace sibling and must refuse to
replace an existing destination or write anywhere else. Never point it at
`development/r6/generated/` or another existing release directory. Its
`../story-corner-r6-bambu-a1mini-sunlu-petg-qualification-v1/` output is a local,
unsliced qualification workspace with no G-code; it is not a sixth canonical
package, is not covered by the release manifest, and must not be published as
a production artifact.

### A1 mini build-volume warning

Bambu specifies the A1 mini build volume as 180 x 180 x 180 mm. The saved
X-corbel geometry reaches 168 mm on its bed axis and its required 6 mm brim on
both sides reaches **exactly 180 mm**. That leaves zero nominal bed-axis margin
before plate keep-outs, placement tolerance, extrusion width, or slicer/toolhead
constraints. Do not scale, crop, split, rotate, or remove the required brim to
force it to fit. The corbel stays blocked until its exact saved orientation,
brim, supports, and entire Preview toolpath fit the confirmed usable plate and
its actual-parent coupon gates pass. The corbel is not part of the initial
campaign; its 6 mm brim is a deliberate project-specific override to the
general 5 mm candidate baseline.

Official references: [Bambu Lab A1 mini specifications](https://us.store.bambulab.com/products/a1-mini),
[Bambu Textured PEI Plate cleaning, PETG, and cool-removal guidance](https://us.store.bambulab.com/products/bambu-textured-pei-plate),
[Bambu Flow Dynamics calibration](https://wiki.bambulab.com/en/software/bambu-studio/calibration_pa),
[Bambu Flow Rate calibration](https://wiki.bambulab.com/en/software/bambu-studio/calibration_flow_rate),
[SUNLU standard PETG product guidance](https://www.sunlu.com/products/petg-3d-printing-filament),
[SUNLU PETG TDS](https://media.sunlu.com/prod/20260330/f27808f0-3a19-49e3-bd79-6e846d6f4c15.pdf?filename=TDS),
[SUNLU filament drying guide](https://www.sunlu.com/wiki/filament-usage-guide),
and [SUNLU printer-preset selector](https://www.sunlu.com/materials-lab/printer-presets).

There is no authoritative print-time estimate while those inputs remain
unqualified. CAD volume and model-only 3MF object counts are not print-time
proxies; retain the exact qualified slicer's time estimate with its settings
report before planning a complete print campaign.

Preserve the saved structural orientations:

| Part family | Qualification orientation |
| --- | --- |
| Deck cassette | Continuous top skin on the plate; coffer lands upward, then flip for installation |
| Arcade half | Broad elevation face on the plate; qualify same-PETG support/sacrificial mapping for the centered pads, shoulder, and tenons |
| X-corbel | Common wall-contact face on the plate; qualify every-layer connectivity, clevis cheeks, ridge/lock closures, exact same-PETG supports, and the full brim/toolpath |
| Crown diaphragm keeper | Broad strip face on the plate with its one rear-bayonet tongue upward; qualify it with the separate keeper-reach indexed quarter-turn pin in the exact actual-parent receiver orientation |
| Crown bridge | Broad ladder face on the plate |
| Wedges and flat keys | Largest broad face on the plate |
| Ornament | Decorated `d=0` face on the plate with receiver housings upward; this is not a flat-back print and requires the actual-parent orientation coupon |
| Crown-bridge pin | Shaft axis parallel to the plate; split plane perpendicular to the plate; round head and circular cross-section vertical/tangent to the plate. No support-free or production claim; qualify slicer mapping, brim, cooling, flexure, and actual-parent service on the confirmed profile |
| Indexed keeper/front-tie pins | Shaft axis parallel to the plate with the 8 mm handle edge and one T-tail edge on the plate; qualify both service-axis variants in their actual-parent receivers |

Do not rotate a structural part merely to reduce supports without repeating
qualification. Do not substitute PLA, PETG-CF, another polymer, another black
PETG product, or a different lot mid-test and carry results forward.

## 5. Test before any overhead installation

Follow [TEST_PROTOCOL.md](TEST_PROTOCOL.md) on a guarded bench or low
sacrificial wall mockup where failure cannot strike a person, pet, vehicle, or
valuable object. Required evidence includes:

- coupon and wall-bearing results using the final profile and actual fastener;
- a complete worst-case bay and corner dry-fit;
- matched low-load arch-on / arch-off deflection comparison;
- separate distributed, front-edge, crown-point, and asymmetric/torsional load
  cases only after a target load and written stop limits are set;
- whole-article thermal cycling of a complete independent L level; coupon-only
  cycling does not close this gate;
- sustained-load readings at 1 hour, 24 hours, 7 days, 30 days, and 90 days;
- 72 hours unloaded recovery after the 90-day reading;
- teardown inspection of every bearing face, pin, cross-key, receiver, keeper,
  floating integral-cap seat, screw seat, and printed layer path.
- a separately printed matched specimen loaded destructively to failure and
  never reused for creep evidence or installation.

Thirty days is only an initial creep screen. No load claim may be considered
before 90 days plus recovery and teardown, and completion does not create an
automatic rating.

## 6. Installation gate

Proceed to [ASSEMBLY.md](ASSEMBLY.md) only after all measurements are entered,
production wall geometry is regenerated, test acceptance criteria are written,
all tests pass for the exact material/profile/hardware combination, and a
competent person has reviewed the intended wall and use. Install the upper
level first so its 75 mm minimum front/underside cross-key-and-pin service paths
remain accessible; install the lower level only after the upper level is fully
service-checked.

If any gate is uncertain, stop. The preserved `reference/hybrid_r5/` design is
the documented fallback, but it is a separate architecture and its evidence
must not be transferred to r6.

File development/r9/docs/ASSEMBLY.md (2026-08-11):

# R9 qualification assembly and service guide

## Scope

This guide covers **visual dry assembly on a padded tabletop only**. It checks
whether printed interfaces can be identified, seated, released, and serviced
in the intended order. It is not a wall-installation guide and it does not
authorize stored load.

> **HARD STOP:** no drilling, screws, anchors, adhesive, wall mounting, hanging,
> leaning, proof load, or household use. The current capacity is 0 kg / 0 lb.
> Keep people, pets, and valuable objects away from an unsupported dry assembly.

## Planning topology—not an assembly diagram

The eventual per-level topology is:

```text
through run, far-left toward corner
through[0] bookend — through[1] compact — through[2] compact
                    — through[3] compact — through[4] hidden corner half

return run, corner toward far-right
return[0] hidden corner half — return[1] compact — return[2] bookend
```

That is eight candidate stations and six visible supports per level. The bundle
does not contain production quantities, shelf cassettes, full rear-ledger
segments, full front beams, or an authored one-bay assembly. Never line up the
qualification articles and call them a shelf.

The visible bookend body is nominally 4.75 in below the shelf underside and the
compact body is nominally 3.0 in. The complete thin strap remains 6.30 in tall.
These are qualification dimensions, not a capacity claim.

## Article identity

Use the exact filenames in [PRINT_FIRST.md](PRINT_FIRST.md). These distinctions
matter:

- `r9_shortened_outer_bookend_support` is the smooth, unhanded control.
- `r9_compact_support` is one representative compact article, not four parts.
- `r9_concealed_corner_half_control` is untrimmed and is not an assembly hand.
- `r9_through_hidden_corner_half` and `r9_return_hidden_corner_half` are the two
  pre-authored corner hands. Never mirror either one.
- `r9_two_socket_outer_bookend_rail_fit_coupon` is a standalone interface
  coupon; it does not attach to the smooth control.
- `r9_through_outer_bookend_additive_two_socket_candidate` and
  `r9_return_outer_bookend_additive_two_socket_candidate` are different handed,
  one-body first articles. Their receiver rails are fused/additive and are not
  removable.

## Before dry fitting

- [ ] R8 0.4 mm clearance gate passed and was recorded.
- [ ] The package is `r9_compact_bookend_petg_qualification_v5`.
- [ ] `manifest.json` and `validation.json` were verified in the bundle.
- [ ] Every individual 3MF filename and printed label remains traceable.
- [ ] All articles cooled to room temperature.
- [ ] No part has warp, crack, layer separation, missing material, whitening,
      or permanent set.
- [ ] Fit surfaces are clean; no part was sanded, filed, heated, drilled, or
      scaled.
- [ ] The work surface is flat, padded, and large enough for the 160 mm corner
      fixture and upright halves.

Painter's tape labels, a ruler/caliper, flashlight, phone/camera, and notebook
are appropriate. Do not use a mallet, clamp, pry bar, heat gun, drill, wall
screw, or adhesive. Support an upright article gently by hand if needed; the
corner study is not a freestanding structure.

## Exact dry-fit order

### 1. Inspect the three standalone support shapes

Inspect the compact support, smooth outer-bookend control, and untrimmed
corner-half control separately. Check their broad printed face, full thin wall
strap, shortened projecting body, D-window, roots, and front nose. Set each on
its declared datum face and record rocking or warp.

There is no authored support-to-ledger, support-to-front-beam, or cassette seat
in these articles. Do not attempt to mate them to the joint coupons.

### 2. Dry-fit the rear-ledger joint coupons

1. Keep `r9_rear_ledger_male_coupon` fixed on the padded table.
2. Align the open end of `r9_rear_ledger_female_coupon` with the male tongue.
3. Slide the female straight over the tongue through **12.4 mm** of service
   travel until the body shoulder planes meet. Do not twist.
4. The authored running clearance is 0.4 mm on each tongue depth/height face
   and 0.4 mm at the tongue tip. Only the outer body shoulders intentionally
   contact.
5. Remove the female by the exact straight reverse motion.

### 3. Dry-fit the staggered front-beam coupons

1. Keep `r9_front_beam_lower_lap_coupon` fixed.
2. Align `r9_front_beam_upper_lap_coupon` in its labelled upper position.
3. Slide the upper coupon straight over the lower lap through **16.0 mm** of
   service travel.
4. Do not clamp the pair closed. The target intentionally retains 0.4 mm at
   each axial shoulder and 0.8 mm total between opposed lap faces; no lap face
   is intended to contact.
5. Remove the upper coupon by the exact straight reverse motion.

Passing either coupon fit proves only that small interface—not a full ledger,
beam, span, or PETG creep result.

### 4. Assemble the five-part nominal corner study

Use only these five parts: 90-degree tabletop fixture, through handed half,
return handed half, shear-key handling coupon, and cosmetic reveal coupon.

1. Put the 160 mm L fixture flat on the padded table.
2. Keep the through label visible. Hold the through half upright over its
   fixture leg and lower it vertically **8.0 mm** to the fixture plane.
3. Orient the return half perpendicular to the through half without mirroring
   it. Slide it horizontally along the return leg through **16.4 mm** until the
   complementary 45-degree miter faces meet.
4. Lower the L-shaped shear-key coupon vertically **8.0 mm** until it rests on
   the two support tops.
5. Lower the cosmetic-cover coupon vertically **8.0 mm** until it rests on the
   key.
6. Photograph the fixture, miter, key, cover, front, and underside views.
7. Remove in exact reverse: cover up 8.0 mm, key up 8.0 mm, return half straight
   out 16.4 mm, then through half up 8.0 mm.

The fixture proves only handling and reveal at its authored nominal 90 degrees.
The closet angle is unmeasured, and the key/cover do not create a credited
corner load path. Stop if balancing becomes unsafe, a part must bend, or the
cover is needed to pull the halves into alignment.

### 5. Qualify the standalone cable interface

1. Place the standalone two-socket rail coupon securely on the padded table.
2. Hold the flush blank at the upper entry position, push it straight inward
   through the 6.0 mm approach, then lower it exactly **8.0 mm** into the lower
   socket.
3. Remove by lifting 8.0 mm, then moving straight outward. Repeat in the upper
   socket. Keep the unused socket empty.
4. Only after the blank passes both sockets, repeat one socket at a time with
   the comb/hook module.

This coupon proves only rail-to-module fit. It does not prove a rail attachment,
two simultaneously occupied sockets, a cable load, or a snag event.

### 6. Qualify both handed integrated bookends

1. Confirm the exact through and return labels. Do not mirror or swap them.
2. The additive receiver is already fused into each bookend. Never pry or try
   to remove it.
3. On the through bookend, test the blank in the lower and upper sockets one at
   a time using the straight-in, 8.0 mm drop, 8.0 mm lift, straight-out motion.
4. Repeat with the comb/hook, one socket at a time.
5. Repeat Steps 3–4 on the return bookend.
6. Inspect the additive receiver band, print foot, strap, D-window, roots, and
   socket edges after service.

The bookends remain zero-rated first articles. Door/trim, installed cable-loop,
wall, and real snag/service clearances are unqualified.

### 7. Stop the qualification bundle; use the separate one-bay guide

Qualification v5 deliberately contains no one-bay pose. The separate,
versioned `generated/one_bay_prototype_v3` package now emits one exact 160 mm
Palatine Moderne tabletop bay with member seats, cassette locators, and
corrected printed wall-bore candidates. Use only that package's own README and
assembly guide for the five-part bay.

Do not create a substitute with these loose coupons, R8 cassettes, tape, glue,
fasteners, scaling, or guessed alignment. Qualification v5 ends after the dry
fits above. The one-bay v3 remains unloaded and does not authorize a full-L
shelf or wall installation.

## Disassembly and storage

1. Remove every cable module by lift-then-out motion; the integrated receiver
   remains fused to its bookend.
2. Remove corner cover, key, return half, and through half in reverse order.
3. Slide the beam upper lap and ledger female coupon straight off their mates.
4. Inspect all socket, tongue, lap, miter, strap, D-window, key, cover, and root
   surfaces for abrasion, whitening, crack, permanent set, or lost engagement.
5. Store accepted PETG articles unloaded, indoors, flat, and away from direct
   sun or heat. Mark rejected/superseded articles clearly.

## Qualification record

| Check | Pass / fail | Observation or measured value | Photo ID |
|---|---|---|---|
| Smooth bookend control inspection |  |  |  |
| Compact support inspection |  |  |  |
| Untrimmed corner control inspection |  |  |  |
| Rear-ledger male/female dry fit |  |  |  |
| Front-beam lower/upper dry fit |  |  |  |
| Through corner half seat |  |  |  |
| Return corner miter seat |  |  |  |
| Shear-key handling coupon |  |  |  |
| Cosmetic reveal coupon |  |  |  |
| Complete corner reverse disassembly |  |  |  |
| Standalone rail + blank, both sockets |  |  |  |
| Standalone rail + comb/hook, both sockets |  |  |  |
| Through integrated bookend, both modules |  |  |  |
| Return integrated bookend, both modules |  |  |  |
| Complete post-service inspection |  |  |  |

## Wall installation remains blocked

The selected screw/washer fixture candidate and exact quantities are in
[MATERIALS_AND_HARDWARE.md](MATERIALS_AND_HARDWARE.md). They are not drilling
or installation authorization. This document intentionally contains no wall-
bore coordinates, installation torque, proof load, or rated load.
All of the following are required before a separate wall-installation document
can be authored:

- exact long and short clear lengths at both the 68 in and 84 in elevations;
- horizontal outlet centerline from the through-run far-left datum and a verified
  electrical no-drill/service envelope;
- exact corner angle, wall bow, trim and doorway clearances;
- verified stud/blocking locations and wall-substrate thickness;
- approved continuous blocking or an independently verified equivalent;
- exact metal structural screw, washer, pilot, embedment, edge-distance, and
  driver-access schedule;
- declared contents and target load;
- exact load-path CAD and wall-bore validation; and
- successful framed-wall, proof, creep, and destructive physical gates under
  an approved protocol.

Printed wall anchors and hollow-wall anchors are prohibited in the primary
load path. A successful tabletop assembly does not remove any of these stops.

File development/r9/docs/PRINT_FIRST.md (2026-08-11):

# R9 print-first guide

## Read this before opening Bambu Studio

R9 is a **qualification-only** shelf design. The first prints are small fit
articles, followed by one set of R9 joint/support/corner articles and the
permitted tabletop dry fits. They are not a complete shelf kit.

> **HARD STOP:** do not print the full two-level shelf, drill a wall, select
> wall screws from this document, install a part, or place stored load on any
> R9 article. Wall construction, framing/blocking, fastener geometry, exact
> room dimensions, target contents load, and physical structural tests are not
> complete. The current load rating is 0 kg / 0 lb.

Current planning references—not final fabrication dimensions—are:

- lower and upper shelf tops: nominally **68 in** and **84 in** above the floor;
- long/through clear wall: **61.25 in** at both shelf elevations;
- short/return clear wall: **36.75 in** at both shelf elevations, retained as
  the conservative working value read from the supplied photos;
- top of outlet faceplate: approximately **53.5 in** above the floor; and
- horizontal outlet position from the through-run far-left datum: **not measured**.

Complete [MEASUREMENT_WORKSHEET.md](MEASUREMENT_WORKSHEET.md) before exact
stationing or any installation design.

For the first-shelf bill of materials and the selected—but still conditional—
GRK/washer fixture set, read
[MATERIALS_AND_HARDWARE.md](MATERIALS_AND_HARDWARE.md). For the intended Roman/
Art-Deco appearance, read [DESIGN_LANGUAGE.md](DESIGN_LANGUAGE.md). Neither
document removes the qualification and wall-install hard stops in this guide.

## Filament and machine baseline

Use only the received **black SUNLU PETG** spool corresponding to Amazon ASIN
`B0D1KC72YP`, selected listing variant `4 kg / 2 Black + 2 Black` (four black
1 kg spools). Confirm that the physical spool label still says **PETG** and
record its lot. Listing variants can change. PLA is not authorized for an R9
printed part, qualification coupon, substitute, or load-path component.

SUNLU's [standard PETG product page](https://store.sunlu.com/products/over-6kg-bundle-sale-petg-3d-printer-filament-1-75mm-1kg-roll)
lists 50 C drying and storage below 20% RH. For this project, use **50 C for
6–8 hours** only when both the received spool label and the dryer instructions
permit it. Never exceed the lower temperature limit stated by either source.
Stop and resolve conflicting instructions instead of guessing. After drying,
keep the spool sealed or in a dry box until use.

Record the drying cycle and then manually verify every value below. A neutral
3MF contains geometry; it does not guarantee these printer settings.

| Setting | Qualification baseline |
|---|---|
| Printer | Bambu Lab A1 mini, 0.4 mm nozzle |
| Plate | Textured PEI; follow the plate maker's PETG release/interface guidance |
| Filament preset | `SUNLU PETG @BBL A1M 0.4 nozzle` |
| Process starting point | `0.20mm Strength @BBL A1M` |
| Scale | 100%; never auto-scale |
| Layer height | 0.20 mm |
| Nozzle | 250 C first layer; 245 C remaining layers |
| Bed | 60 C |
| Flow ratio | 0.94 |
| Maximum volumetric speed | 9 mm^3/s |
| Fan | 10–30% normal; 90% overhang |
| Walls | 6 loops |
| Top / bottom shells | 5 top / 3 bottom layers |
| Infill | 25% grid |
| Brim | Outer brim only, 5.0 mm wide, 0.1 mm object gap; keep at least 2.0 mm between brims |
| Plate reserve | Preserve at least 2.0 mm from every bed edge in addition to the brim |

Never reuse a PLA project or preset. Clean the plate, inspect the nozzle, and
confirm the selected plate and nozzle in the Device/Prepare views before every
qualification job.

The neutral 3MF embeds no filament or process profile. If the exact SUNLU
preset above is not listed, duplicate `Generic PETG`, enter every value in the
table manually, save it as `SUNLU PETG @BBL A1M 0.4 nozzle`, and verify it again
before slicing. Let the plate and PETG part cool fully before removal.

## Exact staged print order

Do not skip ahead after a failure. Record each stage in the table at the end of
this document and use the acceptance rules in [TEST_PROTOCOL.md](TEST_PROTOCOL.md).

### Stage 0 — corrected 0.4 mm clearance gate (print this first)

Use only the individual neutral 3MF files in the current R9 v5 bundle:

```text
development/r9/generated/qualification_v5/stage0_individual_model_only_3mf/
```

Print and test in this order:

1. `MODEL_ONLY_r8_clearance_ladder_receiver.3mf`
2. `MODEL_ONLY_r9_gate0_clearance_key_0p4_handle_down.3mf`

The receiver is geometry-identical to the frozen R8 v2 receiver. A cooled,
inspected R8 v2 receiver may therefore be reused instead of reprinted. The key
has the exact 0.4 mm **per-face** geometry, but v5 applies a proper 180-degree-X
saved pose so its 20 x 16 mm handle begins on the plate. Preserve the imported
pose. Support must remain Off, and Bambu Preview must show no
floating-cantilever warning.

Do **not** print the legacy R8 v2 0.5, 0.4, 0.3, or 0.2 key files in their
identity saved poses. Their common pose contains a large handle cantilever.
V5 deliberately uses the design-target 0.4 key as the fail-fast gate; tighter
and looser diagnostics remain deferred until corrected poses are published.

Let the key cool completely. Inspect both unsupported keyed-head wings before
fit: no loose strand, curl, torn perimeter, layer separation, or visible droop.
Then the 0.4 key must seat and release by hand through ten gentle cycles without
tools, cracking, whitening, permanent set, increasing bind, or destructive
force.

If 0.4 does not qualify, **stop**. Do not sand the key, enlarge the receiver,
change scale, or compensate in CAD. Check moisture, flow calibration, actual
temperatures, plate choice, and slicing settings; record the correction and
reprint a new identified set.

### Stage 1 — verify the frozen R9 bundle

Proceed only after Stage 0 passes at 0.4 mm. The exact bundle is:

```text
development/r9/generated/qualification_v5/
```

Its package identity is `r9_compact_bookend_petg_qualification_v5`. Before
printing, read its `README.md`, open `validation.json`, and verify the current
`manifest.json` in that same directory. Record the manifest file's SHA-256 in
the print log; do not copy a digest from an old message or edit the manifest.
Stop if the package identity, validation result, artifact list, or hashes do
not agree with the files present.

Use only the files in `individual_model_only_3mf/`. This file is a catalog only:

Every individual part follows the exact path rule
`individual_model_only_3mf/MODEL_ONLY_<mesh_id>.3mf`.

```text
model_only_3mf/MODEL_ONLY_R9_QUALIFICATION_CATALOG.3mf
```

Never treat that combined catalog as an arranged A1 mini plate.

### Exact 17-part inventory

The table order is the frozen manifest/object order, not the recommended print
sequence. Every entry is a separate neutral 3MF at 100% scale.

| # | Exact individual filename | Purpose | Saved print orientation |
|---:|---|---|---|
| 1 | `MODEL_ONLY_r9_shortened_outer_bookend_support.3mf` | smooth outer-bookend control | broad minimum run-side face on plate |
| 2 | `MODEL_ONLY_r9_compact_support.3mf` | shortened compact-support article | broad minimum run-side face on plate |
| 3 | `MODEL_ONLY_r9_concealed_corner_half_control.3mf` | untrimmed corner-half control; not an installed hand | broad minimum run-side face on plate |
| 4 | `MODEL_ONLY_r9_through_hidden_corner_half.3mf` | pre-authored through-run corner hand | broad minimum run-side face on plate |
| 5 | `MODEL_ONLY_r9_return_hidden_corner_half.3mf` | pre-authored return-run corner hand | opposite/broad maximum run-side face on plate |
| 6 | `MODEL_ONLY_r9_under_shelf_shear_key_coupon.3mf` | handling/registration coupon only | authored flat face on plate |
| 7 | `MODEL_ONLY_r9_cosmetic_corner_cover_coupon.3mf` | seam/reveal coupon only | authored flat face on plate |
| 8 | `MODEL_ONLY_r9_90_degree_tabletop_angle_fixture.3mf` | nominal 90-degree tabletop reference | authored flat face on plate |
| 9 | `MODEL_ONLY_r9_rear_ledger_male_coupon.3mf` | ledger tongue coupon | minimum member end on plate |
| 10 | `MODEL_ONLY_r9_rear_ledger_female_coupon.3mf` | ledger blind-socket coupon | closed maximum member end on plate |
| 11 | `MODEL_ONLY_r9_front_beam_lower_lap_coupon.3mf` | lower staggered-lap coupon | minimum member end on plate |
| 12 | `MODEL_ONLY_r9_front_beam_upper_lap_coupon.3mf` | upper staggered-lap coupon | maximum member end on plate |
| 13 | `MODEL_ONLY_r9_two_socket_outer_bookend_rail_fit_coupon.3mf` | standalone rail/interface coupon | solid back web on plate; installed X/Z on bed |
| 14 | `MODEL_ONLY_r9_flush_blank_cable_module.3mf` | first cable-interface module | local minimum-Z broad side on plate |
| 15 | `MODEL_ONLY_r9_multi_cable_comb_hook_module.3mf` | three-position cable comb/hook | local minimum-Z broad side on plate |
| 16 | `MODEL_ONLY_r9_through_outer_bookend_additive_two_socket_candidate.3mf` | through/far-left handed integrated first article | broad run-side additive print foot on plate |
| 17 | `MODEL_ONLY_r9_return_outer_bookend_additive_two_socket_candidate.3mf` | return/far-right handed integrated first article | broad run-side additive print foot on plate |

Do not mirror either handed corner half or integrated bookend. The two bookend
SKUs are intentionally different because the keyed sockets are asymmetric.

### Stage 2 — R9 first-article print order

Print one part per plate for its first qualification unless the bundle README
explicitly authorizes another arrangement. Stop at the first failed gate.

1. **Straight joints:** print rear-ledger male + female, dry-fit them, then
   print front-beam lower + upper laps and dry-fit them.
2. **Support shapes:** print one compact support, one smooth outer-bookend
   control, and one untrimmed corner-half control. These are separate shape and
   print-quality articles; no support-to-ledger/beam seat exists yet.
3. **Nominal corner:** print the 90-degree tabletop fixture, through handed
   half, return handed half, shear-key handling coupon, then cosmetic reveal
   coupon. Assemble only in the sequence in [ASSEMBLY.md](ASSEMBLY.md).
4. **Standalone cable fit:** print the two-socket rail coupon and flush blank.
   Qualify the blank in each socket separately. Only then print and qualify the
   comb/hook in each socket.
5. **Integrated bookend first articles:** only after the standalone rail passes,
   print the through and return handed integrated bookends. Preserve their
   labels. Test the blank in both sockets of each hand, then the comb/hook.

The integrated receiver rail is fused/additive geometry. Do not attempt to
remove it from the bookend. Endpoint-to-wall installation, doorway/trim
clearance, cable-loop clearance, snag retention, and accessory load are still
unqualified.

### Stage 3 — exact dry fits, then stop

Follow [ASSEMBLY.md](ASSEMBLY.md) on a padded table. Qualification v5 permits
only the two straight-joint dry fits, the five-part nominal-90-degree corner
handling/reveal study, and module service in the standalone and integrated
two-socket receivers.

The compact-support/ledger/front-beam/cassette one-bay assembly is
**software-blocked**. No support seats, cassette/member interface, exact bay
length/end condition, or hardware/framing datum has been authored. Therefore
there is no printable one-bay kit and no full-L tabletop assembly in this
bundle. Do not invent one by lining up loose parts.

After the permitted dry fits, retain:

- photos of the corrected-pose 0.4 key before fit, seated, and removed;
- all faces of each printed R9 article;
- both straight-joint seated and separated views;
- the nominal corner after each assembly step and after disassembly;
- blank and comb/hook service in both sockets of the standalone rail and each
  integrated handed bookend;
- completed print/test records; and
- the completed field measurement worksheet.

No later printing or wall work is authorized by completing Stage 3.

## Orientation and support review for every plate

All 17 R9 parts are authored **Support Off** in the exact saved orientations
listed above. That classification is software evidence, not permission to skip
Bambu Studio Preview.

1. Start a new A1 mini PETG project.
2. Import one individual neutral 3MF at 100% scale.
3. Do not auto-orient, auto-repair, auto-scale, merge, mirror, or lay the part
   on another face.
4. Confirm the saved pose and exact filename against the bundle README and
   manifest. Pay special attention to the opposite broad face on the return
   corner half and the distinct handed bookends.
5. Set Support Off, slice, and inspect Preview layer by layer for disconnected
   islands, weak first-layer contact, bridges, brim collisions, exclusion-zone
   warnings, and edge-reserve violations.
6. Stop if Preview calls for a repair, scale/orientation change, or support.
   Record the mismatch instead of improvising a new pose.

The largest support/bookend envelopes fit the nominal A1 mini volume only in
their saved poses with the documented brim and reserve. Do not rotate a part to
make the plate look fuller.

## Cooled-part inspection

Quarantine the part and do not fit it if any answer is “yes”:

- [ ] wrong filament, color/lot not recorded, or a PLA preset was used;
- [ ] lifting, rocking, or visible warp on a bearing or mating face;
- [ ] crack, layer split, missing extrusion, burned material, or deep scar;
- [ ] white stress mark or permanent bend before testing;
- [ ] support damage or elephant-foot interference on a key/contact surface;
- [ ] unexplained slicer repair, scale other than 100%, or changed orientation;
- [ ] filename/part identity cannot be traced to the manifest; or
- [ ] dimensions fall outside a tolerance explicitly stated by the exact
      bundle validation record or test protocol.

Do not quietly sand, drill, heat-form, glue, or file a rejected part. Record any
post-processing as a failed-as-printed result and obtain a revised test plan.

## Print record

| Stage / part | Exact filename | Manifest SHA or bundle revision | Spool lot | Dry cycle | Studio version | Settings verified | Result / photo ID |
|---|---|---|---|---|---|---|---|
| R8 receiver |  |  |  |  |  |  |  |
| R9 corrected-pose key 0.4 |  |  |  |  |  |  |  |
| R9 smooth bookend control |  |  |  |  |  |  |  |
| R9 compact support |  |  |  |  |  |  |  |
| R9 corner-half control |  |  |  |  |  |  |  |
| R9 through corner half |  |  |  |  |  |  |  |
| R9 return corner half |  |  |  |  |  |  |  |
| R9 shear-key coupon |  |  |  |  |  |  |  |
| R9 cosmetic-cover coupon |  |  |  |  |  |  |  |
| R9 90-degree fixture |  |  |  |  |  |  |  |
| R9 ledger male |  |  |  |  |  |  |  |
| R9 ledger female |  |  |  |  |  |  |  |
| R9 beam lower lap |  |  |  |  |  |  |  |
| R9 beam upper lap |  |  |  |  |  |  |  |
| R9 standalone rail |  |  |  |  |  |  |  |
| R9 flush blank |  |  |  |  |  |  |  |
| R9 comb/hook |  |  |  |  |  |  |  |
| R9 through integrated bookend |  |  |  |  |  |  |  |
| R9 return integrated bookend |  |  |  |  |  |  |  |

## Do not print yet

- duplicate or production quantities of cassettes, ledger pieces, front beams,
  supports, bookends, cable accessories, or corner parts;
- any file from `development/r8/generated/qualification_v1/`;
- either R8 combined catalog or the R9 qualification catalog as a ready-to-slice
  plate;
- a mirrored, scaled, repaired, or user-modified substitute;
- G-code received from another machine or person; or
- any one-bay/full-L substitute, wall-drilling template, anchor, or
  fastener-locating article.

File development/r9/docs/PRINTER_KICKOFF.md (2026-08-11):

# R9 printer kickoff — controlled Stage 0

This is the operator handoff for the **first physical print only**. It turns the
frozen R9 PETG settings into a deliberate Bambu Studio preflight while keeping
the person at the printer in control of every physical action.

> **QUALIFICATION-ONLY HARD STOP:** Stage 0 produces small clearance-test
> articles. It does not authorize a full shelf, duplicate/production parts,
> wall drilling, installation, hanging, or stored load. R9 remains unrated at
> **0 kg / 0 lb**. Passing Stage 0 is only permission to consider the next
> documented qualification stage.

## What the user does before kickoff

Do not open a print job until every item below is true.

- [ ] The printer is a **Bambu Lab A1 mini** with the **0.4 mm nozzle**
      installed and is idle, connected, and free of another job.
- [ ] The installed build plate is the **Textured PEI Plate**, is empty, and
      has been cleaned using the plate maker's instructions.
- [ ] PLA has been unloaded. The loaded spool's physical label says **SUNLU
      PETG**, **black**, not PLA, PETG+, high-speed PETG, matte PETG, or another
      formulation.
- [ ] The spool matches Amazon ASIN `B0D1KC72YP`, selected variant
      **4 kg / 2 Black + 2 Black**: four black 1 kg spools, 1.75 mm
      +/-0.02 mm. The bound listing is
      `https://www.amazon.com/dp/B0D1KC72YP?th=1`.
- [ ] The spool lot or other unique spool identifier has been written in the
      print record. A web listing is not a substitute for checking the label;
      listing variants can change.
- [ ] The drying cycle has been recorded. The R9 baseline is **50 C for 6–8
      hours**, but only when both the received spool label and dryer manual
      permit it. Never exceed the lower stated temperature limit. Stop on any
      conflict instead of guessing.
- [ ] After drying, the PETG has stayed sealed or in a dry box until loading.
- [ ] The user has physically loaded the PETG through the intended feed path,
      completed the printer's normal load/purge routine, and confirmed that
      the extruded material is black PETG.
- [ ] The user can remain near the printer for the first layer, can reach the
      printer's Stop control, and will keep hands away from the hot end and
      moving axes.

If any box is false or uncertain, stop. Codex cannot identify a spool, clean a
plate, install a nozzle, load filament, inspect a purge, or make the printer's
physical area safe.

## The exact phrase that begins software preparation

Only after the physical checklist is complete, tell Codex exactly:

```text
PETG loaded—start Stage 0
```

That phrase authorizes Codex to perform **software preparation only**: open the
exact neutral 3MF, select the A1 mini, enter/verify the PETG and process
settings, slice, and inspect Preview. Codex will directly operate the visible
Bambu Studio controls when macOS Accessibility access is available. If that
access is unavailable or a control cannot be verified reliably, Codex will
stop at that control, give the exact visible selection, and verify the user's
screen rather than pretending the change was made. The phrase is **not**
authorization to send a job to the printer or start a physical print.

Codex must stop after Preview, report the selected printer/plate/filament,
settings, warnings, estimated time, and material estimate, and ask for explicit
authorization before Send/Print. A clear user response authorizing that exact
Stage 0 file is required. Silence, the kickoff phrase above, a general “looks
good,” or authorization for a previous plate is not sufficient. The corrected
Stage 0 key is a separate physical job and requires a separate authorization.
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

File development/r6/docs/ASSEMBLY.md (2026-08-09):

# Assembly — two independent L levels

> **Qualification gate:** This sequence documents the intended mechanics. Do
> not perform an overhead wall installation while r6 remains experimental,
> unrated, or fitted with solid development wall plates. Production bores are
> blocked until the real fastener, driver, wall finish, framing, utilities, and
> wall mockup have been verified. No tested load rating exists.

The shelf body, supports, joinery, keeper strips, facade, pins, and cross-keys are
printed black PETG. The only nonprinted installed items are suitable metal structural
screws with integral heads or compatible metal washers into verified wood
studs or purpose-installed blocking.
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

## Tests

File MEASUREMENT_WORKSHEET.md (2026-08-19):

# Measurement worksheet — Triadic Palatine Order r5

Print or copy this file, fill it in the closet, then transcribe section H
into [config.json](config.json) and rebuild. Empty config values keep every
generated artifact explicitly nominal; nothing here creates a load rating.

Datum for every station measurement: the **intersection of the two finished
wall planes** at the inside corner — never a board end.

| Header | Value |
|---|---|
| Date / measured by | |
| Room temperature / humidity | |
| Tools used and their stated accuracy | |

## A. Photo schedule

Take and keep (crop or blur anything private before sharing in an issue):

1. Both walls square-on, corner to outer end.
2. The inside corner at each candidate shelf elevation with a square held in.
3. Straightedge or laser against each wall showing bow at shelf height.
4. The outlet and its service envelope with a tape in frame.
5. Stud-finding evidence on both walls (marks plus the method used).
6. Wall build-up at the corner (drywall edge, mud, caulk).
7. The candidate fastener next to calipers.
8. The largest storage bins to be used.
9. Printer and filament spool label.

## B. Clear wall width (per wall, per elevation)

Measure the clear length from the finished corner to the first obstruction at
the **rear, middle, and front** shelf planes for every candidate elevation.
The value that goes in config is the **smallest** reading for that wall.

3 ft return wall:

| Elevation (in from floor) | Rear (in) | Middle (in) | Front (in) |
|---|---|---|---|
| | | | |
| | | | |

Minimum used for generation: ______ in

5 ft through wall:

| Elevation (in from floor) | Rear (in) | Middle (in) | Front (in) |
|---|---|---|---|
| | | | |
| | | | |

Minimum used for generation: ______ in

## C. Corner geometry

| Item | Value |
|---|---|
| Included corner angle at each candidate elevation (deg) | |
| Worst deviation from 90.0° (deg) | |
| Maximum wall bow under a straightedge (mm) | |
| Full-size corner template made and checked? | yes / no |

The generation gate is **±0.25°**; the residual 1.6 mm joint clearance must
stay ≥ 0.6 mm. If the worst measured angle exceeds the gate, stop — see
[SAFETY.md](SAFETY.md) corner stop conditions.

## D. Framing map (one row per support line)

Desired nominal centers (from [generated/support_plan.csv](generated/support_plan.csv)):
return 10.750, 22.313, 33.875 in; through 6.281, 22.281, 38.281, 54.281 in.
Field centers must land on verified wood framing or installed blocking, stay
≤ 16 in apart, ≥ 2 in distinct, and leave ≤ 6 in end overhang.

| Wall | Station | Verified center from corner (in) | Wood width (in) | Material / verification method | Utilities clear? |
|---|---|---|---|---|---|
| return | 1 | | | | |
| return | 2 | | | | |
| return | 3 | | | | |
| through | 1 | | | | |
| through | 2 | | | | |
| through | 3 | | | | |
| through | 4 | | | | |

If a nominal station misses framing: [ ] blocking will be installed, or
[ ] the centers above will be entered so the plan regenerates around them.

## E. Installed hardware (measure after standards are mounted)

| Item | Value |
|---|---|
| Wall-to-plywood-back offset, return wall (in) | |
| Wall-to-plywood-back offset, through wall (in) | |
| Bracket wall-to-tip reach, real bracket seated (in) | |
| Bracket body width / lock type | |
| Wall-to-fascia projection with the exact hardware (in) | |

The offset is measured from the **finished wall face to the plywood back
plane** with the real standard and bracket seated — do not substitute the
catalog projection (nominal fallback is 0.6875 in).

## F. Stored contents

| Item | Value |
|---|---|
| Bin outside width × depth × height (largest) | |
| Loaded weight of heaviest bin (lb) | |
| Bin count per arm | |
| Measured shelf-arm dead load, return (lb) | |
| Measured shelf-arm dead load, through (lb) | |

## G. Printer and filament

| Item | Value |
|---|---|
| Printer model / usable build volume (mm) | |
| Nozzle diameter and material | |
| Build plate type and condition | |
| Bambu Studio version | |
| Black PETG brand, product line, lot | |
| Spool opened date / storage RH / drying method | |

## H. Transcribe into config.json

Units: every `_in` key is inches, `_deg` degrees, `_lb` pounds. The runs
array holds the 3 ft wall at `id: "short_wall_3ft"` and the 5 ft wall at
`id: "long_wall_5ft"`.

| Worksheet source | config.json key (JSON path) |
|---|---|
| B minimum, return wall | `closet.runs[id=short_wall_3ft].field_verified_min_clear_wall_width_in` |
| B minimum, through wall | `closet.runs[id=long_wall_5ft].field_verified_min_clear_wall_width_in` |
| C worst included angle | `closet.inside_corner.field_verified_angle_deg` |
| D verified centers, return (3 numbers) | `closet.runs[id=short_wall_3ft].field_verified_support_centers_in` |
| D verified centers, through (4 numbers) | `closet.runs[id=long_wall_5ft].field_verified_support_centers_in` |
| E offset, return wall | `closet.runs[id=short_wall_3ft].field_verified_installed_shelf_back_offset_in` |
| E offset, through wall | `closet.runs[id=long_wall_5ft].field_verified_installed_shelf_back_offset_in` |
| E bracket reach | `structural.field_verified_bracket_reach_in` |
| F dead load, return | `closet.runs[id=short_wall_3ft].field_verified_shelf_arm_dead_load_lb` |
| F dead load, through | `closet.runs[id=long_wall_5ft].field_verified_shelf_arm_dead_load_lb` |

Worked example (return run, values invented for illustration only):

```json
{
  "id": "short_wall_3ft",
  "field_verified_min_clear_wall_width_in": 35.75,
  "field_verified_installed_shelf_back_offset_in": 0.71875,
  "field_verified_support_centers_in": [10.5, 22.0, 33.5],
  "field_verified_shelf_arm_dead_load_lb": 9.4
}
```

## I. Rebuild and verify the entry took effect

```sh
PYTHON_BIN=.venv/bin/python SKIP_BAMBU=1 scripts/build_all.sh
```

Then open [generated/validation.json](generated/validation.json) and confirm
the `*_source` fields report `field_verified_*` (for example
`installed_shelf_back_offset_source`, `clear_width_source`,
`support_geometry_source`, `bracket_reach_source`) instead of a nominal
fallback. The generator hard-stops on out-of-gate angle or support values —
a stop is the design protecting you, not an error to work around. Re-measure,
correct the entry, and rebuild.

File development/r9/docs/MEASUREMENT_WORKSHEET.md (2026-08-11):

# R9 field measurement worksheet

## Purpose and datum

Use this worksheet to replace the current approximate room references with
repeatable measurements. These measurements support the next exact CAD pass;
they do not authorize drilling or installation.

Use two separate, run-local horizontal datums:

- **Through/long run:** zero is the far-left clear endpoint; values increase
  toward the inside corner.
- **Return/short run:** zero is the inside corner; values increase toward the
  far-right clear endpoint.

Write `through` or `return` beside every horizontal value. Never merge the two
coordinate systems, continue one through the corner, or treat a worksheet
coordinate as a drilling coordinate. These are survey coordinates only.

Use the finished floor directly below each measurement as the vertical datum.
Do not assume the floor, ceiling, or walls are level, plumb, square, or straight.
Record inches to the nearest 1/16 in, or millimetres to the nearest 1 mm. Take
each critical length three times and record the raw readings rather than
averaging from memory.

> **HARD STOP:** mark and photograph suspected stud/blocking positions, but do
> not drill exploratory holes. Wiring and plumbing may be present even when a
> stud finder reports framing. Uncertain construction or electrical routing
> requires qualified local verification before wall work. Nothing recorded on
> this worksheet is a wall-bore coordinate.

## Known planning references to confirm

| Item | Current nominal/approximate value | Reading 1 | Reading 2 | Reading 3 | Accepted field value | Photo ID |
|---|---:|---:|---:|---:|---:|---|
| Floor to ceiling | 96 in |  |  |  |  |  |
| Floor to outlet faceplate top | 53.5 in |  |  |  |  |  |
| Proposed lower shelf top | 68 in |  |  |  | confirm/change: |  |
| Proposed upper shelf top | 84 in |  |  |  | confirm/change: |  |

The proposed 68/84 in shelf tops produce a nominal 16 in top-to-top interval.
This is a planning choice, not a structural or accessibility approval.

## Recorded clear wall lengths

At each elevation, measure the through run from the far-left clear boundary to
the inside corner and the return run from the inside corner to the far-right
clear boundary. Do not measure along the floor and assume the upper wall is
identical. Record the endpoint obstruction—door trim, casing, wall return,
cabinet, or other feature—and the usable clearance before it.

| Run and elevation | Reading 1 | Reading 2 | Reading 3 | Shortest confirmed clear length | End obstruction / photo ID |
|---|---:|---:|---:|---:|---|
| Through/long wall at 68 in | 61.25 in | same reported value | — | **61.25 in / 1555.75 mm** | user field report |
| Through/long wall at 84 in | 61.25 in | same reported value | — | **61.25 in / 1555.75 mm** | user field report |
| Return/short wall at 68 in | 36.75 in | photo review | — | **36.75 in / 933.45 mm** | supplied short-wall photos |
| Return/short wall at 84 in | 36.75 in | photo review | — | **36.75 in / 933.45 mm** | supplied short-wall photos |

The 36.75-in return value is a conservative working measurement read from the
supplied photos. These four values establish clear-wall envelopes only. They
are not shelf cut lengths, support centers, endpoint clearances, or drilling
coordinates; those remain blocked by the corner, trim, outlet, framing, and
member-interface work below.

Use [MATERIALS_AND_HARDWARE.md](MATERIALS_AND_HARDWARE.md) when recording the
framing and hardware sections below. Its GRK screw and washer are selected
fixture candidates, not permission to skip the measurements.

## Outlet and electrical service envelope

The horizontal outlet datum is currently missing and blocks exact support,
ledger, cable-rail, and no-drill-envelope study. Record it from the **through
far-left zero** toward the corner.

| Measurement from through far-left zero | Reading 1 | Reading 2 | Reading 3 | Accepted value | Photo ID |
|---|---:|---:|---:|---:|---|
| Through wall to outlet faceplate left edge |  |  |  |  |  |
| Through wall to outlet faceplate centerline |  |  |  |  |  |
| Through wall to outlet faceplate right edge |  |  |  |  |  |
| Floor to faceplate bottom |  |  |  |  |  |
| Floor to faceplate center |  |  |  |  |  |
| Floor to faceplate top |  |  |  |  |  |
| Faceplate width |  |  |  |  |  |
| Faceplate height |  |  |  |  |  |

Record the largest plug/adapter expected to remain connected:

| Item | Width | Height | Projection from wall | Cord bend/service clearance needed | Photo ID |
|---|---:|---:|---:|---:|---|
|  |  |  |  |  |  |
|  |  |  |  |  |  |

Do not place a support, ledger splice, cable module, or drill location from
these measurements alone. A verified electrical routing/no-drill envelope is a
separate requirement.

## Inside corner and wall straightness

| Check | Method / location | Reading(s) | Accepted field value | Photo ID |
|---|---|---|---|---|
| Inside-corner angle near 68 in | angle gauge/template, both walls |  |  |  |
| Inside-corner angle near 84 in | angle gauge/template, both walls |  |  |  |
| Through wall bow at 68 in | straightedge/string with offsets |  | max offset: |  |
| Through wall bow at 84 in | straightedge/string with offsets |  | max offset: |  |
| Return wall bow at 68 in | straightedge/string with offsets |  | max offset: |  |
| Return wall bow at 84 in | straightedge/string with offsets |  | max offset: |  |
| Corner buildup/rounded texture | note radius or interference |  |  |  |

For a bowed wall, record offsets from the applicable run-local zero and include
the run name. Do not force a rigid PETG ledger flat against a wall with
fasteners.

## Door, trim, and working clearances

| Feature | Horizontal datum and size | Projection | Clearance at 68 in | Clearance at 84 in | Photo ID |
|---|---|---:|---:|---:|---|
| Through-run outer trim/door casing |  |  |  |  |  |
| Return-run outer trim/door casing |  |  |  |  |  |
| Door swing / handle sweep |  |  |  |  |  |
| Light fixture / ceiling obstruction |  |  |  |  |  |
| Existing furniture/equipment |  |  |  |  |  |
| Other obstruction |  |  |  |  |  |

Confirm that inward-facing cable rails and their removal paths do not enter a
door/trim, outlet/plug, walkway, or snag envelope.

## Stud, blocking, substrate, and concealed-service survey

Use one row for every candidate framing center. Through positions increase from
the far-left zero toward the corner; return positions increase from the corner
toward the far-right endpoint. Make marks at both shelf elevations; do not assume a
detection at one height continues unobstructed through another.

| Run | Elevation | Center from that run's zero | Detection method | Repeated from opposite direction? | Confidence / notes | Photo ID |
|---|---:|---:|---|---|---|---|
| through | 68 in |  |  |  |  |  |
| through | 68 in |  |  |  |  |  |
| through | 84 in |  |  |  |  |  |
| through | 84 in |  |  |  |  |  |
| return | 68 in |  |  |  |  |  |
| return | 68 in |  |  |  |  |  |
| return | 84 in |  |  |  |  |  |
| return | 84 in |  |  |  |  |  |

Add rows as needed. A stud-finder indication is survey evidence, not permission
to drill or proof of a safe fastener path.

| Construction input | Field value | How verified | Photo/document ID |
|---|---|---|---|
| Wall finish/substrate type |  |  |  |
| Measured substrate thickness |  |  |  |
| Framing type and nominal size |  |  |  |
| Continuous blocking present? | unknown / yes / no |  |  |
| Blocking material, thickness, elevation and extent |  |  |  |
| Known wiring/plumbing/HVAC routes |  |  |  |
| Corner framing/blocking on through wall |  |  |  |
| Corner framing/blocking on return wall |  |  |  |
| Driver access obstruction |  |  |  |

If continuous blocking or an independently verified equivalent is absent, the
current minimized station concept cannot receive structural credit merely by
moving printed supports to convenient locations.

## Intended contents—not a load rating

List realistic contents, including unusually dense items and cable bundles.
This defines a future target test load; it does not establish an allowable load.

| Item / container | Quantity | Individual measured weight | Footprint (W × D) | Height | Intended level/run/location |
|---|---:|---:|---:|---:|---|
|  |  |  |  |  |  |
|  |  |  |  |  |  |
|  |  |  |  |  |  |
|  |  |  |  |  |  |

Largest desired container height: ________<br>
Largest desired container depth: ________<br>
Desired cable bundle diameter/count: ________<br>
Any warm equipment, battery, liquid, or chemical storage: ________

No load, including the contents above, is authorized until the separate
physical qualification and installed release are complete.

## Required photo set

- [ ] wide view showing both full walls and inside corner;
- [ ] each wall with visible 68 in and 84 in tape marks;
- [ ] all four clear-length tape readings;
- [ ] outlet close-up with vertical measurement;
- [ ] outlet wide view with horizontal tape from the through far-left zero;
- [ ] through-wall stud/blocking marks at both elevations;
- [ ] return-wall stud/blocking marks at both elevations;
- [ ] inside-corner angle/template at both elevations;
- [ ] door/trim and full door-swing clearance;
- [ ] ceiling/light clearance above the proposed upper shelf; and
- [ ] labels or evidence used to identify wall construction.

## Measurement handoff checklist

- [ ] Values include units, run name, and the correct run-local zero.
- [ ] The four clear wall lengths are complete.
- [ ] Shelf-top choices at 68/84 in are confirmed or changed explicitly.
- [ ] Outlet centerline from the through far-left zero is complete.
- [ ] Corner angle and wall bow are recorded at both levels.
- [ ] Stud/blocking maps exist for both walls and both levels.
- [ ] Substrate thickness and construction are verified, not guessed.
- [ ] Door, trim, plug, cable, and driver service envelopes are documented.
- [ ] Intended contents and measured weights are listed.
- [ ] Every critical value has a matching photo ID.

Measured by: ____________________  Date: ____________________<br>
Tape/gauge used: ____________________  Units: ____________________

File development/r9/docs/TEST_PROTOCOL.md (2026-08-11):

# R9 qualification test protocol

## Status and limits

This protocol qualifies fit, reversible service, and visual tabletop assembly
in stages. It does **not** establish wall attachment, shelf strength, creep
life, a safe working load, or an installed release.

> **HARD STOP:** do not drill, wall-mount, hang, lean, proof-load, destructively
> test, or store anything on these articles. The current rating is 0 kg / 0 lb.
> Framed-wall, proof, creep, and destructive tests require separate approved
> fixtures and numeric protocols after the missing field and hardware inputs
> are resolved.

Only PETG articles printed from exact versioned bundles are eligible. PLA,
scaled meshes, mirrored substitutes, sanded-to-fit parts, combined catalog
layouts, and untraceable G-code are not eligible.

## Test record header

| Record item | Value |
|---|---|
| Test date / operator |  |
| Printer / nozzle | Bambu Lab A1 mini / 0.4 mm |
| Bambu Studio version |  |
| Plate | Textured PEI / other: |
| Filament brand, material, color | SUNLU PETG, black / confirmed: |
| Spool lot |  |
| Dryer, setpoint, actual time |  |
| Post-dry storage and RH if known |  |
| Flow calibration record |  |
| Exact bundle revision / manifest SHA |  |
| Photo folder or identifiers |  |

Attach the exact settings record from [PRINT_FIRST.md](PRINT_FIRST.md). A test
without a traceable part identity, material lot, orientation, and settings is
an observation, not a qualification result.

## Universal pre-test inspection

Test only after the part has cooled to room temperature.

| Inspection | Pass / fail | Observation / measurement | Photo ID |
|---|---|---|---|
| Correct exact filename and manifest identity |  |  |  |
| PETG spool and lot traceable |  |  |  |
| 100% scale and saved orientation confirmed |  |  |  |
| No warp/rocking on defined datum face |  |  |  |
| No crack, layer split, void, burn, or missing feature |  |  |  |
| No whitening or permanent set before fit |  |  |  |
| Fit, bearing, latch, and key faces undamaged |  |  |  |
| Critical dimensions meet exact bundle validation record |  |  |  |

Reject and quarantine an article on any unexplained failure. Do not sand,
drill, heat, glue, file, or force it into a passing condition.

## Gate 0 — corrected-pose 0.4 clearance qualification

### Articles and order

Use the two exact individual files from
`development/r9/generated/qualification_v5/stage0_individual_model_only_3mf/`:

1. `MODEL_ONLY_r8_clearance_ladder_receiver.3mf`;
2. `MODEL_ONLY_r9_gate0_clearance_key_0p4_handle_down.3mf`.

A previously printed frozen R8 v2 receiver may be reused only because its
canonical geometry digest matches the v5 receiver. Do not print any legacy R8
identity-pose key; those saved poses contain a large handle cantilever.

### Method

1. Identify the corrected-pose key and record its v5 manifest identity.
2. Place the receiver on a stable table; do not hold it where hand pressure can
   flex the opening.
3. Before fit, inspect the key's two keyed-head wings. Reject on a loose strand,
   curl, torn perimeter, layer separation, or visible droop.
4. Insert the 0.4 key using the intended straight service motion. If it binds,
   needs a tool, visibly deforms the receiver, or causes whitening/cracking,
   stop.
5. Perform ten gentle full seat/release cycles
   and inspect after cycles 1, 5, and 10. Record any change in feel; do not add
   lubricant.

### Gate 0 result

The authored 0.4 interface passes only when the corrected key fully seats and
releases by hand
through ten gentle cycles without tools, destructive force, crack, whitening,
permanent set, lost engagement, or increasing bind. This Gate does not authorize
rescaling, full-shelf printing, wall work, or load.

| Key | Fully seats? | Releases by hand? | Cycles completed | Damage/change | Pass / fail | Photo ID |
|---|---|---|---:|---|---|---|
| 0.5 mm/face |  |  |  |  |  |  |
| 0.4 mm/face |  |  |  |  |  |  |
| 0.3 mm/face |  |  |  |  | diagnostic |  |
| 0.2 mm/face |  |  |  |  | diagnostic |  |

On a 0.4 failure, stop and correct the printing process. Create a new record
for every reprint; never overwrite the failed observation.

## Gate 1 — R9 straight-joint coupons

### Purpose

Check the authored assembly motion and seated geometry of the candidate rear
ledger and stiff front beam/fascia splices. This is a fit test only; it gives no
span, bending, shear, or creep credit.

### Method

1. Verify that Stage 0 passed with the same controlled process or document any
   new spool/process and requalify Stage 0.
2. Hold `r9_rear_ledger_male_coupon` fixed. Slide
   `r9_rear_ledger_female_coupon` straight over its tongue through 12.4 mm of
   service travel until the outer body shoulders meet.
3. Preserve 0.4 mm clearance on each tongue depth/height face and 0.4 mm at the
   tongue tip. The body shoulder plane is the only intended target contact.
4. Remove the female by the exact straight reverse motion. Repeat ten gentle
   cycles, inspecting after cycles 1, 5, and 10.
5. Hold `r9_front_beam_lower_lap_coupon` fixed. Slide
   `r9_front_beam_upper_lap_coupon` straight over it through 16.0 mm of service
   travel.
6. Preserve the intended 0.4 mm gap at each axial shoulder and 0.8 mm total gap
   between opposed lap faces. Do not clamp the lap faces together.
7. Remove by the exact straight reverse and complete ten gentle cycles.

### Acceptance

- full authored seat and reversible release by hand;
- no unintended rocking, step, trapped condition, or gap beyond the declared
  ledger/beam clearances;
- no crack, whitening, wear-through, permanent set, or loss of engagement; and
- no need for clamp force, impact, adhesive, heat, sanding, or scale change.

| Joint | Seat/release | Datum/seam result | Cycles | Damage/change | Pass / fail | Photo ID |
|---|---|---|---:|---|---|---|
| rear ledger |  |  |  |  |  |  |
| front beam/fascia |  |  |  |  |  |  |

## Gate 2 — standalone support first articles

### Purpose

Check print quality, saved orientation, flatness, and shortened shape for the
three standalone support articles. No member seat or one-bay fixture is emitted.

### Method

1. Inspect `r9_compact_support`, `r9_shortened_outer_bookend_support`, and
   `r9_concealed_corner_half_control` separately.
2. Verify each exact filename, saved broad-face print orientation, and raw
   dimensions against the bundle validation record.
3. Put the declared datum face on a flat padded table. Record rocking and any
   visible warp with a light behind the face.
4. Inspect the complete thin wall strap, D-window, shortened projecting body,
   front nose, arch/root transitions, and all layers.
5. Do not join these articles to a ledger coupon, beam coupon, cassette, wall,
   or each other. The untrimmed corner control is not a handed corner part.

### Acceptance

Each article remains one undamaged PETG body, matches its validation identity
and dimensions, lies on its datum without any detectable rocking or visible
warp, and has no crack, split, missing feature, or pre-test whitening. This
gate gives no support strength or station-count credit.

| Article | Identity/dimensions | Datum rock/warp | Surface/root result | Pass / fail | Photo ID |
|---|---|---|---|---|---|
| compact support |  |  |  |  |  |
| smooth bookend control |  |  |  |  |  |
| untrimmed corner-half control |  |  |  |  |  |

## Gate 3 — concealed two-wall corner fixture

### Purpose

Check the five-part nominal-90-degree handling/reveal study: tabletop fixture,
pre-authored through and return halves, under-shelf key coupon, and cosmetic
cover coupon. It gives no field-angle or structural corner credit.

### Method

1. Record the fixture revision and its authored 90-degree angle.
2. Put `r9_90_degree_tabletop_angle_fixture` flat on the padded table.
3. Lower `r9_through_hidden_corner_half` vertically 8.0 mm to its fixture leg.
4. Without mirroring it, slide `r9_return_hidden_corner_half` horizontally
   16.4 mm until the complementary 45-degree miter faces meet.
5. Lower `r9_under_shelf_shear_key_coupon` vertically 8.0 mm onto both support
   tops, then lower `r9_cosmetic_corner_cover_coupon` vertically 8.0 mm onto
   the key.
6. Remove in exact reverse: cover, key, return half, then through half.
7. Complete ten gentle cycles. Inspect after cycles 1, 5, and 10.

### Acceptance

The fixture remains flat; labels/hands remain correct; the 45-degree miters
meet without overlap or forced bend; key and cover lower/release in the exact
order; the cover is not needed to pull the halves together; and no damage or
progressive binding appears. This is only a nominal-90-degree tabletop result.

| Corner check | Cycle 1 | Cycle 5 | Cycle 10 | Pass / fail | Photo ID |
|---|---|---|---|---|---|
| through half independent seat |  |  |  |  |  |
| return half independent seat |  |  |  |  |  |
| key service |  |  |  |  |  |
| cover install/remove |  |  |  |  |  |
| seam/alignment |  |  |  |  |  |
| post-disassembly condition |  |  |  |  |  |

## Gate 4 — cable interface and integrated bookend service

### Purpose

First qualify the standalone two-socket rail/module interface. Only then check
no-load module service in both distinct integrated bookend hands. Cable hardware
receives no shelf or structural capacity credit.

### Method

1. On `r9_two_socket_outer_bookend_rail_fit_coupon`, hold the flush blank at the
   upper entry position, move it straight inward through the 6.0 mm approach,
   and drop it 8.0 mm to seat. Lift 8.0 mm and move straight outward to remove.
2. Complete ten gentle cycles in the lower socket and then ten in the upper,
   keeping the other socket empty.
3. Only after the blank passes, repeat in both standalone sockets with
   `r9_multi_cable_comb_hook_module`, one socket at a time.
4. Confirm the exact through/return labels on the two integrated bookends.
   Never mirror or swap them.
5. Repeat blank-then-comb service in both sockets of
   `r9_through_outer_bookend_additive_two_socket_candidate`, then in both
   sockets of `r9_return_outer_bookend_additive_two_socket_candidate`.
6. The integrated receiver is fused/additive. Never attempt to remove or pry it
   from the bookend.
7. Inspect socket edges, common keys, additive receiver band/foot, wall strap,
   D-window, and roots after cycles 1, 5, and 10.

### Acceptance

The standalone interface passes before either integrated first article; both
bookend hands are correctly identified; each module seats/releases by the exact
motion in each socket; and no key, socket, additive band/foot, strap, root, or
module shows damage or lost engagement. Adjacent occupied-socket service,
door/trim, installed cable-loop, snag, wall, and load clearances remain
unqualified.

| Article/socket | Blank cycles | Comb/hook cycles | Service result | Damage/change | Pass / fail | Photo ID |
|---|---:|---:|---|---|---|---|
| standalone lower socket |  |  |  |  |  |  |
| standalone upper socket |  |  |  |  |  |  |
| through bookend lower |  |  |  |  |  |  |
| through bookend upper |  |  |  |  |  |  |
| return bookend lower |  |  |  |  |  |  |
| return bookend upper |  |  |  |  |  |  |

## Gate 5 — qualification-v5 review and stop

Follow [ASSEMBLY.md](ASSEMBLY.md) and review the complete record. Gate 5 is not
a one-bay, full-L, or shelf assembly. The software explicitly blocks a
compact-support/ledger/front-beam/cassette one-bay pose because member seats,
cassette interface/seam, full bay lengths/end conditions, and wall hardware/
framing datums are unauthored. It emits no one-bay mesh or placed assembly.

The final v5 result may be called **qualification-article dry-fit pass** only
when Gates 0–4 pass and all reverse service/disassembly steps remain clean. It
must never be called “shelf pass,” “one-bay pass,” “structural pass,” or
“installation ready.”

| Final review | Pass / fail | Observation | Photo ID |
|---|---|---|---|
| exact package/manifest/part traceability |  |  |  |
| straight-joint reverse service |  |  |  |
| standalone support inspection |  |  |  |
| nominal corner reverse service |  |  |  |
| standalone cable interface |  |  |  |
| both integrated bookend hands |  |  |  |
| complete post-test damage inspection |  |  |  |
| one-bay/full-L work stopped |  |  |  |

## Stop conditions for every gate

Stop immediately and quarantine the affected article on:

- a 0.4 clearance-gate failure;
- crack, layer split, audible snap, whitening, permanent bend, or missing
  extrusion;
- increasing bind, loss of key/socket engagement, or progressive wear;
- incomplete bearing/contact, rocking, twist, trapped service part, or a need
  for tools/force;
- an incorrect hand, scale, orientation, filament, file identity, or slicer
  repair;
- a required dimension outside the exact bundle's stated tolerance;
- an outlet, door, trim, cable, driver, or storage-envelope conflict; or
- any proposed action involving a wall, household load, or unapproved test
  weight.

Write the failure as observed. Do not convert a failed gate into a pass by
post-processing or by changing the acceptance rule after the test.

## Future structural gates—not authorized here

The following tests remain mandatory before any installed release, but this
document intentionally provides no fixture loads, proof factors, duration,
fastener schedule, or pass limits:

1. compact support versus the R8 structural control;
2. the emitted Palatine Moderne v3 one-bay ledger/front-beam/support/cassette
   fixture, still requiring physical fit review;
3. exact two-wall concealed-corner structural fixture;
4. framed-wall hardware and driver-access fixture;
5. declared-load proof test;
6. PETG creep test at the declared load and service temperature;
7. cyclic/service testing at declared conditions; and
8. controlled destructive testing with a defined safe exclusion area.

Those protocols require exact field dimensions, verified framing/blocking,
the selected candidates in
[MATERIALS_AND_HARDWARE.md](MATERIALS_AND_HARDWARE.md), target contents load,
exact CAD bore
geometry, instrumentation, duration, environmental conditions, and acceptance
criteria. Printed anchors and hollow-wall anchors are prohibited in the primary
load path. Until all are authored, executed, and reviewed, full shelf printing,
wall installation, and stored load remain **NO-GO**.

## Gate summary

| Gate | Result | Tester/date | Record/photo location | Authorized next action |
|---|---|---|---|---|
| 0 — R8 0.4 clearance |  |  |  | R9 coupons only if pass |
| 1 — straight joints |  |  |  | support articles only if pass |
| 2 — support first articles |  |  |  | nominal corner only if pass |
| 3 — nominal corner |  |  |  | cable interfaces only if pass |
| 4 — cable/bookend service |  |  |  | v5 review only if pass |
| 5 — qualification-v5 review |  |  |  | stop; no one-bay or wall work |

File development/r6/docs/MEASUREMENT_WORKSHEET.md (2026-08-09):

# Field measurement and photo worksheet

Do not scale or print the complete r6 shelf from the nominal 3 ft / 5 ft labels.
The generator needs the smallest real clear dimensions, wall arrangement,
framing, fastener, storage, printer, and material data below. Use one common
laser datum, record units with every value, and photograph the tape/laser at
both endpoints.

The current 43.5 in outlet-top-to-ceiling measurement, 6 in depth, +12/+33 in
provisional shelf tops, 60/36 in walls, and 90° corner are **unverified design
inputs**, not final measurements.

Project/date: ____________________  Measured by: ____________________

Room temperature / humidity: ____________________

Measurement tools and stated accuracy: ______________________________________

## A. Photos required

Name the files with the photo IDs below and include a ruler, tape, square, or
laser where requested.

- [ ] **P01 — context:** empty closet from the doorway, floor to ceiling, both
  walls, inside corner, door/trim, and outlet visible.
- [ ] **P02 — 5 ft through wall:** camera square to the wall, full width and
  proposed two-level zone visible.
- [ ] **P03 — 3 ft return wall:** same view for the smaller wall.
- [ ] **P04 — inside corner:** close view at both proposed shelf elevations
  with square/angle gauge and the 6 in depth envelope marked.
- [ ] **P05 — ceiling and wall bow:** straightedge or laser across each wall and
  beneath the ceiling at both shelf elevations.
- [ ] **P06 — outlet service envelope:** outlet, cover, plug/cord projection,
  and measured top datum. Do not remove the cover unless qualified.
- [ ] **P07/P08 — wall widths:** tape endpoints and readings at the lower and
  upper shelf elevations for both walls.
- [ ] **P09 — obstructions:** trim, door swing, molding, conduit, access panel,
  or stored-item conflicts with the 6 in shelf-depth envelope.
- [ ] **P10/P11 — framing map:** labeled stud/blocking station marks on each
  wall with a common corner datum and the verification method shown.
- [ ] **P12 — wall build-up:** safe evidence of finish type/thickness and wood
  framing/blocking material/thickness; no uncontrolled exploratory hole.
- [ ] **P13 — proposed fastener:** screw beside calipers/ruler, head or washer,
  driver bit, and packaging/manufacturer identification.
- [ ] **P14 — largest stored objects:** each bin/item with width, depth, loaded
  height, and scale reading.
- [ ] **P15 — printer/material:** printer model plate/nozzle identification and
  black-PETG spool label/lot.

Additional photo IDs and notes: _____________________________________________

## B. Wall arrangement and common datums

Confirm arrangement:

- [ ] same-elevation inside-corner L;
- [ ] 5 ft wall is the **through** arm that owns the 6 x 6 in corner;
- [ ] 3 ft wall is the independent **return** arm beginning past the through
  arm's front plane;
- [ ] no door, trim, access, light, sprinkler, or outlet conflict.

Finished-floor to ceiling at inside corner: __________ in

Finished-floor to outlet top: __________ in

Outlet top to ceiling, remeasured: __________ in (reported reference: 43.5 in)

Common laser datum height above finished floor: __________ in

Ceiling height/bow at 5 ft outer end: __________ / __________ in

Ceiling height/bow at 3 ft outer end: __________ / __________ in

Inside corner angle at lower shelf elevation: __________ °

Inside corner angle at upper shelf elevation: __________ °

Maximum wall-to-square deviation over 6 in depth: __________ mm

Maximum measured wall bow in either shelf footprint: __________ mm

The nominal design permits at most ±0.2° square-corner deviation and retains a
1.2 mm arm gap with 0.65 mm minimum residual clearance. If field geometry does
not preserve that clearance, regenerate the gap/corner—not the parts by slicer
scaling.

## C. Finished clear wall widths

Measure the clear finished-wall distance from the inside-corner datum to the
actual outer obstruction at several heights. Record the **smallest** reading.

| Height / location | 5 ft through wall (in) | 3 ft return wall (in) |
| --- | ---: | ---: |
| Lower frame bottom | | |
| Lower shelf top | | |
| Midway between levels | | |
| Upper frame bottom | | |
| Upper shelf top | | |
| Ceiling line | | |
| **Minimum used for generation** | | |

Desired installed shelf-back clearance, through wall: __________ in

Desired installed shelf-back clearance, return wall: __________ in

Desired outer-end clearance, through wall: __________ in

Desired outer-end clearance, return wall: __________ in

Wall/trim obstruction descriptions and stations from corner: ________________

Reference-only geometry from nominal walls:

- through run: starts 6.35 mm from the corner, length 1514.475 mm;
- return structural run: starts 177.55 mm from the corner, length 733.675 mm;
- depth: 152.4 mm;
- through chassis / integral-boss / locked removable-facade / service-swept
  fronts: 158.75 / 165.95 / 171.95 / 176.35 mm from the corner;
- floating return-finish all-solid / visible-base leading planes: 173.15 /
  173.95 mm, giving a 1.2 mm locked solid gap and 2.0 mm visible relief;
- chassis-to-return structural clearance: 18.8 mm; remove the floating return
  finish first before exercising the fixed through rosette's 4.4 mm stroke;
- support stations are regenerated, never copied blindly from the reference.

## D. Shelf elevations and service access

Loaded-item height determines whether two levels truly fit. Mark the proposed
tops with removable tape and test every driver, cross-key, pin, bridge, bin, and
plug path before freezing them.

Lower shelf top above finished floor: __________ in

Lower shelf top above outlet top: __________ in (reference: +12 in)

Upper shelf top above finished floor: __________ in

Upper shelf top above outlet top: __________ in (reference: +33 in)

Top-to-top spacing: __________ in (reference: 21 in)

Clear opening between lower top and upper frame bottom: __________ in

Clearance above upper shelf top: __________ in

Outlet/plug/cord service clearance: __________ in

Minimum straight visible-front/open-underside service path: __________ mm
(must be at least 75 mm for every structural cross-key and pin)

Can the upper level be installed, pinned, inspected, and removed before the
lower level is present? [ ] yes [ ] no

Can both levels be independently removed with no vertical structural tie?
[ ] yes [ ] no

## E. Framing and blocking map

Do not infer framing from nominal 16 in spacing. Record the center, verified
width, material, thickness/depth, and verification method for every intended
support. Use the same inside-corner datum as the generated drawing.

Wall finish type: ____________________  thickness: __________ in

Wood stud/blocking species/type: ____________________

Blocking thickness/depth and installation evidence: _________________________

Utility-clearance method and person responsible: ____________________________

Circuit de-energization / electrical review record: _________________________

### Lower level — 5 ft through wall, seven required stations

| Station | Center from corner (in/mm) | Verified wood width (in) | Material/thickness | Verification method | Clear of utilities? |
| ---: | --- | ---: | --- | --- | --- |
| 1 | | | | | |
| 2 | | | | | |
| 3 | | | | | |
| 4 | | | | | |
| 5 | | | | | |
| 6 | | | | | |
| 7 | | | | | |

### Upper level — 5 ft through wall, seven required stations

| Station | Center from corner (in/mm) | Verified wood width (in) | Material/thickness | Verification method | Clear of utilities? |
| ---: | --- | ---: | --- | --- | --- |
| 1 | | | | | |
| 2 | | | | | |
| 3 | | | | | |
| 4 | | | | | |
| 5 | | | | | |
| 6 | | | | | |
| 7 | | | | | |

Nominal lower/upper reference centers in millimetres only:
`37.7825, 279.7175, 521.6525, 763.5875, 1005.5225, 1247.4575, 1489.3925`.
Record both elevation sets independently even if every measured center agrees.

### Lower level — 3 ft return wall, four required stations

| Station | Center from corner (in/mm) | Verified wood width (in) | Material/thickness | Verification method | Clear of utilities? |
| ---: | --- | ---: | --- | --- | --- |
| 1 | | | | | |
| 2 | | | | | |
| 3 | | | | | |
| 4 | | | | | |
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

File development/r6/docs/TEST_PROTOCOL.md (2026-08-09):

# Qualification and sustained-creep test protocol

## Purpose and limits

This protocol is a staged evidence plan for one exact Story Corner r6 material,
printer, profile, orientation, wall build-up, fastener, geometry, environment,
and load case. It does not itself establish a load rating. The project remains
**experimental and unrated**, and no overhead use is permitted while the target
load, deflection limit, permanent-set limit, and actual wall connection remain
unconfirmed.
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

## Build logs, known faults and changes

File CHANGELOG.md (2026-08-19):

# Changelog

Design revisions are named in `config.json`. The project has not been assigned a public semantic version.

## Unreleased — `triadic_palatine_fitted_l_corner_r5`

### Documentation and assembly completion (design review)

- New `ASSEMBLY.md` owns the complete build sequence: entry gate, structural install (including the install-standards → measure-offsets → regenerate → then-cut ordering), part staging and left/right identification, tiles, curbs, fascia-train direction (inside corner outward), ornament order, 98-piece close-out tally, load-acceptance record, and disassembly/service order. The silicone dot counts and installed z-stack are stated once there and in `ENGINEERING_DESIGN.md` rather than duplicated across five documents.
- New `MEASUREMENT_WORKSHEET.md` provides fill-in tables for every field measurement with a worksheet-to-config key map (JSON paths, units, worked example) and a post-entry verification step against the `*_source` fields in `generated/validation.json`.
- `field_verified_shelf_arm_dead_load_lb` is now consumed: entered values raise the serviceability check's governing line load above the 30 lb/ft development proxy, reported with its source in `generated/structural_sanity_check.json`. It can only raise the check and still creates no rating.
- Consistency fixes: the end-overhang gate is stated as the configured 6 in maximum (nominal through-arm value 5.594 in); one inspection schedule (SAFETY.md) replaces three variants; pier flutes stated as three per half / six assembled; the 17.0 mm curb top documented as 15.0 mm curb + 2.0 mm tile; the 39 in standard zone's 4.5 in margin stated in SAFETY.md; groin-vault 2.0 mm documented as 1.2 mm base + 0.8 mm relief.
- Plate-fit and batching cautions for a 180 mm printer added to `PRINT_ME_FIRST.md` (brim margin on 168 mm parts, thin-tile warp and spares, batching guidance).
- `scripts/check_repository.py` now requires `ASSEMBLY.md` and `MEASUREMENT_WORKSHEET.md`; the measurement issue template names the exact config keys, collects the corner angle numerically, splits support centers per wall, and records dead loads separately.

### Added

- **Triadic Palatine Order** visual system, governed by a 3–6–9 composition rather than unrelated ornament.
- Three segmental arcade bays on the return arm and six on the through arm, split into 18 handed fascia halves that remain within the declared 180 mm saved-orientation envelope.
- Nine floating 18 x 24 mm keystone seam covers.
- Eighteen removable face-up entablature overlays, each with nine dentils, three triglyph groups, and three continuous cornice orders.
- Integrated 3:4:5 spandrel voids, 2.4 mm archivolt shadow reveals, and six-flute shared piers with shallow projected bases and capitals.
- Central 11 mm patera relief on every removable entablature overlay.
- Full-height Palatine outer endcaps and re-entrant corner pilaster.
- A 42 mm through-owned groin-vault soffit with diagonal ribs and nine-petal boss; generated clearance to the nearest support plane must remain at least 10 mm.
- A true-scale Palatine detail coupon in addition to the corner gauge and full-stack fascia coupon.
- Exact nominal decorative elevation: `generated/palatine_elevation.svg`.
- Final r5 design-intent rendering: `generated/artist_rendering_triadic_palatine_order.png`.

### Geometry and engineering changes

- Installed shelf-back offset is now a **per-run field value**. The long and short walls are measured independently; the perpendicular wall's installed offset controls each deck's inside start.
- The square-footprint angle gate is tightened from ±1° to ±0.25°.
- The generator derives angular edge shift across the 203.2 mm depth, enforces at least 0.6 mm residual nominal clearance from the 1.6 mm plywood gap, and rejects a configured angle gate above the approximately 0.282° residual-derived limit.
- Field support centers must be finite and at least 2 in apart under the current independent-support development guard.
- All top tiles now use the common 0.25 mm plan radius, which is no greater than half the 0.6 mm seam.
- The plywood-span sanity check now uses a 30 lb/ft total development line-load proxy. It is above the approximately 24.3 lb/ft contents-selection density only to include a rough unmeasured dead-load allowance; it is not measured demand, a safety factor, or a rating.
- Per-run measured shelf-arm dead-load fields were added.

### Rear-curb and attachment changes

- The return curb now starts on its own plywood at station 8.750 in instead of extending through the corner zone.
- A separate 172.6 mm corner-side curb remains on the through-owned corner square and stops before the plywood joint.
- Rear-curb ends are arm-specific: nominally 115.581 mm return and 126.481 mm through.
- Rear-curb nominal count remains 17: eleven universal centers, four arm-specific ends, one through-zone corner-side piece, and one fitted L replacement.
- The installed curb stack is explicit: 2.0 mm top tile, 2.4 mm curb base above it, and 17.0 mm upright top from the deck datum.
- Straight curb pieces contain one 8 x 4.4 mm clearance slot; the L replacement contains one per arm. Matching tiles are field-drilled only after final layout and underside-clearance verification.
- Each Palatine fascia half now uses holeless, full-depth upper/lower channel capture around the real shelf stack. The lateral train is assembled before the two outer endcaps and re-entrant corner cover; a tiny qualified removable silicone dot inside each channel prevents creep and rattle without drilling or notching the continuous steel angle.
- The finish policy now distinguishes qualified removable silicone, curb and groin-vault screws, captured fascia channels, own-segment entablature retention, floating keystones/pilaster, and removable endcaps.

### Package changes

- The nominal full print set is **101 model-only objects**: 98 installed finish parts plus three print-first objects. The separate parts catalog contains one object per unique mesh family.
- Estimated nominal PETG is **2.45 kg packaged** and **2.42 kg installed**, derived from mesh volume and nominal density.
- Mass estimates exclude purge, supports, failures, spares, fasteners, plywood, and steel.
- Individual r5 meshes plus `MODEL_ONLY_STORY_CORNER_TRIADIC_PALATINE_PARTS_CATALOG.3mf` and `MODEL_ONLY_STORY_CORNER_TRIADIC_PALATINE_FULL_PRINT_SET.3mf`, cut/support plans, validation, hashes, and documentation are regenerated under the new names.

### Safety

- The hybrid load path is unchanged: plywood and steel carry storage load; every printed architectural part has zero structural credit.
- A visually all-PETG finish does not authorize a structurally all-PETG shelf or printed wall bracket.
- Both arms remain independently supported, and perpendicular brackets require a physical dry fit.
- Keystones and the corner pilaster are fixed on one side and float across the other; the groin vault stays on the through deck and never bridges the joint.
- No tested load rating is claimed.
- No embedded G-code is included because the printer, nozzle, plate, and PETG product remain unconfirmed.

## Superseded development — `dual_run_modular_fitted_l_corner_r4`

- Established the fitted same-height L with explicit 5 ft through and 3 ft return ownership.
- Added square-mating corner quadrants, fitted fascia/rear-curb corner pieces, absolute support coordinates, model-only 3MFs, and deterministic validation.
- Used one global provisional installed shelf-back offset, a ±1° angle gate, a rear-curb layout that did not yet isolate the plywood joint, and the plain modular fascia.
- Its 68-object / 2.12 kg package figures apply only to r4 and are superseded by r5.

## Archived — `dual_run_modular_full_wall_r3`

- Used two independent nominal 35.75 and 59.75 in wall-to-wall decks.
- Added universal 6 in-pitch centers, symmetric parametric ends, deterministic 3MF packages, artifact hashes, repository checks, and GitHub Actions.
- Superseded because two independent full-depth decks do not define a physically fitted same-height inside corner.
- Preserved locally outside the publishable repository tree.

## Archived — `dual_run_engineered_prototype_r2`

- Used separate exact-width PETG module families for nominal 3 ft and 5 ft runs.
- Superseded by the interchangeable center/end module system.
- Preserved locally outside the publishable repository tree.

## Archived — A1 mini 12 in assumption

- Earlier 12 in-deep, three-level files and A1 mini slicer assumptions.
- Not compatible with the active 8 in fitted-L design and not production-ready.
- Preserved locally outside the publishable repository tree.

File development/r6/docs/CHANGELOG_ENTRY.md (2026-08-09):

## [Unreleased] — r6 Triadic Palatine all-PETG development

Status: **experimental, unrated, model-only, and blocked from overhead
production use**. No tested load rating exists.

### Added

- Original two-level, same-elevation inside-corner L architecture whose shelf
  body, cassettes, tied-arcade halves, X-corbels, joinery, keeper strips,
  facade, pins, cross-keys, and ornament are printed in black PETG.
- Explicit nonprinted boundary limited to suitable metal structural wall screws
  with integral heads or compatible metal washers into verified wood studs or
  purpose-installed blocking.
- Nominal 6 in-deep fitted plan for 60/36 in walls: six through bays plus three
  return bays, nine total bays, and seven plus four independently wall-fastened
  supports per level.
- Two complete independent L levels at provisional +12 in and +33 in shelf-top
  offsets above the outlet top, with 21 in provisional top-to-top spacing and
  upper-first installation.
- Deterministic plan math, position-specific half-bay cassette planning,
  rail-free seam planning, and exact physical-object inventory.
- Per-level installed inventory of 258 printed objects: 225
  chassis/joinery/retention objects plus 33 isolated, removable, zero-credit
  ornament objects; 516 objects for the selected two levels. Coupons and spares
  are additional.
- Repeat-weighted CAD-solid context of 16.000337 kg per level and exactly
  32.000674 kg for the two selected levels at the configured 1.27 g/cm3 density;
  this is neither sliced mass, finished tare, print time, nor a load rating.
- Governing SVG plan, elevation, two-level, exploded joinery, crown, X-corbel,
  and corner sheets with nominal/unverified/model-only warnings.
- Read-only audits of the owner-supplied reference 3MFs and documented research
  provenance without copying or redistributing third-party meshes.
- The exact-6-plus-3 two-level artist rendering as the current visual-intent
  hero, the earlier two-level rendering as preserved visual-development
  history, and the reproducible prompt. Generated drawings govern dimensions
  and counts.

### Changed

- Lowered the hidden structural spring/crown from the original 60/152 mm
  visual order to 46/138 mm after exact solid intersections proved the curved
  rib occupied the cassette front chord. The removable facade preserves the
  60/152 mm palace silhouette with zero structural credit.
- Re-sprung the hidden rib from `u = 28.8 mm` at the inner capital face rather
  than the support center after swept-volume tests proved the old rib occupied
  its compact clevis. This preserves a real 0.4 mm housing clearance and makes
  the through rib essentially semicircular without carving away a collision.
- Replaced the earlier whole-half longitudinal slide with a collision-aware
  final-X vertical lift. Each arcade half now enters three open-bottom cassette
  receivers plus one open-bottom spring receiver at its final run coordinate,
  then receives two accessible top quarter-turn cross-keys and one accessible
  spring cross-key.
- Changed the rear crown stabilizer to an upward-from-below bridge with a hard
  stop and one accessible fixed-right anti-drop/reverse-slide pin. Top-down
  insertion, a second fixed pin, and friction-only retention are prohibited.
- Separated nine locally fixed crown seams from seven thermally floating
  supported-pier seams. Added one left-owned positive diaphragm-key keeper
  opposite the fixed-right pin ear and one independently caught visible-front
  tie at each crown; floating
  pier keys remain trapped by the integral corbel cap through their qualified
  axial travel.
- Replaced eleven separate saddles and eleven saddle pins per level with a
  full-width lock-clearing bearing cap and locator ridges integral to each X-corbel,
  removing two tolerance-sensitive interfaces and reducing printed dead mass.
- Removed the geometry-current optional study's 41 stitch-rail segments, 37
  half-lap joints represented by 74 pins, and 4 end ties per level from the
  installed baseline. The study therefore represents 119 optional printed
  objects, not 122. Interface review found no proven benefit and identified a
  second thermal-loop risk. Rails/half-laps remain only an optional,
  noninstalled, zero-credit rail-on/rail-off research question.
- Formalized the through-arm ownership of the 6 x 6 in corner and a floating,
  nonstructural two-piece corner finish instead of a rigid PETG L tie. The
  structural return now begins at 177.55 mm, beyond the complete 13.2 mm
  removable facade and its 4.4 mm service stroke; its removable return-corner
  finish cantilevers back to a 173.15 mm all-solid leading plane and is removed
  first for service. Asymmetric 27.0325 / 31.4325 mm return insets preserve the
  225.07 mm three-bay rhythm and unchanged far-end station.
- Froze the five canonical package IDs and model-only filenames in the package
  source contract: `print_first_prototypes` /
  `MODEL_ONLY_R6_PRINT_FIRST_PROTOTYPES.3mf`, `unique_parts_catalog` /
  `MODEL_ONLY_R6_UNIQUE_PARTS_CATALOG.3mf`,
  `worst_case_one_bay_qualification` /
  `MODEL_ONLY_R6_WORST_CASE_ONE_BAY_QUALIFICATION.3mf`, `one_level_l` /
  `MODEL_ONLY_R6_ONE_LEVEL_L.3mf`, and `two_level_full_project` /
  `MODEL_ONLY_R6_TWO_LEVEL_FULL_PROJECT.3mf`. The deterministic build now emits
  and validates all five names; a name by itself still does not imply physical
  qualification or permission to install.
- Treated the near-semicircular Roman rib as part of a mixed-action closed
  tied-spandrel candidate frame, not as an assumed pure-compression arch.
- Limited Egyptian influence to a shallow cavetto and Art Deco influence to
  restrained, removable sunbursts, chevrons, and stepped-keystone detail. Fine
  ornament receives zero structural credit.
- Preserved the r5 hybrid architecture under `reference/hybrid_r5/` as a
  separate fallback rather than rebuilding or silently discarding it.

### Safety and qualification

- Kept production wall-fastener bores, head seats, bosses, and driver tunnels
  hard-blocked until the exact screw, head/washer, embedment, wall finish,
  framing, and utility-clearance method are measured and regenerated.
- Prohibited printed wall anchors, primary hollow-wall anchors, structural
  adhesive, cross-level load ties, rigid corner ties, hidden wall-side service,
  and vertical load credit for cross-keys/pins/ornament.
- Kept all 3MFs model-only with no embedded G-code while printer model, nozzle,
  build plate, black-PETG product, and slice settings are unconfirmed.
- Defined staged coupons, representative wall-bearing and component tests,
  worst-case 241.935 mm full-bay testing, matched arch-on/arch-off observation,
  unloaded full-corner fit, separate distributed/front-edge/crown-point/
  asymmetric-torsional load cases, whole-article thermal cycling, sustained
  checkpoints at 1 hour / 24 hours / 7 days / 30 days / 90 days, 72 hours
  unloaded recovery plus teardown, and a separately printed destructive
  load-to-failure specimen.

### Current software-model release-candidate evidence

- Complete mesh integration, exact schedules, all five model-only 3MF packages,
  validation/model/slice reports, and the cryptographic manifest are generated
  and pass the current software release checks. No embedded G-code exists.
- No authoritative print-time estimate exists because no printer, nozzle,
  black-PETG product, drying method, or production slice profile is confirmed;
  the slice report intentionally records `performed: false`.
- Real wall dimensions, corner angle/bow, framing/blocking, wall build-up,
  fastener, storage dimensions/weights, target load, printer, nozzle, build
  plate, black-PETG product, service temperature, and acceptance limits remain
  qualification gates.
- Completion of software validation cannot be represented as physical capacity
  evidence or permission for overhead installation.

### Rights

- The repository currently has no `LICENSE` file. Public visibility does not
  grant permission to copy, modify, redistribute, or sell the project.

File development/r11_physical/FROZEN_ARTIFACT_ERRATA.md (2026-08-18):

# Frozen R11 v1 artifact errata

> **Errata only.** This file does not modify, authorize, or supersede the
> frozen R11 v1 neutral bundle. The rating remains 0 kg / 0 lb.

The generated v1 bundle is byte-pinned evidence. Two copied Markdown files in
that bundle preserve a source-relative historical R10 link. The link works in
the source tree but not from the copied bundle directory:

| Frozen copied file | Broken copied link | Correct canonical target |
| --- | --- | --- |
| `GUIDELINES.md` | `../r10/README.md` | [development/r10/README.md](https://github.com/rupret007/story-corner-shelf/blob/main/development/r10/README.md) |
| `DESIGN_REQUIREMENTS.md` | `../r10/README.md` | [development/r10/README.md](https://github.com/rupret007/story-corner-shelf/blob/main/development/r10/README.md) |

Why this is recorded instead of silently rewritten: the bundle manifest,
source closure, deterministic tree, and the separate v2 baseline all bind the
existing bytes. Rewriting the copied files in place would falsify those
identities. A future artifact version may correct the copied links and must
receive a new package ID, manifest, source closure, and dependent baseline.

No model, geometry, process setting, permission, installation rule, or load
claim is changed by this erratum.

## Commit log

2026-08-09 Publish verified r6 software-model release
    [MODEL_ONLY_R6_DEV_BLOCKED_WALL_SCREW_BEARING_COUPON_SOLID_NO_HOLE.3mf, MODEL_ONLY_R6_DEV_CASSETTE_RETURN_01_OF_06.3mf, MODEL_ONLY_R6_DEV_CASSETTE_RETURN_02_OF_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]
2026-08-09 Pin NetworkX for reproducible geometry tests
2026-08-11 Publish R9 Palatine Moderne development release
    Preserve the R6-R8 frozen development lineage, add the R9 qualification and one-bay prototype packages, and include the complete hardware, assembly, testing, and design-language documentation.\n\nVal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
    [MODEL_ONLY_R6_DEV_BLOCKED_WALL_SCREW_BEARING_COUPON_SOLID_NO_HOLE.3mf, MODEL_ONLY_R6_DEV_CASSETTE_RETURN_01_OF_06.3mf, MODEL_ONLY_R6_DEV_CASSETTE_RETURN_02_OF_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]
2026-08-11 Allow versioned development beside immutable R6 release
    Materialize the manifest-listed R6 publication into an isolated CI view before auditing it, preserving strict immutable-release checks while allowing the versioned development tree to coexist on main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
2026-08-11 Add R10 Palatine Lincoln arcade qualification (#4)
    Publish the deterministic, qualification-only R10 one-bay and S0 cable-bookend package with exact hardware, assembly, print-first, and physical-test contracts. Keep printer, drilling, wall installation, production, and load authorization fail-closed.
    [MODEL_ONLY_R10_ONE_BAY_QUALIFICATION_CATALOG_NOT_A_PRINT_PLATE.3mf, MODEL_ONLY_r10_first_wall_multi_cable_comb_hook.3mf, MODEL_ONLY_r10_first_wall_s0_inward_tw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]
2026-08-12 feat: add R11 integrated shelf qualification and physical handoff
    [MODEL_ONLY_R11_FIRST_OUTER_ACTUAL_BAY_CATALOG_NOT_A_PRINT_PLATE.3mf, MODEL_ONLY_r11_bay0_left_terminal_integrated_half_deck.3mf, MODEL_ONLY_r11_bay0_positive_k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]
2026-08-18 Migrate to Triadic Palatine r5 parametric pipeline
    Replace the R6 root codebase with the parametric r5 pipeline for the
    triadic_palatine_fitted_l_corner_r5 revision:
    - New scripts/ pipeline (generate_shelf_parts.py, validate_model_3mf.py,
    check_repository.py, build_all.sh) replaces the root-level generator
    modules, per-module tests, and docs/ mirror tree.
    - Regenerated generated/ artifact set: 21 STLs with 1:1 model-only 3MFs
    plus parts-catalog and 101-object full-print-set packages, manifests,
    layouts, plans, and validation reports. No embedded G-code.
    - Root docs rewritten for the Triadic Palatine Order; README and
    PRINT_ME_FIRST now carry a pointer to the frozen R6-R11 developm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
    [MODEL_ONLY_PETG_Palatine_ArcadeFascia_Half_left_long_wall_5ft.3mf, MODEL_ONLY_PETG_Palatine_ArcadeFascia_Half_left_short_wall_3ft.3mf, MODEL_ONLY_PETG_Palatine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]
2026-08-18 Scope R11 CI to frozen trees and retire root-router tests
    The r5 migration retired the contract that root README/PRINT_ME_FIRST/
    PROGRESS act as R11 routers with docs/ mirrors, so three frozen tests
    that assert it can no longer pass. Run the frozen suites through
    scripts/run_r11_suite.py, which skips exactly those three tests while
    leaving the frozen test files byte-identical, and trigger the R11
    workflows only when the frozen trees or the guards themselves change.
    All remaining tests still run: 85 contract, 9 physical, 38 v2 —
    verified locally.
2026-08-19 Complete r5 build documentation and wire measured dead loads
    Design review outcome: the r5 geometry is sound (watertight prismatic
    meshes, support-free saved orientations, generous serviceability margins),
    but the documentation had no assembly sequence, no measurement worksheet,
    and a handful of cross-document contradictions.
    - Add ASSEMBLY.md: entry gate, structural install with the
    standards -> measure offsets -> regenerate -> cut ordering, part
    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
2026-10-31 R12 durable shelf release (split from #10) (#15)
    * Finalize R12 durable shelf release
    * Make R12 print queue production-first
    * Protect existing release package with input and symlink preflight
    * Preserve dependency pins required by frozen R11 source evidence
    * Restore Dependabot pins and verify frozen R11 sources with upgraded requirements.
    Keep main's geometry dependency pins while binding live R11 v1 source closure through a version-aware check, and harden R12 packaging against empty 3MFs and missing profiles.
    * Test and document the exact frozen-source requirements exception
    * Restore ±0.2% R12 fascia volume regression and kill sof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
